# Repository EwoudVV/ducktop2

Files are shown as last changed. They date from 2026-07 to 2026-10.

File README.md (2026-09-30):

# Ducktop2




i'm building a 16-inch x86 laptop around the LattePanda Mu Ultra. i wanted the
exposed hardware and flexibility of a cyberdeck in something i could
actually carry around and use every day.

ducktop1 used a Pi 500+ and a portable monitor, with HDMI and USB-C cables
looping around the outside of the case. ducktop2 brings the display onto
direct eDP and puts power, ports, and laptop controls on custom boards.

## what's in it

- LattePanda Mu Ultra 226V initially, with the carrier designed to support a later 256V upgrade; 16 GB RAM and NVMe storage
- 16-inch AUO B160QAN03.K, targeting 2560x1600 at 120 Hz over direct eDP
- M.2 NVMe and a separate Wi-Fi/Bluetooth socket
- 65-key Cherry MX Ultra Low Profile keyboard and a 140 x 105 mm USB trackpad
- five USB-C ports, two USB-A ports, HDMI, and Gigabit Ethernet
- a 3S battery, USB-C PD charging from either side, and AUX/DC input
- STM32F407 for laptop control and a separate RP2350 with protected maker GPIO
- two status OLEDs, speakers, a headphone jack, and a microphone
- optional VHF/UHF radio, GNSS, and a separate radio audio path

## build status

updated 30 september 2026. the carrier interface is being switched to Mu
Ultra: 226V first, with a later 256V upgrade. the new pin map moves HDMI to
TCP2, reallocates USB and gives NVMe a real clock-request connection. the
100 W power circuit is saved, but placement, routing, cooling and hardware
qualification still need work. the
[module requirements](manufacturing/lattepanda_mu_bios_release.md) separate
that target from the current CAD and the remaining hardware checks.

the revised power circuits, separate power wiring and signal connectors are
saved on all three main boards. the new placement pass uses both sides:
local capacitors sit near their actual supply pins, USB protection follows
its connector, and the audio and maker circuits have been regrouped.
the connector positions, mounting points and board gaps are preserved.
the existing PCIe routing is intact. USB, HDMI and Ethernet route repairs
are in progress, and most main-board routing still remains.

the keyboard now has per-key RGB on four layers, with its schematic and
placement ready for routing. the previous tracks and pours are cleared. the key positions,
outline and cable connector are unchanged. [keyboard routing notes](keyboard/README.md)
cover the LEDs, current limit and switch keepouts. the old non-RGB order
files have been retired. the radio antenna connectors now match the board edge and their
mechanical drawing. the radio still needs routing.

the four-layer BMS is routed again with the new terminals, raw-pack connector
and fuse. the routing cleanup is finished, with zero unconnected items and
zero physical DRC errors. [layout checks](verification/bms-layout.md) cover
the current saved board. the PCBWay quote package has been regenerated and
checked against the saved board.
the three main-board sections are eight layers,
and most of their routing still remains. [power revision status](docs/hardware/power-revision.md)
records what is saved and what is still unfinished.

firmware corrections cover charger communication, startup, watchdog and fan
handling, USB power permissions, and host communication. assembled-hardware
tests are still pending. the replacement panel has run at 2560x1600 and
120 Hz on the Intehill controller; the final Mu-to-panel cable still needs
validation. the complete laptop is not ready for fabrication or powered
integration.

## boards

```mermaid
flowchart LR
    L[Left I/O] <-->|signal cable and power wiring| C[Center: Mu, EC, charger, gauge, maker MCU]
    C <-->|signal cable and power wiring| R[Right I/O]
    B[BMS: protection and balancing] <-->|power and isolated control wiring| C
    Cells[3S cells and cell taps] --- B
    C --- K[Keyboard]
    C --- Radio[Optional radio and GNSS]
    C -->|Mu onboard eDP| Panel[Internal display]
```

the center charges the whole pack. the BMS monitors the cell taps and
balances cells locally. the EC and maker controller have separate jobs,
and the rest of the laptop is intended to work with the radio board removed.

## open in KiCad

the current reference version is KiCad 10.0.4.

| Work | File |
| --- | --- |
| Center schematic | `ducktop2.kicad_pro` |
| Center layout | `ducktop2-center.kicad_pcb` |
| Left I/O | `left_io/left_io.kicad_pro` |
| Right I/O | `right_io/right_io.kicad_pro` |
| BMS | `bms/bms.kicad_pro` |
| Keyboard | `keyboard/12_keyboard_daughterboard.kicad_pro` |
| Radio | `radio_daughterboard/radio_daughterboard.kicad_pro` |

read [build and verification](docs/build-and-verify.md) before regenerating
or syncing a board. the center schematic and PCB have different basenames.
review an explicit current netlist before updating the PCB; rebuilding a
board can replace existing routing.

## files and documentation

| Location | Contents |
| --- | --- |
| Root KiCad files | Center project and active schematic hierarchy |
| `left_io/`, `right_io/`, `bms/`, `keyboard/`, `radio_daughterboard/` | Separate board projects |
| `gen/` | Schematic generators, validation code, and symbol definitions |
| `ducktop2.pretty/`, `Module_LattePanda.pretty/`, `ducktop2.3dshapes/` | Shared footprints and models |
| `docs/hardware/` | Circuit, cable, display, and mechanical documentation |
| `firmware/` | EC/maker code, tests, and firmware release records |
| `mechanical/` | Current floorplan and layout planner |
| `reference/` | Source/reference designs and retained generator inputs |
| `manufacturing/` | Board packages, quotes, and manufacturing requirements |
| `verification/` | Hardware validation record and ignored generated checks |
| `software/` | Fedora setup, recovery, and theme files |

- [hardware and behavior](docs/hardware/overview.md)
- [power and battery](docs/hardware/power-and-battery.md)
- [cables and connectors](docs/hardware/cables-and-connectors.md)
- [display harness](docs/hardware/display-direct-edp.md)
- [mechanical layout](docs/hardware/mechanical.md)
- [build and verify](docs/build-and-verify.md)
- [bring-up procedure](docs/BRINGUP_TEST_PLAN.md)
- [parts and cost](docs/bom-and-cost.md)
- [firmware](firmware/README.md)
- [manufacturing](manufacturing/README.md)
- [OS work](software/os-theme/README.md)
- [ducktop1](docs/ducktop1.md)
- [Forge project pitch](docs/forgery_pitch.md)
- [project journal](JOURNAL.md)

## sponsors

<a href="https://www.nextpcb.com/">
  NextPCB
</a>

thanks to NextPCB for supporting PCB manufacturing and assembly for ducktop2!

## license

the project files are under the [MIT license](LICENSE).

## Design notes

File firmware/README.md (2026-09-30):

# ducktop2 firmware

Version: `0.3.0-policy`

the EC and maker targets now build. they have not been programmed or tested
on assembled boards. the release record remains pending. the default EC
profile keeps unqualified pack use, charging and laptop boot disabled.

## current targets

| target | implementation |
| --- | --- |
| STM32F407 | pinned ST CMSIS and TinyUSB, correct vectors, bounded clock startup, watchdog before clock waits, SWD preserved |
| charger | ISL9241 low-byte-first registers, 200 mA startup, charge inhibit, voltage/current readback, continuous ADC and actual VSYS |
| power sources | TPS25751 framed reads, two coherent contract snapshots, live expander state checks, cold charger retry, ordinary removal/reselection |
| thermal | ADC conversion, 25 kHz PWM, tach freshness, spin-up grace and a latched stall response |
| laptop controls | keyboard/consumer HID, vendor status/control HID, lid debounce, battery validity, two OLED page writers, headphone mute/enable/readback |
| keyboard RGB | IS31FL3743A at 0x2f, 65-key colour map, staged startup, brightness control and RGB power cut on bus or load-switch faults; host command currently provides enable/disable |
| maker RP2350 | pinned Pico SDK target, USB HID GPIO/ADC control, user-rail gate, expiring authorization and a watchdog |

`ec_target/main.c` binds the target functions to the portable policy and
commit adapter. the software sends a desired Mu/display budget to a host
mailbox. that write acknowledges delivery only. `power_policy_confirmed`
requires a matching, fresh host reply after actual limit readback.

boot has a separate, bounded authorization because the OS cannot
apply a limit before its computer is powered. external and pack boot each require their own
qualified worst-case boot envelope in `ec_target/board_profile.h`. it never
sets `power_policy_confirmed`. without a host acknowledgement, it expires
and controlled loads turn off.

charging does not need the OS to stay running. a live host can pause it,
but the EC can charge on its own once the Mu rail is off. it waits for
the previous enable command and power-good signal to clear before counting
that load as zero. during an authorized boot it reserves the full boot
budget. while running, it uses the fresh host load reading. unknown loads,
temperature faults and the qualification switches still block charging.
charge-current commands include shunt and regulation error. a budget below
1850 mW becomes a zero command rather than an invalid small charge setting.

pack operation and charging require the exact pack, interconnect, thermal
protection and gauge profile to be qualified. the user reports a successful functional test of the three owned AKZYTUE
cells in series with two intermediate taps. that is useful functional
evidence; it does not establish current sharing, fault interruption or
temperature protection. the BMS has not been tested with these packs, so removing their protection
boards is not part of this checkpoint. the old 15 W low-pack value remains a portable-policy test case. it is not
a qualified operating point for the Mu Ultra, and the default target does
not enable it.

## source and fault behavior

PD1 and PD2 use 7-bit addresses `0x20` and `0x21`, through service-mux channels
2 and 3. active PDO is register `0x34`, active RDO `0x35`, and PD status `0x40`.
these are register offsets, not device addresses. status, PDO, RDO and PD
status have 5-, 6-, 16- and 4-byte payloads, each preceded by its byte count.
fixed 5, 9, 15 and 20 V contracts are accepted for the revised hardware.
the charger input command is capped at 4.4 A and uses 4 mA steps. the policy
reserves 6.5 W for the raw standby path, converted to current at a conservative
input voltage, plus a 250 mA PD allowance. shunt and charger error further reduce the
command, and available power uses the lower current bound. this can leave no usable charger
budget on a very small supply. AUX has its own allowance. a valid contract
does not enable an unqualified boot or charge profile. other PDO types and
voltages are rejected.

the revised standby feed comes from VSYS on battery, so its draw passes through
the ISL9241 battery shunt. the current reading is used directly. an 800 mA
standby allocation is still reserved when calculating power available to the
main loads; it is not added to the measured current. the normal Mu/display
budget ceiling is 60 W, with the actual allowance reduced to fit the source,
fan and other loads. this is not a battery-only power rating.
`DUCKTOP2_CHARGER_CURRENT_QUALIFIED` stays off until the declared current
transfer bounds have been checked on assembled hardware.

all PD paths start off. a valid input can power the charger while charging
and loads stay off. the EC retries its probe, obtains fresh VSYS/status,
then writes and reads back both input-limit registers. U44 output and configuration registers
are checked on every input sample. an expander reset or bus failure cannot
be hidden by its cached output latch. a failed safe commit resets the EC;
U44 /RESET follows the same NRST net.

normal source removal reselects a source. supported transfers retain the Mu
rail using the real NVDC pack path, with `DUCKTOP2_PACK_BRIDGE_QUALIFIED`
required. completed charger ADC pack/SYS samples must have started at most 250 ms
ago, measured pack current
must stay within its released limit, protection and Mu PG must be healthy,
and the pack must cover the unchanged host budget plus auxiliary demand and
the platform reserve. charging and optional loads are shed during transfer.

both PD paths must be observed off before the 20 ms break interval starts.
the next path also waits for a charger ADC sample started after that
all-off observation, then needs physical path-good and a verified input-current limit.
the Mu budget mailbox stays unchanged, so a stronger source does not invalidate
an already-applied host limit. candidate loss returns to the qualified pack;
failed candidates have a bounded retry delay. stale data, excess current,
failed commits, missing pack support or an insufficient envelope fail off.
there is no capacitor hold-up assumption in this policy.

battery-only startup has its own qualified envelope. bridge, pack, gauge,
charging, boot and load qualification remain disabled pending real evidence.
continuous transfers are host-tested command sequences, not measured board
transients. physical transfer qualification remains in HIL.

fan tach uses a 250 ms freshness window. when the Mu rail is on and the fan
command is at least 30%, there is a 2 s startup grace. no valid rotation for
1 s after that latches a fault, requests full fan and removes controlled
loads. a fault needs deliberate recovery; it is not cleared by one good edge.

## build and check

from the repository root:

```sh
sh firmware/tools/run_host_tests.sh
cmake -S firmware/ec_target -B .workbench/ec-build -DCMAKE_BUILD_TYPE=Release
cmake --build .workbench/ec-build
python3 firmware/tools/verify_target_build.py \
  --elf .workbench/ec-build/ducktop2_ec \
  --output .workbench/ec-build/verification.json
```

profile fields in `board_profile.h` can be supplied as integer CMake
`-DDUCKTOP2_...=` settings. incomplete boot envelopes and unsupported charger
steps fail the build. these checks do not replace the qualification evidence.

ARM GCC is required. the EC uses the compiler's `libgcc` and a small
freestanding C support layer. the initial stack is at `0x20020000`; the linker
reserves 8 KiB and rejects data/heap overlap. compiler stack-usage reports
are retained with target objects. stack high-water measurement is still a
hardware check.

host CMake builds run the same suites. the host tests include literal PD
wire frames, ISL byte order and current steps, charger power cycling, ADC freshness,
expander reset, descriptor rejection, host lease expiry and fan stall.

[USB power control and loom limits](ec_target/USB_POWER.md),
[maker build and protocol](maker_target/README.md),
[Linux battery/lid and power agent](../software/ec-host/README.md), and
[gauge fixture workflow](gauge/README.md) cover the other software paths.

## what still needs physical evidence

clock/watchdog timing, reliable I2C captures, both USB orientations and USB
enumeration, fan PWM and blocked-rotor response, exact OLED module identity,
headphone detection and mute behavior, pack calibration/protection, Mu/display
power limits, and BOOTSEL/SWD recovery remain untested. all existing HIL rows
remain `NOT_RUN`. no release approval or programming record was created.

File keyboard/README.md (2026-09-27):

# keyboard

the RGB map now follows the physical rows. the board is four layers and
0.8 mm thick, with the same 273.5 x 80 mm outline, 65 key positions, diodes
and J320 position. the existing switch, power and I2C routing is retained.
the local joins between each LED's three anodes are retained too. old links
between incompatible LED banks were cleared or trimmed for the new map.

switches, LEDs and the cable connector stay in their original locked positions.
this is still a routing revision, not an order release.

open `12_keyboard_daughterboard.kicad_pro` in this folder. the schematic,
PCB, rules and library tables beside it are the current files.

the layer plan is F.Cu for components and signals, In1.Cu for GND,
In2.Cu for extra signals and local power copper, and B.Cu for signals and
ground fill. a rule blocks non-ground tracks on In1.Cu while allowing
signal vias through it. the current ground zone and stitching are retained.
the dielectric build is provisional; confirm a 0.8 mm four-layer stackup
with the fabricator before ordering.

## LEDs and power

i picked Everlight `19-337/R6GHBHC-C02/2T` LEDs, LCSC `C409504`. each is
1.6 x 1.6 x 0.35 mm and has separate connections for all three colours.
the IS31FL3743A driver, U320, handles all 65 keys over I2C at address
`0x2f`. there is no daisy-chained data connection between the LEDs.

each LED sits 2.8 mm above its switch centre in the top view, inside
CHERRY's auxiliary component area. the maximum LED body height is
0.45 mm; allowing 0.05 mm of solder gives 0.50 mm against CHERRY's
0.8 mm limit. the copper pads fit the allowed area too, with a minimum
nominal edge margin of 0.075 mm. check the first assembled LED and switch
before fitting the rest. the LEDs have to go on before the switches.

R320 is 33.2k, 1%. using the driver's published maximum current at its
stated 3.6 V / 25 C test condition and the resistor's low tolerance gives
11.23 mA per active sink. only 18 sinks run at once, so the total is about
0.202 A before logic and pull-ups. the 5 V feed has a 0.25 A design budget,
below U310's roughly 0.4 A nominal limit and J320's 0.5 A contact rating.
this is a design calculation; measure current and driver temperature at
full white on the first assembled board. the scan duty also means the
average current per colour is about 1 mA at full brightness.

the keyboard gets switched 5 V on J320 pin 29. its 3.3 V buffer supply is
pin 2, through the now-populated R387 on the center board. **keep R386
unpopulated**, since it bypasses the current-limited switch. U321 is a
TCA9517A: its A side faces the 5 V driver and its B side faces the 3.3 V
EC bus. this arrangement uses TI's October 2025 datasheet and keeps the
unpowered driver isolated. do not swap its sides or put 5 V pull-ups on
the EC side.

## routing order

1. start with U320's exposed ground pad, supply pins and decoupling.
   keep C322/C323 close to VCC, C324/C325 close to PVCC, and C320 beside
   U321's 3.3 V pin. give the exposed pad a short, broad ground connection
   and a return to the In1.Cu ground plane. keep ordinary open vias out of
   the exposed paste area; agree any filled or capped thermal vias with
   the assembler. R320 should have a quiet return to U320's ground.
2. route the 5 V feed and ground returns with at least the selected
   0.5 mm width where space allows. use short neckdowns at fine-pitch pads.
   add the In1.Cu ground plane, ground fill on the outer layers and enough
   stitching to connect the surface pads. preserve the switch keepouts.
3. route the RGB scan banks mainly down the keyboard and the colour sinks
   along the key rows. each bank has one key from every physical row, with
   one extra key on ten banks. use the table below and the [key map](rgb-key-map.csv).
   RGB_SW feeds use 0.4 mm and sinks use 0.2 mm. local anode joins already
   belong to their new bank; do not join neighbouring LEDs just because
   they used to share a bank.
4. finish any remaining keyboard-matrix and I2C connections at 0.2 mm. there is no controlled
   impedance requirement here. keep I2C away from long parallel LED power
   runs, and keep the driver-side pull-ups local. do not add extra EC-side
   pull-ups. the matrix diode direction is already set in the schematic.
5. add ground stitching, refill, and run DRC with schematic parity.
   check the full native unconnected count: the CLI report stops at 499.
   the current saved routing count is recorded in the [checks](../verification/keyboard-rgb.md).

| physical row | red cathode | green cathode | blue cathode |
| --- | --- | --- | --- |
| number row | RGB_RED01 | RGB_CS02 | RGB_CS03 |
| Q row | RGB_RED04 | RGB_CS05 | RGB_CS06 |
| home row | RGB_RED07 | RGB_CS08 | RGB_CS09 |
| shift row | RGB_RED10 | RGB_CS11 | RGB_CS12 |
| bottom row | RGB_RED13 | RGB_CS14 | RGB_CS15 |
| ten extra keys | RGB_RED16 | RGB_CS17 | RGB_CS18 |

55 keys use their physical row's sink group. the ten extra keys use the
last group, so two keys never share the same bank and colour channel.
R330-R335 remain between the driver's red CS outputs and the RGB_RED nets.
the firmware table and CSV use the same assignments as the schematic.

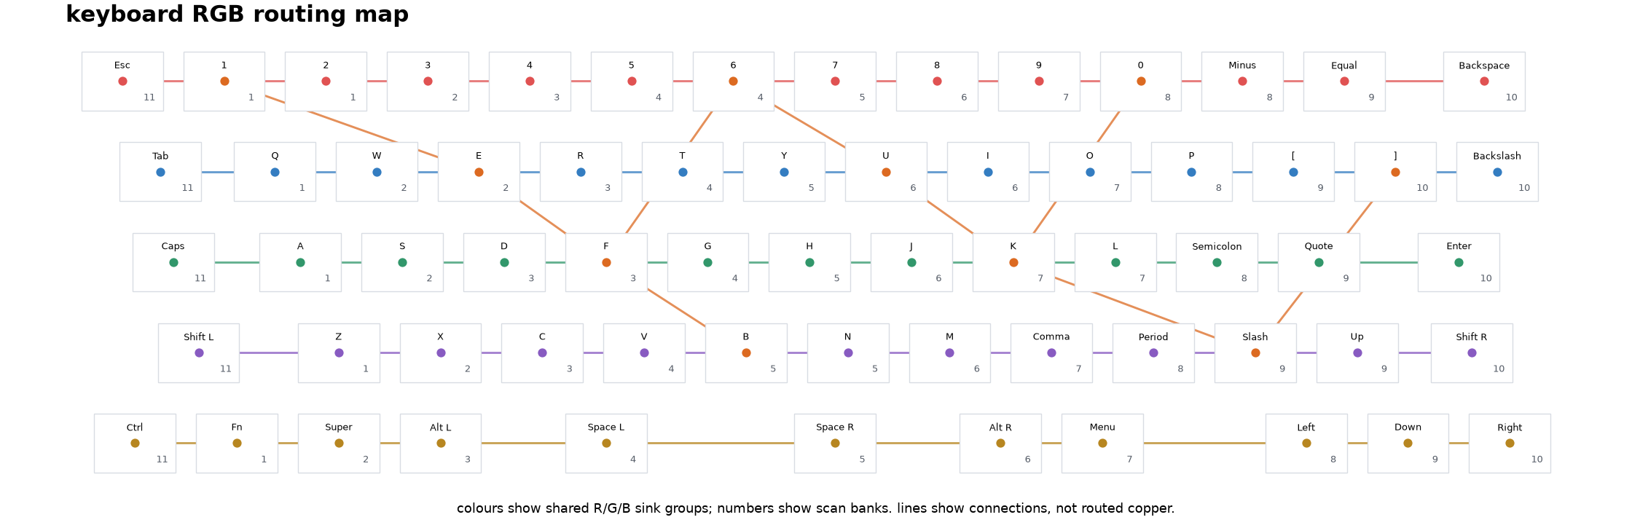
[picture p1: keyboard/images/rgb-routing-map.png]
RGB wiring groups


the minimum clearance and track width are 0.15 mm, with 0.5/0.2 mm vias.
these are routing settings, not a factory approval. confirm the final
0.8 mm stackup and manufacturing limits when ordering.

the 65 CHERRY copper-free rectangles are conservatively extended through
**all four layers**. do not put tracks, vias, pads or pours in them.
the custom courtyard rules allow
only each LED to sit under its matching switch. every other courtyard
check stays active. those exceptions depend on the checked LED offset
and body height, so leave the locked LED positions alone.

## firmware and checks

the EC now initialises the driver, loads all channels before enabling
light, and cuts RGB power on an I2C failure or the power-switch fault
signal. the existing host enable command turns on white at 64/255
brightness. per-key RGB and brightness functions are available in the
firmware; a desktop colour picker and animation controls are still to do.
updates happen one bank per main-loop call, so this is a static backlight
driver, not a high-frame-rate effects engine.

the [placement checks](../verification/keyboard-rgb.md) record the current
results. this revision has no fabrication package yet. after routing,
recheck the switch exclusions against the actual exported copper, then
prepare a new BOM, placement file and assembly sequence for the LEDs,
support parts and switches. the old passive-keyboard exporter refuses
this revision until its assembly contract is updated.

part drawings used here: [Everlight LED](https://www.endrich.com/Datenbl%C3%A4tter/Lichtl%C3%B6sungen/Everlight/RGB%20LED/19-337R6GHBHC-C022T.pdf),
[Lumissil driver](https://www.lumissil.com/assets/pdf/core/IS31FL3743A_DS.pdf),
[TI buffer](https://www.ti.com/lit/ds/symlink/tca9517a.pdf), and CHERRY's
VS-10107 revision 03 / PCB-MX-ULP sample drawings.

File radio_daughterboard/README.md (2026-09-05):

# radio daughterboard

the radio/GNSS/audio board is removable. i want the rest of the laptop to
work while it is absent or being revised, including normal system audio,
the microphone, charging, and boot.

it contains DRA818V and DRA818U radio modules, external filters and RF
switches, a MAX-M10S GNSS receiver, and a separate PCM2900C USB audio codec.
power, USB, UART/control, PTT, presence, and fault signals go through the
removable interface. the radio is intended to start off and stay separate
from core laptop power decisions.

## layout state

the 4 september board read found 126 footprints on a four-layer placement
board, with no tracks or vias. the nominal outline is about 120 x 70 mm.

the stored renders show a placement-stage design. they do not prove the
current chassis fit. the center-side FFC connector J2300 is now at (188,4),
rotation 0, so the installed cable route and board supports need a new check.
[mechanical plan](../docs/hardware/mechanical.md)

## source and checks

the schematic hierarchy and placement generator live in `gen/`:

- `generate_radio_daughterboard_project.py`
- `generate_radio_daughterboard_pcb.py`
- `verify_radio_daughterboard.py`

generation can replace source/placement files. use a copied candidate for
a deliberate change, following [the rebuild guidance](../docs/build-and-verify.md#deliberate-rebuilds).
direct ERC and DRC can inspect the existing files without regeneration.

## remaining work

finish placement/routing, test access, the cable installation, and mechanical
supports. then verify rails, default-off behavior, removal/fault handling,
GNSS, control and audio paths. RF filters, antennas, transmit behavior,
emissions, and coexistence need their own measured test setup.

the radio can be deferred during initial laptop bring-up. its removal must
not silently break a shared bus, reset, power, or audio dependency.

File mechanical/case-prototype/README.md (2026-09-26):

# case prototype

editable CadQuery geometry for the first case fit study. `assembly.json`
selects the 35 mm compact study. the final thickness is still undecided. the current power connectors and wires
still conflict with it and remain visible in the CAD. the 73 mm
`current-hardware` profile is a clearance reference, not the enclosure
target. PCB files are read, never saved by these scripts.

the exports use the earlier PCB snapshots. the new power connector revision
has not been regenerated in the case yet.

open `inspection.html` for the interactive CAD view and `packaging.md` for
the height stack, exact conflicts, assembly order and measurement list.
the case is not ready for manufacture.

start with `hinge-fit.md`, `hinge-datums.json` and the drawings. the first
small prints are under `exports/hinge-tests/`. the retained Framework models
and drawings include their source revision, hashes, copyright and license.

from the repo root:

```sh
/Applications/KiCad/KiCad.app/Contents/Frameworks/Python.framework/Versions/Current/bin/python3 mechanical/case-prototype/inventory_boards.py
.workbench/layout-env/bin/python mechanical/case-prototype/hinges.py
.workbench/layout-env/bin/python mechanical/case-prototype/check_hinges.py
.workbench/layout-env/bin/python mechanical/case-prototype/draw_hinges.py
.workbench/layout-env/bin/python mechanical/case-prototype/export_pcbs.py
.workbench/layout-env/bin/python mechanical/case-prototype/build.py --profile compact-study
.workbench/layout-env/bin/python mechanical/case-prototype/check_exports.py
.workbench/layout-env/bin/python mechanical/case-prototype/finalize_metadata.py
.workbench/layout-env/bin/python mechanical/case-prototype/sync_floorplan.py
```

use `--profile current-hardware` to inspect the taller saved-hardware
reference. both configurations rebuild the same stable output paths; there
is one source tree. `--no-render` skips PNGs but still exports CAD and runs
the geometry review. refreshing board data is a deliberate step: inspect
PCB drift and revised outlines/mounts before adopting new electronics.

## files

- `build.py`, `cad.py`, `hinges.py`, `cables.py`, `assembly.json`: editable
  parametric source and both case configurations.
- `exports/ducktop2-assembly.step`: named assembly in the documented XY/Z
  frame, shown open at 105 degrees. the source and viewer supply other poses.
- `exports/parts/`: separate manufactured STEP parts and print derivatives.
  large metal reinforcement parts also have split, fit-only STLs. those
  fragments do not replace the continuous metal load path.
- `exports/hinge-tests/`, `drawings/`: inexpensive hinge gauges and
  dimensioned mounting details. start here before printing the full base.
- `mounting-schedule.csv`, `parts.json`: reference/XYZ/thread/fastener/
  insulation/status schedule and part inventory.
- `assembly-checks.json`, `hinge-checks.json`, `cable-checks.json`,
  `component-coverage.json`: distinct geometry, motion and cable results.
- `views/`: actual-CAD open, closed, exploded, internal, hinge and section
  images. visible wire intrusions in the compact view are unresolved clashes.

the existing environment uses CadQuery 2.8.0 and VTK. keep `cad.py` and
`hinges.py` together. changing a parameter and rerunning rebuilds solids,
STEP, STL and the actual-CAD view. meshes are print derivatives, not the
editable source. all exported STEP coordinates are millimeters, installed
X/Y with front +Y and Z positive down from the base bottom. the renderer
uses the same geometry in a conventional Z-up view, related by a rotation.

the original 3.3 kg kit is selected. its drawing label matches, but the
owned hinges still need the coupon fit and marking check. the panel, cell
and trackpad measurements remain outstanding. the planned full enclosure
uses separate load paths for the lid, keyboard, trackpad and batteries.

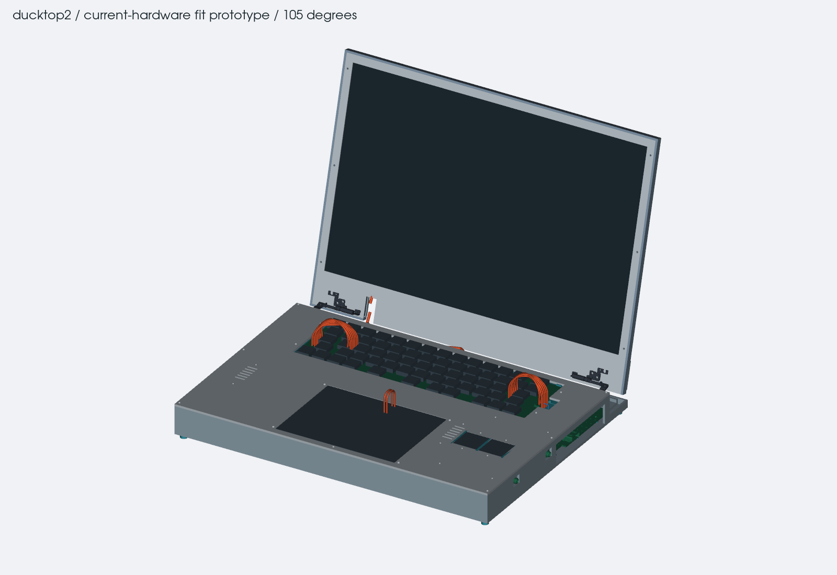
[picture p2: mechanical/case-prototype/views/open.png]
35 mm study with current harness conflicts


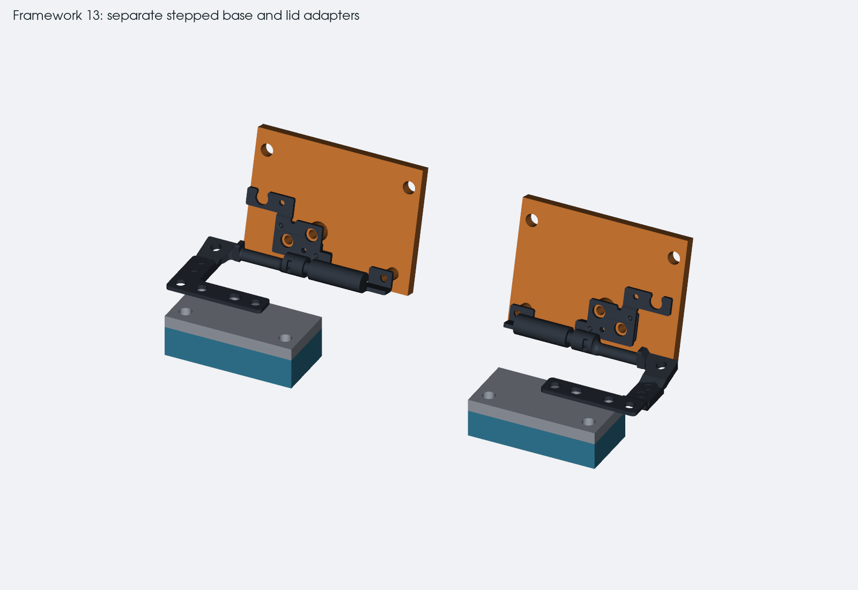
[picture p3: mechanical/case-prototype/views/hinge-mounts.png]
stepped hinge adapters


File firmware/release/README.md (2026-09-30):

# firmware release and hardware tests

Version: `0.3.0-policy`

this directory holds the target release record and
the HIL matrix. the current STM32 implementation is described in
[target status](../README.md#current-targets).

## before enabling a load

the startup sequence needs to establish passive hardware state, watchdog
and reset handling, bounded bus access, and valid source/rail observations.
release source-manager/service-mux resets in the reviewed order and confirm
that the paths remain off until they are qualified.

apply policy outputs through `ec_commit_apply()`. the target must confirm
that limits and enable states took effect. failed communication, stale data,
missing readback, or failed power-good must remain a failure.

for battery-absent PD startup, the path-only bootstrap powers the charger
with charging and loads off. wait for path-good and charger communication,
then program/read back IINDPM before allowing loads.

PD contract reads use live status, active PDO, and active RDO. PD1/PD2 use
7-bit addresses `0x20`/`0x21` on their separate mux channels. 5, 9, 15 and 20 V fixed contracts are supported. a low-power attachment
only qualifies a path if the complete standby and charger-current budget
leaves usable input. it does not authorize laptop boot by itself.

AUX starts with the conservative qualification defined by the policy. raising
its budget needs valid measured input and charger results. it has no negotiated
current contract to copy from a PD controller.

## telemetry and optional hardware

publish only data with valid, fresh measurements. BQ34Z100 charge current is
positive and discharge current negative. reject invalid time values such as
`0xffff` before converting bus minutes into seconds. OLED and OS reports
should show unavailable fields as unavailable.

an absent or failed radio board disables the radio path and should not block
the rest of the laptop. maker rails and I/O have their own authorization and
interlocks; the RP2350 target must preserve those defaults through reset and
programming modes.

## provisional power model

the target applies source-dependent charger commands with explicit shunt,
gain and offset bounds. its power budget uses the lower current bound,
not the programmed value. charge commands also include battery-shunt and
regulation error. [current allowances](../tps25751a/power-envelope.md)
records the values and their qualification requirements.

the Mu/display ceiling is 60 W, reduced to fit the actual source and other
loads. the old 15 W low-pack value is a portable test case, not a qualified
Mu Ultra operating point. a high-power unplug cannot be assumed to fit
the 3 A pack ceiling. pack transfer requires a fresh, already-applied load
limit that fits the released pack and auxiliary-load envelope.

host budget acknowledgement requires matching readback and a fresh lease.
startup uses a separate bounded authorization before an OS can respond.
these sequences pass software tests; physical current response, the declared
measurement bounds and actual module throttling remain untested.

## build, programming, and recovery evidence

retain a reproducible build with toolchain version, flags, map, and hashes.
the release needs EC `.elf`/`.bin` and maker `.elf`/`.uf2` artifacts, recorded
blank-board programming, supported readback verification, and tested
SWD/BOOTSEL recovery. local build files alone do not approve a firmware image.

`target_release.json` records the approved artifacts and their evidence.
it retains its original `PENDING_TARGET_PORTS` state until the final release
review. both targets now build, but qualified power profiles, programming,
readback and HIL evidence are still missing. the development builds under
`.workbench/audit-fixes-2026-09-07/firmware/` are not approved release images.

## HIL rows

`hil_matrix.csv` is the test list. a row becomes PASS only when its evidence
path and SHA-256 are recorded and the evidence file exists.
`tools/verify_release_contract.py` checks those rules, versions, constants,
and required vectors. it does not perform the physical tests itself.

use the revised [bring-up plan](../../docs/BRINGUP_TEST_PLAN.md) to prepare
the board fixtures and test order. retain failed measurements as well as
passing ones, with the hardware and firmware revision for each run.

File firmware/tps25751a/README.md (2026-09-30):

# TPS25751A port configuration

J21 uses `ducktop2_pd1_config.json`: host-only USB 3.2 Gen 2x1. J11 uses
`ducktop2_pd2_config.json`: host-only USB 2 through USB7206 downstream port 1.
the two EEPROM images are different. neither port provides a USB device,
USB4, DisplayPort alternate mode, or audio accessory data path.

both ports use dual-role power, fixed 5/9/15 V sink PDOs at 3 A and a
20 V / 5 A sink PDO. the source side stays at 5 V / 900 mA, with default
Rp and no BC1.2 advertisement. the EC controls the charger and separate
PP5V permissions. 5 A operation needs a suitable cable and a valid contract.
lower-power contracts stay connected so the EC can budget their actual power.

these 100 W profiles belong to the ISL9241 power revision. that circuit's
schematic and PCB integration is still pending. do not program these images
onto the old power design. all hardware qualification gates remain off.

these are exact raw JSON exports from 29 september 2026, using TI Application Customization Tool
2.0.0 with `FB09.17.02__RC5.bin`. `release_manifest.json` binds each source,
original export archive, binary, C array, original VIF and reviewed VIF.
local TI output is under ignored `generated/PD1/` and `generated/PD2/`.
the superseded combined image must not be used for either port.

```sh
python3 firmware/tps25751a/verify_config.py --require-generated
python3 firmware/tests/test_tps25751_config.py
```

the checker compares complete critical register-write records, the two
low-region copies in each full-flash image, GPIO roles, data rate, swaps,
VCONN/path settings and every active PDO. target admission also reads the
controller's profile and fails off if it belongs to the wrong physical port.

TI's original VIFs are retained unchanged. its left VIF reports host speed
as N/A, and its right VIF defaults to a port outside a hub. the public VIFs
are clearly marked project review drafts with each correction recorded in
the manifest. the left speed is Gen 2x1; the right is USB 2 on hub port 1.
TI documents that system fields need review after export in
[SLVAFZ1](https://www.ti.com/lit/an/slvafz1/slvafz1.pdf), sections 2.2 and 4.
the numeric Gen 2x1 value and hub-field mapping are also checked against the
[Chromium EC VIF implementation](https://chromium.googlesource.com/chromiumos/platform/ec/+/d1e7a27efbc80e282b3917d1bef7a9a944c00eeb/util/genvif.c).

these drafts are not certification submissions. product identification,
battery/status message support and the complete USB-IF review remain open.
programming and per-port readback remain `NOT_RUN`, each bound to its own
full-flash hash. no controller was programmed during export.

[power allowance](power-envelope.md) separates the input margin from
source tolerance, current regulation and always-on draw.
[physical testing](../release/README.md) still has to establish negotiation,
role changes, current limits, USB signaling and source-path sequencing.
all charging, boot and USB load qualification gates remain off.

the grounded unused GPIOs follow the TI pin guidance. the configuration checker
also verifies their initial levels, pull settings and event mappings, so a
future profile cannot quietly drive one of those pins high.

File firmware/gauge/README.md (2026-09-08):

# gauge setup and recovery

`profile.json` is unresolved. there is no released chemistry ID, calibrated
golden image or learning-cycle result for the owned cells. the normal EC
keeps gauge-derived power authorization invalid while this remains open.

use bqStudio and a pack substitute to configure the exact BQ34Z100-G1
installation. establish series count, divider scaling, design capacity,
current shunt gain and offset, charge/discharge polarity, temperature setup,
ChemID and learning-cycle results. compare the gauge to external instruments
before exporting a golden FlashStream image. keep the image hash and that
evidence together. do not substitute a nominal capacity from a shop listing.

`flashstream.py` implements TI's W/C/X format, converts its 8-bit wire address
to the 7-bit Linux address, bounds each operation and stops on the first
failed comparison. by default it parses and validates only. apply mode
requires a reviewed `QUALIFIED_IMAGE` profile with an exact image hash, a
Linux I2C fixture bus, a pack substitute and an output report. it does not
unseal, reset or learn the gauge implicitly; those actions must be in the
reviewed image. recovery from ROM mode needs the matching TI recovery image
and fixture procedure, rather than replaying arbitrary writes.

```sh
python3 firmware/gauge/test_flashstream.py
python3 firmware/gauge/flashstream.py exact-image.bqfs --profile reviewed-profile.json
```

a programming pass means all operations and compare steps completed. it does
not mean calibration or real-cell validation passed. the tool records that
distinction. the fixture must isolate pack negative correctly and must not
bypass either shunt or the protection path through its ground lead.

format reference: TI [SLUA801](https://www.ti.com/lit/an/slua801/slua801.pdf).

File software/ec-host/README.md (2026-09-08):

# ducktop2 Linux controls

this directory contains the Mu-side half of the EC interface. nothing here
has been installed or run against a real EC. the Python protocol and power
limit functions are tested with temporary files. the kernel module builds
and loads on Linux 6.12.108 in a disposable aarch64 QEMU guest. its synthetic
UHID test passes battery units/status, lid events, malformed-report rejection
and stale-data expiry. the intended Fedora kernel and physical Mu still
need their own installation and runtime tests.

`linux/ducktop2_ec.c` binds only to the EC vendor HID collection. keyboard
and consumer interfaces stay on the normal HID path. it exposes a battery
through the Linux power-supply class and an `SW_LID` input device. values
without validity flags return unavailable. after 2 s without reports the
battery data expires. the userspace agent can still use hidraw.

`host_agent.py` reads EC reports, applies both RAPL package constraints,
checks their readback, bounds display brightness, and uses `bl_power` for
lid blanking. it sends a matching budget-generation acknowledgement only
after those operations pass. the reported estimate is the entire admitted
ceiling. the profile must include measured non-package Mu demand and the
worst display demand; RAPL alone is not a Mu-plus-display limit.

`board-profile.example.json` deliberately has `qualified: false` and zero
budgets. fill it from measured, reviewed evidence. setting that flag alone
does not produce the evidence. the EC has its own compile-time qualification
switches, which the host cannot override.

on a disposable Fedora test system, build the module with `make -C linux`
after installing the matching kernel-devel package. installation into the
real Mu should follow the kernel-module and HIL review. copy the supplied
udev rule, systemd service and logind snippet into their normal locations,
and install the agent at `/usr/local/libexec/ducktop2-ec-host`. the service
expects `/etc/ducktop2/board-profile.json`. secure-boot module signing is a
target-specific installation step. do not enable the service with an
unqualified profile.

the logind snippet keeps lid closure from suspending the Mu. the agent blanks
the backlight; reopening restores it without a Mu power cycle. Fn brightness
and volume use the existing consumer HID reports. display controls and
headphone switching still need real-device validation.

## wire format

all reports are 64 bytes, have no HID report ID, and use little-endian fields.
interface 2 has a vendor usage page and EP3 IN. feature transfers use a
leading zero report-ID byte in the Linux ioctl buffer.

| input offset | value |
| --- | --- |
| 0 | `DT2` followed by version byte 1 |
| 4 | budget generation, u32 |
| 8 | telemetry validity mask, u16 |
| 10 | presence/lid/fan/headphone/external/boot/charge/host flags, u16 |
| 12, 13 | SOC and battery state, u8 each |
| 14, 16 | pack mV u16 and signed mA i32 |
| 20, 24 | remaining and full mAh, u32 each |
| 28, 32 | time-to-empty and time-to-full seconds, u32 each |
| 36, 40 | requested budget mW and acknowledged generation, u32 each |
| 44, 46, 48 | policy fault u16, fresh fan RPM u16, EC milliseconds u32 |
| 52, 53 | applied and denied USB port masks, u8 each |
| 54 | USB phase in low nibble and fault in high nibble |
| 55 | one nibble per PD controller: valid, connected, source, VCONN bits |
| 56, 58 | conservative USB current upper bound in mA and rail mV, u16 each |
| 60 | USB input-power reservation in mW, u32 |

feature replies carry the same magic and generation, then applied Mu/display
budget at 8, conservative Mu/display estimate at 12, auxiliary estimate at
16, request flags at 20 and lease milliseconds at 24. byte 28 is the USB
permission mask; bytes 29..63 must be zero. the EC accepts 250..5000 ms leases; the agent uses 1500 ms.

USB mask bits 0..6 select J21, J11, J22, J23, J12, J24 and J25. the
agent defaults to no USB permissions. `--usb-ports 0x7f` requests all seven;
the EC can deny ports to keep its qualified current and input-power budgets.
`--clear-usb-fault` sends one clear-request edge. the hardware latch stays off
until the current is quiet and fresh; repeatedly setting the flag does not
keep clearing the fault. request bit 7 carries this clear request.

request bits 0..6 are power off, charging, speaker/headphone audio,
microphone, radio, keyboard lighting and a deliberate BMS retry. use a
released load profile before enabling optional requests. BMS retry needs
an external source, loads and charging off, and a qualified pack. it produces
one bounded pulse per request edge. physical recovery remains untested.

```sh
python3 software/ec-host/test_host_agent.py
# inside the disposable Linux guest, with the module and uhid loaded:
python3 software/ec-host/test_linux_uhid.py
python3 software/os-theme/tests/test_resume_config.py
```

protocol references: Linux [hidraw](https://docs.kernel.org/hid/hidraw.html),
[powercap](https://docs.kernel.org/power/powercap/powercap.html), and
[power-supply class](https://docs.kernel.org/power/power_supply_class.html).

`aux_worst_case_mw` covers other auxiliary loads. the EC separately adds
its complete USB reservation before applying charger and Mu budgets. a still
valid lower host limit can survive an increase in the requested limit, but
its acknowledged generation remains the original one until a new reply is
received. the kernel battery/lid fields are unchanged.

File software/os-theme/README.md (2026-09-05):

# ducktop2 OS and theme

this is the Fedora KDE setup and theme work for ducktop2. i want a dark,
readable desktop with a bit of the cyberdeck feel, while normal applications
still work and look normal.

the files are an early implementation. final Mu boot, EC integration,
recovery, and display validation still need hardware testing.
[project status](../../README.md#build-status)

## what's here

- A visual spec, palette, and native 2560x1600 wallpaper source.
- KDE and Konsole color schemes, a terminal profile, and Starship settings.
- An optional Plasma panel layout.
- Staged SDDM and Plymouth themes.
- Package/setup scripts for a Fedora KDE install.
- An eMMC recovery/hibernation setup script that still needs target validation.

## start with the desktop

the working base is Fedora KDE Plasma Desktop. test ordinary desktop pieces
on an x86 install or VM before changing login and boot themes. the package
scripts and assumptions need checking against the Fedora/KDE version in use.

from this directory on the Fedora test system:

```sh
bash install/apply-theme.sh --install-packages
```

the script is intended to back up touched user configuration. inspect the
changes and confirm login/recovery before enabling the system themes.
`--panel` applies the optional panel layout.

## wallpaper and system themes

```sh
bash install/check-wallpaper-resolution.sh
```

the native wallpaper source targets 2560x1600. export it through
`install/export-native-wallpaper.sh` when changing the artwork.
static wallpaper should not contain fake battery, temperature, or system
readouts. live status belongs in real widgets fed by the EC/OS.

SDDM/Plymouth are separate steps in `install/system-theme.sh`. keep them
staged until the test system has a working recovery path and their behavior
has been checked. the desktop theme does not require them.

## recovery and hardware integration

the daily OS belongs on NVMe. the 64 GB eMMC is planned for recovery,
hibernation storage, and offline data. the setup script exists, but its disk,
boot, and resume behavior have not been released on hardware.
[eMMC plan](docs/emmc-recovery.md)

EC battery/telemetry transport, lid events, and hardware widgets remain
integration work. host-tested EC report code alone does not create an OS
battery device or a working widget.

- [visual direction](docs/design-spec.md)
- [firmware target status](../../firmware/README.md#stm32-target)

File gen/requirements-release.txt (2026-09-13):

# Geometry checks use ordinary Python; KiCad's pcbnew interpreter is separate.
# These are the versions used for the checked release geometry and tests.
numpy==2.4.6
shapely==2.1.2

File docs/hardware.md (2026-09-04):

# hardware

updated 4 september 2026. this describes the intended circuit in the current
split projects. [current status](design-status.md) lists where the board
files or testing still fall short of it.

## boards

| Board | Main contents | Connection to the rest of the laptop |
| --- | --- | --- |
| Center | Mu socket A1, STM32 EC, RP2350 maker MCU, charger U2, gauge U10, input selectors, converters, storage, system audio | FPC102, FPC103, FPC105, keyboard, radio, and module connectors |
| Left I/O | USB7206C hub, PD1 controller and protection, USB-C J21/J22/J23, USB-A J24/J25, AUX connector J190 | FPC101 to center FPC102 |
| Right I/O | PD2 controller and protection, USB-C J11/J12, HDMI, RTL8111H Ethernet | FPC104 to center FPC103 |
| BMS | J2 cell harness, F1, BQ77915, LTC4368, protection FETs, shunts, TPB1-16 | FPC106 to center FPC105 |
| Keyboard | 65 MX ULP switches and diodes, 5 x 14 matrix | 30-pin FFC to J310 |
| Radio | DRA818V, DRA818U, filters/switches, MAX-M10S GNSS, separate PCM2900C radio codec | Removable FFC interface |

the left, center, and right boards retain the original shared XY frame.
the BMS was reshaped and moved, so its file coordinates are no longer an
installed chassis position. the radio and keyboard also have their own frames.

## compute, display, and storage

the target is a LattePanda Mu N305 with 16 GB RAM and 64 GB eMMC. A1 is its
socket/interface, with separate mechanical retention. the module is powered
from regulated `MU_12V`, made by the TPS552892 converter.

the AUO B160QAN03.K internal display connects to the Mu's onboard eDP
connector. those eDP lanes do not run across the custom center PCB or an I/O
FFC. the final harness is still pending. [display details](display-direct-edp.md)

J10 is the M-key 2280 NVMe socket with PCIe x4. J40 is the E-key 2230
Wi-Fi/Bluetooth socket. the live schematic includes its PCIe TX/RX path to
Mu HSIO3, its reference clock/reset support, and USB.

## ports

| Reference | Board | Intended role |
| --- | --- | --- |
| J21 | Left | USB-C data and PD charging input |
| J22, J23 | Left | USB-C host/data ports with protected source VBUS |
| J11 | Right | USB-C data and PD charging input |
| J12 | Right | USB2 host/data port from hub DS4, with protected source VBUS |
| J24 | Left | USB3 Type-A on hub downstream port 5 |
| J25 | Left | USB2 Type-A on hub downstream port 6 |
| J190 | Left | AUX/DC input |

J12's `HUB_DS4_DP/DM` and `HUB_PRT_CTL4` cross both I/O cables. its U1760
power switch is hub-controlled. J12 is not a third laptop charging input.

external HDMI comes from the Mu TCP0 path. Gigabit Ethernet uses the RTL8111H
on the right board. review the complete routed channel, including cables,
coupling, clocks, protection, and connector transitions before release.

## controllers

the STM32F407 EC owns laptop functions: input qualification, power sequencing,
charging policy, keyboard scanning/HID, fan control, lid and buttons, status
OLEDs, and optional-device enables. its policy and target-code status are in
the [firmware docs](../firmware/README.md).

the RP2350 maker controller is independent and appears as a separate USB
device. exposed GPIO and user rails have their own authorization and
interlock policy. experiments on those pins should not control the EC.

## input and audio

the keyboard is a 273.5 x 80.0 mm, two-layer, 0.8 mm PCB. its matrix goes
straight to the EC over an FFC. the firmware scans columns and reads rows;
the Fn layer and report generation have host tests.

the JOMAA trackpad is a complete USB device. a USB-C plug stays at the
trackpad, and the cut Standard-A end of its USB2 cable goes to the four J58
solder lands: 1 GND, 2 D-, 3 D+, 4 VBUS. cable retention is still unfinished.

system audio uses its own USB codec, TPA2012D2 speaker amplifier, headphone
amplifier/jack, and microphone path. the radio codec is separate. headphone
insertion is intended to mute the speakers through EC control.

## power and radio

the battery, charger, protection, source priority, and ground references are
covered in [power and battery](power-and-battery.md).

the radio board is removable. its power, data, control, PTT, and status paths
default off or inactive. the rest of the laptop is intended to operate with
it absent. RF filters, antennas, and coexistence still need measurement.
[radio board](../radio_daughterboard/README.md)

## expected behavior

| When i do this | Intended behavior | What's still needed |
| --- | --- | --- |
| Press power | The EC qualifies the available source, applies limits, and starts the Mu in order. | Normal target requests, applied budgets, and startup HIL. |
| Plug a charger into J21 or J11 | The laptop negotiates PD and charges when the source and power budget allow it. | Target integration and measured charging/source-transfer tests. |
| Charge with the Mu off | The always-on EC and charger can manage charging while compute stays off. | Validate this on the finished hardware/firmware. |
| Plug power into J12/J22/J23 | Those ports remain source-only host/data ports; they do not charge the laptop. | Port-role and back-power tests. |
| Use AUX/DC | The source is qualified within the actual protection windows and available power. | Measured limits, charging behavior, and source transfer. |
| Close the lid | Turn the internal display off while the Mu keeps running. opening the lid should restore the display without a power cycle. | Target lid events, OS integration, and display testing. |
| Type or use Fn | The 65-key matrix produces normal keyboard and consumer reports. | Verify every physical switch and USB report on target. |
| Plug in headphones | Route audio to headphones and mute the speakers. | EC detect/amp integration and audio tests. |
| Read battery status | Show valid percentage, charge state, and useful remaining-time data. | Pack calibration and EC-to-OS telemetry transport. |
| Look at the OLEDs | Show real power/battery and thermal/system information; unavailable data stays unavailable. | SSD1306 target rendering, valid telemetry, and tests. |
| Run a heavy workload | The fan responds to measured temperatures and the system stays within a validated power/thermal envelope. | Characterize the actual cooler and integrate host limits. |
| Experiment with maker GPIO | The RP2350 handles the experiment independently of laptop control. | Complete target/interlock behavior and test it. |
| Remove the radio board | The laptop can still boot, charge, and use its normal input/audio/networking. | Optional-board isolation and fault tests. |
| Lose the main NVMe install | Boot a prepared recovery environment from eMMC or external recovery media. | Build and test the recovery path on the Mu. |

## keyboard Fn layer

the implemented keymap uses Fn+1..0 for F1..F10, Fn+Esc for grave/tilde,
Fn+Backspace for Delete, Fn+Up/Down for brightness, and Fn+Left/Right for
volume. the matrix scans columns and reads rows. software mapping tests
are separate from physical key and USB enumeration tests.

## OLED content

the planned left OLED shows source, battery percentage/state, voltage,
current, power, time remaining, capacity, cycles, and health. the right shows
fan, skin/Mu temperature, system/optional-device state, firmware version,
and faults. the content composer exists; all of that still needs reliable
target measurements and display transport.

## display and storage

the internal display target is 2560x1600 at 120 Hz over direct eDP. the
panel has achieved that mode on the Intehill controller; the final Mu harness
has not been validated. the main OS uses NVMe, with eMMC planned for recovery,
hibernation storage, and offline data. hibernation is a separate explicit
operation from the agreed lid-close behavior.

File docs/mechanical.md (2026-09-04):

# mechanical plan

the base and lid target is 358 x 248 mm. the final height, cooling stack,
board supports, and cable installation still need a measured assembly.
board coordinates below were checked on 4 september 2026.

## recorded parts

| Part | Recorded information | Still needed |
| --- | --- | --- |
| AUO B160QAN03.K panel | 352 x 227 mm | Thickness, protrusions, bezel offsets, mounting, connector datum |
| Three cells | 100 x 60 mm each | Exact identity, thickness, tabs, wiring, cutoff boards, clearance allowance |
| Keyboard rev A | 273.5 x 80.0 x 0.8 mm PCB | Switch/keycap/plate stack, fastening, stiffness |
| JOMAA trackpad | 140 x 105 mm | Height, travel, mounting, plug and bend clearance |
| Speakers | 38 x 18 mm each in plan view | Depth, fastening, acoustic volume and openings |

## packaging

the left, center, and right PCBs use the original shared XY frame. their
nominal widths are 70, 230, and 58 mm, with a depth of 185 mm. the seams
are at x=70 and x=300. each board needs its own structural support.

the BMS is about 62 x 30 mm, with its outline at roughly x=106.7-168.6,
y=62.552-92.9 in its current file. the radio outline is about 120 x 70 mm,
at x=20-140, y=20-90 in its file. those are separate layout frames, not
installed chassis positions. the keyboard also needs an assembly transform.

the working packaging plan puts the cells across the front band and the
trackpad above them on its own support plate. the keyboard overlaps part of
the compute/cooling area in XY. actual volumes, insulation, click travel,
cell clearance, and fasteners must stay separate. click loads go into the
trackpad supports, not the cells.

the cooler is a Mu cold plate, flat heatpipe, fins, and a blower. measure
the seated module, socket/support plane, TIM, cooler, and keyboard stack
before setting deck height. plan the inlet/exhaust and verify recirculation.
Framework 13 hinges are the working choice; use the actual brackets and
full sweep to place the display cable and case cutouts.

the floorplan JSON files are packaging sketches. reconcile their envelopes
and positions with the current boards when editing the mechanical model.
their names do not establish that the depicted fit has been validated.

## mounting and retention

the Mu uses TE `2309411-1` and separate Wurth `9774055243R` M2 supports,
5.5 mm high. socket clips are not the complete structural restraint.
check module contact, cooler loads, screw engagement, and board bow with
actual parts. Wurth specifies a 0.2 N*m maximum; assembly torque still
needs its own fit/process check.

| Ref | Board | Function | X (mm) | Y (mm) |
| --- | --- | --- | ---: | ---: |
| A1 | Center | Mu socket, rotation 90 | 181.3 | 45.0 |
| H1 | Center | Mu M2 support | 238.3 | 76.8 |
| H2 | Center | Mu M2 support | 238.3 | 13.2 |
| H3 | Center | NVMe retainer | 279.98 | 116.0 |
| H4 | Center | Wi-Fi retainer | 261.55 | 167.25 |

the M.2 sockets are MDT420M01001 and MDT420E01001. H3/H4 use the recorded
Mu reference-carrier 2.5 mm-high M2 nut/standoff geometry, with a 2.75 mm
drill and 5.0 mm solder land. MDT420STD001 has different thread/hole
geometry and is not interchangeable. retain exact sourcing and sample fit.

| Chassis hole | Board | X (mm) | Y (mm) |
| --- | --- | ---: | ---: |
| H10 | Left | 5.0 | 150.75 |
| H11 | Left | 5.0 | 180.75 |
| H12 | Left | 63.8 | 6.1 |
| H16 | Left | 5.0 | 12.85 |
| H14 | Center | 260.0 | 6.0 |
| H13 | Right | 353.0 | 58.75 |
| H15 | Right | 353.0 | 19.65 |
| H17 | Right | 353.0 | 112.05 |

these are file datums, not approval that the split boards have enough
supports. review flex, heavy components, connector loads, boss geometry,
fastening access, and electrical isolation in the chassis model.

the BMS mounting circles are Edge.Cuts geometry and need an installed
mounting drawing. radio H1-H4 are (24,24), (136,24), (24,86), and (136,86)
in the radio frame; they are different parts from center H1-H4.

## cables and access

the current FFC, keyboard, radio, and J58 datums are in
[cables and connectors](cables-and-connectors.md). include insertion depth,
actuator access, bends, strain relief, and removal paths in the model.

J58 is the trackpad's four solder lands: 1 GND, 2 D-, 3 D+, 4 VBUS. its
cable needs a defined part/gauge, clamp, service loop, bend route, and pull
test. the solder joints must not carry service loads. keep access to the
pack fuse, module screws, programming points, and replaceable cables.

## measurements

| Work | Evidence needed |
| --- | --- |
| Panel and hinges | Dimensioned parts, pivot/sweep, fasteners, connector and bezel geometry |
| Pack | Cell identity/ratings, thickness, tabs, wiring, cutoff assemblies and clearance |
| Mu and cooling | Complete seated height stack, contact/flatness, airflow and thermal measurements |
| Keyboard and trackpad | Actual deck height, mounting stiffness, click travel and clearance |
| Split-board support | Common assembly model with PCB revisions and installed transforms |
| Cables | Measured routing, insertion, bends, strain relief and hinge movement |
| Audio and RF | Speaker volume, mic opening/channel, antenna placement and measured validation |
| Assembly and service | Fastener access, fuse/programming access, replacement paths, weight balance and stiffness |

case cutouts follow the actual board outlines, connector bodies, and
installed transforms. compare the final model to the reviewed PCB revisions
before making the case. the [display harness](display-direct-edp.md) also
has unresolved electrical requirements.

references: [Wurth drawing](https://www.we-online.com/components/products/datasheet/9774055243R.pdf)
and [Mu reference hardware](https://github.com/LattePandaTeam/LattePanda-Mu).

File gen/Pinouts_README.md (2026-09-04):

# Pinouts

> upstream Mu pinout reference kept with the generators. check the linked
> upstream revision and the actual module before using it as a new hardware
> specification. the project-specific display work is in [direct eDP](../docs/display-direct-edp.md).

All pin definitions for LattePanda Mu(N100/N305 Processor)

This reference is based on the official
[LattePanda Mu pinout documentation](https://github.com/LattePandaTeam/LattePanda-Mu/tree/main/Electricals/Pinouts).

⚠️ Note:
Due to the large number of functionally multiplexing pins, you should check the [BIOS functionality documentation](https://github.com/LattePandaTeam/LattePanda-Mu/blob/main/Softwares/BIOS/README.md) before starting your design. Do not design directly from the pin definition documentation here.

[Official module pinout image](https://github.com/LattePandaTeam/LattePanda-Mu/blob/main/Electricals/Pinouts/pinout.jpg)

## eDP

I-PEX 20455-040E

| Number | Name | Type | Description | Note |
|---|---|:----:|---|---|
| 1 | NC | | | |
| 2 | GND | | | |
| 3 | DDIA_TX3- | O | Lane 3 (-) | |
| 4 | DDIA_TX3+ | O | Lane 3 (+) | |
| 5 | GND | | | |
| 6 | DDIA_TX2- | O | Lane 2 (-) | |
| 7 | DDIA_TX2+ | O | Lane 2 (+) | |
| 8 | GND | | | |
| 9 | DDIA_TX1- | O | Lane 1 (-) | |
| 10 | DDIA_TX1+ | O | Lane 1 (+) | |
| 11 | GND | | | |
| 12 | DDIA_TX0- | O | Lane 0 (-) | |
| 13 | DDIA_TX0+ | O | Lane 0 (+) | |
| 14 | GND | | | |
| 15 | DDIA_AUX+ | O | Auxiliary channel (+) | |
| 16 | DDIA_AUX- | O | Auxiliary channel (-) | |
| 17 | GND | | | |
| 18 | LCD_VCC | | LCD Power Supplies | |
| 19 | LCD_VCC | | LCD Power Supplies | |
| 20 | LCD_VCC | | LCD Power Supplies | |
| 21 | LCD_VCC | | LCD Power Supplies | |
| 22 | Selftest  | O | Default Grounding | |
| 23 | GND | | | |
| 24 | GND | | | |
| 25 | GND | | | |
| 26 | GND | | | |
| 27 | HPD | I | Plug Detection | SoC GPP_E14 |
| 28 | GND | | | |
| 29 | GND | | | |
| 30 | GND | | | |
| 31 | GND | | | |
| 32 | BL_EN | O | Backlight enable | SoC eDP_BKLTEN  |
| 33 | BL_PWM | O | Backlight PWM dimming | SoC eDP_BKLTCTL |
| 34 | NC | | | |
| 35 | NC | | | |
| 36 | BL_PWR | | Backlight Power Supplies | |
| 37 | BL_PWR | | Backlight Power Supplies | |
| 38 | BL_PWR | | Backlight Power Supplies | |
| 39 | BL_PWR | | Backlight Power Supplies | |
| 40 | NC | | | |

- **LCD_VCC**: +3.3V
- **BL_PWR**: Same as LattePanda Mu input voltage
- **Selftest**: Factory test pin, ground by default

## Touch

Clamshell 6P 0.5mm FFC/FPC Connector

| Number | Name | Type | Description | Note |
|---|---|:----:|---|---|
| 1 | I2C0_SCL | O | I2C Bus | SoC GPP_H5  |
| 2 | I2C0_SDA | I/O  | I2C Bus | SoC GPP_H4  |
| 3 | GND | | | |
| 4 | TOUCH_RST# | O | Touch panel reset | SoC GPP_E13 |
| 5 | TOUCH_INT  | I | Touch event interrupt | SoC GPP_E17 |
| 6 | +3.3V | | Touch panel power | |

## MIPI CSI-2

Clamshell 22P 0.5mm FFC/FPC Connector

| Number | Name | Type | Description | Note |
|---|---|:----:|---|---|
| 1 | GND | | | |
| 2 | CSI_B_D0- | I | MIPI Data Lane 0  | |
| 3 | CSI_B_D0+ | I | MIPI Data Lane 0  | |
| 4 | GND | | | |
| 5 | CSI_B_D1- | I | MIPI Data Lane 1  | |
| 6 | CSI_B_D1+ | I | MIPI Data Lane 1  | |
| 7 | GND | | | |
| 8 | CSI_B_CK- | I | MIPI Clock | |
| 9 | CSI_B_CK+ | I | MIPI Clock | |
| 10 | GND | | | |
| 11 | CSI_B_D2- | I | MIPI Data Lane 2  | |
| 12 | CSI_B_D2+ | I | MIPI Data Lane 2  | |
| 13 | GND | | | |
| 14 | CSI_B_D3- | I | MIPI Data Lane 3  | |
| 15 | CSI_B_D3+ | I | MIPI Data Lane 3  | |
| 16 | GND | | | |
| 17 | CAM_RST | O | Camera reset | SoC GPP_A21 |
| 18 | CAM_MCLK  | O | Camera main clock | SoC GPP_D4  |
| 19 | GND | | | |
| 20 | I2C1_SCL  | O | I2C bus | SoC GPP_H7  |
| 21 | I2C1_SDA  | I/O  | I2C bus | SoC GPP_H6  |
| 22 | +3.3V | | Camera power | |

## eSPI Contacts

2.54mm Pitch Contacts

| Name | PIN | PIN | Name |
|---|:---:|:---:|---|
| ESPI_IO0 | 9 | 10  | GND |
| ESPI_IO1 | 7 | 8 | NC |
| ESPI_IO2 | 5 | 6 | ESPI_RESET# |
| ESPI_IO3 | 3 | 4 | ESPI_CS0# |
| ESPI_CLK | 1 | 2 | +1.8V |

Contacts on eSPI bus for SoC to communicate with SuperIO, can be used to connect diagnostic card (untested).

## Edge Connector(DDR4 SODIMM)

The edge_connector of LattePanda Mu is designed for DDR4 260P SODIMM. But this pin table is too long, so I put it in a separate .xlsx file.

- [LattePanda Mu Edge Connector Pinout](https://github.com/LattePandaTeam/LattePanda-Mu/blob/main/Electricals/Pinouts/LattePanda_Mu_Edge_Connector_Pinout.xlsx)

⚠️ Note:
Due to the large number of functionally multiplexing pins, you should check the [BIOS functionality documentation](https://github.com/LattePandaTeam/LattePanda-Mu/blob/main/Softwares/BIOS/README.md) before starting your design. Do not design directly from the pin definition documentation here.

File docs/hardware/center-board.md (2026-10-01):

# center board

updated 1 october 2026. the center board is 227 x 185 mm with eight
layers, 868 footprints and 3,563 pads. the existing pcie, usb, hdmi and
ethernet routes have been repaired. there is still a lot of main routing
to do before this board can be ordered.

## routing so far

the nvme data pairs and reference clock are routed, along with the wi-fi
pcie data and clock connections. their tx capacitors sit on the back of
the board near the sockets. the repairs include pair spacing, length
matching, layer transitions, local ground returns and the nearby control
routes. the repaired signals use F.Cu, In2.Cu and B.Cu.

the board has 4,446 straight track sections, 51 arcs and 723 vias.
native connectivity counts 1,795 unconnected items. KiCad's DRC list can
stop at 499, so use the native count when checking routing progress.

the four hdmi pairs and the ethernet controller's pcie data and clock
connections now reach FPC103. the largest hdmi pair mismatch is 0.052 mm.
hdmi tx1 has five layer changes per leg to get past the existing m.2
connections. both legs follow the same layer sequence, with nearby ground
returns. this is a layout check, not a measured channel result.
two extra ground stitches at FPC103 bring the longest local connector
return down from 4.43 mm to 3.18 mm while keeping its shell copper keepout.

usb routes have been moved off In4.Cu and use the matching inner or outer
trace dimensions. the complete usb-c 1 receive pair is matched within
0.03 mm. the short ec switch and dfu connections are routed, but the long
A1-to-U60, MCU_USB-to-R200/R201 and R203/R204-to-J73/U63 connections are
still open. the separate connector contacts and esd pad branches are
checked explicitly, so a spare dangling trace cannot pass as a valid branch.

the refilled board has zero native DRC errors. unrouted connections and
their warnings remain. a fresh schematic export matches all 868 footprints
and 3,372 electrical pads. the 698 existing nvme, wi-fi and nearby control
routing objects were kept unchanged through these repairs.
a missing 1 mm piece of the nvme rx0 negative trace was also restored
from the earlier routing. the full receive path now connects again.

## shape and placement

in the pcb editor, the outline runs from x=102.05 to x=329.05 and from
y=36.55 to y=221.55. the installed layout uses the center translation
`[-30.550001, -36.55]` in
[`board-placement.json`](../../mechanical/board-placement.json). that puts
the center back at x=71.5 to x=298.5, with 1.5 mm gaps to both i/o boards
and a 358 mm board span before case walls.

the bms notch is 64.9 mm wide with 1.5 mm inside radii. its editor side
walls are x=183.10 and x=248.00, and its back is at y=185.25. in the
installed frame those become x=152.55 and x=217.45, with the back at
y=148.7. the notch opens through the front edge.

the positions below use pcb editor coordinates, in mm.

| part | position | rotation |
| --- | --- | --- |
| A1, mu socket | 211.850, 81.550 | 90° |
| J10, nvme socket | 220.100, 143.150 | 90° |
| H3, nvme retainer | 303.650, 133.900 | 0° |
| J40, wi-fi/bluetooth socket | 208.350, 124.600 | -90° |
| H4, wi-fi retainer | 174.800, 133.850 | 0° |
| FPC102, left signals | 109.350, 71.050 | -90° |
| FPC103, right signals | 321.750, 127.050 | 90° |
| J2071, bms power | 142.000, 210.398 | -90° |
| J2073, bms control | 207.050, 181.850 | 180° |
| RS1, gauge shunt | 196.500, 171.950 | 180° |
| J41, left oled | 231.600, 181.550 | 180° |
| J45, right oled | 241.125, 181.550 | 180° |
| J901, maker connector | 326.850, 42.550 | 180° |
| J2300, radio interface | 112.800, 154.300 | 0° |
| C66, usb-c 1 tx capacitor | 204.600, 50.800 | 180° |
| C67, usb-c 1 tx capacitor | 204.600, 52.050 | 180° |
| R2444, right signal shield return | 317.500, 116.600 | -90° |

the m.2 retainers line up with their sockets: the local offsets from pad 1
are 9.25 x 83.55 mm for nvme 2280 and 9.25 x 33.55 mm for wi-fi 2230.
both socket models now sit flat at their 4.2 mm height, with the contacts
and locating pegs aligned to the footprints. the microphone model also
matches its pads and acoustic port.

RS1 separates `FG_VSS` from system `GND`. its sense filters and gauge
inputs need short kelvin connections. return wiring must respect the
shunt and the separate bms control island.

## routing setup

In1.Cu, In3.Cu and In6.Cu are ground. In2.Cu has ground on both sides.
In4.Cu is for power distribution; In5.Cu faces split power islands and
is used for general routing. controlled-impedance signals use F.Cu,
In2.Cu or B.Cu.

| netclass | outer width / gap, mm | In2.Cu width / gap, mm |
| --- | --- | --- |
| DIFF_85 | 0.183 / 0.1524 | 0.114 / 0.1524 |
| DIFF_90 | 0.1796 / 0.2032 | 0.111 / 0.203 |
| DIFF_100 | 0.1521 / 0.254 | 0.091 / 0.254 |

these dimensions come from
[`mainboard_stackup_release.json`](../../manufacturing/mainboard_stackup_release.json).
the ethernet controller's pcie data and reference clock use `DIFF_85`;
its mdi pairs use `DIFF_100`. usb uses `DIFF_90` and hdmi uses `DIFF_100`.

the small gap areas around pads, vias and tuning are checked individually.
`gen/check_center_pcie_coupling.py` checks the local limits and the copper
outside them, plus the completed pcie, hdmi and usb paths. the local usb
branch checks also keep track of the deliberately unfinished connections. use
[build and verify](../build-and-verify.md) for the release checks.

## assembly work left

the center frame and m.2 offsets are checked. the assembly export now
includes the routed bms and both of its cable connections. the connector
maps and generated datums agree with the saved boards. connector housings,
cable bends, board supports and the final case height still need a measured fit.

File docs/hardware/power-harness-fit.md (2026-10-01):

# power harness fit

1 october 2026. the connector positions are saved on the boards. the
wire paths are a case-layout input, not a finished cable assembly or an
approved case thickness.

- [wire paths and connector coordinates](../../mechanical/power-harness.json)
- [top view](../../mechanical/power-harness.png)
- [pin maps and parts](cables-and-connectors.md)
- [electrical acceptance limits](io-power-qualification.md)
- [component positions and heights](../../mechanical/component-placement.csv)

run `python gen/generate_power_harness_geometry.py` after refreshing the
board datums. it checks the source-board hashes, bend radii, wire lengths
and separation between the modelled wires. a stale board export stops it.

## connector positions

these are installed top-view coordinates in mm, using the same origin as
the board layout. rotations follow KiCad. the full component export above
includes the revised placement on both sides of the main boards.

| board | part | x | y | rotation / side |
| --- | --- | ---: | ---: | --- |
| center | J2452, right auxiliary rails | 282.45 | 64.50 | 270, front |
| center | J2462, right return | 281.45 | 80.00 | 180, front |
| center | J54, skin/hinge temperature | 274.00 | 75.00 | 180, front |
| center | J2071, protected BMS power | 111.45 | 173.848 | 270, front |
| right | J2453, auxiliary rails | 320.55 | 64.50 | 90, front |
| right | J2463, return | 324.55 | 115.40 | 90, front |

the right auxiliary wires now run above the signal connectors in the top
view. the separate return goes around their front ends. J2463's plastic
body projects about 0.35 mm beyond the front PCB edge; its solder lands
remain on the board. allow for the housing and its tolerance in the case.
U1760 is underneath the right board at x332.8, y48.7. its maximum body
height is 1.45 mm; reserve 1.75 mm below the solder plane with the 0.3 mm
assembly allowance. check that against the case floor and supports.

the revised power circuit and component placement are saved. the main-board
routing and the complete cable assembly still need finishing.

## clearance above components

the component export includes manufacturer height limits for the audio
codec, speaker amplifier, crystals, fuse, ferrites and small capacitors
under the proposed wire paths. the latest height check covers 13 parts
at 15 crossings. all clear the wires with a separate 0.3 mm assembly
allowance; the smallest remaining gap in this group is 3.90 mm at Y900.

i still need exact dimension drawings for C430/C431, C434 and C917's
stored Murata part numbers. the wire paths allow a body height of 3.45 mm
at C917 and at least 9.75 mm at the other three parts after the assembly
allowance. keep those limits when choosing or checking the fitted parts.

## wire space

the model uses main-board top surfaces at z = 8 mm and a BMS top surface
at z = 12 mm, measured above the outside bottom of the case. these came
from the case study and can change. they are not a thickness requirement.

the short looms use Alpha 6715, 18 AWG, with 1.7526 mm maximum outside
diameter. the direct USB pair uses Alpha 6716, 16 AWG, at 2.1082 mm maximum.
the current manufacturer pages specify a 5D minimum bend radius. the model
checks the inside radius of each curve, plus a 1% numerical allowance.
the old 2010 6715 sheet said 10D; that separate sensitivity result remains
in the geometry file.

the WAGO links use 8 mm stripped ends within the allowed 7..9 mm range.
their calculated cut lengths fit the existing 20..100 mm electrical bounds.
the protected BMS pair fits its 90 mm budget. the direct USB wires fit the
400..420 mm bounds, including a provisional 2 mm hidden at each solder cup.
confirm that allowance on a soldered sample before making a cut template.

the long pair has gentle service loops and different heights at the
crossover. the blue BMS pair rises over the power FETs, with about 1.9 mm
side clearance from the fuse body. the fuse courtyard includes its much
wider solder lands, so a courtyard crossing alone is not a body collision.

the wire model allows 0.2 mm position error around each path. guides and
strain relief have to hold that shape; loose hand-dressed wires are not
proven to fit by this calculation. the highest wire reaches about 23.75 mm
above the case datum before adding a clamp. do not use that number to
declare the 35 mm case study valid.

keep both Alpha 1230 ground braids across each seam. their nominal section
is 4.7625 x 0.508 mm. reserve up to 1 mm above the PCB at their soldered
attachments and check the finished joints. the electrical requirement is
still at most 1 milliohm for each complete connection, including its joints.

## plugs, access and strain relief

the WAGO bodies are 4.5 mm high. their release buttons need access with the
keyboard or bridge removed. support the wires while releasing them; do
not pull against the soldered terminals. clamps must attach independently
to the case or a removable support, not to components or battery cells.

reserve 6 mm above the PCB for the complete XT30 connection and 14 mm of
axial withdrawal space. grip its housing when unplugging it. insulate the
solder cups separately and release the cable support before removal.

the raw-pack connector is Molex 43045-0400 with a 43025-0400 housing and
43030-0038 tin contacts. the detailed plug drawing gives 10.81 mm mated
height and 11 mm for latch movement. the case reservation is 11.35 mm
above the BMS to include drawing tolerance. this is larger than the
catalogue's 10.29 mm summary, which is not the clearance envelope used here.

Molex's board-edge dimension starts at the front pin row. the saved board
has 9.80 mm against a 10.16 mm maximum. limit the combined header and board
edge positioning error to 0.25 mm toward that limit. reserve 14 mm axial
withdrawal and room above the latch with the trackpad bridge removed.

leave at least 12.7 mm of relaxed wire behind that four-contact housing
before any bend, twist or clamp. the cells' lead exit positions and usable
lead lengths are still missing, so the raw-pack cable has no finished route.
the isolated BMS control and temperature cables also need to be included
in the complete assembly clearance check.

## still needed from the complete assembly

the old planner records three user-measured 100 x 60 mm cells. it explicitly
leaves thickness and tabs unmeasured. the case's 10 mm thickness is an
assumption. keep the protection boards, wiring and insulation in the final
pack measurements.

the case work still needs the actual clamps, fasteners, insertion/removal
paths, signal cables, measured packs, cooling and keyboard/trackpad supports
checked together. repeat the component-height check if parts or wire paths
move. resistance, temperature and fault tests remain
separate requirements; the hardware qualification flags are still off.

## drawings used

- [Alpha 6715](https://www.alphawire.com/en/products/wire/ecogen/ecowire/6715) and [6716](https://www.alphawire.com/en/products/wire/ecogen/ecowire/6716)
- [Alpha 1230 braid](https://www.alphawire.com/products/accessories/fit-wire-management/braid/1230)
- [Molex header drawing](https://www.molex.com/content/dam/molex/molex-dot-com/products/automated/en-us/salesdrawingpdf/430/43045/430450400_sd.pdf)
- [Molex plug drawing](https://www.molex.com/content/dam/molex/molex-dot-com/products/automated/en-us/salesdrawingpdf/430/43025/430250400_sd.pdf)
- [Molex mating and wire-dressing instructions](https://www.molex.com/content/dam/molex/molex-dot-com/products/automated/en-us/applicationspecificationspdf/430/43045/430450001-AS-000.pdf)
- [AMASS XT30PW-F30 drawing](https://www.china-amass.net/uploads/31.XT30PW-F30-SPEC-2025V0.pdf)

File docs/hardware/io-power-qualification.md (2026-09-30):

# i/o power looms and ground bounds

30 september 2026. these are the loom and return-current limits for the
100 W power revision. the calculation passes with the conditions below;
the assembled harnesses and operating profiles have not been qualified.
[power revision status](power-revision.md) records the board checkpoint.

power uses two short WAGO looms and one direct left-to-right XT30 loom.
positive supply rails stay off the 41/51-contact signal cables.
[usb_power_contract.py](../../gen/usb_power_contract.py) defines the pin maps,
parts and assembly limits. [calculate_io_power.py](../../gen/calculate_io_power.py)
reproduces the current and voltage screen.

| loom | board terminals | construction |
| --- | --- | --- |
| center to left | J2430/J2431 and J2450/J2451: WAGO 2060-453/998-404; J2460/J2461 return: 2060-451/998-404 | six positive rail wires and one return, Alpha 6715 18 AWG, 20..100 mm |
| center to right | J2432/J2433 and J2452/J2453: WAGO 2060-453/998-404; J2462/J2463 return: 2060-451/998-404 | six positive rail wires and one return, Alpha 6715 18 AWG, 20..100 mm |
| left to right USB5 | J2434/J2435: AMASS XT30PW-F30.G.Y, with two XT30U-M.G.Y plugs | one positive wire and one return, Alpha 6716 16 AWG, 400..420 mm |

each three-pole WAGO group reverses its numbered positions at the center
board. join matching rail names using the full
[pin table](cables-and-connectors.md#power-between-the-main-boards), then
check continuity, polarity and isolation before power. USB5 uses pad 1 for
GND and pad 2 for USB_PORT_5V at both ends. fit both Alpha 1230 ground
braids across each seam; they are part of the electrical design.

the WAGO terminals accept bare stranded wire. strip 7..9 mm, hold the
release button for insertion or removal, and do not solder-tin the ends.
use Alpha 6715 RD005/BK005 for the short looms. the wire is 18 AWG,
16/30 tinned copper with mPPE insulation, rated −40..105 °C. its maximum
outside diameter is 1.7526 mm and its 5D minimum bend radius is 8.763 mm.
[Alpha 6715 specification](https://www.alphawire.com/en/products/wire/ecogen/ecowire/6715).

the WAGO current screen is 9 A per terminal. the model retains a 45 mΩ
maximum for each complete hot/aged wire termination and 30 mΩ/m for wire.
these are assembly acceptance limits, not claimed catalogue contact
resistances. a 100 mm positive conductor is therefore at most 93 mΩ.
the separate return wire must measure at least 0.12 mΩ at its cold corner.
that lower bound and the remaining braid's upper bound establish the
terminal-current limit below; equal current sharing is not assumed.

the direct loom uses Alpha 6716 RD005/BK005: 16 AWG, 26/30 tinned copper
with mPPE insulation. its maximum diameter is 2.1082 mm and minimum bend
radius is 10.541 mm. keep each mated and soldered termination at or below
5 mΩ after assembly, temperature and life tests, and wire at or below
30 mΩ/m. the published wire DCR is nominal and does not establish that
hot bound. [Alpha 6716 specification](https://www.alphawire.com/en/products/wire/ecogen/ecowire/6716).

[AMASS 2025V0](https://www.china-amass.net/uploads/31.XT30PW-F30-SPEC-2025V0.pdf)
specifies 20 A at up to 85 K rise, 1.2 mΩ contact resistance, 100 mating
cycles and −20..120 °C. the project's direct-return design bound is 10 A.
qualify the complete loom at or below 80 °C, including solder joints and
connector bodies. the catalogue contact value does not prove the assembled
hot/aged resistance or temperature.

the WAGO bodies are 4.5 mm high. reserve release-tool access and wire
bends separately. the XT30 mated envelope is at most 23.10 × 13.60 mm,
with a conservative 5.75 mm above-board height; the case reserves 6 mm.
insulate the solder cups, keep retention lands isolated, strain-relieve
the wires independently, and mate only while unpowered.

use the reviewed [harness paths](power-harness-fit.md) for wire exits,
cut-length allowances, clamps and service access. 20..100 mm and
400..420 mm are electrical bounds, not finished cut lists. 420 mm remains
the nominal direct-loom cut target. the complete installed route still
needs a fit check after power placement; a flat plan view does not prove
case clearance. protected BMS power uses its separate WAGO 2060-452 link,
and the raw pack uses the four-contact Molex 43045-0400 map in the
[cable document](cables-and-connectors.md#bms-wiring).

## voltage and input power

USB5 is 5.160784 V nominal. the frozen initial, temperature, endurance and soldering DC screen is 5.102994..5.218866 V;
the ±20 mV ripple allocation leaves the upper corner below the fixed 5 V
PD limit of 5.25 V. the lower corner after negative ripple is 5.082994 V. the final feedback parts and their stress allowances are bound
in the electrical calculation record.
with a 22.6 mΩ direct positive loom, 20 mΩ total board-copper allowance,
2.015 A right-side reservation and 20 mV total ground difference:

- right PP5V after its TPS22992S gate is at least 4.960131 V;
- J12 VBUS is at least 4.784530 V, including its switch chain and a separate
  40 mV hot TPD1S514 loss allowance.

the hot TPD1S514 bound and all cable/board losses require physical checks.
raising the rail further would consume the fixed-PDO upper-voltage margin.
USB 2, Type-C and PD limits must all hold at their specified measurement
points. the reviewed primary sources are USB PD R3.2 V1.2, section 7.1,
and USB Type-C R2.5, chapter 4; the official downloads and agreement record
are retained privately with the project.

at the largest permitted startup load, solve the converter's constant-power
input including the positive loom and board resistance:

```
I × (8.7 V − 0.010 V − 0.108 Ω × I) = 5.238866 V × 5.6 A / 0.85
I = 4.189980 A
U1703 VIN = 8.237482 V
```

the 85% converter efficiency is a qualification floor over the complete
accepted operating range. it is not read from a typical efficiency graph.
this corner gives 80.481% efficiency from center VSYS to USB5, including
the loom. the EC's whole-path input reservation must use at least 80%
qualified efficiency, with the actual validated minimum used if lower
than a proposed profile. a profile below the 80% design floor is rejected.

true center VSYS must remain at least 8.7 V during this high-power USB5
state. the ISL9241 VSYS ADC has a 96 mV step; that resolution does not
establish absolute accuracy. the driver decodes this register in 96 mV
steps. there is no independent STM32 VSYS channel: PA6 senses AUX input,
PA7 skin temperature, and PB0 Mu temperature. AUX voltage is upstream of
the charger and cannot establish this floor.
[ISL9241 datasheet, ADC table](https://www.renesas.com/en/document/dst/isl9241-datasheet).

`DUCKTOP2_VSYS_SENSE_QUALIFIED`, `DUCKTOP2_VSYS_MAX_OVERESTIMATE_MV` and
`DUCKTOP2_VSYS_MAX_FALL_MV` remain zero. qualify the maximum positive
measurement error, including quantization, gain, offset, temperature and aging.
the fall allowance must cover the ADC conversion/poll cycle, the full
reported observation age and the time to remove the load. a register read
alone does not prove that a new conversion has finished. USB admission
requires measured VSYS minus both qualified margins to remain at least
8.7 V; reported samples older than 250 ms fail off.

this 8.7 V limit belongs to the USB5 path. it does not replace the Mu
converter's 10 V minimum for its full 5.5 A operating screen. all rail
reservations must also fit the whole-system source budget. the USB profile
allows at most 5.5 A steady admission and 5.6 A during qualified startup,
with one branch enabled per new measured conversion. source changes,
transfer, stale measurements or loss of the host lease remove admission.

## system 5 V startup and brownout

U6 starts from MU_HOST_ACTIVE. its 880 µF / 1.9 ms startup screen is a
rail-rise transient, so high USB5 admission requires actual SYS5 power-good.
U2412 combines U6 PG and U771's downstream VBUS supervisor onto the existing
INTERNAL_USB_VBUS_VALID boundary. left U2413 combines that signal with raw
INA overcurrent status and drives both the USB fault-latch preset and the
direct converter-enable veto. unused expander P1.6 observes the same signal.

cold start leaves a latched USB inhibit. a brief SYS5 brownout also latches
USB off even with a retained host lease. recovery requires an explicit
fault-clear request after PG, actual VBUS and a fresh quiet-current sample
are valid. no timer stands in for rail readiness. loss during clear remains
blocked by the direct hardware veto and failed readback requests EC reset.
other SYS5 branch startup stays inside the converter's separate complete
bank/inrush envelope and auxiliary source reservation.

## actual load inventory and qualification ceilings

| branch | connected load basis | required upper bound |
| --- | --- | ---: |
| left SYS_3V3 | USB7206C, TPS62823 hub core supply, Y1700 ASDMB, two HD3SS6126 switches, TUSB1142, TPS25810 auxiliary supplies and local logic | 2.000 A |
| right SYS_3V3 | TPS22975, PCA9306, SN74LVC1G17, Type-C auxiliary supply and control logic | 0.025 A |
| MCU_3V3 per I/O board | one TPS25751 plus local control/monitor logic | 0.100 A each |
| right SYS_5V | TPS22948-limited HDMI 5 V and its quiescent current | 0.351 A |
| right PCIE_3V3 | RTL8111H GbE endpoint and its regulators | 0.400 A |
| endpoint startup allowance | conservatively assign the entire shared startup allowance to the right cut | 0.400 A |
| right USB_PORT_5V | J11 and J12 VBUS, VCONN, bleeds and full common allowance | 2.015 A |
| signed DC signals per seam | USB2, HCSL reference clock, DDC/HPD and control/pull currents | 0.100 A each |
| selected main input | one selected PD/AUX input path | 5.000 A aggregate |
| raw AON inputs | all simultaneously active raw-port AON feeds | 2.000 A aggregate |

these are conservative loom bounds, not permission to draw 7 A from a
5 A USB source. the target reserves 6.5 W for raw standby before allocating
charger current. its ISL9241 command and available-power calculations also
include shunt, gain and offset envelopes. the charger-current, USB power,
VSYS measurement, harness, inrush and complete auxiliary-load qualification
conditions must all hold before a live profile is released. their hardware
qualification flags remain off.

the hub's current table gives typical 25 °C values, not guaranteed maxima.
its actual enabled inventory is three SuperSpeedPlus and three USB2
port paths, including the upstream link. that table gives about 950 mA
at VCORE and 96.5 mA at VDD33. at 80% core conversion and 3.0 V input,
this is about 552 mA from SYS_3V3. TUSB1142 lists 275 mW typical active
Gen 2 power, about 92 mA at 3.0 V. both HD3SS6126 devices add 6 mA maximum;
Y1700's 3.3 V current table specifies up to 15 mA at 25 °C with no output
load. these facts support the chosen 2 A test ceiling, but they do not turn
it into an all-temperature manufacturer guarantee. startup and actual
maximum traffic must be measured against the ceiling.

right HDMI has passive TMDS coupling/termination, no active TMDS redriver.
its external 5 V is independently limited by TPS22948. DDC/HPD pull currents
and local logic are included in the 25 mA SYS3 allowance. AC-coupled TMDS,
USB SuperSpeed and PCIe data pairs add no steady DC supply current through
the signal conductors. USB2, HCSL and control paths remain in the signed
signal allowance. validate that allowance using active traffic and static
states, including back-powered peripherals.

the corrected U7 divider gives a 3.259000 V DC floor. at 2 A, 93 mΩ loom,
10 mΩ board copper, 10 mV ground difference and 20 mV ripple, the left
SYS3 floor is 3.023000 V. verify it at the actual device pins. endpoint
limits remain 5 A total, 5.4 A startup, with 3.5 A NVMe, 1.0 A Wi-Fi and
0.4 A GbE branches. use the current WAGO rail map and installed wire paths.

## signed return proof

let positive `gL` and `gR` mean current injected into the left and right
local grounds. sum the positive incoming rail currents, subtract outgoing
positive rail currents, and retain signed DC signal current:

```
gL = I_VSYS + I_SYS3L + I_MCU3L − I_USB5LR
     − I_PD1_SELECTED − I_AUX_RAW − I_PD1_RAW_AON + dL
gR = I_USB5LR + I_SYS5R + I_SYS3R + I_PCIE3R + I_MCU3R
     − I_PD2_SELECTED − I_PD2_RAW_AON + dR
```

only one main source is selected; raw AON feeds may coexist. their combined
limits are used once in the combined cut. `I_USB5LR` cancels in `gL+gR`.
for the passive three-node return network, every edge is bounded by
`max(|gL|, |gR|, |gL+gR|)`. the complete worst-case intervals are:

| cut | most positive | largest negative magnitude |
| --- | ---: | ---: |
| left | 6.389980 A | 9.115 A |
| right | 3.391 A | 7.100 A |
| left plus right | 7.765980 A | 7.200 A |

the largest edge is 9.115 A, below the 10 A continuous design bound.
this includes the entire endpoint startup allowance. resistance ratios
can move the load between return paths, so no equal split is assumed.
install two independent Alpha 1230 braids per seam, each complete bond
at most 1 mΩ including joints and board connections. the model covers
one open braid; it does not cover losing both.

with one braid remaining and at least 0.12 mΩ in the return wire, the
WAGO terminal-current bound is:

```
I_terminal <= I_cut / (1 + R_wire_min / R_braid_max)
           <= 9.115 A / (1 + 0.12 mΩ / 1 mΩ)
           <= 8.138393 A
```

at the full 10 A design bound this becomes 8.928571 A, still below 9 A.
no credit is taken for the signal cable or equal sharing. measure the
cold minimum return-wire resistance and the hot/aged maximum resistance
of each complete braid separately before using this result.

a remaining 1 mΩ braid uses at most 9.115 mV at the calculated worst
cut, leaving only 0.885 mV for additional plane gradients within the
10 mV seam allowance. at 10 A there is no unused voltage allowance.
check the difference between the actual ground lands under load; do not
substitute a cable-only resistance measurement. the FFC guard and shell
constraints remain separate in
[signal_interconnect_contract.py](../../gen/signal_interconnect_contract.py).

externally imposed ground-loop current, ESD and electrical faults are
outside this normal-load sum. the current pack fuse is the 5 A Schurter
HCF, not an instantaneous 5 A clamp. use the actual source fault current,
fuse clearing-time and total-energy bounds, capacitor discharge, background
load and temperature when checking braid and small-conductor pulses.
that fault-energy and ESD qualification remains open.

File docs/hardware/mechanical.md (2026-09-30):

# mechanical layout

the original base and lid target was 358 x 248 mm. the saved main boards
already span 358 mm before case walls. the first editable
[case study](../../mechanical/case-prototype/README.md) uses a 370 x 282 mm
base envelope and a 35 mm deck-height target. the current vertical power
plugs and wire loops do not fit that compact target. the 73 mm profile is
retained as a clearance reference. measured parts, cooling, cable dressing
and the pending power layout still control the final size.
main-board coordinates below were checked on 10 september 2026.

## recorded parts

| Part | Recorded information | Still needed |
| --- | --- | --- |
| Mu Ultra 226V / 256V | Shared 69.6 x 60 mm module format and Ultra cooler family | Measured cooler contact, clearances and thermal validation covering both variants |
| AUO B160QAN03.K panel | 352 x 227 mm | Thickness, protrusions, bezel offsets, mounting, connector datum |
| Three cells | 100 x 60 mm each | Exact identity, thickness, tabs, wiring, cutoff boards, clearance allowance |
| RGB keyboard | Four-layer 273.5 x 80.0 x 0.8 mm PCB, original key positions retained | First-article LED/switch fit, keycaps/plate, fastening, stiffness |
| JOMAA trackpad | 140 x 105 mm | Height, travel, mounting, plug and bend clearance |
| Speakers | 38 x 18 mm each in plan view | Depth, fastening, acoustic volume and openings |

the cell footprints come from the recorded measurements in the
[old battery-band layout](../../reference/floorplans/floorplan_revC_battery_band.json).
the archived measurement notes at commit `8bd7a2d` explicitly confirm
100 x 60 mm per cell, while leaving thickness and tabs unmeasured. the
10 mm thickness in the case study is still an assumption.

## packaging

the left, center, and right PCBs use the original shared XY frame. their
widths are 70, 227, and 58 mm. the left and center are 185 mm deep; the
right board ends at y=117. the center runs from x=71.5 to x=298.5, leaving
1.5 mm gaps to both I/O boards. the board span stays at 358 mm before case
walls. each board needs its own structural support.

the two OLED modules mount separately in the case and connect to J41/J45
with wires. their module bodies are not part of the center-board footprint.
the floorplan positions remain a packaging sketch until the case mounts
and cable routes are set.

the BMS is 61.9 x 36.148 mm at its widest bounds. its
installed outline spans x=154.05 to x=215.95 and y=150.2 to y=186.348,
centered at x=185. the small rear extension is tapered. the center board's
notch is already set for it, with its back at y=148.7, 1.5 mm inside radii,
and 1.5 mm board clearance. the battery row stays at y=188. this outline is
in the saved, routed BMS board. the two middle holes were removed for routing;
the four perimeter supports remain.

the BMS keeps its own mounting points and needs chassis support. the center
board's H24 moved to (149,148), outside the notch. H22 is now (105,70).
the BMS file uses its original coordinates; the installed translation is
(+47.35,+91.448), with no rotation. the main component side faces up;
the isolated-control and raw-probe connectors face down. include their
housings and wire bends below the board. all four BMS supports and fasteners
must be insulating so they cannot bridge its separate ground domains.

the radio outline is about 120 x 70 mm in its own layout frame. its installed
position and the keyboard's assembly transform still need the case model.
the corrected SMA axes are at x=43 and x=108, pointing through the rear
edge at y=20. their centerlines sit 0.38 mm above the PCB top. the connector
bodies extend 9.52 mm beyond that edge and 3.58 mm below the PCB top.
[`radio-datums.json`](../../mechanical/radio-datums.json) records the complete
nominal body envelopes and mounting holes from the saved board. regenerate
it with `gen/export_radio_mechanical.py` using KiCad's Python. add connector
tolerances, the selected antenna plugs and room to tighten them in the case.

the working packaging plan puts the cells across the front band and the
trackpad above them on its own support plate. the keyboard overlaps part of
the compute/cooling area in XY. actual volumes, insulation, click travel,
cell clearance, and fasteners must stay separate. click loads go into the
trackpad supports, not the cells.

the intended laptop cooler is a Mu Ultra cold plate, flat heatpipe, fins,
and a blower, sized and checked for the 256V even if the first module is
the 226V. the older N305 cooler geometry is not interchangeable. use the
Ultra mounting and processor-height drawings, then measure the seated
module, socket/support plane, TIM, cooler and keyboard stack before setting
deck height. the later module upgrade must fit the same cooling assembly.
plan the inlet/exhaust and verify recirculation.
Framework 13 hinges are the working choice; use the actual brackets and
full sweep to place the display cable and case cutouts.

regenerate `mechanical/board-layout.svg` with `gen/export_board_assembly.py`
using KiCad's Python after a board changes. the exporter checks
both BMS connector maps and the M.2 socket-to-retainer offsets, and includes
front- and back-side connector courtyards.
`mechanical/board-placement.json` stores the installed board transforms;
`mechanical/board-datums.json` is the generated mounting and connector data.

`gen/export_power_placement.py --all-components` exports every footprint on
the three main boards to `mechanical/component-placement.csv` and `.json`.
it records native and installed XY, rotation, side, board thickness and
the solder-plane Z. reviewed manufacturer heights are included; missing
heights stay blank or null. a courtyard is an assembly-spacing outline,
not a measured component body. use the source hashes to check that the
case model is using the current boards. omit `--all-components` for the
separate power-part export. `--check` checks either export without writing.

`--study-top-z 8` adds the current study datum to those local coordinates.
it does not approve that mounting height or the old 35 mm enclosure. add
solder, assembly tolerances, supports and service space before freezing
the case. backside parts extend below the board's back solder plane.

the 30 september placement has 250 fitted parts on the back of the center
board, 103 on the left and 39 on the right. all 392 have checked maximum
package heights of 1.8 mm or less. the export includes a separate 0.3 mm
underside assembly allowance. this still needs checking against the actual
floor, supports, screws and cable clamps. some front-side package heights
remain unverified in the export.

the same export refreshes board outlines and parts linked to a PCB in
`mechanical/floorplan.json`. the layout planner is
`mechanical/layout-planner.html`. free case parts, cells and cooling parts
remain a packaging sketch. their volumes and assembly fit still need checking.

## mounting and retention

the Mu uses TE `2309411-1` and separate Wurth `9774055243R` M2 supports,
5.5 mm high. socket clips are not the complete structural restraint.
check module contact, cooler loads, screw engagement, and board bow with
actual parts. Wurth specifies a 0.2 N*m maximum; assembly torque still
needs its own fit/process check.

| Ref | Board | Function | X (mm) | Y (mm) |
| --- | --- | --- | ---: | ---: |
| A1 | Center | Mu socket, rotation 90 | 181.3 | 45.0 |
| H1 | Center | Mu M2 support | 238.3 | 76.8 |
| H2 | Center | Mu M2 support | 238.3 | 13.2 |
| H3 | Center | NVMe retainer | 273.10 | 97.35 |
| H4 | Center | Wi-Fi retainer | 144.25 | 97.30 |

the M.2 sockets are MDT420M01001 and MDT420E01001. J10 is at
(189.55,106.60), rotation 90; J40 is at (177.80,88.05), rotation -90. their
courtyards include the complete 2280 and 2230 card areas. the power parts,
boot button, and programming connector have been moved out of those areas.

the retainer offsets from pad 1, in the socket's local axes, are
(9.25,83.55) for 2280 and (9.25,33.55) for 2230. these match the Mu reference
carrier geometry. the exporter checks the offsets using the actual pad rows,
so changing a socket's rotation cannot silently leave its mounting nut behind.
H3/H4 use the recorded Mu reference-carrier 2.5 mm-high M2 nut/standoff geometry, with a 2.75 mm
drill and 5.0 mm solder land. MDT420STD001 has different thread/hole
geometry and is not interchangeable. retain exact sourcing and sample fit.

the chassis mounts are H10/H11/H12/H16 on the left, H21 through H26 on the
center, and H13/H15/H17 on the right. H14 and H27 are gone. use the generated
datum file for positions. review flex, heavy components, connector loads,
boss geometry, fastening access and electrical isolation in the chassis model.

the BMS mounting circles are Edge.Cuts geometry. their installed centers are
in `mechanical/board-datums.json`. radio H1-H4 are (24,24), (136,24), (24,86), and (136,86)
in the radio frame; they are different parts from center H1-H4.

## cables and access

the current FFC, keyboard, radio, and J58 datums are in
[cables and connectors](cables-and-connectors.md). include insertion depth,
actuator access, bends, strain relief, and removal paths in the model.

J58 is the trackpad's four solder lands: 1 GND, 2 D-, 3 D+, 4 VBUS. its
cable needs a defined part/gauge, clamp, service loop, bend route, and pull
test. the solder joints must not carry service loads. keep access to the
pack fuse, module screws, programming points, and replaceable cables.

## measurements

| Work | Evidence needed |
| --- | --- |
| Panel and hinges | Dimensioned parts, pivot/sweep, fasteners, connector and bezel geometry |
| Pack | Cell identity/ratings, thickness, tabs, wiring, cutoff assemblies and clearance |
| Mu and cooling | Complete seated height stack, contact/flatness, airflow and thermal measurements |
| Keyboard and trackpad | Actual deck height, mounting stiffness, click travel and clearance |
| Split-board support | Common assembly model with PCB revisions and installed transforms |
| Cables | Measured routing, insertion, bends, strain relief and hinge movement |
| Audio and RF | Speaker volume, mic opening/channel, antenna placement and measured validation |
| Assembly and service | Fastener access, fuse/programming access, replacement paths, weight balance and stiffness |

case cutouts follow the actual board outlines, connector bodies, and
installed transforms. compare the final model to the reviewed PCB revisions
before making the case. the [display harness](display-direct-edp.md) also
has unresolved electrical requirements.

references: [Wurth drawing](https://www.we-online.com/components/products/datasheet/9774055243R.pdf)
and [Mu reference hardware](https://github.com/LattePandaTeam/LattePanda-Mu).

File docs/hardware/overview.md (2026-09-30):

# hardware

updated 23 september 2026. this describes the intended circuit in the current
split projects. [current status](../../README.md#build-status) lists where the board
files or testing still fall short of it.

## boards

| Board | Main contents | Connection to the rest of the laptop |
| --- | --- | --- |
| Center | Mu socket A1, STM32 EC, RP2350 maker MCU, charger U2, gauge U10, input selectors, converters, storage, system audio | FPC102/FPC103, separate power/control wiring, keyboard, radio, and module connectors |
| Left I/O | USB7206C hub, PD1 controller and protection, USB-C J21/J22/J23, USB-A J24/J25, AUX connector J190 | FPC101 to center FPC102, separate power loom, and ground braids |
| Right I/O | PD2 controller and protection, USB-C J11/J12, HDMI, RTL8111H Ethernet | FPC104 to center FPC103, separate power loom, ground braids, and direct USB5 wiring |
| BMS | J2 cell harness, F1, BQ77915, LTC4368, protection FETs, shunts, and three thermal probes | J2071/J2072 power and J2073/J2074 isolated control |
| Keyboard | 65 MX ULP switches and diodes, 5 x 14 matrix | 30-pin FFC to J310 |
| Radio | DRA818V, DRA818U, filters/switches, MAX-M10S GNSS, separate PCM2900C radio codec | Removable FFC interface |

the left, center, and right boards retain the original shared XY frame.
the BMS was reshaped and moved, so its file coordinates are no longer an
installed chassis position. the radio and keyboard also have their own frames.

## compute, display, and storage

the initial module is a LattePanda Mu Ultra 226V, DFR1294. the carrier,
power path and cooling must also support the Ultra 256V, DFR1295, so that
upgrading later does not require another PCB or a different cooling assembly.
both current modules have 16 GB RAM and no onboard eMMC. NVMe is required
for the installed OS; recovery uses prepared external media.

the carrier now uses an Ultra-specific A1 symbol and pin map. USB2 P2 feeds
the left USB hub, P6 serves Bluetooth, and the trackpad shares the internal
three-port hub with audio. HDMI uses TCP2 and NVMe CLKREQ reaches pin 108.
pin 136 is left open. the existing socket and compatible routing stay in place.

100 W USB-C input is the new target. the saved charger and `MU_12V` supply
still need their power redesign, and both module variants need hardware
validation. this is still an unfinished carrier.
the [module requirements](../../manufacturing/lattepanda_mu_bios_release.md)
record the selected parts and upgrade checks.

the AUO B160QAN03.K internal display connects to the Mu's onboard eDP
connector. those eDP lanes do not run across the custom center PCB or an I/O
FFC. the final harness is still pending. [display details](display-direct-edp.md)

J10 is the M-key 2280 NVMe socket with PCIe x4. J40 is the E-key 2230
Wi-Fi/Bluetooth socket. the live schematic includes its PCIe TX/RX path to
Mu HSIO3, its reference clock/reset support, and USB.

## ports

| Reference | Board | Intended role |
| --- | --- | --- |
| J21 | Left | USB-C data and PD charging input |
| J22, J23 | Left | USB-C host/data ports with protected source VBUS |
| J11 | Right | USB-C data and PD charging input |
| J12 | Right | USB2 host/data port from hub DS4, with protected source VBUS |
| J24 | Left | USB3 Type-A on hub downstream port 5 |
| J25 | Left | USB2 Type-A on hub downstream port 6 |
| J190 | Left | AUX/DC input |

J12's `HUB_DS4_DP/DN` and `HUB_PRT_CTL4` cross both I/O cables. its U1760
power switch requires both hub control and EC permission. J12 is a host
port; charging inputs are J21, J11, and AUX.

external HDMI comes from the Mu Ultra TCP2 path. Gigabit Ethernet uses the RTL8111H
on the right board. review the complete routed channel, including cables,
coupling, clocks, protection, and connector transitions before release.
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

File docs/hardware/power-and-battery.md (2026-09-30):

# power and battery

updated 30 september 2026. the four-layer BMS is routed, including the
thermal circuit and separate cable connections. the saved board has zero
unconnected items, zero physical DRC errors and no schematic mismatch.
[layout checks](../../verification/bms-layout.md) records the copper and
return-path checks. the cell and assembled-hardware tests below still apply.
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

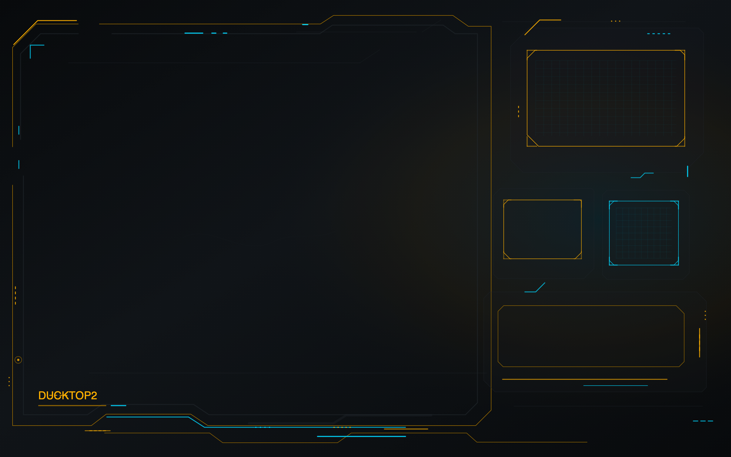
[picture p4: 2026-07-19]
software/os-theme/plymouth/ducktop-hud/assets/wallpaper.png

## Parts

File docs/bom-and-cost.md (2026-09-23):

# parts and cost

updated 23 september 2026. the split design needs a new per-board quote.
there is no reconciled current total yet.

## what the next estimate needs to cover

| Item | Basis for the next quote |
| --- | --- |
| Center, left, and right PCBs | Three separate eight-layer boards, current outlines, approved stackup/impedance requirements |
| BMS PCB | Four layers, 35 um copper, 1.6 mm board; confirm 20 um hole plating in the quote |
| PCBA and component sourcing | Separate BOM/CPL for each board, DNPs, hand assembly, fixtures, setup charges, and spares |
| Radio board | Separate four-layer board and its assembly/components |
| Keyboard | New four-layer, 0.8 mm RGB revision; 65 LEDs, driver and support parts. Original boards have diodes fitted and no switches fitted |
| Mu | DFR1294 Ultra 226V initially, or DFR1294-1 development kit; carrier and cooling must also support DFR1295 Ultra 256V |
| NVMe and Wi-Fi/Bluetooth | Final module identities and capacities |
| Display | Current AUO panel, final compatible eDP harness, mounting and hinge hardware |
| Pack | Exact cells and owned stock, harness, connectors, cutoff assemblies, fuse and mounting |
| Interconnect | Four Molex 503908 signal connectors and their 41/51-contact cables, separate Micro-Fit/XT30 power looms, ground braids, BMS control/probe cables, and keyboard/radio/trackpad cables |
| Case and cooler | Measured design, material/process, fasteners, cold plate, heatpipe, fins, blower |
| Other costs | Shipping, tax, assembly tooling, test fixtures, and replacement parts |

## where part identity lives

schematic fields and generation-time assignments hold manufacturer, MPN,
footprint, DNP, and controlled assembly information. `gen/bom_catalog.py`
supplies many of the passive identities. component inventory tools turn a
schematic export into a sourcing report.

the corrected center and I/O source packets have manufacturer and part-number
fields for their populated board components. run the complete six-board
inventory again after the BMS integration. include off-board items such as
probes, fuse/holder assemblies, crimp contacts, housings, braids and wire.
DNPs and owned assemblies need their intended classification.

one physical footprint is not necessarily one purchased component or one
assembler placement. test points, holes, modules, compound fuse/holder
assemblies, DNPs, and hand-soldered parts affect those counts.

DFR1294-1 includes the 226V compute module, Mini Carrier Board and Ultra
active cooler. do not also count a separate DFR1294 module or FIT1049 cooler
when quoting that kit. NVMe storage and a suitable power supply are separate.
the Mini Carrier is for development; the finished laptop uses its custom boards.

## ownership and sponsorship

check receipts and actual on-hand stock before subtracting owned parts from
the budget. confirm supplier credits, covered costs, and timing from the
correspondence before using them in the total.

## quote record

for each quote, retain supplier/date, exact board revision, layer/finish/copper
options, assembly side and quantities, BOM/CPL versions, substitutions,
shipping/tax, and expiry. keep component cost separate from bare-board fab
and assembly labor so it is not counted twice.

the [build and verification guide](build-and-verify.md) describes the files
needed for an order. the [Forge pitch](forgery_pitch.md) should
use this page's reviewed budget once that quote work is complete.

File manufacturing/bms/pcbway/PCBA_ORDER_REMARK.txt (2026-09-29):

please quote 5 bare pcbs with 1 assembled, and the same build with 2 assembled. both-side smt plus top-side J2 through-hole assembly. exact BOM, no unapproved substitutions. F1 is the soldered SCHURTER 3-101-056 5 A fuse; no loose fuse insert. J2 is Molex 43045-0400; keep the front pin row within 10.16 mm of the routed edge. the design is 9.80 mm, allowing at most 0.25 mm combined header/edge positioning error. 1.6 mm FR-4, ENIG, green mask, white printing, 1 oz copper on all four layers. confirm finished copper and minimum barrel plating against the 35 um / 20 um design basis. use the supplied paste files and electrical test netlist. all vias tented; no filled vias requested. review bottom-side placement orientation, power-fet paste windows and all polarity marks. send any panel/rail/fiducial proposal for review. return unused bare pcbs.

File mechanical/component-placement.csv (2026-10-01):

board | group | reference | value | mpn | footprint | dnp | side | layer | native_x_mm | native_y_mm | native_rotation_deg | installed_x_mm | installed_y_mm | installed_rotation_deg | board_thickness_mm | local_solder_plane_z_mm | height_status | height_kind | height_mm | height_source_url | local_body_max_outer_z_mm | local_body_nominal_outer_z_mm | planning_allowance_mm | local_planning_outer_z_mm | study_solder_plane_z_mm | study_body_max_outer_z_mm | study_body_nominal_outer_z_mm | study_planning_outer_z_mm | source_board_sha256
center | other | A1 | TE 2309411-1 Mu Ultra host socket/interface | 2309411-1 | Module_LattePanda:LattePanda_Module_H8.0mm_Horizontal | False | front | F.Cu | 211.850001 | 81.55 | 90.0 | 181.3 | 45.0 | 90.0 | 1.6 | 0.0 | unverified |  |  |  |  |  |  |  | 8.0 |  |  |  | d4f10273215db5e6d2a23fbbb6d47d9f501da9e0ff759512a6f8be15966a65b5
center | charger | C7 | 470n 25V X7R bootstrap | C1608X7R1E474K080AE | Capacitor_SMD:C_0603_1608Metric | False | back | B.Cu | 209.728157 | 159.755169 | 135.0 | 179.178156 | 123.205169 | 135.0 | 1.6 | -1.6 | verified_maximum | maximum | 0.95 | https://product.tdk.com/system/files/dam/doc/product/capacitor/ceramic/mlcc/charasheet/c1608x7r1e474k080ae_200111.pdf | -2.55 |  | 0.3 | -2.85 | 6.4 | 5.45 |  | 5.15 | d4f10273215db5e6d2a23fbbb6d47d9f501da9e0ff759512a6f8be15966a65b5
center | charger | C8 | 470n 25V X7R bootstrap | C1608X7R1E474K080AE | Capacitor_SMD:C_0603_1608Metric | False | back | B.Cu | 205.255169 | 160.271843 | 45.0 | 174.705168 | 123.721843 | 45.0 | 1.6 | -1.6 | verified_maximum | maximum | 0.95 | https://product.tdk.com/system/files/dam/doc/product/capacitor/ceramic/mlcc/charasheet/c1608x7r1e474k080ae_200111.pdf | -2.55 |  | 0.3 | -2.85 | 6.4 | 5.45 |  | 5.15 | d4f10273215db5e6d2a23fbbb6d47d9f501da9e0ff759512a6f8be15966a65b5
center | charger | C9 | 4.7u 10V X7R VDD | GRM21BR71A475KA73L | Capacitor_SMD:C_0805_2012Metric | False | back | B.Cu | 211.725206 | 163.507117 | 45.0 | 181.175205 | 126.957117 | 45.0 | 1.6 | -1.6 | verified_maximum | maximum | 1.4 | https://search.murata.co.jp/Ceramy/image/img/A01X/G101/ENG/GRM21BR71A475KA73-01.pdf | -3.0 |  | 0.3 | -3.3 | 6.4 | 5.0 |  | 4.7 | d4f10273215db5e6d2a23fbbb6d47d9f501da9e0ff759512a6f8be15966a65b5
center | charger | C10 | 1u 50V input local | GRT188R61H105ME13D | Capacitor_SMD:C_0603_1608Metric | False | front | F.Cu | 219.0 | 161.75 | 270.0 | 188.449999 | 125.2 | 270.0 | 1.6 | 0.0 | verified_maximum | maximum | 0.9 | https://www.mouser.com/datasheet/2/281/product-837155.pdf | 0.9 |  |  |  | 8.0 | 8.9 |  |  | d4f10273215db5e6d2a23fbbb6d47d9f501da9e0ff759512a6f8be15966a65b5
center | charger | C11 | 1u 50V system local | GRT188R61H105ME13D | Capacitor_SMD:C_0603_1608Metric | False | front | F.Cu | 196.95 | 157.5 | 270.0 | 166.399999 | 120.95 | 270.0 | 1.6 | 0.0 | verified_maximum | maximum | 0.9 | https://www.mouser.com/datasheet/2/281/product-837155.pdf | 0.9 |  |  |  | 8.0 | 8.9 |  |  | d4f10273215db5e6d2a23fbbb6d47d9f501da9e0ff759512a6f8be15966a65b5
center | other | C12 | 100n 50V X7R VBUS local | GRM188R71H104KA93D | Capacitor_SMD:C_0603_1608Metric | False | front | F.Cu | 203.525001 | 158.5625 | 270.0 | 172.975 | 122.0125 | 270.0 | 1.6 | 0.0 | verified_maximum | maximum | 0.9 | https://www.murata.com/-/media/webrenewal/tool/library/common-pdf/dynamic-model/component-list-d-mlcc-2506.ashx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 | 0.9 |  |  |  | 8.0 | 8.9 |  |  | d4f10273215db5e6d2a23fbbb6d47d9f501da9e0ff759512a6f8be15966a65b5
center | other | C20 | 100n | GRM188R71H104KA93D | Capacitor_SMD:C_0603_1608Metric | False | back | B.Cu | 143.45 | 63.5 | 180.0 | 112.899999 | 26.95 | 180.0 | 1.6 | -1.6 | verified_maximum | maximum | 0.9 | https://www.murata.com/-/media/webrenewal/tool/library/common-pdf/dynamic-model/component-list-d-mlcc-2506.ashx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 | -2.5 |  | 0.3 | -2.8 | 6.4 | 5.5 |  | 5.2 | d4f10273215db5e6d2a23fbbb6d47d9f501da9e0ff759512a6f8be15966a65b5
center | other | C21 | 100n | GRM188R71H104KA93D | Capacitor_SMD:C_0603_1608Metric | False | back | B.Cu | 143.45 | 67.6 | 180.0 | 112.899999 | 31.05 | 180.0 | 1.6 | -1.6 | verified_maximum | maximum | 0.9 | https://www.murata.com/-/media/webrenewal/tool/library/common-pdf/dynamic-model/component-list-d-mlcc-2506.ashx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 | -2.5 |  | 0.3 | -2.8 | 6.4 | 5.5 |  | 5.2 | d4f10273215db5e6d2a23fbbb6d47d9f501da9e0ff759512a6f8be15966a65b5
center | other | C22 | 100n | GRM188R71H104KA93D | Capacitor_SMD:C_0603_1608Metric | False | back | B.Cu | 146.45 | 72.65 | 270.0 | 115.899999 | 36.1 | 270.0 | 1.6 | -1.6 | verified_maximum | maximum | 0.9 | https://www.murata.com/-/media/webrenewal/tool/library/common-pdf/dynamic-model/component-list-d-mlcc-2506.ashx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 | -2.5 |  | 0.3 | -2.8 | 6.4 | 5.5 |  | 5.2 | d4f10273215db5e6d2a23fbbb6d47d9f501da9e0ff759512a6f8be15966a65b5
center | other | C23 | 100n | GRM188R71H104KA93D | Capacitor_SMD:C_0603_1608Metric | False | back | B.Cu | 157.9 | 72.4 | 0.0 | 127.349999 | 35.85 | 0.0 | 1.6 | -1.6 | verified_maximum | maximum | 0.9 | https://www.murata.com/-/media/webrenewal/tool/library/common-pdf/dynamic-model/component-list-d-mlcc-2506.ashx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 | -2.5 |  | 0.3 | -2.8 | 6.4 | 5.5 |  | 5.2 | d4f10273215db5e6d2a23fbbb6d47d9f501da9e0ff759512a6f8be15966a65b5
center | other | C24 | 100n | GRM188R71H104KA93D | Capacitor_SMD:C_0603_1608Metric | False | back | B.Cu | 159.4 | 58.2 | 90.0 | 128.849999 | 21.65 | 90.0 | 1.6 | -1.6 | verified_maximum | maximum | 0.9 | https://www.murata.com/-/media/webrenewal/tool/library/common-pdf/dynamic-model/component-list-d-mlcc-2506.ashx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 | -2.5 |  | 0.3 | -2.8 | 6.4 | 5.5 |  | 5.2 | d4f10273215db5e6d2a23fbbb6d47d9f501da9e0ff759512a6f8be15966a65b5
center | other | C25 | 100n | GRM188R71H104KA93D | Capacitor_SMD:C_0603_1608Metric | False | back | B.Cu | 145.2 | 56.45 | 180.0 | 114.649999 | 19.9 | 180.0 | 1.6 | -1.6 | verified_maximum | maximum | 0.9 | https://www.murata.com/-/media/webrenewal/tool/library/common-pdf/dynamic-model/component-list-d-mlcc-2506.ashx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 | -2.5 |  | 0.3 | -2.8 | 6.4 | 5.5 |  | 5.2 | d4f10273215db5e6d2a23fbbb6d47d9f501da9e0ff759512a6f8be15966a65b5
center | other | C26 | 4.7u (bulk) | GRM21BR71A475KA73L | Capacitor_SMD:C_0805_2012Metric | False | front | F.Cu | 140.9 | 70.3 | 180.0 | 110.349999 | 33.75 | 180.0 | 1.6 | 0.0 | verified_maximum | maximum | 1.4 | https://search.murata.co.jp/Ceramy/image/img/A01X/G101/ENG/GRM21BR71A475KA73-01.pdf | 1.4 |  |  |  | 8.0 | 9.4 |  |  | d4f10273215db5e6d2a23fbbb6d47d9f501da9e0ff759512a6f8be15966a65b5
center | other | C27 | 100n (VBAT) | GRM188R71H104KA93D | Capacitor_SMD:C_0603_1608Metric | False | back | B.Cu | 143.7 | 60.7 | 90.0 | 113.149999 | 24.15 | 90.0 | 1.6 | -1.6 | verified_maximum | maximum | 0.9 | https://www.murata.com/-/media/webrenewal/tool/library/common-pdf/dynamic-model/component-list-d-mlcc-2506.ashx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 | -2.5 |  | 0.3 | -2.8 | 6.4 | 5.5 |  | 5.2 | d4f10273215db5e6d2a23fbbb6d47d9f501da9e0ff759512a6f8be15966a65b5
center | other | C28 | 1u (VDDA) | GRM21BR71A105KA01L | Capacitor_SMD:C_0805_2012Metric | False | back | B.Cu | 143.45 | 69.4 | 180.0 | 112.899999 | 32.85 | 180.0 | 1.6 | -1.6 | verified_maximum | maximum | 1.35 | https://www.mouser.com/catalog/specsheets/grm21br71a105ka01.pdf | -2.95 |  | 0.3 | -3.25 | 6.4 | 5.05 |  | 4.75 | d4f10273215db5e6d2a23fbbb6d47d9f501da9e0ff759512a6f8be15966a65b5
center | other | C29 | 2.2u (VCAP_1, mandatory) | GRM21BR71C225KA12L | Capacitor_SMD:C_0805_2012Metric | False | back | B.Cu | 156.9 | 69.9 | 90.0 | 126.349999 | 33.35 | 90.0 | 1.6 | -1.6 | verified_maximum | maximum | 1.35 | https://www.farnell.com/datasheets/4088041.pdf | -2.95 |  | 0.3 | -3.25 | 6.4 | 5.05 |  | 4.75 | d4f10273215db5e6d2a23fbbb6d47d9f501da9e0ff759512a6f8be15966a65b5
center | other | C30 | 2.2u (VCAP_2, mandatory) | GRM21BR71C225KA12L | Capacitor_SMD:C_0805_2012Metric | False | back | B.Cu | 160.15 | 60.7 | 0.0 | 129.599999 | 24.15 | 0.0 | 1.6 | -1.6 | verified_maximum | maximum | 1.35 | https://www.farnell.com/datasheets/4088041.pdf | -2.95 |  | 0.3 | -3.25 | 6.4 | 5.05 |  | 4.75 | d4f10273215db5e6d2a23fbbb6d47d9f501da9e0ff759512a6f8be15966a65b5
center | other | C31 | 100n | GRM188R71H104KA93D | Capacitor_SMD:C_0603_1608Metric | False | back | B.Cu | 143.2 | 65.1 | 180.0 | 112.649999 | 28.55 | 180.0 | 1.6 | -1.6 | verified_maximum | maximum | 0.9 | https://www.murata.com/-/media/webrenewal/tool/library/common-pdf/dynamic-model/component-list-d-mlcc-2506.ashx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 | -2.5 |  | 0.3 | -2.8 | 6.4 | 5.5 |  | 5.2 | d4f10273215db5e6d2a23fbbb6d47d9f501da9e0ff759512a6f8be15966a65b5
center | other | C32 | 10p C0G 0.25pF HSE load | C0603C100C5GACTU | Capacitor_SMD:C_0603_1608Metric | False | front | F.Cu | 136.95 | 62.8 | 180.0 | 106.399999 | 26.25 | 180.0 | 1.6 | 0.0 | unverified |  |  |  |  |  |  |  | 8.0 |  |  |  | d4f10273215db5e6d2a23fbbb6d47d9f501da9e0ff759512a6f8be15966a65b5
center | other | C33 | 10p C0G 0.25pF HSE load | C0603C100C5GACTU | Capacitor_SMD:C_0603_1608Metric | False | front | F.Cu | 139.1 | 68.55 | 180.0 | 108.549999 | 32.0 | 180.0 | 1.6 | 0.0 | unverified |  |  |  |  |  |  |  | 8.0 |  |  |  | d4f10273215db5e6d2a23fbbb6d47d9f501da9e0ff759512a6f8be15966a65b5
center | other | C34 | 6.8p C0G 0.25pF LSE load | C0603C689C5GACTU | Capacitor_SMD:C_0603_1608Metric | False | front | F.Cu | 140.3 | 56.95 | 0.0 | 109.749999 | 20.4 | 0.0 | 1.6 | 0.0 | unverified |  |  |  |  |  |  |  | 8.0 |  |  |  | d4f10273215db5e6d2a23fbbb6d47d9f501da9e0ff759512a6f8be15966a65b5
center | other | C35 | 6.8p C0G 0.25pF LSE load | C0603C689C5GACTU | Capacitor_SMD:C_0603_1608Metric | False | front | F.Cu | 137.3 | 61.2 | 180.0 | 106.749999 | 24.65 | 180.0 | 1.6 | 0.0 | unverified |  |  |  |  |  |  |  | 8.0 |  |  |  | d4f10273215db5e6d2a23fbbb6d47d9f501da9e0ff759512a6f8be15966a65b5
center | other | C36 | 10u 50V X7R VIN | CGA5L1X7R1H106K160AC | Capacitor_SMD:C_1206_3216Metric | False | front | F.Cu | 171.3 | 72.05 | 0.0 | 140.749999 | 35.5 | 0.0 | 1.6 | 0.0 | verified_maximum | maximum | 1.9 | https://product.tdk.com/en/search/capacitor/ceramic/mlcc/info?part_no=CGA5L1X7R1H106K160AC | 1.9 |  |  |  | 8.0 | 9.9 |  |  | d4f10273215db5e6d2a23fbbb6d47d9f501da9e0ff759512a6f8be15966a65b5
center | other | C37 | 100n 50V X7R VIN HF | GRM188R71H104KA93D | Capacitor_SMD:C_0603_1608Metric | False | front | F.Cu | 167.4 | 71.4 | 0.0 | 136.849999 | 34.85 | 0.0 | 1.6 | 0.0 | verified_maximum | maximum | 0.9 | https://www.murata.com/-/media/webrenewal/tool/library/common-pdf/dynamic-model/component-list-d-mlcc-2506.ashx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 | 0.9 |  |  |  | 8.0 | 8.9 |  |  | d4f10273215db5e6d2a23fbbb6d47d9f501da9e0ff759512a6f8be15966a65b5
center | other | C38 | 100n (BOOT cap) | GRM188R71H104KA93D | Capacitor_SMD:C_0603_1608Metric | False | front | F.Cu | 168.65 | 69.05 | 270.0 | 138.099999 | 32.5 | 270.0 | 1.6 | 0.0 | verified_maximum | maximum | 0.9 | https://www.murata.com/-/media/webrenewal/tool/library/common-pdf/dynamic-model/component-list-d-mlcc-2506.ashx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 | 0.9 |  |  |  | 8.0 | 8.9 |  |  | d4f10273215db5e6d2a23fbbb6d47d9f501da9e0ff759512a6f8be15966a65b5
center | other | C39 | 22u 25V X7R MCU_3V3 output; TI characterized part | GRM32ER71E226KE15L | Capacitor_SMD:C_1210_3225Metric | False | front | F.Cu | 167.5 | 57.7 | 90.0 | 136.949999 | 21.15 | 90.0 | 1.6 | 0.0 | verified_maximum | maximum | 2.7 | https://www.murata.com/en-global/api/pdfdownloadapi?cate=luCeramicCapacitorsSMD&partno=GRM32ER71E226KE15%23 | 2.7 |  |  |  | 8.0 | 10.7 |  |  | d4f10273215db5e6d2a23fbbb6d47d9f501da9e0ff759512a6f8be15966a65b5
center | other | C40 | 10u 50V SYS5 input | CGA5L1X7R1H106K160AC | Capacitor_SMD:C_1206_3216Metric | False | front | F.Cu | 135.250001 | 145.45 | 0.0 | 104.7 | 108.9 | 0.0 | 1.6 | 0.0 | verified_maximum | maximum | 1.9 | https://product.tdk.com/en/search/capacitor/ceramic/mlcc/info?part_no=CGA5L1X7R1H106K160AC | 1.9 |  |  |  | 8.0 | 9.9 |  |  | d4f10273215db5e6d2a23fbbb6d47d9f501da9e0ff759512a6f8be15966a65b5
center | other | C41 | 10u 50V SYS5 input | CGA5L1X7R1H106K160AC | Capacitor_SMD:C_1206_3216Metric | False | front | F.Cu | 127.550001 | 151.05 | 270.0 | 97.0 | 114.5 | 270.0 | 1.6 | 0.0 | verified_maximum | maximum | 1.9 | https://product.tdk.com/en/search/capacitor/ceramic/mlcc/info?part_no=CGA5L1X7R1H106K160AC | 1.9 |  |  |  | 8.0 | 9.9 |  |  | d4f10273215db5e6d2a23fbbb6d47d9f501da9e0ff759512a6f8be15966a65b5
center | other | C42 | 100n 50V SYS5 input HF | GRM188R71H104KA93D | Capacitor_SMD:C_0603_1608Metric | False | front | F.Cu | 135.250001 | 147.95 | 0.0 | 104.7 | 111.4 | 0.0 | 1.6 | 0.0 | verified_maximum | maximum | 0.9 | https://www.murata.com/-/media/webrenewal/tool/library/common-pdf/dynamic-model/component-list-d-mlcc-2506.ashx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 | 0.9 |  |  |  | 8.0 | 8.9 |  |  | d4f10273215db5e6d2a23fbbb6d47d9f501da9e0ff759512a6f8be15966a65b5
center | other | C43 | 47n 25V SYS5 bootstrap | GRM155R71E473KA88D | Capacitor_SMD:C_0402_1005Metric | False | front | F.Cu | 130.350001 | 153.7 | 180.0 | 99.8 | 117.15 | 180.0 | 1.6 | 0.0 | unverified |  |  |  |  |  |  |  | 8.0 |  |  |  | d4f10273215db5e6d2a23fbbb6d47d9f501da9e0ff759512a6f8be15966a65b5
center | other | C44 | 22u 25V SYS5 output; TI characterized part | GRM32ER71E226KE15L | Capacitor_SMD:C_1210_3225Metric | False | front | F.Cu | 158.550001 | 154.05 | 0.0 | 128.0 | 117.5 | 0.0 | 1.6 | 0.0 | verified_maximum | maximum | 2.7 | https://www.murata.com/en-global/api/pdfdownloadapi?cate=luCeramicCapacitorsSMD&partno=GRM32ER71E226KE15%23 | 2.7 |  |  |  | 8.0 | 10.7 |  |  | d4f10273215db5e6d2a23fbbb6d47d9f501da9e0ff759512a6f8be15966a65b5
center | other | C45 | 22u 25V SYS5 output; TI characterized part | GRM32ER71E226KE15L | Capacitor_SMD:C_1210_3225Metric | False | front | F.Cu | 163.550001 | 154.05 | 0.0 | 133.0 | 117.5 | 0.0 | 1.6 | 0.0 | verified_maximum | maximum | 2.7 | https://www.murata.com/en-global/api/pdfdownloadapi?cate=luCeramicCapacitorsSMD&partno=GRM32ER71E226KE15%23 | 2.7 |  |  |  | 8.0 | 10.7 |  |  | d4f10273215db5e6d2a23fbbb6d47d9f501da9e0ff759512a6f8be15966a65b5
center | other | C46 | 10u 50V X7R TPS56637 VIN | CGA5L1X7R1H106K160AC | Capacitor_SMD:C_1206_3216Metric | False | front | F.Cu | 132.875001 | 63.35 | 90.0 | 102.325 | 26.8 | 90.0 | 1.6 | 0.0 | verified_maximum | maximum | 1.9 | https://product.tdk.com/en/search/capacitor/ceramic/mlcc/info?part_no=CGA5L1X7R1H106K160AC | 1.9 |  |  |  | 8.0 | 9.9 |  |  | d4f10273215db5e6d2a23fbbb6d47d9f501da9e0ff759512a6f8be15966a65b5
center | other | C47 | 100n 16V X7R TPS56637 BOOT | C1608X7R1C104K080AA | Capacitor_SMD:C_0603_1608Metric | False | front | F.Cu | 132.495001 | 67.325 | 90.0 | 101.945 | 30.775 | 90.0 | 1.6 | 0.0 | unverified |  |  |  |  |  |  |  | 8.0 |  |  |  | d4f10273215db5e6d2a23fbbb6d47d9f501da9e0ff759512a6f8be15966a65b5
center | other | C48 | 22u 25V X7R TPS56637 OUT; TI example part | GRM32ER71E226KE15L | Capacitor_SMD:C_1210_3225Metric | False | front | F.Cu | 126.495001 | 79.71 | 270.0 | 95.945 | 43.16 | 270.0 | 1.6 | 0.0 | verified_maximum | maximum | 2.7 | https://www.murata.com/en-global/api/pdfdownloadapi?cate=luCeramicCapacitorsSMD&partno=GRM32ER71E226KE15%23 | 2.7 |  |  |  | 8.0 | 10.7 |  |  | d4f10273215db5e6d2a23fbbb6d47d9f501da9e0ff759512a6f8be15966a65b5
center | other | C66 | 100n 10V X7R Mu USB3 TX AC | GRM155R71A104KA01D | Capacitor_SMD:C_0402_1005Metric | False | front | F.Cu | 204.6 | 50.8 | 180.0 | 174.049999 | 14.25 | 180.0 | 1.6 | 0.0 | verified_maximum | maximum | 0.55 | https://www.farnell.com/datasheets/4087771.pdf | 0.55 |  |  |  | 8.0 | 8.55 |  |  | d4f10273215db5e6d2a23fbbb6d47d9f501da9e0ff759512a6f8be15966a65b5
center | other | C67 | 100n 10V X7R Mu USB3 TX AC | GRM155R71A104KA01D | Capacitor_SMD:C_0402_1005Metric | False | front | F.Cu | 204.6 | 52.05 | 180.0 | 174.049999 | 15.5 | 180.0 | 1.6 | 0.0 | verified_maximum | maximum | 0.55 | https://www.farnell.com/datasheets/4087771.pdf | 0.55 |  |  |  | 8.0 | 8.55 |  |  | d4f10273215db5e6d2a23fbbb6d47d9f501da9e0ff759512a6f8be15966a65b5
center | other | C68 | 220n 10V X7R NVMe TX AC | GRM155R71A224KE01D | Capacitor_SMD:C_0402_1005Metric | False | back | B.Cu | 220.25 | 130.875 | 0.0 | 189.699999 | 94.325 | 0.0 | 1.6 | -1.6 | verified_maximum | maximum | 0.55 | https://search.murata.co.jp/Ceramy/image/img/A01X/G101/ENG/GRM155R71A224KE01-01.pdf | -2.15 |  | 0.3 | -2.45 | 6.4 | 5.85 |  | 5.55 | d4f10273215db5e6d2a23fbbb6d47d9f501da9e0ff759512a6f8be15966a65b5
center | other | C69 | 220n 10V X7R NVMe TX AC | GRM155R71A224KE01D | Capacitor_SMD:C_0402_1005Metric | False | back | B.Cu | 220.25 | 131.925 | 0.0 | 189.699999 | 95.375 | 0.0 | 1.6 | -1.6 | verified_maximum | maximum | 0.55 | https://search.murata.co.jp/Ceramy/image/img/A01X/G101/ENG/GRM155R71A224KE01-01.pdf | -2.15 |  | 0.3 | -2.45 | 6.4 | 5.85 |  | 5.55 | d4f10273215db5e6d2a23fbbb6d47d9f501da9e0ff759512a6f8be15966a65b5
center | other | C170 | 22u 25V X7R E-key bulk; TI characterized part | GRM32ER71E226KE15L | Capacitor_SMD:C_1210_3225Metric | False | front | F.Cu | 189.300001 | 148.05 | 180.0 | 158.75 | 111.5 | 180.0 | 1.6 | 0.0 | verified_maximum | maximum | 2.7 | https://www.murata.com/en-global/api/pdfdownloadapi?cate=luCeramicCapacitorsSMD&partno=GRM32ER71E226KE15%23 | 2.7 |  |  |  | 8.0 | 10.7 |  |  | d4f10273215db5e6d2a23fbbb6d47d9f501da9e0ff759512a6f8be15966a65b5
center | other | C171 | 100n radio bypass | GRM188R71H104KA93D | Capacitor_SMD:C_0603_1608Metric | False | back | B.Cu | 219.3 | 150.6 | 0.0 | 188.749999 | 114.05 | 0.0 | 1.6 | -1.6 | verified_maximum | maximum | 0.9 | https://www.murata.com/-/media/webrenewal/tool/library/common-pdf/dynamic-model/component-list-d-mlcc-2506.ashx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 | -2.5 |  | 0.3 | -2.8 | 6.4 | 5.5 |  | 5.2 | d4f10273215db5e6d2a23fbbb6d47d9f501da9e0ff759512a6f8be15966a65b5
center | other | C174 | 1u OLED A local | GRM21BR71A105KA01L | Capacitor_SMD:C_0805_2012Metric | False | front | F.Cu | 304.700001 | 60.925001 | 90.0 | 274.15 | 24.375001 | 90.0 | 1.6 | 0.0 | verified_maximum | maximum | 1.35 | https://www.mouser.com/catalog/specsheets/grm21br71a105ka01.pdf | 1.35 |  |  |  | 8.0 | 9.35 |  |  | d4f10273215db5e6d2a23fbbb6d47d9f501da9e0ff759512a6f8be15966a65b5
center | other | C175 | 100n OLED A local | GRM188R71H104KA93D | Capacitor_SMD:C_0603_1608Metric | False | front | F.Cu | 305.200001 | 63.425001 | 0.0 | 274.65 | 26.875001 | 0.0 | 1.6 | 0.0 | verified_maximum | maximum | 0.9 | https://www.murata.com/-/media/webrenewal/tool/library/common-pdf/dynamic-model/component-list-d-mlcc-2506.ashx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 | 0.9 |  |  |  | 8.0 | 8.9 |  |  | d4f10273215db5e6d2a23fbbb6d47d9f501da9e0ff759512a6f8be15966a65b5
center | other | C178 | 1u OLED B local | GRM21BR71A105KA01L | Capacitor_SMD:C_0805_2012Metric | False | front | F.Cu | 305.450001 | 190.425 | 0.0 | 274.9 | 153.875 | 0.0 | 1.6 | 0.0 | verified_maximum | maximum | 1.35 | https://www.mouser.com/catalog/specsheets/grm21br71a105ka01.pdf | 1.35 |  |  |  | 8.0 | 9.35 |  |  | d4f10273215db5e6d2a23fbbb6d47d9f501da9e0ff759512a6f8be15966a65b5
center | other | C179 | 100n OLED B local | GRM188R71H104KA93D | Capacitor_SMD:C_0603_1608Metric | False | front | F.Cu | 305.700001 | 192.175 | 180.0 | 275.15 | 155.625 | 180.0 | 1.6 | 0.0 | verified_maximum | maximum | 0.9 | https://www.murata.com/-/media/webrenewal/tool/library/common-pdf/dynamic-model/component-list-d-mlcc-2506.ashx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 | 0.9 |  |  |  | 8.0 | 8.9 |  |  | d4f10273215db5e6d2a23fbbb6d47d9f501da9e0ff759512a6f8be15966a65b5
center | other | C180 | 100n BAT filter | GRM188R71H104KA93D | Capacitor_SMD:C_0603_1608Metric | False | front | F.Cu | 193.548751 | 181.275 | 0.0 | 162.99875 | 144.725 | 0.0 | 1.6 | 0.0 | verified_maximum | maximum | 0.9 | https://www.murata.com/-/media/webrenewal/tool/library/common-pdf/dynamic-model/component-list-d-mlcc-2506.ashx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 | 0.9 |  |  |  | 8.0 | 8.9 |  |  | d4f10273215db5e6d2a23fbbb6d47d9f501da9e0ff759512a6f8be15966a65b5
center | other | C181 | 100n sense filter | GRM188R71H104KA93D | Capacitor_SMD:C_0603_1608Metric | False | front | F.Cu | 201.160001 | 177.025 | 90.0 | 170.61 | 140.475 | 90.0 | 1.6 | 0.0 | verified_maximum | maximum | 0.9 | https://www.murata.com/-/media/webrenewal/tool/library/common-pdf/dynamic-model/component-list-d-mlcc-2506.ashx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 | 0.9 |  |  |  | 8.0 | 8.9 |  |  | d4f10273215db5e6d2a23fbbb6d47d9f501da9e0ff759512a6f8be15966a65b5
center | other | C182 | 100n REGIN/VCC | GRM188R71H104KA93D | Capacitor_SMD:C_0603_1608Metric | False | front | F.Cu | 196.548751 | 181.175 | 0.0 | 165.99875 | 144.625 | 0.0 | 1.6 | 0.0 | verified_maximum | maximum | 0.9 | https://www.murata.com/-/media/webrenewal/tool/library/common-pdf/dynamic-model/component-list-d-mlcc-2506.ashx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 | 0.9 |  |  |  | 8.0 | 8.9 |  |  | d4f10273215db5e6d2a23fbbb6d47d9f501da9e0ff759512a6f8be15966a65b5
center | other | C183 | 1u REG25 | GRM21BR71A105KA01L | Capacitor_SMD:C_0805_2012Metric | False | front | F.Cu | 196.798751 | 183.0 | 0.0 | 166.24875 | 146.45 | 0.0 | 1.6 | 0.0 | verified_maximum | maximum | 1.35 | https://www.mouser.com/catalog/specsheets/grm21br71a105ka01.pdf | 1.35 |  |  |  | 8.0 | 9.35 |  |  | d4f10273215db5e6d2a23fbbb6d47d9f501da9e0ff759512a6f8be15966a65b5
center | other | C185 | 100n OLED mux local | GRM188R71H104KA93D | Capacitor_SMD:C_0603_1608Metric | False | front | F.Cu | 130.187501 | 53.125 | 270.0 | 99.6375 | 16.575 | 270.0 | 1.6 | 0.0 | verified_maximum | maximum | 0.9 | https://www.murata.com/-/media/webrenewal/tool/library/common-pdf/dynamic-model/component-list-d-mlcc-2506.ashx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 | 0.9 |  |  |  | 8.0 | 8.9 |  |  | d4f10273215db5e6d2a23fbbb6d47d9f501da9e0ff759512a6f8be15966a65b5
center | other | C187 | 100n E-key control-isolator local | GRM188R71H104KA93D | Capacitor_SMD:C_0603_1608Metric | False | front | F.Cu | 197.050001 | 147.3 | 180.0 | 166.5 | 110.75 | 180.0 | 1.6 | 0.0 | verified_maximum | maximum | 0.9 | https://www.murata.com/-/media/webrenewal/tool/library/common-pdf/dynamic-model/component-list-d-mlcc-2506.ashx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 | 0.9 |  |  |  | 8.0 | 8.9 |  |  | d4f10273215db5e6d2a23fbbb6d47d9f501da9e0ff759512a6f8be15966a65b5
center | other | C192 | 100n AUX ADC filter | GRM188R71H104KA93D | Capacitor_SMD:C_0603_1608Metric | False | front | F.Cu | 209.010001 | 148.01 | 0.0 | 178.46 | 111.46 | 0.0 | 1.6 | 0.0 | verified_maximum | maximum | 0.9 | https://www.murata.com/-/media/webrenewal/tool/library/common-pdf/dynamic-model/component-list-d-mlcc-2506.ashx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 | 0.9 |  |  |  | 8.0 | 8.9 |  |  | d4f10273215db5e6d2a23fbbb6d47d9f501da9e0ff759512a6f8be15966a65b5
center | other | C202 | 100n thermal ADC filter | GRM188R71H104KA93D | Capacitor_SMD:C_0603_1608Metric | False | back | B.Cu | 148.3 | 73.3 | 270.0 | 117.749999 | 36.75 | 270.0 | 1.6 | -1.6 | verified_maximum | maximum | 0.9 | https://www.murata.com/-/media/webrenewal/tool/library/common-pdf/dynamic-model/component-list-d-mlcc-2506.ashx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 | -2.5 |  | 0.3 | -2.8 | 6.4 | 5.5 |  | 5.2 | d4f10273215db5e6d2a23fbbb6d47d9f501da9e0ff759512a6f8be15966a65b5
center | other | C205 | 10u 25V X7R fan local bulk | GRM31CR71E106KA12L | Capacitor_SMD:C_1206_3216Metric | False | back | B.Cu | 195.0 | 116.8 | 180.0 | 164.449999 | 80.25 | 180.0 | 1.6 | -1.6 | verified_maximum | maximum | 1.8 | https://docs.rs-online.com/aab4/0900766b813d2ca8.pdf | -3.4 |  | 0.3 | -3.7 | 6.4 | 4.6 |  | 4.3 | d4f10273215db5e6d2a23fbbb6d47d9f501da9e0ff759512a6f8be15966a65b5
center | other | C206 | 100n 25V X7R fan local | GRM188R71E104KA01D | Capacitor_SMD:C_0603_1608Metric | False | front | F.Cu | 198.75 | 119.65 | 180.0 | 168.199999 | 83.1 | 180.0 | 1.6 | 0.0 | unverified |  |  |  |  |  |  |  | 8.0 |  |  |  | d4f10273215db5e6d2a23fbbb6d47d9f501da9e0ff759512a6f8be15966a65b5
center | other | C207 | 100n Mu thermal ADC filter | GRM188R71H104KA93D | Capacitor_SMD:C_0603_1608Metric | False | back | B.Cu | 150.05 | 73.35 | 270.0 | 119.499999 | 36.8 | 270.0 | 1.6 | -1.6 | verified_maximum | maximum | 0.9 | https://www.murata.com/-/media/webrenewal/tool/library/common-pdf/dynamic-model/component-list-d-mlcc-2506.ashx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 | -2.5 |  | 0.3 | -2.8 | 6.4 | 5.5 |  | 5.2 | d4f10273215db5e6d2a23fbbb6d47d9f501da9e0ff759512a6f8be15966a65b5
center | other | C208 | 100n EC USB switch local | GRM188R71H104KA93D | Capacitor_SMD:C_0603_1608Metric | False | back | B.Cu | 170.1 | 56.35 | 90.0 | 139.549999 | 19.8 | 90.0 | 1.6 | -1.6 | verified_maximum | maximum | 0.9 | https://www.murata.com/-/media/webrenewal/tool/library/common-pdf/dynamic-model/component-list-d-mlcc-2506.ashx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 | -2.5 |  | 0.3 | -2.8 | 6.4 | 5.5 |  | 5.2 | d4f10273215db5e6d2a23fbbb6d47d9f501da9e0ff759512a6f8be15966a65b5
center | other | C209 | 3.9n fan FG filter | GRM1555C1H392JA01D | Capacitor_SMD:C_0402_1005Metric | False | front | F.Cu | 149.2 | 73.85 | 180.0 | 118.649999 | 37.3 | 180.0 | 1.6 | 0.0 | unverified |  |  |  |  |  |  |  | 8.0 |  |  |  | d4f10273215db5e6d2a23fbbb6d47d9f501da9e0ff759512a6f8be15966a65b5
center | other | C280 | 100n TPS2553 input bypass | GRM188R71E104KA01D | Capacitor_SMD:C_0603_1608Metric | False | front | F.Cu | 165.912501 | 187.35 | 90.0 | 135.3625 | 150.8 | 90.0 | 1.6 | 0.0 | unverified |  |  |  |  |  |  |  | 8.0 |  |  |  | d4f10273215db5e6d2a23fbbb6d47d9f501da9e0ff759512a6f8be15966a65b5
center | other | C283 | 10u trackpad cable VBUS | GRM31CR71E106KA12L | Capacitor_SMD:C_1206_3216Metric | False | front | F.Cu | 171.437501 | 187.6 | 0.0 | 140.8875 | 151.05 | 0.0 | 1.6 | 0.0 | verified_maximum | maximum | 1.8 | https://docs.rs-online.com/aab4/0900766b813d2ca8.pdf | 1.8 |  |  |  | 8.0 | 9.8 |  |  | d4f10273215db5e6d2a23fbbb6d47d9f501da9e0ff759512a6f8be15966a65b5
center | other | C290 | 10n (VDDA high-frequency) | GRM188R71H103KA01 | Capacitor_SMD:C_0603_1608Metric | False | back | B.Cu | 143.45 | 71.15 | 180.0 | 112.899999 | 34.6 | 180.0 | 1.6 | -1.6 | verified_maximum | maximum | 0.9 | https://www.farnell.com/datasheets/1747461.pdf | -2.5 |  | 0.3 | -2.8 | 6.4 | 5.5 |  | 5.2 | d4f10273215db5e6d2a23fbbb6d47d9f501da9e0ff759512a6f8be15966a65b5
center | other | C291 | 22u 25V X7R MCU_3V3 output; TI characterized part | GRM32ER71E226KE15L | Capacitor_SMD:C_1210_3225Metric | False | front | F.Cu | 163.3 | 57.9 | 180.0 | 132.749999 | 21.35 | 180.0 | 1.6 | 0.0 | verified_maximum | maximum | 2.7 | https://www.murata.com/en-global/api/pdfdownloadapi?cate=luCeramicCapacitorsSMD&partno=GRM32ER71E226KE15%23 | 2.7 |  |  |  | 8.0 | 10.7 |  |  | d4f10273215db5e6d2a23fbbb6d47d9f501da9e0ff759512a6f8be15966a65b5
center | other | C318 | 100n DNP keyboard 3V3 reserve |  | Capacitor_SMD:C_0603_1608Metric | True | front | F.Cu | 177.400001 | 97.8 | 270.0 | 146.85 | 61.25 | 270.0 | 1.6 | 0.0 | unverified |  |  |  |  |  |  |  | 8.0 |  |  |  | d4f10273215db5e6d2a23fbbb6d47d9f501da9e0ff759512a6f8be15966a65b5
center | other | C319 | 10u keyboard RGB switched-output bulk | GRM31CR71E106KA12L | Capacitor_SMD:C_1206_3216Metric | False | front | F.Cu | 189.0 | 86.3 | 270.0 | 158.449999 | 49.75 | 270.0 | 1.6 | 0.0 | verified_maximum | maximum | 1.8 | https://docs.rs-online.com/aab4/0900766b813d2ca8.pdf | 1.8 |  |  |  | 8.0 | 9.8 |  |  | d4f10273215db5e6d2a23fbbb6d47d9f501da9e0ff759512a6f8be15966a65b5
center | other | C322 | 100n keyboard RGB switch input | GRM188R71H104KA93D | Capacitor_SMD:C_0603_1608Metric | False | back | B.Cu | 184.65 | 82.95 | 180.0 | 154.099999 | 46.4 | 180.0 | 1.6 | -1.6 | verified_maximum | maximum | 0.9 | https://www.murata.com/-/media/webrenewal/tool/library/common-pdf/dynamic-model/component-list-d-mlcc-2506.ashx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 | -2.5 |  | 0.3 | -2.8 | 6.4 | 5.5 |  | 5.2 | d4f10273215db5e6d2a23fbbb6d47d9f501da9e0ff759512a6f8be15966a65b5
center | other | C323 | 100n keyboard RGB switch output | GRM188R71H104KA93D | Capacitor_SMD:C_0603_1608Metric | False | back | B.Cu | 184.9 | 79.55 | 90.0 | 154.349999 | 43.0 | 90.0 | 1.6 | -1.6 | verified_maximum | maximum | 0.9 | https://www.murata.com/-/media/webrenewal/tool/library/common-pdf/dynamic-model/component-list-d-mlcc-2506.ashx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 | -2.5 |  | 0.3 | -2.8 | 6.4 | 5.5 |  | 5.2 | d4f10273215db5e6d2a23fbbb6d47d9f501da9e0ff759512a6f8be15966a65b5
center | other | C324 | 100n keyboard RGB buffer local | GRM188R71H104KA93D | Capacitor_SMD:C_0603_1608Metric | False | back | B.Cu | 185.3 | 77.1 | 180.0 | 154.749999 | 40.55 | 180.0 | 1.6 | -1.6 | verified_maximum | maximum | 0.9 | https://www.murata.com/-/media/webrenewal/tool/library/common-pdf/dynamic-model/component-list-d-mlcc-2506.ashx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 | -2.5 |  | 0.3 | -2.8 | 6.4 | 5.5 |  | 5.2 | d4f10273215db5e6d2a23fbbb6d47d9f501da9e0ff759512a6f8be15966a65b5
center | other | C400 | 100n AUDIO_5V high-frequency bypass | GRM188R71H104KA93D | Capacitor_SMD:C_0603_1608Metric | False | front | F.Cu | 181.45 | 175.5 | 90.0 | 150.899999 | 138.95 | 90.0 | 1.6 | 0.0 | verified_maximum | maximum | 0.9 | https://www.murata.com/-/media/webrenewal/tool/library/common-pdf/dynamic-model/component-list-d-mlcc-2506.ashx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 | 0.9 |  |  |  | 8.0 | 8.9 |  |  | d4f10273215db5e6d2a23fbbb6d47d9f501da9e0ff759512a6f8be15966a65b5
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

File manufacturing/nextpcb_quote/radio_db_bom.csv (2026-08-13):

Designator | Value | Footprint | Qty | Manufacturer | MPN | DNP | Sheet
C1 | 10u 10V RADIO_DB_5V local bulk | Capacitor_SMD:C_1206_3216Metric | 1 | Murata | GRM31CR71E106KA12L
C2 | 1u AP2112 input local | Capacitor_SMD:C_0805_2012Metric | 1 | Murata | GRM21BR71A105KA01L
C3 | 1u AP2112 output local | Capacitor_SMD:C_0805_2012Metric | 1 | Murata | GRM21BR71A105KA01L
C4 | 10u RADIO_DB_3V3 local bulk | Capacitor_SMD:C_1206_3216Metric | 1 | Murata | GRM31CR71E106KA12L
C5 | 100n RADIO_DB_3V3 high-frequency | Capacitor_SMD:C_0603_1608Metric | 1 | Murata | GRM188R71H104KA93D
C40 | 100n GNSS input-buffer local | Capacitor_SMD:C_0603_1608Metric | 1 | Murata | GRM188R71H104KA93D
C41 | 10u GNSS local | Capacitor_SMD:C_1206_3216Metric | 1 | Murata | GRM31CR71E106KA12L
C42 | 100n GNSS local | Capacitor_SMD:C_0603_1608Metric | 1 | Murata | GRM188R71H104KA93D
C220 | 10u 25V X7R radio VIN | Capacitor_SMD:C_1206_3216Metric | 1 | Murata | GRM31CR71E106KA12L
C221 | 100n BOOT | Capacitor_SMD:C_0603_1608Metric | 1 | Murata | GRM188R71H104KA93D
C222,C225 | 22u 16V X7R radio output | Capacitor_SMD:C_1206_3216Metric | 2 | Murata | GRM31CZ71C226ME15L
C223 | 100n 50V X7R radio HF | Capacitor_SMD:C_0603_1608Metric | 1 | Murata | GRM188R71H104KA93D
C224 | 56p C0G TPS54302 feed-forward | Capacitor_SMD:C_0402_1005Metric | 1 | Murata | GRM1885C1H560JA01D
C226 | 10n VHF audio RF shunt | Capacitor_SMD:C_0603_1608Metric | 1 | Murata | GRM188R71H103KA01D
C227 | 10n UHF audio RF shunt | Capacitor_SMD:C_0603_1608Metric | 1 | Murata | GRM188R71H103KA01D
C240 | 100n VHF RF-select latch local | Capacitor_SMD:C_0603_1608Metric | 1 | Murata | GRM188R71H104KA93D
C243,C253 | 10n PE42820 VDD bypass per eval board | Capacitor_SMD:C_0603_1608Metric | 2 | Murata | GRM188R71H103KA01D
C244,C254 | 100p PE42820 V1 RF bypass per eval board | Capacitor_SMD:C_0603_1608Metric | 2 | Murata | GRM1885C1H101JA01D
C246 | 100n VHF fail-safe buffer local | Capacitor_SMD:C_0603_1608Metric | 1 | Murata | GRM188R71H104KA93D
C247 | 100n VHF UART translator RADIO_4V0 | Capacitor_SMD:C_0603_1608Metric | 1 | Murata | GRM188R71H104KA93D
C248 | 100n VHF UART translator 3V3 | Capacitor_SMD:C_0603_1608Metric | 1 | Murata | GRM188R71H104KA93D
C250 | 100n UHF RF-select latch local | Capacitor_SMD:C_0603_1608Metric | 1 | Murata | GRM188R71H104KA93D
C256 | 100n UHF fail-safe buffer local | Capacitor_SMD:C_0603_1608Metric | 1 | Murata | GRM188R71H104KA93D
C257 | 100n UHF UART translator RADIO_4V0 | Capacitor_SMD:C_0603_1608Metric | 1 | Murata | GRM188R71H104KA93D
C258 | 100n UHF UART translator 3V3 | Capacitor_SMD:C_0603_1608Metric | 1 | Murata | GRM188R71H104KA93D
C260,C261 | 100n PTT interlock local | Capacitor_SMD:C_0603_1608Metric | 2 | Murata | GRM188R71H104KA93D
C270 | 100p C0G 250V VHF PE42820 RFC DC block | Capacitor_SMD:C_0603_1608Metric | 1 | KYOCERA AVX | 600S101JT250XTV
C271 | 100p C0G 250V VHF PE42820 RF1_EXTERNAL DC block | Capacitor_SMD:C_0603_1608Metric | 1 | KYOCERA AVX | 600S101JT250XTV
C272 | 100p C0G 250V VHF PE42820 RF2_INTERNAL DC block | Capacitor_SMD:C_0603_1608Metric | 1 | KYOCERA AVX | 600S101JT250XTV
C273 | 100p C0G 250V UHF PE42820 RFC DC block | Capacitor_SMD:C_0603_1608Metric | 1 | KYOCERA AVX | 600S101JT250XTV
C274 | 100p C0G 250V UHF PE42820 RF1_EXTERNAL DC block | Capacitor_SMD:C_0603_1608Metric | 1 | KYOCERA AVX | 600S101JT250XTV
C275 | 100p C0G 250V UHF PE42820 RF2_INTERNAL DC block | Capacitor_SMD:C_0603_1608Metric | 1 | KYOCERA AVX | 600S101JT250XTV
C330 | 1u PCM2902C VBUS | Capacitor_SMD:C_0805_2012Metric | 1 | Murata | GRM21BR71A105KA01L
C331 | 10u VCCCI | Capacitor_SMD:C_1206_3216Metric | 1 | Murata | GRM31CR71E106KA12L
C332 | 1u VCCP1I (<2u) | Capacitor_SMD:C_0805_2012Metric | 1 | Murata | GRM21BR71A105KA01L
C333 | 1u VCCP2I (<2u) | Capacitor_SMD:C_0805_2012Metric | 1 | Murata | GRM21BR71A105KA01L
C334 | 1u VCCXI (<2u) | Capacitor_SMD:C_0805_2012Metric | 1 | Murata | GRM21BR71A105KA01L
C335 | 1u VDDI (<2u) | Capacitor_SMD:C_0805_2012Metric | 1 | Murata | GRM21BR71A105KA01L
C337 | 10u VCOM | Capacitor_SMD:C_1206_3216Metric | 1 | Murata | GRM31CR71E106KA12L
C338,C339 | 18p C0G 5% PCM2902 crystal load | Capacitor_SMD:C_0603_1608Metric | 2 | Murata | GRM1885C1H180JA01D
C340 | 1u VHF RX AC couple | Capacitor_SMD:C_0805_2012Metric | 1 | Murata | GRM21BR71A105KA01L
C341 | 1u UHF RX AC couple | Capacitor_SMD:C_0805_2012Metric | 1 | Murata | GRM21BR71A105KA01L
C342 | 1u VHF TX audio AC couple | Capacitor_SMD:C_0805_2012Metric | 1 | Murata | GRM21BR71A105KA01L
C343 | 1u UHF TX audio AC couple | Capacitor_SMD:C_0805_2012Metric | 1 | Murata | GRM21BR71A105KA01L
D390-D393 | BAT54WS PTT/suspend mute OR | Diode_SMD:D_SOD-323 | 4 | Diodes Incorporated | BAT54WS-7-F
FL240 | Mini-Circuits LFCN-160+ 2m/VHF LPF | Filter:Filter_Mini-Circuits_FV1206 | 1 | Mini-Circuits | LFCN-160+
FL250 | Mini-Circuits ULP-470+ 70cm/UHF LPF | ducktop2:MiniCircuits_QA2224_PL484 | 1 | Mini-Circuits | ULP-470+
J1 | DF40C 60-pin radio daughterboard receptacle | Connector_Hirose_DF40:Hirose_DF40C(2.0)-60DS-0.4V_2x30_P0.4mm | 1 | Hirose Electric | DF40C(2.0)-60DS-0.4V(51)
J42 | GNSS passive antenna U.FL | Connector_Coaxial:U.FL_Hirose_U.FL-R-SMT-1_Vertical | 1 | Hirose | U.FL-R-SMT-1(01)
J70 | DRA818V 2m FM module | ducktop2:DRA818_Castellated | 1 | Dorji Applied Technologies | DRA818V
J71 | DRA818U 70cm FM module | ducktop2:DRA818_Castellated | 1 | Dorji Applied Technologies | DRA818U
J240 | 2m/VHF internal/PCB antenna feed U.FL | Connector_Coaxial:U.FL_Hirose_U.FL-R-SMT-1_Vertical | 1 | Hirose | U.FL-R-SMT-1(01)
J241 | 2m/VHF rear external SMA/u.FL path | Connector_Coaxial:SMA_Molex_73251-1153_EdgeMount_Horizontal | 1 | Molex | 73251-1153
J250 | 70cm/UHF internal/PCB antenna feed U.FL | Connector_Coaxial:U.FL_Hirose_U.FL-R-SMT-1_Vertical | 1 | Hirose | U.FL-R-SMT-1(01)
J251 | 70cm/UHF rear external SMA/u.FL path | Connector_Coaxial:SMA_Molex_73251-1153_EdgeMount_Horizontal | 1 | Molex | 73251-1153
L70 | 3.3uH 20% 6.0A Isat20 | ducktop2:Coilcraft_XGL5030 | 1 | Coilcraft | XGL5030-332MEC
Q330 | 2N7002KT1G VHF PTT/suspend fail-mute shunt | Package_TO_SOT_SMD:SOT-23 | 1 | onsemi | 2N7002KT1G
Q331 | 2N7002KT1G UHF PTT/suspend fail-mute shunt | Package_TO_SOT_SMD:SOT-23 | 1 | onsemi | 2N7002KT1G
Q332 | BSS84LT1G codec-loss force-mute | Package_TO_SOT_SMD:SOT-23 | 1 | onsemi | BSS84LT1G
R40 | 100k GNSS local reset pull-up | Resistor_SMD:R_0603_1608Metric | 1 | Yageo | RC0603FR-07100KL
R41,R42 | 100R GNSS output series | Resistor_SMD:R_0603_1608Metric | 2 | Yageo | RC0603FR-07100RL
R220 | 100k radio rail enable | Resistor_SMD:R_0603_1608Metric | 1 | Yageo | RC0603FR-07100KL
R221 | 100k 1% 4.0V FB hi | Resistor_SMD:R_0603_1608Metric | 1 | Yageo | RC0603FR-07100KL
R222 | 17.4k 1% 4.0V FB lo | Resistor_SMD:R_0603_1608Metric | 1 | Yageo | RC0603FR-0717K4L
R225 | 100k VHF default sleep | Resistor_SMD:R_0603_1608Metric | 1 | Yageo | RC0603FR-07100KL
R226 | 100k UHF default sleep | Resistor_SMD:R_0603_1608Metric | 1 | Yageo | RC0603FR-07100KL
R227 | 47k 1% VHF antenna select default internal; PE42820 control divider low | Resistor_SMD:R_0603_1608Metric | 1 | Yageo | RC0603FR-0747KL
R228 | 47k 1% UHF antenna select default internal; PE42820 control divider low | Resistor_SMD:R_0603_1608Metric | 1 | Yageo | RC0603FR-0747KL
R229 | 0R VHF H/L LOW POWER - FIT | Resistor_SMD:R_0603_1608Metric | 1 | Yageo | RC0603FR-070RL
R230 | 100k VHF RF-select EC reset default internal | Resistor_SMD:R_0603_1608Metric | 1 | Yageo | RC0603FR-07100KL
R231 | 0R UHF H/L LOW POWER - FIT | Resistor_SMD:R_0603_1608Metric | 1 | Yageo | RC0603FR-070RL
R232 | 100k UHF RF-select EC reset default internal | Resistor_SMD:R_0603_1608Metric | 1 | Yageo | RC0603FR-07100KL
R233 | 1k VHF AF out | Resistor_SMD:R_0603_1608Metric | 1 | Yageo | RC0603FR-071KL
R234 | 1k UHF AF out | Resistor_SMD:R_0603_1608Metric | 1 | Yageo | RC0603FR-071KL
R235 | 10k VHF local PTT inactive | Resistor_SMD:R_0603_1608Metric | 1 | Yageo | RC0603FR-0710KL
R236 | 10k UHF local PTT inactive | Resistor_SMD:R_0603_1608Metric | 1 | Yageo | RC0603FR-0710KL
R237 | 10k VHF local sleep | Resistor_SMD:R_0603_1608Metric | 1 | Yageo | RC0603FR-0710KL
R238 | 10k UHF local sleep | Resistor_SMD:R_0603_1608Metric | 1 | Yageo | RC0603FR-0710KL
R242 | 10k 1% VHF PE42820 control divider top | Resistor_SMD:R_0603_1608Metric | 1 | Yageo | RC0603FR-0710KL
R243 | 100R VHF translated TXD series | Resistor_SMD:R_0603_1608Metric | 1 | Yageo | RC0603FR-07100RL
R260 | 10k 1% UHF PE42820 control divider top | Resistor_SMD:R_0603_1608Metric | 1 | Yageo | RC0603FR-0710KL
R261 | 100R UHF translated TXD series | Resistor_SMD:R_0603_1608Metric | 1 | Yageo | RC0603FR-07100RL
R330 | 22R USB DP series | Resistor_SMD:R_0603_1608Metric | 1 | Yageo | RC0603FR-0722RL
R331 | 22R USB DM series | Resistor_SMD:R_0603_1608Metric | 1 | Yageo | RC0603FR-0722RL
R334 | 82k 1% VHF mic attenuator series | Resistor_SMD:R_0603_1608Metric | 1 | Yageo | RC0603FR-0782KL
R335 | 82k 1% UHF mic attenuator series | Resistor_SMD:R_0603_1608Metric | 1 | Yageo | RC0603FR-0782KL
R336 | 1k 1% VHF mic attenuator shunt | Resistor_SMD:R_0603_1608Metric | 1 | Yageo | RC0603FR-071KL
R337 | 2.2R PCM2902C VBUS filter | Resistor_SMD:R_0603_1608Metric | 1 | Yageo | RC0603FR-072R2L
R338 | 1.5k USB D+ pull-up per TI Figure 39 | Resistor_SMD:R_0603_1608Metric | 1 | Yageo | RC0603FR-071K5L
R340 | 1M crystal feedback | Resistor_SMD:R_0603_1608Metric | 1 | Yageo | RC0603FR-071ML
R341 | 1k 1% UHF mic attenuator shunt | Resistor_SMD:R_0603_1608Metric | 1 | Yageo | RC0603FR-071KL
R342 | 100k SSPND fail-low pull-down | Resistor_SMD:R_0603_1608Metric | 1 | Yageo | RC0603FR-07100KL
R343 | 100k force-mute pull-down | Resistor_SMD:R_0603_1608Metric | 1 | Yageo | RC0603FR-07100KL
R344 | 100k VHF mute-gate pull-down | Resistor_SMD:R_0603_1608Metric | 1 | Yageo | RC0603FR-07100KL
R345 | 100k UHF mute-gate pull-down | Resistor_SMD:R_0603_1608Metric | 1 | Yageo | RC0603FR-07100KL
U1 | AP2112K-3.3 600mA daughterboard logic LDO | Package_TO_SOT_SMD:SOT-23-5 | 1 | Diodes Incorporated | AP2112K-3.3TRG1
U40 | MAX-M10S GNSS | RF_GPS:ublox_MAX | 1 | u-blox | MAX-M10S-00B
U41 | SN74LVC3G34 GNSS input isolation | Package_SO:VSSOP-8_2.3x2mm_P0.5mm | 1 | Texas Instruments | SN74LVC3G34DCUR
U70 | TPS54302 RADIO_DB_5V -> RADIO_4V0 | Package_TO_SOT_SMD:SOT-23-6 | 1 | Texas Instruments | TPS54302DDCR
U240 | PE42820B-X 2m/VHF 43dBm-CW RF switch | ducktop2:PE42820_QFN-32-1EP_5x5mm_P0.5mm | 1 | pSemi (Murata) | PE42820B-X
U241 | SN74LVC1G373DCKR VHF transmit-safe RF-select latch | Package_TO_SOT_SMD:SOT-363_SC-70-6 | 1 | Texas Instruments | SN74LVC1G373DCKR
U242 | SN74LVC3G34DCUR VHF fail-safe control buffer | Package_SO:VSSOP-8_2.3x2mm_P0.5mm | 1 | Texas Instruments | SN74LVC3G34DCUR
U243 | SN74LVC1T45 VHF TXD 4V-to-3V3 translator | Package_TO_SOT_SMD:SOT-23-6 | 1 | Texas Instruments | SN74LVC1T45DBVR
U250 | PE42820B-X 70cm/UHF 43dBm-CW RF switch | ducktop2:PE42820_QFN-32-1EP_5x5mm_P0.5mm | 1 | pSemi (Murata) | PE42820B-X
U251 | SN74LVC1G373DCKR UHF transmit-safe RF-select latch | Package_TO_SOT_SMD:SOT-363_SC-70-6 | 1 | Texas Instruments | SN74LVC1G373DCKR
U252 | SN74LVC3G34DCUR UHF fail-safe control buffer | Package_SO:VSSOP-8_2.3x2mm_P0.5mm | 1 | Texas Instruments | SN74LVC3G34DCUR
U253 | SN74LVC1T45 UHF TXD 4V-to-3V3 translator | Package_TO_SOT_SMD:SOT-23-6 | 1 | Texas Instruments | SN74LVC1T45DBVR
U260 | SN74LVC2G04DCKR PTT request inverter | Package_TO_SOT_SMD:SOT-363_SC-70-6 | 1 | Texas Instruments | SN74LVC2G04DCKR
U261 | SN74LVC2G32DCUR dual-radio PTT interlock | Package_SO:VSSOP-8_2.3x2mm_P0.5mm | 1 | Texas Instruments | SN74LVC2G32DCUR
U330 | PCM2902CDBR USB audio codec | Package_SO:SSOP-28_5.3x10.2mm_P0.65mm | 1 | Texas Instruments | PCM2902CDBR
Y330 | ABM8G-106-12.000MHZ-T 12MHz 10pF CL | Crystal:Crystal_SMD_3225-4Pin_3.2x2.5mm | 1 | Abracon | ABM8G-106-12.000MHZ-T

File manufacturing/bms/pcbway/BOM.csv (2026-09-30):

Designator | Quantity | Manufacturer | MPN | Description | Footprint | Mount | Notes
U11 | 1 | Analog Devices | LTC4368IMS-1#PBF | LTC4368IMS-1 bidirectional pack protector | Package_SO:MSOP-10_3x3mm_P0.5mm | SMT | exact part; no unapproved substitutions
D2201,D2202 | 2 | Diodes Incorporated | BAT54S-7-F | BAT54S control-island pin clamps | Package_TO_SOT_SMD:SOT-23 | SMT | exact part; no unapproved substitutions
D2200 | 1 | Diodes Incorporated | BAT54WS-7-F | BAT54WS protected control reverse-input block | Diode_SMD:D_SOD-323 | SMT | exact part; no unapproved substitutions
J2074 | 1 | JST | SM05B-SRSS-TB(LF)(SN) | isolated bms control | Connector_JST:JST_SH_SM05B-SRSS-TB_1x05-1MP_P1.00mm_Horizontal | SMT | exact part; no unapproved substitutions
J2200 | 1 | JST | SM06B-SRSS-TB(LF)(SN) | three cell probes: paired 1/2, 3/4, 5/6 | Connector_JST:JST_SH_SM06B-SRSS-TB_1x06-1MP_P1.00mm_Horizontal | SMT | exact part; no unapproved substitutions
J2 | 1 | Molex | 43045-0400 | 3S pack power + cell-tap harness | Connector_Molex:Molex_Micro-Fit_3.0_43045-0400_2x02_P3.00mm_Horizontal | THT | exact part; no unapproved substitutions
C700 | 1 | Murata | GRM155R71H332KA01 | 3.3nF >=50V LTC4368 CGATE | Capacitor_SMD:C_0402_1005Metric | SMT | exact part; no unapproved substitutions
C724 | 1 | Murata | GRM155R71H472KA01 | 4.7nF >=50V pack hot-swap slew | Capacitor_SMD:C_0402_1005Metric | SMT | exact part; no unapproved substitutions
C2211,C2212,C2213,C2240,C2241,C2242 | 6 | Murata | GRM188R71H103KA01D | 10n 50V NTC sense filter | Capacitor_SMD:C_0603_1608Metric | SMT | exact part; no unapproved substitutions
C845,C846,C847,C2200,C2221,C2222,C2223,C2230,C2231,C2250,C2251,C2252,C2253,C2255,C2256 | 15 | Murata | GRM188R71H104KA93D | 100n BQ77915 SRP-VSS filter | Capacitor_SMD:C_0603_1608Metric | SMT | exact part; no unapproved substitutions
C841,C842,C843,C844,C848 | 5 | Murata | GRM21BR71A105KA01L | 1u 10V X7R BQ77915 AVDD | Capacitor_SMD:C_0805_2012Metric | SMT | exact part; no unapproved substitutions
C840 | 1 | Murata | GRM21BR71H105KA12L | 1u 25V X7R BQ77915 VDD | Capacitor_SMD:C_0805_2012Metric | SMT | exact part; no unapproved substitutions
C725 | 1 | Murata | GRM21BZ71E106KE15L | 10u 25V X7R LTC4368 VOUT | Capacitor_SMD:C_0805_2012Metric | SMT | exact part; no unapproved substitutions
R2254 | 1 | Panasonic | ERJ2RKF1001X | 1k local retry gate series | Resistor_SMD:R_0402_1005Metric | SMT | exact part; no unapproved substitutions
F1 | 1 | SCHURTER | 3-101-056 | 5A fast pack fuse: Schurter HCF, 1kA at 125VDC | ducktop2:Schurter_HCF_8.05x5mm | SMT | exact part; no unapproved substitutions
C2243 | 1 | TDK | C1005X7R1H103K050BB | 10n 50V thermal reference filter | Capacitor_SMD:C_0402_1005Metric | SMT | exact part; no unapproved substitutions
C2201,C2254 | 2 | TDK | CGA5L1X7R1H106K160AC | 10u 50V thermal bias; require Ceff >=2u | Capacitor_SMD:C_1206_3216Metric | SMT | exact part; no unapproved substitutions
U719 | 1 | Texas Instruments | BQ7791500PWR | BQ7791500PWR autonomous 3S primary protector | Package_SO:TSSOP-24_4.4x7.8mm_P0.65mm | SMT | exact part; no unapproved substitutions
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

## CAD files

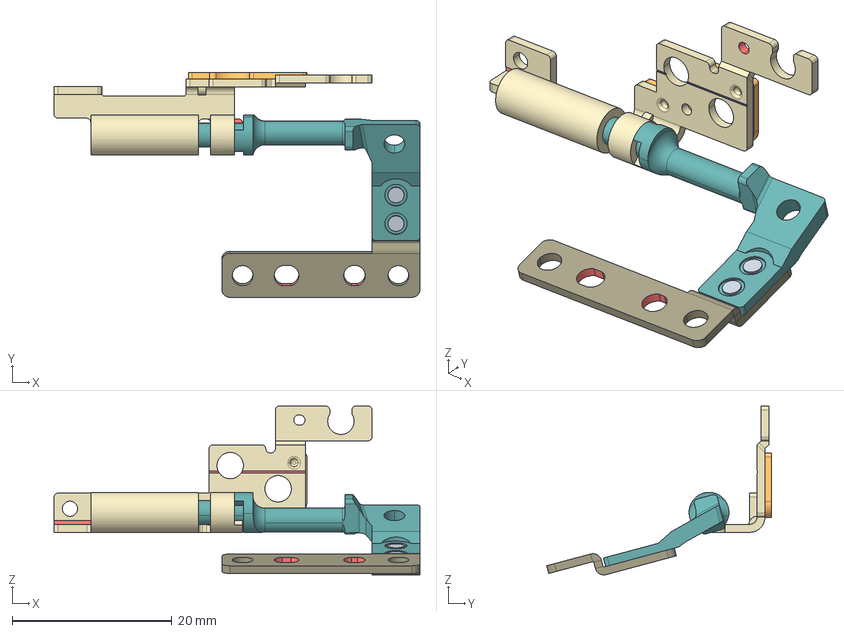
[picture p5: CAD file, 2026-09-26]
mechanical/case-prototype/reference/framework13/13_5_hinge_R_assy.stp
45.8 x 28.1 x 21.1 mm
GFW30_HINGE_R_LCD_BRK_R
GFW30_LCD_HINGE_SUP_BRK_R2
GFW30_HINGE_R_AXIS_0703
GFW30_HINGE_R_BASE_BRK
GFW30_BASE_HINGE_RIVET_R x 2

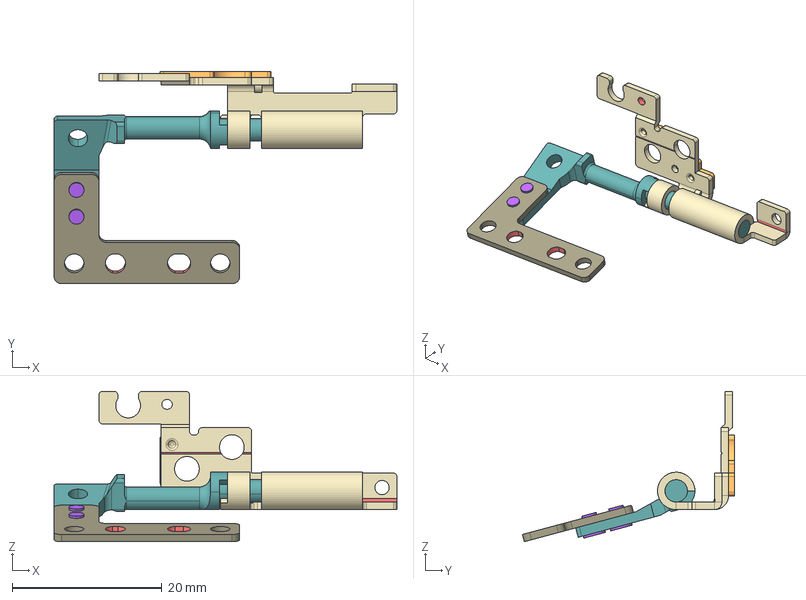
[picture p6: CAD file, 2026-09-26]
mechanical/case-prototype/reference/framework13/13_5_hinge_l_assy.stp
45.8 x 28.3 x 20.1 mm
GFW30_HINGE_L_LCD_BRK
GFW30_LCD_HINGE_SUP_BRK_L2
GFW30_HINGE_L_AXIS
GFW30_HINGE_L_BASE_BRK
GFW30_BASE_HINGE_RIVET_L x 2

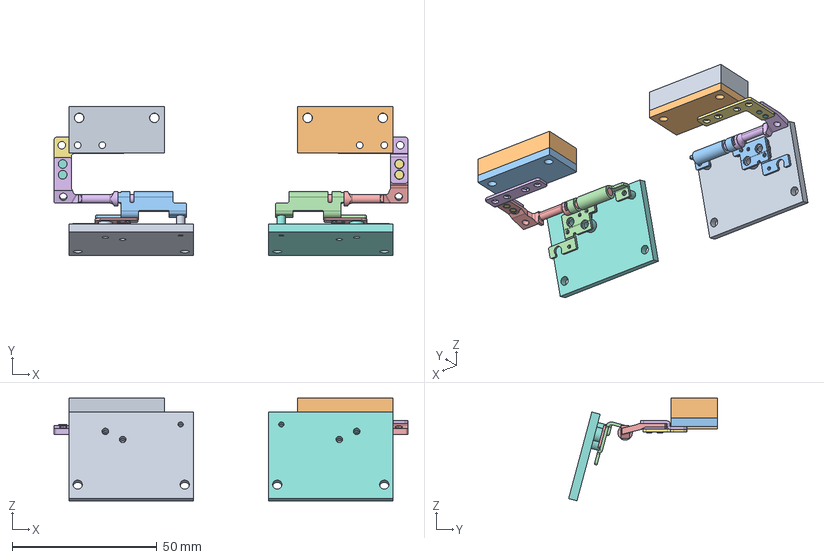
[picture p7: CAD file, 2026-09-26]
mechanical/case-prototype/exports/hinge-tests/hinge-coupon-assembly.step
122.4 x 51.4 x 35.5 mm

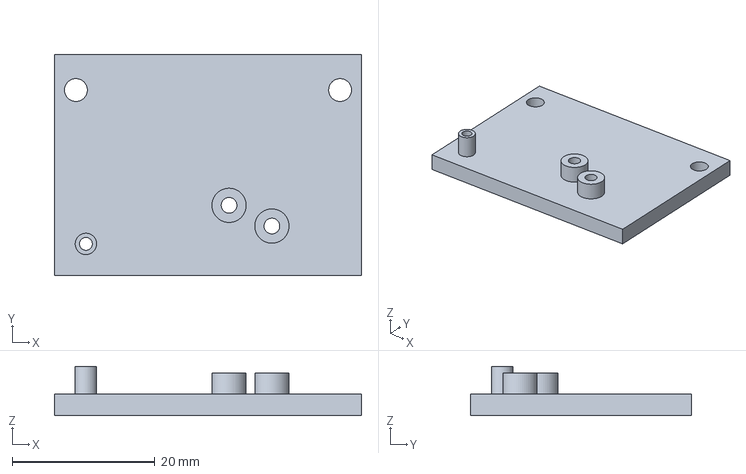
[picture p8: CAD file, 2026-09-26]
mechanical/case-prototype/exports/hinge-tests/right-lid-seat-gauge.step
43.0 x 31.0 x 6.90 mm

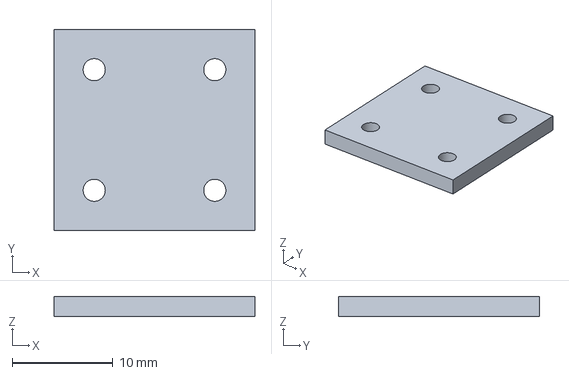
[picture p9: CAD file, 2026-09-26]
mechanical/case-prototype/exports/parts/lid-print-splice-2.step
20.0 x 20.0 x 2.00 mm

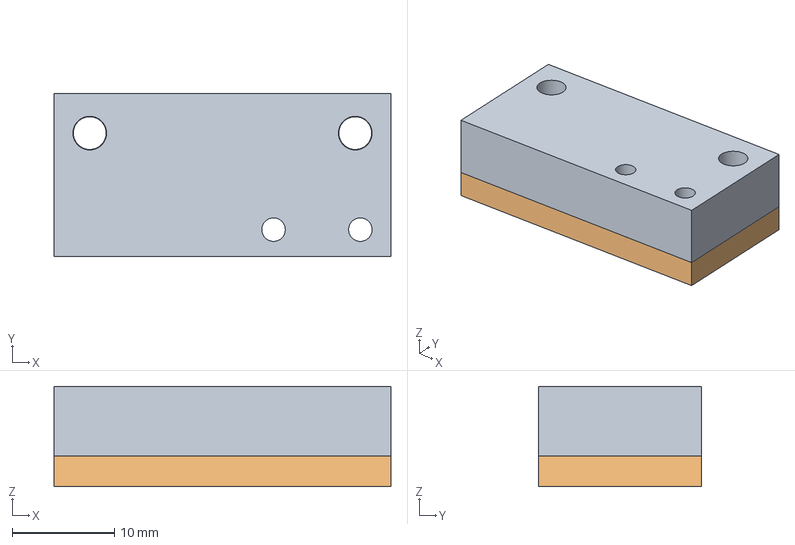
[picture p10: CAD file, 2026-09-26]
mechanical/case-prototype/exports/hinge-tests/right-base-coupon.step
33.0 x 16.0 x 9.80 mm

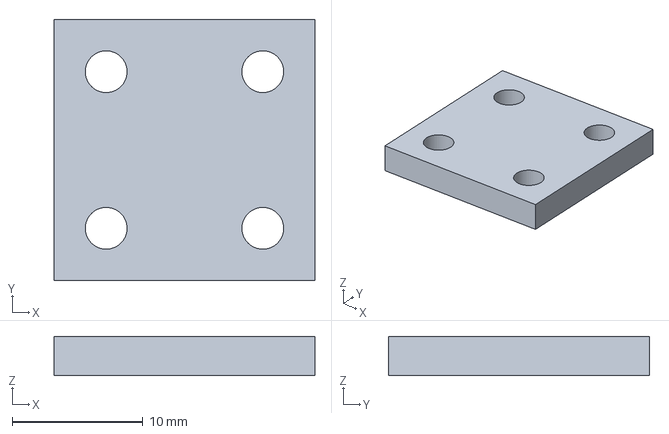
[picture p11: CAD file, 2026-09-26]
mechanical/case-prototype/exports/parts/base-splice-2.step
20.0 x 20.0 x 3.00 mm

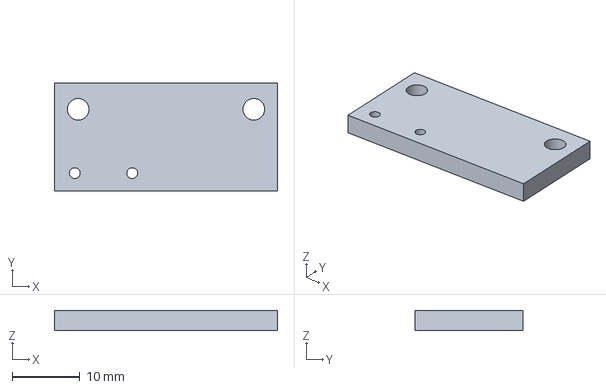
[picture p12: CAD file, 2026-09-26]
mechanical/case-prototype/exports/hinge-tests/left-base-steel-adapter.step
33.0 x 16.0 x 3.00 mm

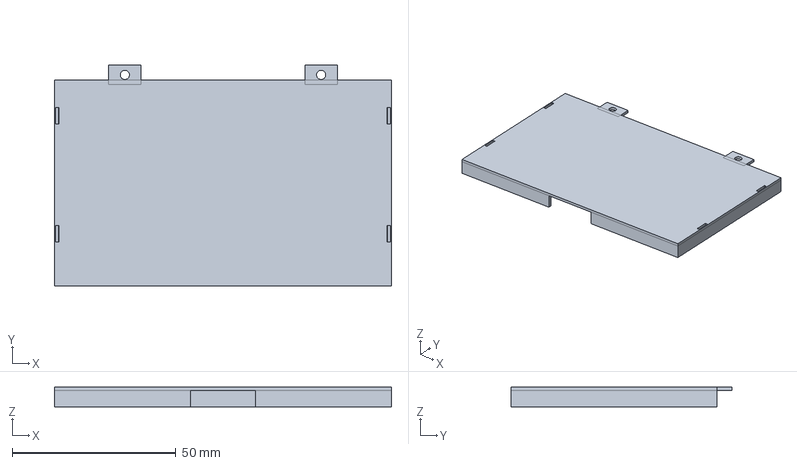
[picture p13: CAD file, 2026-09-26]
mechanical/case-prototype/exports/parts/cell-2-tray.step
103.0 x 67.5 x 6.00 mm

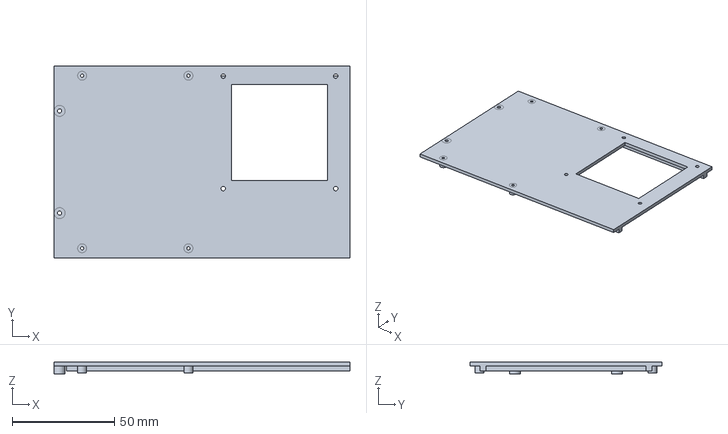
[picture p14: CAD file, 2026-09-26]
mechanical/case-prototype/exports/parts/keyboard-carrier-11.step
144.8 x 94.0 x 6.10 mm

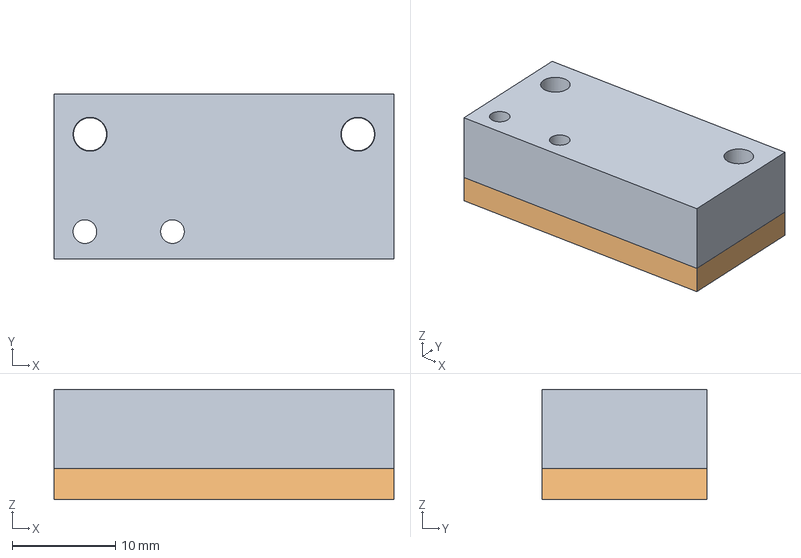
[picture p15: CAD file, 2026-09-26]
mechanical/case-prototype/exports/hinge-tests/left-base-coupon.step
33.0 x 16.0 x 10.7 mm

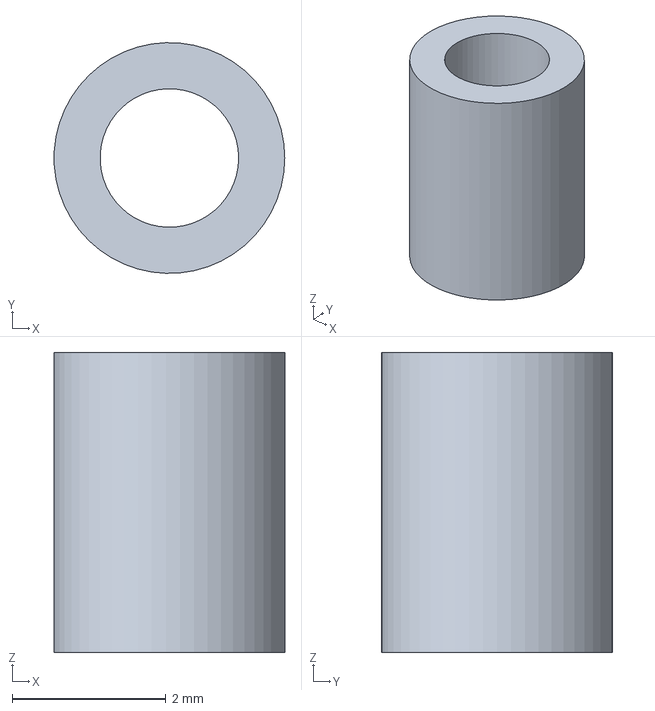
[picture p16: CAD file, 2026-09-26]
mechanical/case-prototype/exports/parts/right-lid-seat-3.step
3.00 x 3.00 x 3.90 mm

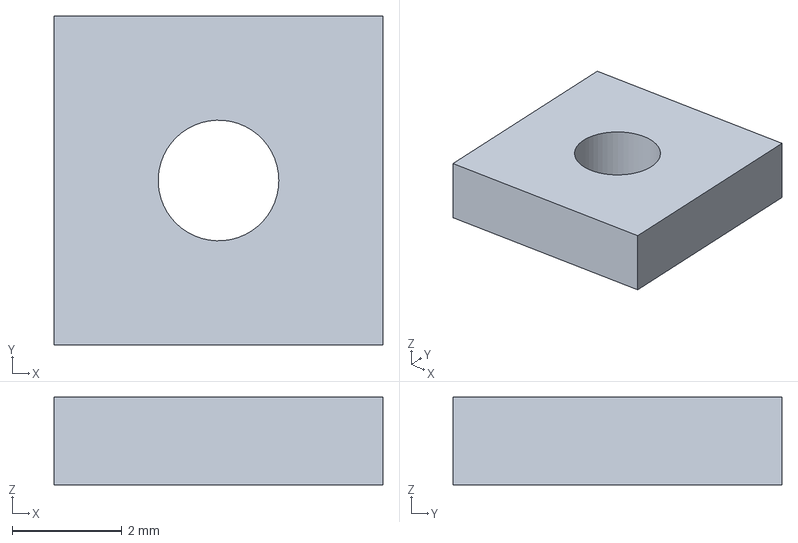
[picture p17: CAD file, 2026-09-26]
mechanical/case-prototype/exports/parts/keyboard-clip-8.step
6.00 x 6.00 x 1.60 mm

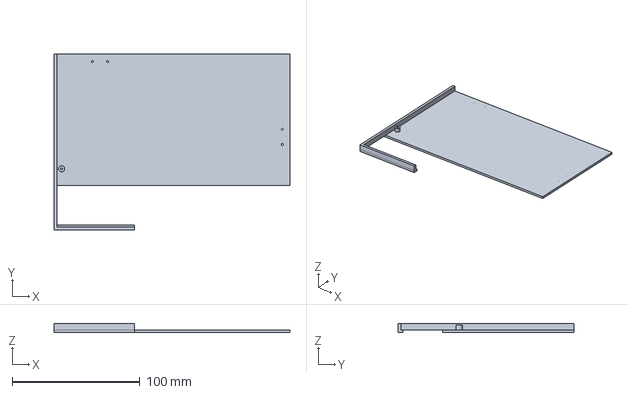
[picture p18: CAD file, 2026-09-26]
mechanical/case-prototype/exports/parts/lid-shell-11.step
185.0 x 138.0 x 7.00 mm

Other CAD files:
mechanical/case-prototype/exports/hinge-tests/right-base-steel-adapter.step
mechanical/case-prototype/exports/parts/lid-print-splice-4.step
mechanical/case-prototype/exports/hinge-tests/left-lid-seat-gauge.step
mechanical/case-prototype/exports/hinge-tests/left-base-seat-gauge.stl
mechanical/case-prototype/exports/hinge-tests/left-base-block.stl
mechanical/case-prototype/exports/hinge-tests/left-lid-seat-gauge.stl
mechanical/case-prototype/exports/hinge-tests/right-base-block.stl
mechanical/case-prototype/exports/hinge-tests/right-base-seat-gauge.stl
mechanical/case-prototype/exports/hinge-tests/right-lid-seat-gauge.stl
mechanical/case-prototype/exports/parts/base-11.step
mechanical/case-prototype/exports/parts/base-11.stl
mechanical/case-prototype/exports/parts/base-12.step
mechanical/case-prototype/exports/parts/base-12.stl
mechanical/case-prototype/exports/parts/base-21.step
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

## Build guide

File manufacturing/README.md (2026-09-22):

# manufacturing

the current boards are still in layout and review. [project status](../README.md#build-status)
lists the issues that remain before an order package can be prepared.

## separate board packages

| Board | Source PCB | Current stackup basis |
| --- | --- | --- |
| Center | `ducktop2-center.kicad_pcb` | Eight-layer NextPCB record |
| Left I/O | `left_io/left_io.kicad_pcb` | Eight-layer layout; confirm the actual order against the approved stackup |
| Right I/O | `right_io/right_io.kicad_pcb` | Eight-layer layout; confirm the actual order against the approved stackup |
| BMS | `bms/bms.kicad_pcb` | Four layers; [checked PCBWay package](bms/pcbway/README.md). Quote and factory review pending. |
| Radio | `radio_daughterboard/radio_daughterboard.kicad_pcb` | Four-layer placement board; fabrication details still to finalize |
| Keyboard | `keyboard/12_keyboard_daughterboard.kicad_pcb` | Existing separate two-layer rev A package |

the old monolith and the older quote package are reference material. do not
use them as a substitute for packages from the current split-board files.

## first-article package

for each board, retain:

1. The reviewed schematic, PCB, project rules, libraries, and source revision,
   including any working-tree changes used to generate the package.
2. Fresh schematic-to-board comparison, DRC with reviewed exceptions, and
   a check of refilled zones and final output geometry.
3. Confirmed layer count, stackup, copper weights, finish, thickness,
   impedance requirements, drills, and outline tolerances.
4. Gerbers, drills, IPC-D-356 netlist, BOM, CPL, assembly drawings, and DNP/
   hand-assembly notes that all come from that same revision.
5. Connector/cable compatibility, component sourcing/substitutions, mechanical
   support, test access, and programming/recovery provisions.
6. Fabricator/assembler DFM feedback and the current quote/order selections.
7. A reviewed first-power plan with the fixtures needed to test the prototype.

inspect the generated layers and drill files. check pad orientation and
placement rotations against the assembler's interpretation. regenerate the
IPC-D-356 file after routing/placement changes; the earlier exports are not
the final bare-board test set.

hardware validation follows on the first articles. a later production release
needs the recorded HIL, thermal, interface, display, and other system tests.
those results cannot be claimed from schematic checks or required as already
measured before the first prototype exists.

## stackup and rule records

[`mainboard_stackup_release.json`](mainboard_stackup_release.json) holds
the approved eight-layer geometry, including the 24/25 August NextPCB
field-solver results. use `approved_trace_geometries`, not the older
candidate values. confirm the stackup applies to the exact board and order.

the release checker still has board-selection/path defects recorded in the
project status. fix those before relying on its fabrication stage to cover
every board. an explicit one-board check does not cover the whole laptop.

## keyboard package

[`keyboard/README.md`](keyboard/README.md) describes the current keyboard
package. it replaces the old rev A files and printed-stencil assumptions.
the saved board has zero DRC violations, zero airwires and zero schematic
parity issues. its Gerbers, drills, paste and placement exports were checked
against that same saved board. physical switch assembly still needs the
process checks listed with the package.

## cost and retained evidence

quotes and sourcing assumptions belong in [parts and cost](../docs/bom-and-cost.md).
store final packages and their manifests in this project, with board-specific
names. keep a separate record for each first article and its test results.

## rule exceptions

| Area | What to check |
| --- | --- |
| Fine-pitch package pads | The exact footprint and manufacturer drawing; keep the exception local to the intended part/pad pair. |
| Mu standoffs | Locating hole, solder land, mask opening, module support, and actual assembly clearance. |
| Microphone | Acoustic opening, ground ring, copper/hole spacing, and the finished acoustic channel. |
| Connector/chassis edges | Intended exposed geometry versus an accidental copper-edge violation. |
| Track, PTH, NPTH, and via spacing | Active constraints for the actual item pair and the chosen fabrication process. |
| Courtyards | Physical part bodies, component height, assembly/rework access, and the correct board. |
| Shunts and power parts | Actual pads/current paths and sensing layout, not an old explanatory label. |

an exception in the rule file explains why a finding may be suppressed. it
does not prove a vendor approved it or that the physical assembly fits.
retain the drawing, measured geometry, and fabricator/assembler disposition
for each exception used in the final package.

## layout review

use `mainboard_stackup_release.json` for the approved outer/inner geometry.
PCIe data targets 85 ohm differential, USB3 90 ohm, and HDMI/Ethernet MDI
100 ohm. reference-clock and USB2 geometry must match their endpoint and
layer requirements. netclass names alone do not establish the completed
channel's impedance, return continuity, skew, or loss.

review the complete power paths, shunts, vias, connector contacts, local
converter loops, effective capacitance, and thermal copper. check the routed
channel across both boards and the cable where an interface crosses an FFC.

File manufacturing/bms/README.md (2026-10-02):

# bms

2 october: i'm revising the battery path for stronger unplugged performance.
the schematic generator now includes the proposed 8 A circuit, but the saved
BMS schematic, PCB and files below still belong to the previous 3 A design.
i haven't finished the new startup and fault-recovery circuit or its routing.
don't build or order the new revision from these files.

29 september: RS10 now uses the verified WSL2512R0110FEA18 ordering code,
11 milliohms, 1%, 2 W. the assembly BOM and package have been rebuilt and
checked. the resistor value, pads and all routing are unchanged.

the files below now match the saved BMS, including the new connectors,
5 A Schurter fuse and two vias moved clear of the WAGO solder openings.
the copper, holes, mask, paste, netlist, BOM and placements have been checked.
the current results are in the [layout checks](../../verification/bms-layout.md).
see [power revision status](../../docs/hardware/power-revision.md) for the
remaining system and harness work.

- [checked pcbway package](bms_PCBWAY.zip)
- [gerbers and drills](pcbway/bms_GERBERS.zip)
- [assembly BOM](pcbway/BOM.csv) and [SMT placements](pcbway/CPL.csv)
- [order settings and assembly notes](pcbway/README.md)

- [front assembly view](front-assembly.svg)
- [back assembly view](back-assembly.svg), viewed from underneath
- [test-point map](test-points.csv), using the pcb file's coordinates in mm
- [front artwork](front.png) and [back artwork](back.png)

the small numbers beside the test pads match TPB1, TPB2 and so on. point 14
is stacked. use the assembly views for the component references that do not
fit clearly on the silkscreen.

the previews show the exported board artwork without component bodies.
the back is viewed from underneath. use the assembly drawings for placement
and the [harness notes](../../docs/hardware/power-harness-fit.md) for plug
dimensions and access.

the package includes the four copper layers, masks, printing, outline,
separate drill files, electrical test netlist, both paste layers, BOM and
placement files. there are 125 fitted parts: 124 SMT and one through-hole
connector. F1 is a soldered 5 A fuse; the old loose 10 A insert is gone.
the mask check includes a 0.05 mm registration allowance around SMT openings.

compare one and two assembled boards from the same bare-board batch.
pcbway still needs to confirm the sourced parts, finished copper, hole
plating and any assembly-panel details in its quote. no order has been placed.

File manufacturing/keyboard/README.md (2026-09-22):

# keyboard order files

the current keyboard is the RGB revision and still needs routing.
the previous passive-keyboard fabrication and assembly files are retired;
they are available in git history.

use the current [keyboard project](../../keyboard/README.md) for the
schematic, placement and routing notes. a new order package needs the
finished routing, native DRC, copper-exclusion checks and an assembly
review covering the LEDs and switches.

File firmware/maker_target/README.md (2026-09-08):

# maker target

the RP2350 target builds with Pico SDK 2.2.0 and the exact TinyUSB submodule
in `dependencies.json`. the custom board header uses the 12 MHz crystal and
4 MiB flash in the schematic. no Pico board LED or VSYS pin defaults are
borrowed onto the maker fault and user-power pins.

exposed signals map to GPIO0..22 and GPIO26..28. GPIO29 enables the user
rails, GPIO24 senses the host USB gate and GPIO25 reads the user-power fault.
all user signals start as inputs without pulls. GPIO and ADC input modes are supported. bounded UART, SPI and I2C
transactions borrow their fixed pins only while those pins are passive.
transaction details and the host tool are in [software/maker](../../software/maker/README.md).

HID feature packets are 64 bytes: `MK2` plus version byte 1, increasing u32
sequence at offset 4, rail request at 8, authorization at 9, then 26 mode
bytes. remaining bytes must be zero. modes are 0 high impedance, 1 input,
2 ADC input, 3 low output and 4 high output. ADC mode is accepted only on
the three ADC pins. requests expire after 1 s unless a new sequence arrives.
USB loss, host-gate loss, watchdog or a power fault removes user rails and
makes the user signals passive. normal application watchdog period is 500 ms.

input reports carry the last sequence, fault at 8, rail readback at 9,
authorization state at 10, digital levels at 11..36, and three u16 ADC samples
at 40..45. byte 47 reports the startup guard and physical fault input, and
bytes 48..51 carry the last bus sequence. output modes only change when requested, avoiding repeated output
direction transitions in the steady-state loop.

U922 controls the header bus switches autonomously. there is no MCU-readable
OE feedback. a 250 ms startup guard does not prove the switch state. safe
firmware makes its pins passive; it cannot open that hardware switch on a
runtime command. external signals can still reach passive MCU pads once the
supervisor enables the switch. use the header's electrical limits.

## reproducible build

clone the SDK and checkout the commits in `dependencies.json`, then initialize
its `lib/tinyusb` submodule. use the complete Arm GNU 13.3.Rel1 toolchain,
which includes newlib. Homebrew's compiler-only package is not sufficient
for the Pico SDK target.

```sh
python3 firmware/tools/build_maker.py \
  --sdk /absolute/path/to/pico-sdk \
  --toolchain /absolute/path/to/arm-gnu-toolchain \
  --output .workbench/maker-build
```

the wrapper rejects different or modified SDK commits, builds ELF/BIN files,
creates a UF2 with the official RP2350 ARM secure family ID and compares its
payload with the binary. `build-manifest.json` records the artifact hashes.
no board is programmed by this command.

BOOTSEL plus RUN provides the ROM recovery path; SWD can program and read
back the ELF. the SDK clock bootstrap precedes `main`, so physical BOOTSEL/
SWD recovery must also be tested when startup does not reach the application
watchdog. GPIO modes, ADC readings, overcurrent behavior, watchdog timing,
USB loss and the actual flash boot all remain HIL tests.

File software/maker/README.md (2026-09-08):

# maker bus commands

`maker_tool.py` performs one bounded transaction and then returns the user
rails and GPIO to their passive state. it requires `--authorize`, waits for
the startup guard, and never retries a timed-out transaction. `--rails`
explicitly enables the user power rails while the transaction runs. this
software has not been run against a physical maker controller.

```sh
python3 software/maker/maker_tool.py --hidraw /dev/hidrawN --authorize uart --tx 4142 --read 2 --rate 115200
python3 software/maker/maker_tool.py --hidraw /dev/hidrawN --authorize --rails i2c --address 0x55 --tx 10 --read 2
python3 software/maker/maker_tool.py --hidraw /dev/hidrawN --authorize spi --tx 9f000000 --read 4 --mode 0
```

select the maker HID device, product 0x2329 under VID 0x1209. the EC uses a
different product ID. each transaction permits up to 32 transmit and 32
receive bytes, with a 1..100 ms timeout. it requires a current authorization
lease with enough time left to finish. unrelated GPIO settings are retained
by the protocol; this one-shot tool deliberately starts and ends all-off.

| bus | fixed MCU pins | supported settings |
| --- | --- | --- |
| UART0 | GP0 TX, GP1 RX | 8N1, 300..115200 baud, optional write then exact-length read |
| I2C1 | GP2 SDA, GP3 SCL | 7-bit addresses 0x08..0x77, 10..100 kHz, combined write/read with repeated START |
| SPI0 | GP16 MISO, GP17 CS, GP18 SCK, GP19 MOSI | 8-bit MSB-first, modes 0..3, 10 kHz..1 MHz, active-low CS |

SPI full-duplex lengths must match. a read-only SPI transfer clocks 0xff bytes;
a write-only transfer drains and discards received data. I2C needs external
pull-ups and SPI CS needs an external inactive-state pull-up. the target
removes its pin drive after each transaction. bus rates are software bounds,
not evidence of cable signal integrity or external-device compatibility.

pins must be in `MAKER_IO_HIGH_IMPEDANCE` before a transaction can borrow them.
GPIO input/output/ADC assignments on any required bus pin cause a conflict.
requests are rechecked after pending GPIO configuration has been applied.

## packets

all packets are 64-byte unnumbered HID feature/input reports, with
little-endian integers. Linux feature ioctls prepend a zero report-ID byte.
normal GPIO authorization uses the existing `MK2` version 1 packet.

bus requests start with `MB2` and version byte 1. sequence u32 is at 4, bus
kind at 8 (UART 1, I2C 2, SPI 3), flags at 9 (SPI mode; otherwise zero),
TX/RX lengths at 10/11, baud or clock u32 at 12, timeout u16 at 16 and I2C
address at 18. bytes 19..31 are zero; TX bytes start at 32, with zero padding.
sequences advance independently of GPIO-control sequences. accepted or
rejected requests with a fresh sequence consume it; they cannot be replayed
after a fault-clear.

responses start with `MR2` and version 1. they echo the sequence at 4 and bus
kind at 9. status is at 8, received length at 10, actual configured rate u32
at 12, elapsed milliseconds u16 at 16, and returned data at 32. status values
0..7 mean success, invalid request, lease unavailable, pin conflict, timeout,
I/O error, replay and busy. partial UART bytes may be returned with an error;
that does not mean the requested transaction completed.

UART/SPI polling loops check an absolute deadline and live authorization.
I2C write and read share one absolute deadline. the power-fault interrupt
immediately makes the user pins and rails passive; cleanup resets the bus
peripherals. failures clear authorization and latch a transaction fault.
a fresh all-off control request can clear a removed fault, followed by a
new authorization. a transaction is never silently retried.

host tests exercise the parser and actual target driver loops with simulated
peripherals. physical bus timing, overcurrent interruption, USB behavior and
external-device transactions remain HIL tests.

```sh
python3 -B software/maker/test_maker_tool.py
sh firmware/tools/run_host_tests.sh
```

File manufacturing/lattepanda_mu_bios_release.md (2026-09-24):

# compute module and BIOS

updated 24 september 2026. **interface migration in progress; power and hardware qualification pending.**

i'm starting with a Mu Ultra 226V. the carrier, power path and cooling
must also support the 256V from the start, so a later upgrade only needs
the module swap and any documented BIOS or software setup.

## selected parts

| item | target |
| --- | --- |
| initial module | DFRobot DFR1294, Mu Ultra Core Ultra 5 226V, 16 GB RAM |
| upgrade module | DFRobot DFR1295, Mu Ultra Core Ultra 7 256V, 16 GB RAM |
| initial development kit | DFR1294-1, includes the 226V module, Mini Carrier and active cooler |
| reference cooler | FIT1049, the Mu Ultra cooler family |
| carrier socket | TE Connectivity 2309411-1, with separate mechanical retention |
| boot storage | NVMe on the custom carrier; neither module has onboard eMMC |
| recovery | prepared external USB media |
| BIOS | official DFLT `SBCLNLCXR120-A.bin`, build 2026-04-30; downloaded binary hash and hardware qualification still pending |

the two Ultra models share the documented module interface and mechanical
format. the old N305 carrier needs the interface and power changes below.
the N305-specific BIOS identity previously recorded here is obsolete for
this target. do not flash an N305 image onto either Ultra model.

## what the common carrier has to support

- one assembled PCB and one cooling assembly for both variants. no solder
  rework, connector change or cooler replacement when upgrading to 256V.
- the 256V's sustained and transient load, including conversion losses,
  display, NVMe, wireless and permitted USB loads. check the 226V too rather
  than assuming one processor's test results qualify the other.
- the official 50 W or greater Ultra supply recommendation as an input to
  the system budget, not a promise that a 50 W adapter powers the complete
  laptop and charges its battery simultaneously. the selected target is
  20 V / 5 A USB-C input. the current charger and roughly 40 W Mu/display
  rail still need circuit changes before that can be enabled.
- a checked common USB, PCIe, HDMI and eDP allocation. move the existing
  USB2 connections off pins 67/69/70/72, check pin 136's reserved state,
  and review every used pin against the Ultra comparison table.
- real NVMe CLKREQ wiring and correct peripheral power behaviour for
  Modern Standby. the old fixed-low clock request and S3 assumptions need
  changing. qualify firmware limits and sleep behaviour for both SKUs.
- a documented PCIe link-speed policy. existing Gen3 routing is not a
  Gen4 qualification; validate the complete routed channels and cables.

## before calling the upgrade supported

1. finish the Ultra schematic and PCB migration, then rerun ERC, DRC,
   schematic parity and the power-path checks on the final files.
2. record the module model, BIOS image/hash, BIOS settings, power limits,
   cooler and source used for each tested configuration.
3. verify cold boot, NVMe, wireless, Ethernet, all USB ports, HDMI and the
   exact internal panel mode with both the 226V and 256V.
4. measure startup, sustained load and short peaks, then verify charging,
   source changes, battery operation and faults within the approved budget.
5. measure temperatures and repeat sleep/wake tests. check the mechanical
   fit after a powered-off module replacement.

## interface changes

the saved interface uses the full [Ultra pin table](../reference/lattepanda/mu-ultra-pinout.json).
the six native USB2 ports are allocated as follows:

| port | A1 contacts | connection |
| --- | --- | --- |
| P1 | 109 D-, 111 D+ | U400 USB2513BT-I/M2 internal hub |
| P2 | 112 D+, 114 D- | left USB7206C upstream |
| P3 | 73 D-, 75 D+ | existing USBC1 path |
| P4 | 79 D-, 81 D+ | EC host USB |
| P5 | 76 D+, 78 D- | maker MCU |
| P6 | 82 D+, 84 D- | Bluetooth |

U400 port 1 is the system codec, port 2 is the trackpad and port 3 is the
optional radio. the first two ports are strapped as non-removable. the
trackpad keeps its protected VBUS switch, with hub permission and isolated
fault feedback. the hub's reset supervisor stays in place.

HDMI now leaves TCP2. NVMe uses REFCLK2 and CLKREQ2 at pin 108; R50's
permanent pull-down is removed. pins 67/69/70/72 and reserved pin 136 are
open. the external coupling capacitors on the used PCIe lanes remain.

the physical USB companion-port mapping still needs a kit test with USB2
and USB3 devices. the default BIOS groups Ethernet's lane 1 with unused
lane 2, so x1 link training also needs checking. pin 7 is SLP_S4 despite
the legacy `SLS_S3` net name. both status outputs can stay high in Modern
Standby; the current host watchdog must be adapted before enabling suspend.

the existing power circuits are still present. the 100 W charger, source
transitions and full module load are not qualified by these interface changes.
existing firmware qualification gates stay disabled until their evidence
is recorded. 226V tests alone do not establish a tested 256V upgrade.

## sources

- [Ultra specifications](https://docs.lattepanda.com/content/mu_ultra_edition/specification/)
- [Mu to Ultra migration guide](https://docs.lattepanda.com/content/mu_ultra_edition/migration_guide_mu_to_mu_ultra/)
- [226V development kit and shipping list](https://www.dfrobot.com/product-3149.html)
- [256V module](https://www.dfrobot.com/product-3148.html)
- [Ultra cooler](https://www.dfrobot.com/product-3156.html)
- [official Ultra BIOS files](https://github.com/LattePandaTeam/LattePanda-Mu-Ultra/tree/main/Softwares/BIOS)
- [internal hub datasheet](https://ww1.microchip.com/downloads/aemDocuments/documents/UNG/ProductDocuments/DataSheets/USB251xB-xBi-Data-Sheet-DS00001692.pdf)
- [internal hub errata](https://ww1.microchip.com/downloads/en/DeviceDoc/USB251xB-xBi-Errata-DS80000627D.pdf)

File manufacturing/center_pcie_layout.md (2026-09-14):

# center PCIe layout

keep the data and clock pairs together. the center board uses the widths and
gaps from [the stackup](mainboard_stackup_release.json): 0.183 / 0.1524 mm on
F.Cu and B.Cu, and 0.114 / 0.1524 mm on In2.Cu. In1.Cu, In3.Cu and In6.Cu are
ground references. signal tracks stay off those ground layers.

TX capacitors sit near the M.2 sockets. the complete path check follows both
sides of each capacitor, and both sides of the clock resistors. data P/N
mismatch must stay below 0.127 mm; clock mismatch must stay below 0.381 mm.
each capacitor-to-socket path also stays below 8 mm, including a conservative
full-board thickness for its through via. these limits follow the
[Mu PCIe guide](https://docs.lattepanda.com/content/mu_edition/design_guide_pcie/).

## local gaps

pads, vias and length tuning briefly spread the pairs apart. their named
windows and limits are in [center_pcie_layout_limits.json](center_pcie_layout_limits.json).
each window has a fixed layer, exact pair name, maximum gap, total copper
length and uncoupled length for P and N. moving the route outside a window
makes the nominal gap apply again.

the two NVMe clock tuning windows contain about 2.77 mm of uncoupled copper
on the longer leg. the other NVMe via and socket windows are about 2.18 mm or
less per leg. the checker records every window separately so those lengths
stay visible when the layout changes. ordinary paired corners are checked
against their actual bend angle and two matching offset legs.

the Wi-Fi receive and source-clock turns use concentric arcs. its capacitor
outputs join a coupled section before the final via fanout. the complete
capacitor-to-socket paths, including nominal via depth, are 6.27 mm and
7.84 mm. the NVMe paths are 4.13 to 4.71 mm. all 12 data and clock signals
pass their complete P/N path limits.

the same check covers the existing GbE and TCP0 escapes at A1 and FPC103.
the fixed limits contain 57 NVMe windows, 30 Wi-Fi windows, 9 GbE windows
and 12 TCP0 windows. the FPC103 pads and vias account for much of each
short escape; the exposed uncoupled copper is at most 1.362 mm on GbE
and 0.895 mm on TCP0. the full copper length stays checked too.

the usb check covers eight DP/DN pairs, including ten FPC pair escapes.
their 42 gap reports are fixed, with 28 small windows around the pads and
vias. copper outside those windows must keep the normal USB gap. these are
local escapes; the full USB trunks and their final length matching are still
unfinished. include the existing fragment lengths when finishing each pair.

KiCad applies an area condition to a whole track object. a long track can
cross a small tuning window, so the native local rules also need the geometry
check. it clips each track or arc to the actual window and checks all the
remaining copper. a 2 mm local window cannot permit an 8 mm gap error further
along the same track. the regression tests include that exact case.

arcs use KiCad's native center, radius and sweep. clipping and uncoupled
lengths are calculated from line and circle intersections. the maximum-gap
samples are at most 0.005 mm apart, giving a conservative 0.0025 mm error
bound. KiCad can round arc centers to 100 nm; each arc's measured center
rounding is recorded and limited to 0.15 micrometre of gap uncertainty.
straight-to-straight checks keep their 2 nm coordinate tolerance.

these local rules keep the normal minimum gap, width, clearance, drill and
layer checks. the full release gate still requires native DRC, correct pad
endpoints, complete signal paths, matching P/N lengths and no duplicate
copper or free branch stubs. geometry gives a repeatable layout check;
signal quality still needs to be checked on the assembled board.

## running the check

install `gen/requirements-release.txt` into the Python environment used for
release checks. KiCad's Python is found separately, or can be selected with
`KICAD_PYTHON`.

```sh
python gen/check_center_pcie_coupling.py \
  --pcb ducktop2-center.kicad_pcb \
  --limits manufacturing/center_pcie_layout_limits.json \
  --output /tmp/center-pcie-layout-check.json
```

the routing and fabrication release commands run this check automatically.
it reads the PCB passed on the command line and leaves that file untouched.
a missing dependency, failed export or failed geometry check blocks the gate.

KiCad's [custom-rule documentation](https://docs.kicad.org/10.0/en/pcbnew/pcbnew.html#custom-design-rules)
explains area matching and differential-pair gap checks. its
[arc-center implementation](https://gitlab.com/kicad/code/kicad/-/raw/10.0/libs/kimath/src/trigo.cpp)
documents the coordinate rounding used here. the short fanout approach also
follows [TI's high-speed layout guidance](https://www.ti.com/lit/an/spraar7j/spraar7j.pdf).

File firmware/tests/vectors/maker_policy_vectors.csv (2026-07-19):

id | stimulus | interlock_ready | power_authorized | io_authorized | power_fault_n | watchdog_healthy | expected_rails | expected_io_default | expected_fault
MK-BOOT-001 | cold_boot | false | false | false | true | true | off | high_z | NONE
MK-PWR-001 | request_without_authorization | true | false | false | true | true | off | high_z | USER_POWER
MK-PWR-002 | request_with_authorization | true | true | false | true | true | on | high_z | NONE
MK-IO-001 | request_io_without_authorization | true | false | false | true | true | off | high_z | IO_AUTHORIZATION
MK-IO-002 | request_io_with_authorization | true | false | true | true | true | off | requested | NONE
MK-INT-001 | interlock_lost_while_active | false | true | true | true | true | off | high_z | INTERLOCK
MK-AUTH-001 | io_authorization_lost_while_active | true | true | false | true | true | off | high_z | IO_AUTHORIZATION
MK-FAULT-001 | power_fault | true | true | true | false | true | off | high_z | USER_POWER
MK-WDG-001 | watchdog_trip | true | true | true | true | false | off | high_z | WATCHDOG
MK-RST-001 | reset_after_outputs_active | true | true | true | true | true | off | high_z | NONE

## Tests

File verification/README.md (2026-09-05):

# verification

`generated/` contains regeneratable netlists, DRC/ERC output, pin reviews,
inventories, and working IPC-D-356 exports. it is ignored by git.
generators and checkers create the directory when needed.

`hardware_validation_release.json` remains tracked. firmware release/HIL
records are under `firmware/release/`, and manufacturing packages retain
their own released test files and manifests.

use fresh schematic exports for comparisons. retain source revision,
command, tool version, and date with evidence. ordinary DRC, expanded
track checks, parity, and schematic contracts cover different things.

[build and verification](../docs/build-and-verify.md)

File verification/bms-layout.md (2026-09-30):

# bms layout checks

29 september 2026. the new connector and fuse revision is routed and saved in
[`bms/bms.kicad_pcb`](../bms/bms.kicad_pcb). it is still four layers and
1.6 mm thick, with 149 footprints and the four perimeter mounting holes.

| check | result |
| --- | --- |
| native connectivity | 0 unconnected items |
| physical DRC | 0 errors |
| schematic-to-board comparison | 0 mismatches |
| schematic ERC | 0 errors, 92 existing warnings |
| dangling tracks and vias | 0 warnings |
| silkscreen and copper slivers | 0 warnings |
| routing | 2,187 track segments, 398 vias |
| library pad and drill comparison | 0 differences |
| quiet return | 48 analogue pads, one join to the six bulk-return pads |
| positive shunt pickup | meets the load path at the shunt pad |
| main current paths | all nine checked through the filled copper and plated connections |
| solder-mask openings | no exposed via holes, including the 0.05 mm registration screen |

the cleanup merged straight fragments, removed unused tails and vias, and
shortened unnecessary bends. there are 625 fewer track segments than the
completed routing checkpoint before cleanup. the old connector-shaped
battery-positive pour was removed and its test point now connects directly
to the new connector. nine clipped labels were moved. component positions,
component pads and holes, 3D models, board outline and mounting holes were preserved.
the clearances and rule severities were not relaxed.

the assembly check found two via holes inside the new WAGO solder openings.
both vias now sit outside those openings. three short connections preserve
their layer joins. the via diameters and drill sizes are unchanged, and the
exported masks also pass with a 0.05 mm outward registration allowance.
all nine copper-path estimates were repeated; the largest resistance change
was 0.057 milliohms. the quiet return still passes the same separation check.

C2230 and the reset supervisor now return through the bulk branch. the
analogue return still uses the original single join. removing that join
in the geometry check separates exactly the intended two groups. the
positive current-sense lead has local pour clearances so load current does
not enter it before the shunt. the modelled pickup offset fell from about
5.09 mV to zero at the 5.6 A screening point.

the power check uses a 0.1 mm sheet mesh, nominal 35 um copper and assumed
20 um hole plating. it estimates copper resistance at 20 C and 80 C.
it excludes connector and component resistance and does not predict
temperature rise. 5.6 A is a fault-corner check, not a continuous rating.
the firmware's qualified pack-current ceiling remains 3 A and the hardware
qualification flags remain off.

## remaining warnings

the normal board check retains 73 differences from library graphics and
text. pad and drill geometry matches the libraries. the fabrication pass
also restores 19 off-centre track/via warnings and two generic-symbol
footprint-name filter warnings. the off-centre endpoints are within their
via lands, and the exact footprint and netlist checks pass. all of these
warnings remain in the package reports. ERC
retains 89 cached-symbol differences and three ground-name warnings for
the separate return domains.

source hashes, counts, preservation checks and copper estimates are in
[`bms-layout.json`](bms-layout.json). these replace the old revision's
layout results; the earlier 8 A screen is not evidence for this revision.

## before ordering

the [PCBWay files](../manufacturing/bms/README.md), assembly views and
test-point map now match this saved board, including the new WAGO output,
right-angle raw-pack connector and 5 A Schurter fuse. the package has its
own source hashes and file checksums. any later source edit needs a fresh
export and verification.

the actual cells, harnesses, protection trips, temperature response and
powered operation still need the [bring-up checks](../docs/BRINGUP_TEST_PLAN.md).
finished copper, hole plating and assembly details also need the fabricator's
confirmation. this layout check is not an order release.

RS10 now specifies WSL2512R0110FEA18, the 11 milliohm, 1%, 2 W part.
the old WSLP ordering code was outside that series' published range. only
the MPN field changed in the schematic and board. all pads, tracks, vias
and outlines are byte-for-byte unchanged. the existing lands retain at
least 0.508 x 2.926 mm of terminal overlap in the package-tolerance screen,
including a 0.125 mm assembly-position allowance. the factory still needs
to review the assembled joints and part sourcing.

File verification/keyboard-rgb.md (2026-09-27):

# keyboard RGB checks

checked 27 september 2026 with KiCad 10.0.4. the LED connections now follow
the physical rows. this is a routing checkpoint, not an order release.

| check | result |
| --- | --- |
| schematic ERC | 0 errors, 0 warnings |
| schematic / PCB parity | 0 differences; 1,096 physical pads checked |
| PCB physical DRC | 4 existing starved-thermal errors; no new errors |
| remaining ground errors | C320 pad 2, C321 pad 2, J320 pads 1 and 30 |
| routing | 1,208 tracks and arcs, 264 vias, 1 ground zone |
| unconnected count after refill | 298, confirmed by native connectivity and DRC |
| board | 4 copper layers, 0.8 mm, original 273.5 x 80 mm outline |
| placement | all 221 footprint positions and pad geometries preserved |
| local LED anode joins | all 65 preserved |
| other routing | switch-matrix, power and I2C copper unchanged |
| switch copper exclusions | all 65 preserved on all four layers |
| driver mapping | 195 unique colour channels; registers 196..198 remain off |
| firmware checks | RGB startup, mapping, updates, fault latch and timer wrap pass |
| row-map checks | four checks pass for row grouping, bank capacity, channel uniqueness and local anodes |

the starting point was the live editor, including unsaved routing. the map
change was applied as one undoable KiCad edit, then refilled and saved.
50 old bank-link segments were removed and 101 were trimmed to retain local
LED and driver wiring. one retained section needed a separate track item.
no vias were removed, moved or added. no new routing was added beyond those
retained portions of the existing tracks.

the old banks linked six neighbouring keys along the rows. the new banks
follow nearby columns, so those old links could join different new nets.
the anode joins at each LED stay connected; the feeds between banks need
routing again. 55 keys use five row-aligned RGB sink groups. the ten extra
keys use the sixth group. the [wiring map](../keyboard/images/rgb-routing-map.png)
and [CSV](../keyboard/rgb-key-map.csv) show the assignments.

all LED positions, switch offsets, pad sizes, 3D models and ground-zone
settings were retained. the filled ground copper was recalculated. the
four ground thermal errors were present before this change and still need
repair. remaining track-end warnings include the retained LED stubs.

the placement checker still verifies the CHERRY component area and copper
exclusions. nominal pad margin is 0.075 mm. the maximum LED body height plus
solder allowance is 0.50 mm against the 0.8 mm drawing limit. the selected
LED, driver, current resistor and power circuit are unchanged.

`gen/check_keyboard_rgb.py` compares the saved board with a fresh XML netlist
and the firmware table. `gen/test_keyboard_rgb_mapping.py` checks the row and
bank structure. `gen/draw_keyboard_rgb_map.py` redraws the wiring reference
from the saved PCB and requires its LED nets to match the source map.
the [machine-readable record](keyboard-rgb.json) contains source hashes and
the current preservation and DRC results.

after routing, rerun DRC and schematic parity, check the exported copper
against the CHERRY exclusions, and prepare the assembly package. physical
LED/switch fit, colour order, full-white current, temperature and I2C checks
still need an assembled board.

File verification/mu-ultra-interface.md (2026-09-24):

# Mu Ultra interface changes

checked 24 september 2026. this covers the interface migration. the
100 W power path, firmware, cooling and completed routing still need work.

## what changed

- A1 now uses the official 260-contact Ultra pin table. the TE socket and
  its position stay the same. pin 136 is separate from ground and left open.
- Bluetooth moves to USB2 P6, and the left hub moves to P2. the internal
  hub becomes USB2513BT-I/M2, with codec, trackpad and optional radio ports.
- U400 has the Microchip M2 land pattern: 0.28 x 0.90 mm signal lands,
  0.5 mm pitch and a 3.7 mm exposed ground pad with nine ground vias.
- the trackpad keeps U64's protected supply. U450 combines hub permission
  with host-active status; U451 isolates fault feedback from the always-on
  EC pull-up. both have powered-off input/output protection.
- HDMI uses TCP2. the cable contacts and right-board routes are unchanged.
- NVMe CLKREQ reaches A1 pin 108. the old R50 pull-down is removed.

## checks

| check | result |
| --- | --- |
| official A1 contact names | all 260 match |
| center schematic contracts | pass |
| right-board schematic contracts | pass |
| center and right PCB pad nets | match their fresh schematic netlists |
| net-class and connector tests | 13 pass |
| electrical ERC errors | 0; 375 library-copy warnings remain |
| retained component positions and IDs | unchanged |
| retained track/via geometry | unchanged |
| new routing | none |
| removed copper | 51 items at the changed A1 contacts and R50 |
| new shorts, clearance or courtyard violations | none compared with the checked baseline |

the center has 786 footprints and 5,193 tracks/vias after this pass. its
actual unrouted count is 1,571, up from 1,538 as the changed contacts and
new logic need connecting. the CLI report stops listing at 499; that is
not the full count.

the complete center DRC has 828 reported violations, compared with 822 in
the baseline. the added reports are seven dangling tracks and two dangling
vias after removing old connections; three previous reports disappear.
existing routing errors, including shorts and restricted-layer use, remain.
these results do not clear the board for fabrication.

the BMS, keyboard, firmware and software files are unchanged. the present
PD and charger limits stay in place until the 100 W circuit is designed
and qualified. [module requirements](../manufacturing/lattepanda_mu_bios_release.md)

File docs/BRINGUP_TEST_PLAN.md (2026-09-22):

# bring-up plan

updated 22 september 2026. this is the preparation and test order. the exact
power fixtures, limits, connections, and acceptance values still need a
review against the corrected boards before this becomes a bench procedure.

the BMS routing and fabrication-file checks are finished. its
[prototype package](../manufacturing/bms/pcbway/README.md) still needs the
factory quote and review. the center and I/O boards need their remaining routing. see the
[build status](../README.md#build-status).

## fixture requirements

- The BMS fixture must provide defined simulated voltages at all three cell
  inputs and taps. provide a separate MCU_3V3/control interface where needed.
- Keep raw pack negative, BMS protected return, and system ground distinct.
  measurement equipment must not bridge the protector or gauge shunt.
- Match input fixtures to the actual qualification windows and source paths.
  use the current electrical-calculation record and PD configurations for
  the exact test voltages. AUX enters at left J190.
- Define fault injection using controlled sources and loads. specify levels,
  timing, recovery, and probe references before applying power.

## records for every stage

record board revision and serial, assembly population, firmware version,
fixture diagram, instruments, source/load limits, probe references, expected
values, measurements, and a pass/fail result. retain evidence in the project.
do not advance through a failed or unexplained result.

## stage 0: bare boards and cables

inspect outlines, drills, mask, pad registration, and connector footprints.
obtain the fabricator's electrical test result against the released netlist.
regenerate IPC-D-356 from the final board files; the existing pre-routing
exports are historical and can have obsolete pad positions.

use unpowered continuity/isolation checks to investigate suspect nets and
interfaces. a few DMM spot checks are not equivalent to a full flying-probe
test. verify both the cable's conductor map and the expected board nets
with it seated in the intended orientation.

## stage 1: assembled, unpowered

inspect IC orientation, FET footprints/pin assignments, fuse clips, shunts,
connector seating, solder joints, and DNP population. measure resistance and
diode behavior in both polarities between the specified rails/references.
record the readings and investigate unexplained low resistance.

use the final BMS assembly drawing to locate the test points. the thermal
circuit adds TPB20 through TPB27; their identities must match the released
board and schematic before connecting the fixture.

the original BMS test-point identities are:

| Point | Net | Point | Net |
| --- | --- | --- | --- |
| TPB1 | PACK_POS_RAW | TPB9 | MCU_3V3 |
| TPB2 | BAT_PROT_VIN | TPB10 | BMS_AVDD |
| TPB3 | PACK_POS_FUSED | TPB11 | BMS_VDD |
| TPB4 | BAT_PROT_FET_COMMON | TPB12 | BMS_SRP |
| TPB5 | BAT_PROT_GATE | TPB13 | BMS_SRN |
| TPB6 | BAT_PROT_CGATE | TPB14 | BMS_PRES |
| TPB7 | PACK_FAULT_N | TPB15 | BMS_LD |
| TPB8 | PACK_RETRY_PULSE | TPB16 | FG_VSS |

the thermal points are TPB20 THERM_3V3, TPB21 THERM_READY, TPB22..24
THERM_SENSE_1..3, TPB25 BMS_CTRC, TPB26 BMS_CTRD, and TPB27
PACK_CHG_TEMP_OK. check these against the final export. the thermal side
is raw-pack referenced; the control interface uses CTRL_GND.

choose the correct reference for each measurement. TPB16 is the protected
return. define the required differential gate/shunt measurements and equivalent test
maps for the center and I/O boards before assembling them.

## stage 2: isolated low-energy power tests

prepare board-specific supply fixtures and reviewed current limits before
powering anything. keep the Mu, real cells, and optional loads disconnected
until the relevant tests permit them.

| Board | What the fixture must provide | What to establish |
| --- | --- | --- |
| BMS | Simulated series cells and taps; a separately defined MCU_3V3/control interface if needed | Internal supplies, primary/secondary FET behavior, fault/retry, balancing, thresholds, and recovery |
| Center | A defined qualified input or fixture injection point, with the missing sideboard paths accounted for | AON/reset behavior, converters, charger communication, sequencing, and default-off loads |
| Left | Its required supply rails and control inputs | Hub rails/reset, input protection, port switches, PD1, AUX, and interface behavior |
| Right | Its required rails and control inputs | PD2, port switches, Ethernet/HDMI support rails, and interfaces |
| Keyboard | EC or a dedicated matrix fixture | Every switch/diode, scan direction, debounce, and key mapping |
| Radio | Controlled power and interface fixture | Presence/fault behavior, local rails, GNSS/control/audio; RF tests are a separate setup |

write separate fault-injection tests for cell OV/UV, current faults, open
tap, invalid source, reset, and failed/stale telemetry. use the IC datasheets
and firmware HIL rows to set levels and timing. do not improvise a short
across a real pack to test a protector.

## stage 3: firmware and gradual integration

establish programming, readback, recovery, reset defaults, and watchdog
behavior. confirm actual applied limits before enabling charging or Mu power.
host test success does not prove those target transactions.

connect boards only with power removed. add one reviewed interface at a
time, checking rails, current, faults, and communication. follow the actual
power dependencies; do not power both ends independently unless the test
fixture specifically accounts for it.

use a controlled pack substitute during early integration. the real cells
come after protection, charging, balancing, and reference-ground behavior
have passed the relevant tests.

## stage 4: complete laptop tests

- All charging inputs and source transfers, at startup and under load.
- Battery current, gauge calibration, balancing, trip/recovery, and energy use.
- Mu boot, NVMe, Wi-Fi/Bluetooth, USB, HDMI, and Ethernet.
- Internal display on the final harness, brightness, lid behavior, and hinge cycling.
- Keyboard, trackpad, OLEDs, speakers/headphones, microphone, and maker GPIO.
- Cooling, component/skin/cell temperatures, and sustained load.
- Optional radio behavior, RF filters/antennas, emissions, and coexistence.
- Power-off leakage, reset/recovery, cable strain relief, and service access.

set ripple, overshoot, thermal, signal, and timing limits from the relevant
component and system requirements. a generic percentage or visible USB
activity on a scope does not validate every rail or a high-speed channel.

the result records feed [firmware HIL](../firmware/release/README.md) and
`verification/hardware_validation_release.json`. both stay incomplete until
the measurements exist.

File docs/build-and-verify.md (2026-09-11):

# build and verify

updated 8 september 2026. these are the entry points for checking the working
files. the latest results and known checker failures are in [current status](../README.md#build-status).

## before running anything

work from the project root and check `git status --short`. i keep manual
routing in the working tree, so do not reset, stash, regenerate, or sync a
board as part of an ordinary review.

KiCad 10.0.4 was used for the latest checks. on this Mac:

```sh
DUCKTOP_KCLI=/Applications/KiCad/KiCad.app/Contents/MacOS/kicad-cli
DUCKTOP_KPY=/Applications/KiCad/KiCad.app/Contents/Frameworks/Python.framework/Versions/3.9/bin/python3
mkdir -p verification/generated/local
```

use the KiCad Python for pcbnew work. regular `python3` is used by the
schematic generators and most text/netlist checks. some generator files use
newer Python syntax, so the bundled KiCad Python is not interchangeable with
system Python for every script.

## routing setup

`python3 gen/setup_net_classes.py --project all` checks the center and I/O
netclasses. use `--apply` to update the saved project files, then reload the
boards in KiCad. this does not add or reshape copper.

`gen/export_board_assembly.py`, run with KiCad's Python, exports the board
outlines and mounting datums. it checks the BMS cable map, M.2 retainer
alignment, and named chassis-hole keepout positions. the installed transforms
live in `mechanical/board-placement.json`.

## direct ERC, netlist, and DRC checks

the center schematic is `ducktop2.kicad_sch`. its routed-board filename is
`ducktop2-center.kicad_pcb`. the daughterboards each have a matching project
name in their own directory.

from the root, export the center schematic and check it:

```sh
"$DUCKTOP_KCLI" sch erc --format json \
  --output verification/generated/local/center-erc.json ducktop2.kicad_sch
"$DUCKTOP_KCLI" sch export netlist --format kicadxml \
  --output verification/generated/local/center-netlist.xml ducktop2.kicad_sch
"$DUCKTOP_KCLI" pcb drc --format json \
  --output verification/generated/local/center-drc.json ducktop2-center.kicad_pcb
```

run the daughterboard checks from their own directories so KiCad finds the
matching project settings and rule files:

```sh
for board in left_io right_io bms; do
  (
    cd "$board" || exit
    "$DUCKTOP_KCLI" sch erc --format json \
      --output "../verification/generated/local/$board-erc.json" "$board.kicad_sch"
    "$DUCKTOP_KCLI" sch export netlist --format kicadxml \
      --output "../verification/generated/local/$board-netlist.xml" "$board.kicad_sch"
    "$DUCKTOP_KCLI" pcb drc --format json \
      --output "../verification/generated/local/$board-drc.json" "$board.kicad_pcb"
  )
done
```

these commands write reports without saving a board. ordinary DRC uses the
stored zone fill. refill and compare zones in a copied candidate before a
release review. do not add `--save-board` to a read-only check.

`--all-track-errors` expands the DRC report. `--schematic-parity` adds
KiCad's schematic comparison, but on the center the schematic and PCB have
different basenames. use an isolated project with the correct association
or compare against an explicit fresh XML export. the ordinary report,
expanded report, and parity report are different checks; label their counts.

inspect the report's errors, warnings, unconnected items, and parity findings.
the CLI can exit successfully while reporting violations unless
`--exit-code-violations` is requested. zero unconnected items proves only
connectivity under the board's current pad-net assignments.

## schematic-to-board comparison

compare physical reference, pad number, and assigned net against the fresh
schematic export. include pads that share a number. classify DNP and no-connect
cases explicitly, and handle XML entity escaping in center sheet names.

the FPC contract comparison is a separate check. it verifies the cable
boundary, not every component on a board. the F1 mismatch found on 4 september
is why both checks are needed. also check that every schematic component has
the intended footprint, value, and procurement fields on the correct board.

## copied-project release checker

```sh
python3 gen/check_release_candidate.py --stage schematic
```

the checker runs generators and report writers in a temporary project copy
and checks that the working design/library files stay unchanged. its default
routing, fabrication, and production stages cover all six boards, including
the keyboard and radio. each board is checked with its own project settings
and rules. the routing stage allows unfinished routing only on boards whose
contract permits it; the keyboard and BMS still require complete routing.

the center is staged under the schematic basename so KiCad's native parity
check finds the right schematic. the checker also requires the comparison's
completion message: KiCad can return an empty parity list after failing to
load the schematic. copied-board refills do not modify the
working board. findings introduced by refill are compared by full signature,
including new findings in a category that already existed.

```sh
python3 gen/check_release_candidate.py --stage fabrication \
  --output-dir verification/generated/release-review
```

`--pcb` scopes the PCB checks to one board; the static schematic and firmware
checks still cover the project. use `--schematic` with an explicit PCB when
its schematic has a different name. `--output-dir` retains the per-board
DRC and parity reports. the old monolith's DRC waivers are no longer applied
to the current boards. production also requires the target firmware, display,
HIL, and hardware release records.

[layout review records](../verification/layout-reviews.json) cover specific
library, mounting-type and symbol-filter advisories. each record includes
the reason, exact placed object, and library hash. a changed pad, marking,
placement or library needs another review. no clearance, short, courtyard
or silkscreen collision can be accepted through these records.

retained unfinished main-board vias and track ends are listed separately in
the same file. they are allowed only at the routing-preparation stage, where
the main boards still have open nets. they continue to block fabrication.

for a fresh physical-pad comparison of the center:

```sh
python3 gen/report_schematic_pcb_eco.py --project center \
  --output-dir verification/generated/center-parity
python3 -m unittest discover -s gen -p 'test_*.py' -v
```

the comparison supports `center`, `left_io`, `right_io`, and `bms`. it checks
repeated physical pads, component values, footprint IDs, attributes, missing
parts, and split/merged net names. `--netlist` selects an explicit existing
XML file; otherwise it exports a fresh one. it exits with a failure status
when differences remain.

KiCad 10 caps clearance and unconnected-item reports at 499 entries; most
other categories are capped at 199. the checker flags lists reaching these
limits. a 499-item DRC list can hide thousands of native airwires. use native
connectivity for routing progress, and retain the DRC
list as diagnostic examples. `--all-track-errors` does not remove this cap.

current remaining findings are in the [center review](hardware/center-board.md).

`gen/export_board_assembly.py` refreshes the mechanical drawing, connector
datums and PCB-linked planner parts from the saved boards. it checks both
BMS harness maps and M.2 retainer offsets before writing those files. the
old floorplan-to-monolith importer was removed because its mappings no
longer describe these boards. the planner does not move PCB footprints.

the center sync was tested using an explicit KiCad S-expression netlist and
matching by reference. correct stale footprint library IDs before importing;
the trial otherwise added duplicate footprints. compare every retained pad
and placement afterward. KiCad's `{slash}` encoding within a sheet name is
different from the old literal XML `&amp;` corruption; the comparison handles
the former while continuing to reject the latter and split net groups.

## firmware checks

```sh
sh firmware/tools/run_host_tests.sh
```

the runner compiles host tests into its temporary directory, then checks the
release contract. it does not flash hardware. see [target status](../firmware/README.md#stm32-target)
for what the tests cover and what is still missing on the STM32/RP2350.

## report storage

keep retained project evidence in `verification/generated/`, with the source revision
or working-tree hashes, command, date, and result. `verification/generated/local/` is a
working-report directory inside the ignored generated-output folder.
keep generated reports there; release manifests and finished manufacturing
packages have their own tracked locations.

do not use an old XML file as evidence that the current schematic is correct.
it may have survived a stash, checkout, or generator change.

## deliberate rebuilds

for a schematic change, edit its generator. for an FPC signal change, edit
`gen/fpc_contract.py` and account for both ends of the cable. placement,
footprint, net-assignment, and track changes are separate operations.

make a candidate copy that includes the current uncommitted work, libraries,
and project settings. keep the canonical working tree intact while checking
the candidate. a checkout of HEAD alone would omit uncommitted changes.

## dependency order in the candidate

| Step | Script or action | What it can change |
| --- | --- | --- |
| 1 | The library generator for the changed component or connector | Shared symbol and footprint definitions; review every board using them |
| 2 | `gen/generate_signal_interconnect.py` | Current 41/51-contact signal connector definitions |
| 3 | `gen/generate_mu_carrier_sheet.py` | Root/center schematic and generated sheets |
| 4 | `gen/generate_left_io_project.py` | Left schematic project |
| 5 | `gen/generate_right_io_project.py` | Right schematic project |
| 6 | `gen/generate_bms_project.py` | BMS schematic project |
| 7 | `gen/verify_design_contracts.py --project NAME --schematic-only` for `ducktop2`, `left_io`, `right_io`, `bms` | Checks and refreshes the corresponding verification netlist |
| 8 | Compare the fresh netlist to the saved PCB, then apply the reviewed component changes | Part identities, source links and pad nets; preserve compatible placement and copper |
| 9 | Per-project ERC, pad-net comparison, native DRC, uncapped connectivity and release checks | Evidence for the candidate |

use system Python for the schematic generators. native PCB checks and edits
use the pcbnew-capable KiCad Python described above. the 30-contact keyboard
and radio definitions still use their existing generators; the current I/O
interfaces use `generate_signal_interconnect.py`.

`generate_split_boards.py` builds from the historical monolith. it is outside
the normal update path for these corrected boards. existing routed boards
must be updated incrementally against their current files.

the earlier workflow used `create_board_from_schematic` for step 8. that was
a board-creation operation, not a safe incremental update of a routed board.
the radio and keyboard also have their own generators and are not recreated
by the four-board split.

## before bringing a candidate back

compare the candidate to the starting working tree by object and purpose:

- generated schematic changes match the requested circuit change;
- all required footprint references exist once, on the intended board;
- pads agree with fresh netlists, including all repeated pad numbers;
- FPC maps, installed orientations, and ground/shield pads agree;
- net names and classes match the actual circuit nets;
- board layer tables and stackups agree;
- board outlines and placement stay within the intended mechanical model;
- unrelated routing is preserved;
- fills and DRC are checked using the actual project rules.

if a hygiene pass is supposed to converge, run it a second time in the
candidate and confirm zero additional moves. do not run a placement fixer on
the live routed BMS just to clear a historical courtyard count.

## the center board's special case

the root schematic is `ducktop2.kicad_sch`, but the center board is
`ducktop2-center.kicad_pcb`. the split pipeline resolves FPC names and
normalizes legacy sheet prefixes. a normal F8 update skips that process.

`resync_pad_nets`, `resolve_net_names`, and `normalize_board_nets` are the
relevant parts of the splitter. check their output, including XML-escaped
sheet names, instead of assuming a successful script exit proves parity.

`gen/recover_center.py` cuts another center board from the old monolith.
that is recovery of a starting point, not restoration of current manual work.

## known tool problems

pcbnew operations that remove and re-add parts have previously failed through
SWIG object corruption. use fresh subprocesses where the scripts require it.
initialize wx for headless reads when needed, and reject a `None` result
from `LoadBoard`.

read files before opening them for writing. never combine a truncating open
with a nested read of the same path. after any branch/stash operation,
regenerate the candidate netlists before building from them.

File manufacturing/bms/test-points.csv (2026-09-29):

reference | net | pcb_x_mm | pcb_y_mm | side | board_mark
TPB1 | /PACK_POS_RAW | 152.2 | 75.55 | top | 1
TPB2 | /BAT_PROT_VIN | 129.5 | 72.55 | top | 2
TPB3 | /PACK_POS_FUSED | 149.25 | 73.95 | top | 3
TPB4 | /BAT_PROT_FET_COMMON | 115.3 | 72.65 | top | 4
TPB5 | /BAT_PROT_GATE | 152.55 | 62.0 | bottom | 5
TPB6 | /BAT_PROT_CGATE | 130.55 | 77.8 | top | 6
TPB7 | /PACK_FAULT_N | 145.0 | 68.5 | bottom | 7
TPB8 | /PACK_RETRY_PULSE | 129.9 | 91.55 | top | 8
TPB9 | /MCU_3V3 | 148.0 | 93.4 | top | 9
TPB10 | /BMS_AVDD | 131.0 | 75.3 | top | 10
TPB11 | /BMS_VDD | 108.5 | 92.0 | top | 11
TPB12 | /BMS_SRP | 148.8 | 89.0 | top | 12
TPB13 | /BMS_SRN | 123.4 | 73.9 | top | 13
TPB14 | /BMS_PRES | 148.8 | 85.5 | top | 14 (stacked)
TPB15 | /BMS_LD | 133.05 | 77.8 | top | 15
TPB16 | FG_VSS | 152.0 | 62.0 | top | 16
TPB20 | /THERM_3V3 | 115.5 | 73.0 | bottom | 20
TPB21 | /THERM_READY | 116.5 | 92.5 | bottom | 21
TPB22 | /THERM_SENSE_1 | 162.0 | 61.5 | bottom | 22
TPB23 | /THERM_SENSE_2 | 110.55 | 61.35 | top | 23
TPB24 | /THERM_SENSE_3 | 127.2 | 62.0 | top | 24
TPB25 | /BMS_CTRC | 127.25 | 80.75 | bottom | 25
TPB26 | /BMS_CTRD | 117.75 | 92.75 | top | 26
TPB27 | /PACK_CHG_TEMP_OK | 148.75 | 89.75 | bottom | 27

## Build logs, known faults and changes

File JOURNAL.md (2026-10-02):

---
title: "Ducktop2"
author: "duck"
description: "An open-source 16-inch laptop designed from scratch."
created_at: "2026-08-26"
---

# 2026-10-2: start reworking the bms for more battery power

**Total time spent: 4 hours**

started redesigning the bms around an 8a battery path because the previous 3a limit would restrict the mu ultra too much when unplugged. added lower-resistance current shunts, drew their footprints, and added separate charge and discharge overcurrent detection to the schematic source. also separated the main battery wires from the cell taps and checked the connector ratings and wire clearances.
found a missing bias resistor in the battery protection circuit that could cause it to shut down after startup, and corrected that in the schematic source. the startup checks also uncovered problems with recovering after a low battery shutdown, so i've been comparing ways to handle that without accidentally bypassing the protection.
rearranged the draft board to give the power paths more space, moved smaller parts underneath, and removed obsolete routing from the working copy. updated the firmware to distinguish the old and new hardware and reject invalid current readings. the targeted tests and both firmware builds passed. there's still work left on startup, fault recovery and routing before this version can be ordered.

# 2026-10-1: fix the center routing and ground returns

**Total time spent: 3 hours**

fixed the existing usb, hdmi and ethernet routing on the center board after the placement changes. moved the usb traces off the power layer, corrected their widths, and rebuilt the crowded connector fanouts so the pairs stay together. also lined up the two usb transmit capacitors and moved the right connector’s shield resistor to give the traces more room.
finished the four hdmi pairs and the ethernet controller’s data and clock connections to the right-side connector. matched their lengths and added ground vias around the layer changes, including two extra stitches near the connector. the largest hdmi mismatch is now 0.052 mm, and the complete usb-c 1 receive pair is within 0.03 mm.
also found a missing 1 mm piece in one of the nvme receive traces. recovered the original segment from an older revision and restored the connection without changing the surrounding routing. cleaned up a small usb shortcut and improved the checks for disconnected paths, unwanted branches and pair spacing.
the saved board now has zero drc errors, and its connections match the schematic. refreshed the component positions, height information and cable exports for the case. the three moved parts clear the modelled wires, and all 18 wire paths still meet their bend and length limits. there are 1,795 connections left to route on the main board.

images: https://cdn.hackclub.com/01a0f9df-cb7d-7e5f-bbd6-6ba9e2ddb4f2/Screenshot%202026-10-01%20at%2019.49.30.png https://cdn.hackclub.com/01a0f9df-cd88-7933-95b0-f3e3a2529a1a/Screenshot%202026-10-01%20at%2019.49.37.png

# 2026-10-1: rebuild the journal and add the missing pictures

**Total time spent: 2 hours**

put the journal back together after the forge database incident. restored the missing entries, expanded the old short lists into proper devlogs, and added pictures from the saved boards, schematics and firmware. all 91 entries now have images. i kept the dates and recorded hours, removed the extra process commentary, and saved both keyboard timelapse links in their matching entries.

image: hc cdn

# 2026-09-30: rework the board placement and fix more power stuff

**Total time spent: 5 hours**

i stopped trying to keep everything on top and did a much bigger placement pass across all three main boards. i moved 230 existing parts on the center board and reorganized the USB, audio, MCU and power sections. small support parts now use the underside where it makes sense, with capacitors much closer to the pins they actually support. the connectors, mounting holes and existing PCIe routing stayed in place.
i also integrated the revised 100 W power circuit, corrected the charger current limits and standby-current handling, added missing bypass capacitors, and made a proper footprint for the power MOSFETs. i checked the maximum heights of all 392 underside parts and exported their positions for the case design. the BMS manufacturing package was regenerated and checked too.
the schematics and board connections match, both I/O boards have zero physical DRC errors, and the firmware passes all 34 host tests and its ARM build. the center board still has routing errors to fix.

images: 

# 2026-09-29: work on standby power and update the pd configs

**Total time spent: 3 hours**

worked on the 100 W power redesign, mainly the standby supply and Mu regulator. added controlled startup and current limiting to the standby circuit, and changed its battery feed so that current goes through the charger’s measurement shunt. checked component tolerances and corrected several resistor ordering codes. the Mu supply now has two current-sense resistors in parallel, and i adjusted its power budget to leave enough room for the fan.
also exported fresh 20 V / 5 A configurations for both USB-C controllers and checked the generated files. corrected the BMS shunt part number and rebuilt its assembly package without changing the routing. the firmware tests and ARM build pass. main-board placement is still unfinished, especially around the charger’s gate-drive and bootstrap parts, so those changes haven’t been applied to the saved main boards yet. no new routing was added.
image: 

# 2026-09-29: more keyboard routing

**Total time spent: 22 minutes**

did some keyboard routing! rerouted the updated led signals and power stuff.
this was done yesterday, just forgot to devlog
image: 

[lapse](https://lapse.hackclub.com/timelapse/cNIGQ1WzACUJ)

# 2026-09-28: finish the bms routing and clean up the tracks

**Total time spent: 2 hours**

finished the bms routing after the connector and fuse changes, then cleaned up the weird bends and dangling tracks across the board. merged the tiny straight segments, removed unused vias, and replaced the old battery connector tail with a shorter connection. there are now 628 fewer track segments, without moving any components or mounting holes.
fixed the supervisor ground return and current-sense pickup, checked all nine power paths, moved nine clipped labels and removed the last copper sliver. the saved board now has zero unconnected items, physical drc errors, dangling-copper warnings or silkscreen warnings. the pad and drill checks pass too. updated the layout report and readme, and pushed everything. the pcbway files still need regenerating for this revision before ordering.



# 2026-09-27: sort out the keyboard leds and fix more bms routing

**Total time spent: 4 hours**

the keyboard led wiring was crossing everywhere, so i changed the assignments to follow the actual rows and nearby columns. updated the schematic, pcb, firmware mapping and wiring reference together. kept all 65 local led joins, all 264 vias and the existing switch, power and i2c routing. only removed or trimmed old led links that conflicted with the new assignments. the mapping tests pass, and the keyboard still has four existing ground thermal errors to fix while routing.
also continued repairing the bms around the connector changes. brought it from 85 unconnected items down to 5, restored more control and power connections, and extended the pours into the unused space near the edges. moved and shrank the current-sense test point and removed several vias that were cutting through the main power copper. compared the power paths against the previous board and checked each saved revision. the latest bms has zero physical drc errors, but still needs the last connections and final checks on the sensing and return paths before it is ready to order.



# 2026-09-26: work on the power redesign and case

**Total time spent: 6 hours**

worked on the 100w power redesign for the mu ultra. added the ISL9241 charger driver, input switching and interlocks, and more current-limit and power-budget handling. the firmware tests cover weaker chargers, switching inputs, resets, failed communication and charging independently of the os. also worked on the new Mu supply and always-on power circuits. the complete 100w circuit still needs to be integrated into the boards.
changed the tall power connectors to low-profile WAGO terminals and updated the wire specifications and shared return-current calculations. the BMS now has a right-angle raw-pack connector and a smaller 5a fuse. fitting everything meant moving some nearby parts and test points, then removing conflicting copper. the board outlines, mounting holes and existing main-board high-speed routing were preserved. the BMS currently has 85 connections left to repair, so it isn't ready to order again yet.
expanded the case study into a full assembly with base and lid pieces, revised Framework hinge supports, keyboard and trackpad supports, battery trays, speaker and OLED mounts, and cooling reservations. added STEP/STL exports, mounting and fastener schedules, an interactive viewer, and open, closed, exploded and section views. the study exposed how much space the old plugs and wire bends needed. the final thickness is still undecided, and the case exports need updating for the revised connectors.
the firmware host tests and all 19 power tests pass. all four updated schematics have zero ERC errors and match their PCB pin assignments. saved everything as a checkpoint and marked the previous BMS manufacturing files as outdated. routing, harness clearance and physical testing still need finishing.



# 2026-09-26: start the case with the actual hinge mounts

**Total time spent: 1 hour**

imported the original Framework 13 hinge models and revision-00 drawings. the left and right mounts are different: their base seating faces are 1.3 and 2.2 mm below the shared axis. the lid has stepped faces too. made separate backing plates, spacers and small printed fit gauges for both sides. the editable source, STEP files, STLs and dimensioned mount drawings are together in mechanical/case-prototype.
the replacement photos were useful here. the three lid screws are two M2 screws and one smaller M1.6 screw. the extra large hole is part of the Framework display mounting arrangement. the two base screws use the middle round and slotted holes, not the outer locating holes. the new plates have their own chassis bolts, clear of the hinge screw heads.



# 2026-09-25: fix charging without the os and sort out the mu model

**Total time spent: 2 hours**

fixed the mu ultra model so it sits correctly in the socket, without changing the actual board placement or routing. also fixed the charging logic so it doesn't depend on the OS being running. added checks for charging during startup, shutdown, missing load readings and temperature faults.
expanded the power calculator to account for converter limits and battery assistance. all software tests and the firmware build passed. the bigger 100w power redesign is drafted and saved, but still needs integration and board changes before it's ready.



# 2026-09-24: start switching the carrier to mu ultra

**Total time spent: 1 hour**

started converting the carrier to the mu ultra, with the 226v first and room to upgrade to the 256v later. checked all 260 module contacts, moved the usb connections that changed, and moved hdmi to TCP2. pin 136 used to be ground but is now reserved, so that connection is gone. also replaced the nvme clock-request pull-down with the proper connection to the module.
changed the internal usb hub from two ports to three so the trackpad can share it with the audio codec and optional radio. made the hub footprint match the manufacturer’s drawing and placed the trackpad power-control parts. removed 51 obsolete trace/via items around the changed connections, while keeping the rest of the routing and existing component positions.
the schematic checks and 13 interface tests passed, and both boards’ pad connections match their schematics. there’s still routing and existing DRC issues to finish. decided on 100w usb-c input, but the charger, 12v supply and safe transition to battery power still need redesigning. the bms and keyboard are unchanged.
image: 

# 2026-09-23: keyboard routing

**Total time spent: 1 hour**

did some routing on the keyboard. did the switches, mcu, and led power, but not yet led signal.


[lapse](https://lapse.hackclub.com/timelapse/IrWANT44CM27)

# 2026-09-22: add rgb to the keyboard and get it ready to route

**Total time spent: 3 hours**

added per-key rgb to the keyboard! picked tiny everlight LEDs that fit underneath the cherry ultra low profile switches, then checked their height, pads and position against the switch drawings. added a matrix driver, current-setting resistor, power filtering and an I2C buffer so turning the lighting off won't interfere with the rest of the bus.

finished the schematic and component placement while keeping the original key positions, board outline and cable connector. cleared the previous routing so i can route it again myself. also cleaned up the schematic labels, added a connection map and routing notes, and removed the old non-rgb order files.

the firmware now handles startup, individual colours, brightness and fault shutdown. all 30 firmware tests and the target build passed. the schematic and placement checks are clean, with 960 connections left to route. next up is routing it.

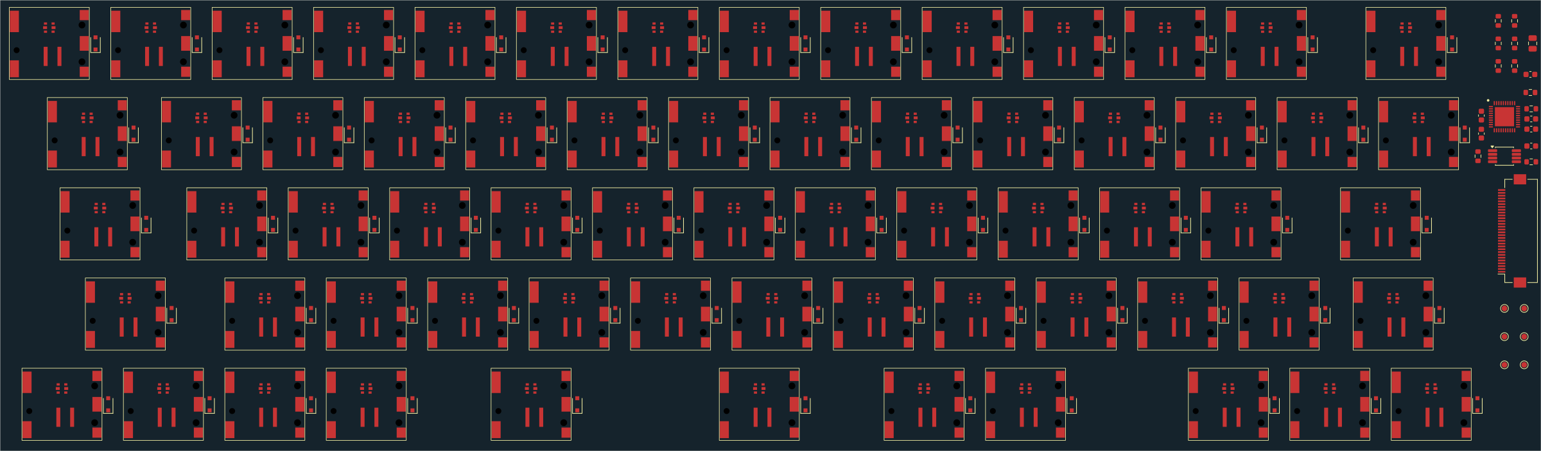
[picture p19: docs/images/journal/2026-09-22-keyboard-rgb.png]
RGB keyboard placement on 22 september 2026


# 2026-09-22: get the bms files ready for pcbway

**Total time spent: 2 hours**

got the bms files ready for a pcbway quote. there were still a few manufacturing details to fix after finishing the routing. widened three short traces from 0.09 to 0.10 mm, thickened the silkscreen to 0.15 mm, and cleaned up the overlap that caused.

also moved six vias away from nearby solder-mask openings. one low-current return via now has a smaller hole while keeping the same copper land. checked the smt openings with an extra 0.05 mm mask margin, then reran the power-path checks to make sure these changes hadn’t broken anything.

exported and checked all four copper layers, drills, stencil files, the electrical test netlist, bom and placement files. the assembly list has 123 smt parts and two through-hole parts, with the removable fuse listed separately. the test pads aren’t counted as components.

the saved board still has zero physical drc errors, zero unconnected items and no schematic mismatches. all 28 power-path cases passed. bundled everything with assembly drawings, order settings and file checksums. the notes ask for prices for one and two assembled boards. i still need to get the parts and manufacturing details confirmed with pcbway before paying.

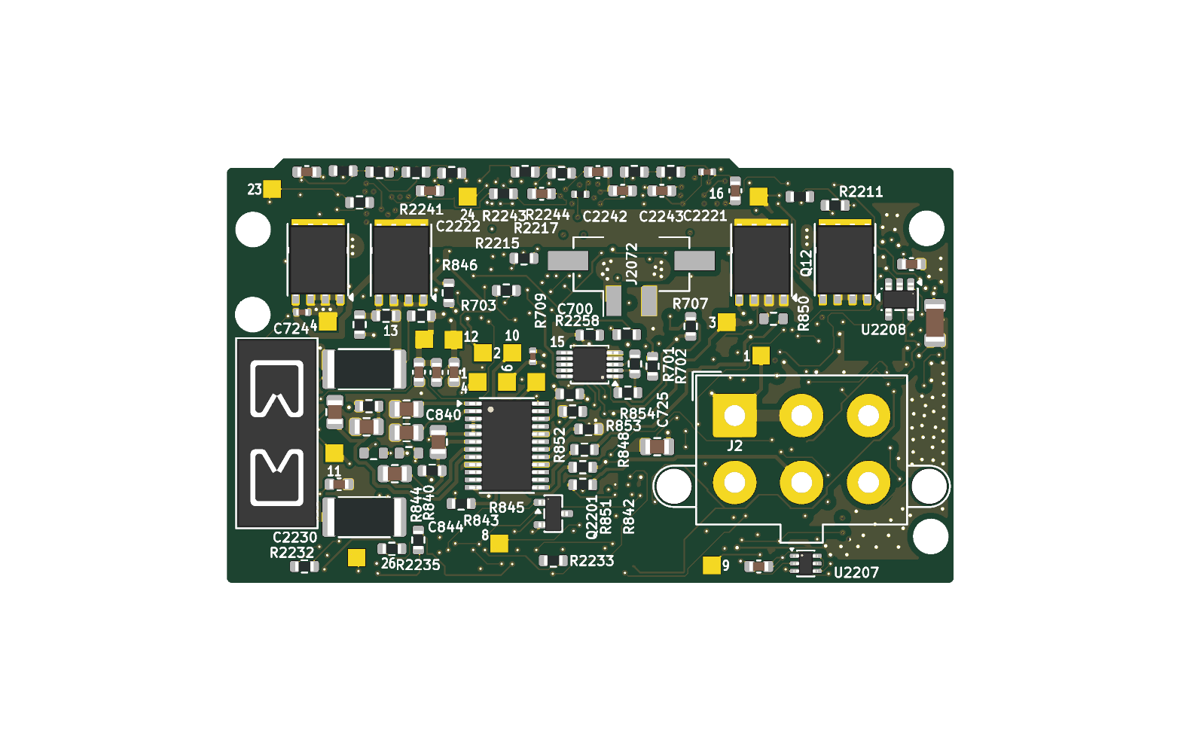
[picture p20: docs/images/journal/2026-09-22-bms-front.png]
BMS front prepared for PCBWay on 22 september 2026

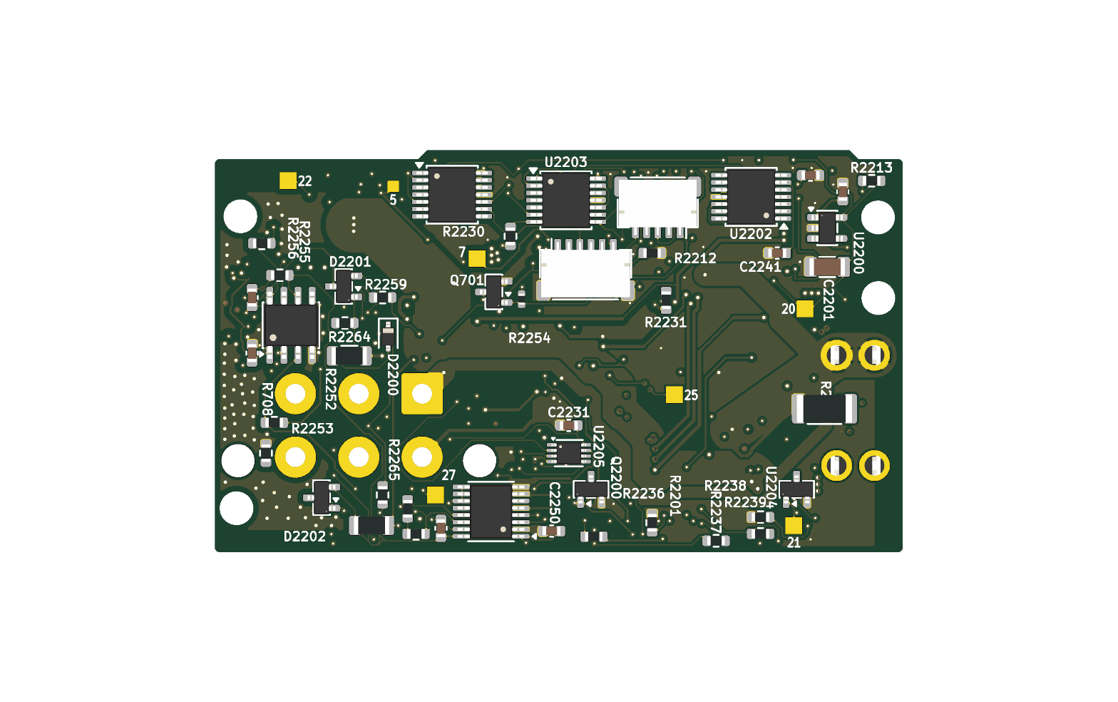
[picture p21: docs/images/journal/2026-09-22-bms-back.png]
BMS back prepared for PCBWay on 22 september 2026


# 2026-09-21: finished bms routing!!

**Total time spent: 4 hours**

finally finished routing the bms! the temperature probes, isolated control signals, reference circuits and remaining supply connections are all connected now. it still fits on four layers. i removed the two middle mounting holes to make room, kept the four outer supports, and moved a few small parts around to get through the cramped areas.

i also reworked some power copper so the signal vias have enough clearance, then checked that the battery and return paths were still connected properly. the quiet sensing return stays separate from the load current. the saved board has zero unconnected items, zero physical drc errors and no schematic mismatches. all 13 thermal tests and 31 electrical calculation checks passed too.

cleaned up the silkscreen and test-point numbers, added front and back assembly drawings, exported previews, and updated the mechanical files and docs. i also wrote down the remaining warnings so i can refer back to them when i get the board made.

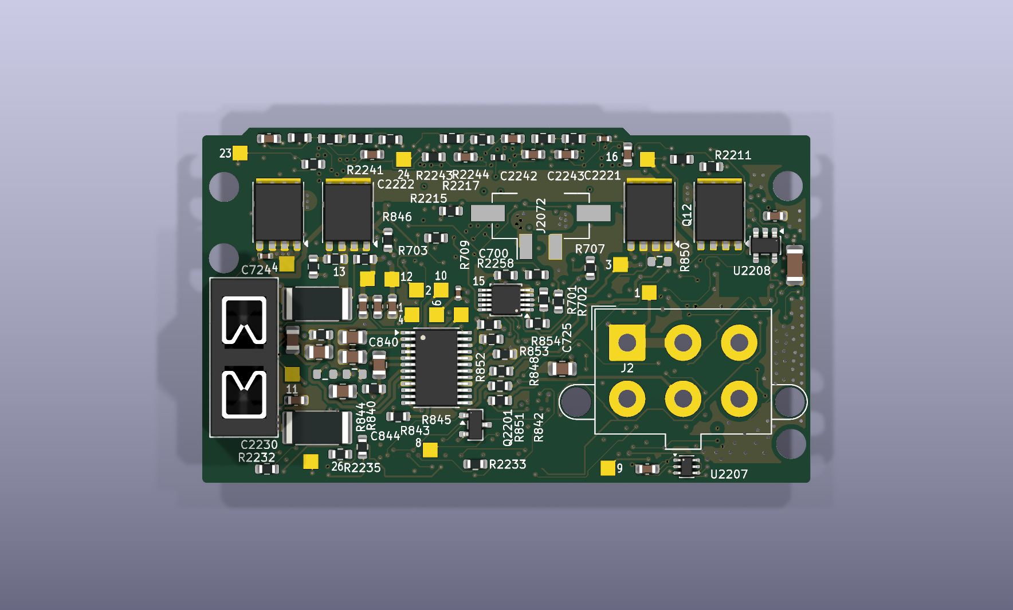
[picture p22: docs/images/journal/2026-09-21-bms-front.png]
BMS front after routing on 21 september 2026

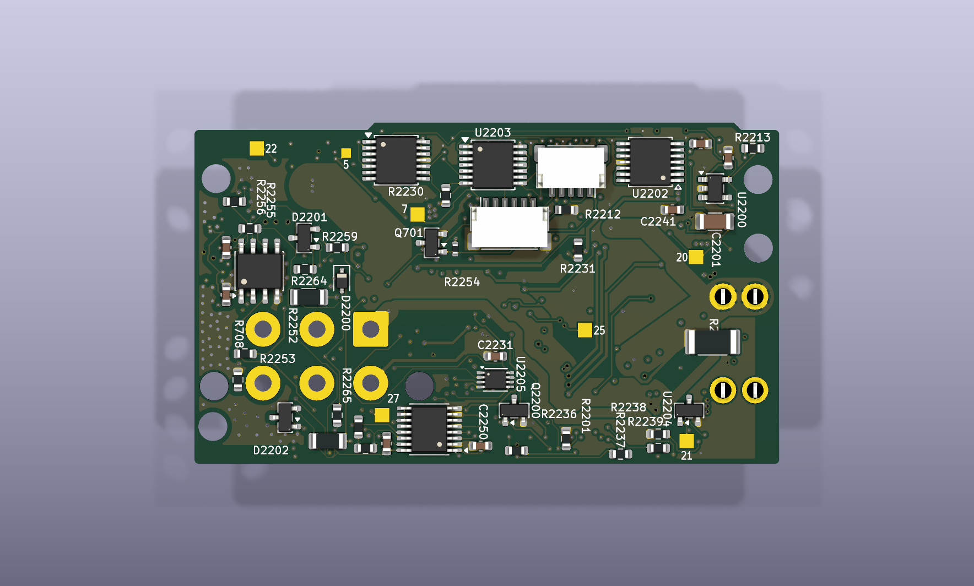
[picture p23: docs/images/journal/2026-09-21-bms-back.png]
BMS back after routing on 21 september 2026


# 2026-09-20: more bms routing

**Total time spent: 5 hours**

spent a lot of time on the bms routing. routed the charge and discharge health signals, hot temperature references, and more of the isolated controls and supplies. also moved a few control and reference components to make room, and restored the complete schematic so it matches the revised 149-part board. it still fits on four layers.

a big part of this was checking what the new traces did to the battery current paths. some routes passed normal drc but narrowed important copper enough to fail the resistance margin checks, so i discarded those versions. the saved board has zero physical drc errors and no schematic-to-pcb mismatches.

i have 46 connections left, mostly the temperature-sense and cold-reference circuits, supply rails, quiet returns and retry signals. i also need to clean up the silkscreen and the leftover track ends as i finish those connections.

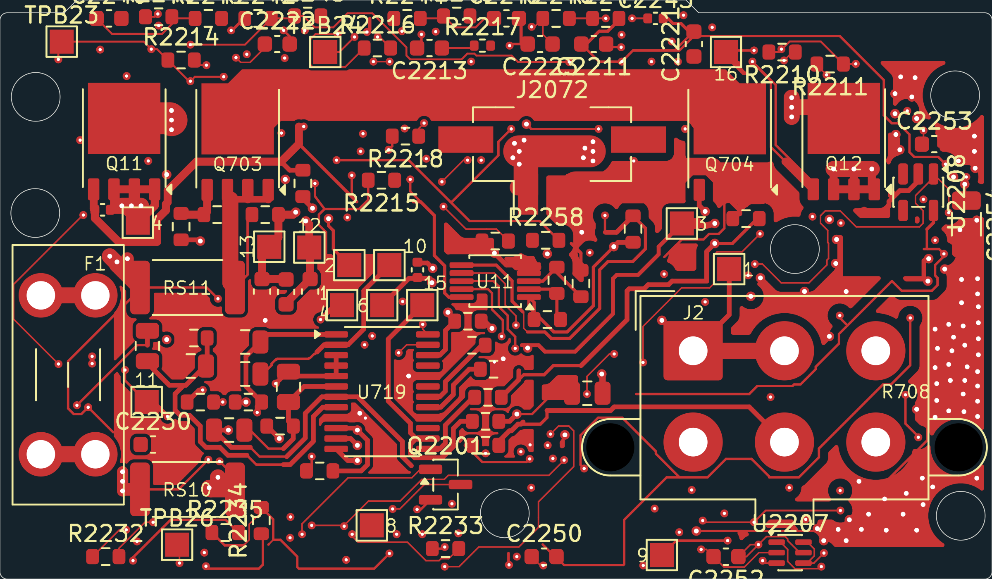
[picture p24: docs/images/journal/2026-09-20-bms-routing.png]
BMS routing checkpoint on 20 september 2026


# 2026-09-19: cleaned up schematics

**Total time spent: 4 hours**

cleaned up the schematics across the main board, both i/o boards, bms, keyboard and radio board. a lot of the labels and values were sitting inside large symbols or on top of each other. moved the reference and value text outside the bigger chips, turned net labels outward, and removed duplicate labels sitting on the same pin.

also spread out the crowded charger, efuse, wifi and oled sections, including the small parts that were overlapping the larger symbols. updated the generators so the next regeneration keeps these readability changes, then saved the updated sheets.

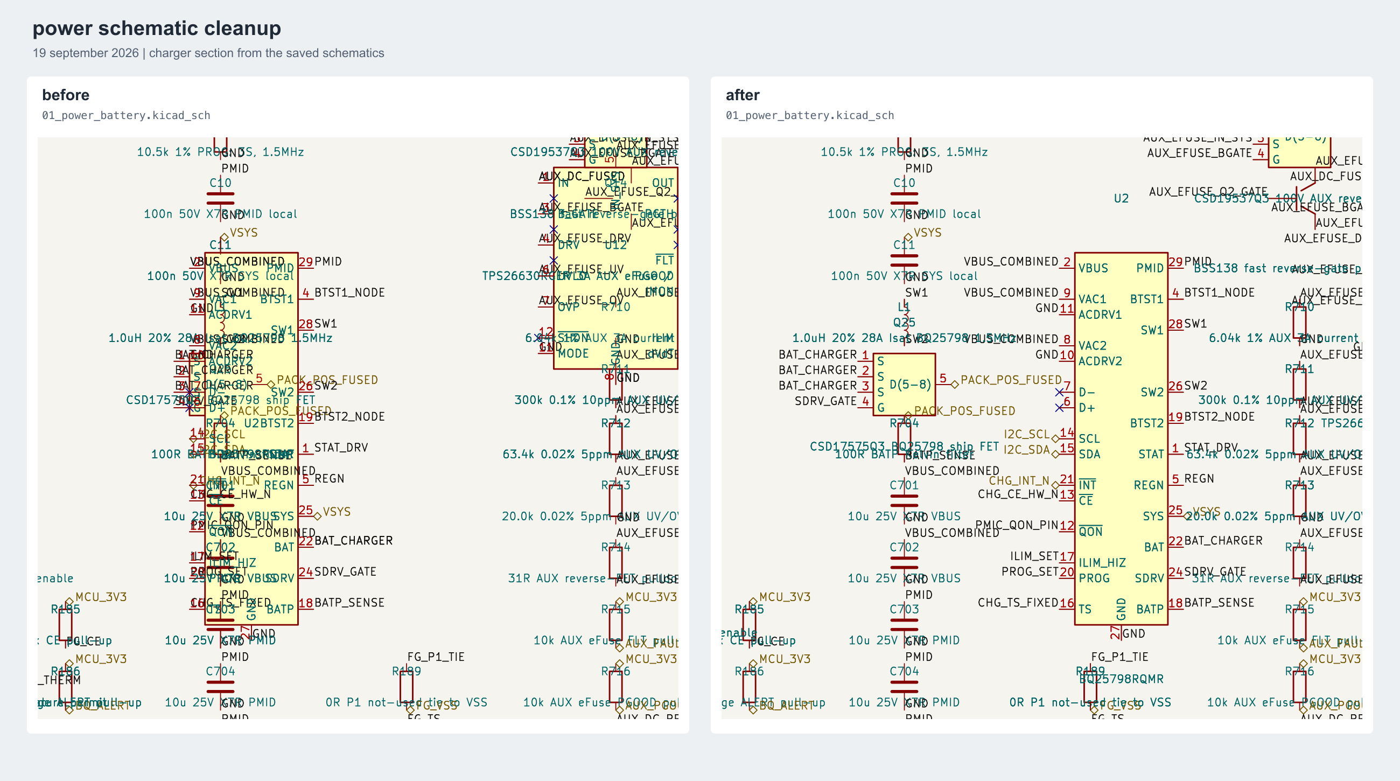
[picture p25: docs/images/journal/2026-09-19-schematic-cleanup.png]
Power schematic before and after the september 19 cleanup


# 2026-09-19: Split up my first 142 hour journal

**Total time spent: 1 hour**

split my first big journal into 40 shorter entries. it covered work from july 2 through august 27, before i knew about forge, and the single long entry was getting hard to read.

i grouped the work into smaller sessions and kept the original dates and individual times. the earlier design, firmware and placement work now has its own entries, instead of everything being buried in one huge list. i also kept the screenshots with the older work.

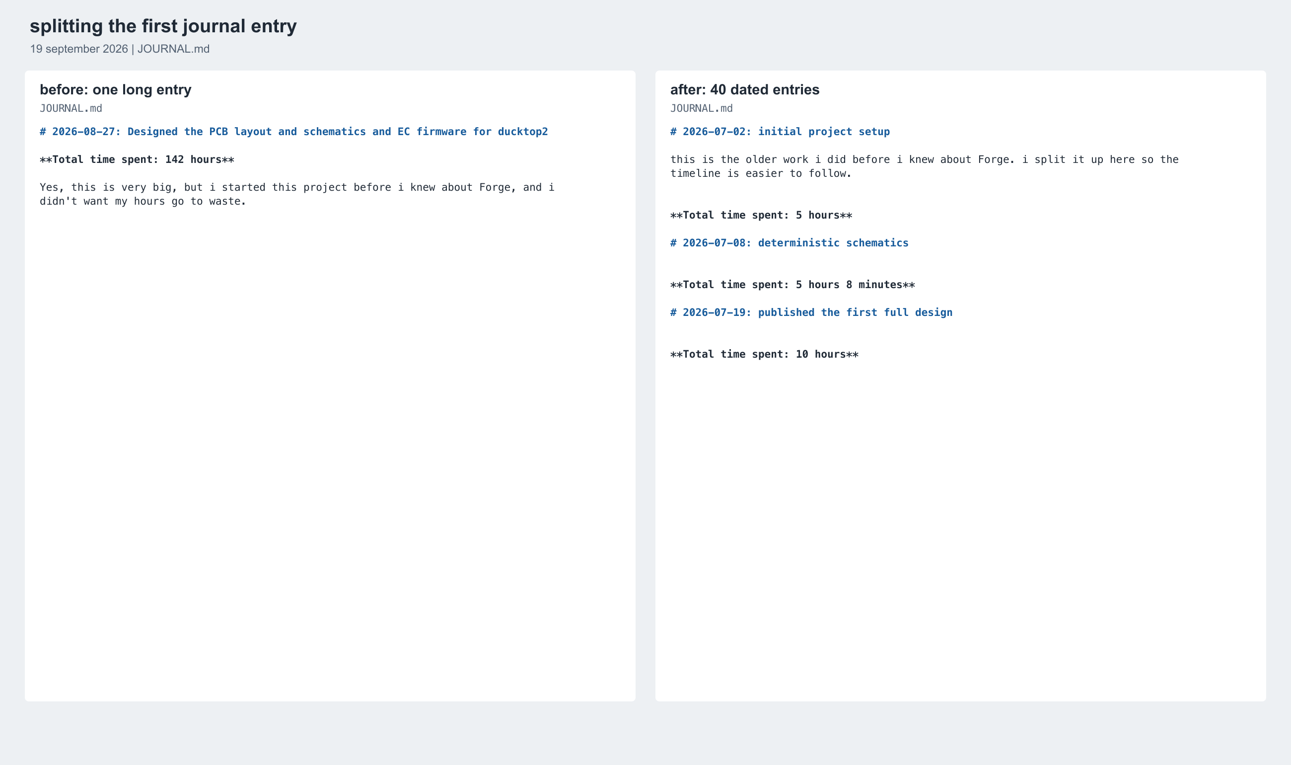
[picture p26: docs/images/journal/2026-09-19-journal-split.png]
Journal excerpts before and after splitting the first entry


# 2026-09-18: more bms routing

**Total time spent: 1 hour**

worked on the bms thermal and control wiring and added nine connections. it still has 44 unconnected items, with no physical drc errors. also fixed the c2243 and r2254 datasheet links so they survive schematic generation. all 13 thermal tests passed. the generator fixes are committed, and the unfinished routing is saved locally.


# 2026-09-16: more routing: diff pairs + stm32

**Total time spent: 1 hour**

I realized that i did not need to have a whole bunch of grounded stitching vias in between the differential pairs, and i could have just run a ground trace between them, so that's what i did. also did some routing for the stm32, mostly the keyboard nets.
screenshots: 

# 2026-09-16: nextpcb sponsor!

**Total time spent: 10 minutes**

added nextpcb to the repo's sponsors section with their official logo and a link to their site. they're supporting pcb manufacturing and assembly for ducktop2.


# 2026-09-15: more routing

**Total time spent: 1 hour**

routed a lot of differential pairs, including gigabit ethernet and usb3 port, to the lattepanda mu. also did some miscellaneous routing.
i forgot to start my lapse after like 15 minutes, so lapse only shows 50 minutes :(


# 2026-09-14: put a lot of work into the bms and fixed the usb stuff

**Total time spent: 8 hours**

fixed the 42 usb spacing issues on the center board, corrected the m.2 socket and microphone models, and cleaned up stale footprint warnings. i also investigated the missing ground segment. it was an overlapping stub, so removing it hadn't broken the return path.
most of this session went into the bms: temperature interlocks, isolated controls, the reset circuit and ground returns. some routes passed the normal checks but interrupted important copper paths, so i reworked those and compared the current paths before and after. i also checked smaller resistor and capacitor packages and updated their source definitions. the bms routing is still unfinished, so it isn't ready to order yet.

screenshots: 

# 2026-09-13: fix the pcie routing and ground layers

**Total time spent: 4 hours**

reworked the nvme and wifi pcie routing. the fast signals now use F.Cu, In2.Cu and B.Cu, leaving the ground layers clear of signal tracks. when i originally routed this, i put some pcie diff pairs through dedicated ground layers which was bad. moved the tx coupling caps to the back of the board near the m.2 sockets, tightened the pair spacing, rounded sharp bends and matched the complete paths through the capacitors. also finished the reset, wake and clock-request connections and connected the remaining socket grounds.
fixed placement collisions and the maker supply trace that crossed its switching keepout. corrected the ethernet controller's pcie link to the 85 ohm netclass, while keeping its mdi pairs at 100 ohms. added checks for complete pair lengths, local fanouts and spacing further along each trace. all 12 pcie paths pass the layout checks, and all 49 tests passed.
updated the board documentation and assembly coordinates, keeping the 358 mm span and both 1.5 mm board gaps. saved and reopened the board to verify the changes survived correctly. there are still 1,725 unconnected items and 42 usb spacing findings to work through. the full assembly export also needs the existing bms connector mismatch resolved.

screenshots: 

# 2026-09-13: length matched pcie diff pairs

**Total time spent: 30 minutes**

I forgot to do length matching on the pcie differential pairs last time, so i did it now. luckily it wasnt too much work, because kicad has a very helpful tool for this.
screenshot: 

# 2026-09-12: finish wifi routing and do fpc routing

**Total time spent: 1 hour**

i finished the wifi routing, with the leftover stuff that wasnt part of the diff pairs, and the main thing i did now was both io fpc connectors. i routed a fanout of vias, and then i had to put ground lines through them as well, which was hard and annoying. i couldnt put the ground vias on the other side because the spec sheet of the connector says there needs to be a keepout there.
screenshots:


# 2026-09-12: Routed the diff pairs for the nvme

**Total time spent: 1.5 hours**

i routed the differential pairs, 4 total because 4 lanes, of the pcie3 nvme ssd. i had to use some vias for shifting layers, but i did my best to keep everything in their pairs. i also did the gnd stitching of the lattepanda, and added the coupling capacitors for the pcie lanes.
images: 

# 2026-09-11: more routing, more checking

**Total time spent: 1 hour**

did more maker mcu routing, continued the bms thermal and control routing, including a smaller test point to make room for the comparator signals. the first temperature channel repair has passed its local checks, and the cell-monitor connections are being rebuilt around it. the cable now is a compact soldered one for the board seams and bms.

images: 

# 2026-09-11: did some center board routing

**Total time spent: 30 minutes**

I did some routing for the keybaord FFC connector (the 1k resistors), and also some routing for the maker mcu gpio pins.

screenshots: 

# 2026-09-10: did a lot of work, on the center and right board

**Total time spent: 8 hours**

narrowed the center board by 1.5 mm on each side, giving the boards clearance while keeping the overall span at 358 mm. also fixed the placement around the power converters, checked that both M.2 sockets line up with their retainers, and adjusted the front cutout for the revised bms.
corrected hdmi pairs and usb routing on the right board. the radio’s component information now matches the schematics too. another check caught a missing keepout around the microphone opening and 343 duplicated object ids across three boards. fixed those and updated the footprint importer to prevent the same copying issue.
cleaned up more outdated documentation and tightened the board checks. reviewed footprint differences are now tied to the actual saved components, so later changes need another review. all 159 design tests pass, and the left, center, right and radio boards pass their board-level preparation checks.
the mechanical exporter now follows the actual pcb outlines and includes connectors on the underside. this also caught a proposed cable connector sitting beyond the shortened right board, so that placement was rejected. bms routing and the final power-cable fit are still unfinished, and those trials are kept separate from the saved boards.

images:  

# 2026-09-09: left board changes!

**Total time spent: 10 hours**

got the left board’s power changes into the actual kicad project. it now has 325 parts, up from 273, including the revised USB supply, current monitor, fault latch, and permission circuitry. i made room for separate power wiring and the new signal connector while keeping the existing USB routing intact.
also cleaned up the footprint copies and crowded reference labels. the checks compare the actual pads, nets, solder mask, and paste openings, and preserve the deliberate silkscreen edits. the left board has no physical clearance or courtyard errors in the checked version, although there are still a few documented library and package-filter warnings.
spent more time checking the power limits and firmware behavior. the two usbc power controllers now have separate configurations for their actual ports. USB startup allowance is now 5.6 A, with 5.5 A steady, and losing the system supply leaves the USB power fault latched until it can be cleared safely. the design/import tests and firmware host tests pass; hardware testing still needs to happen.
fixed an import bug too: chips drawn across multiple schematic units could end up with broken component links on the PCB. those links now survive a normal save. my newer HDMI and USB routing on the right board is saved as well. the remaining center, right, and BMS revisions still need integration and checking, so there’s more to do before routing readiness or ordering boards.

image: 

# 2026-09-09: started on the hdmi routing

**Total time spent: 30 minutes**

i did some hdmi routing. only the front layer to start. mostly all resistors/capacitors/diodes done, and ground planes.

images: 

# 2026-09-08: fixed a whole bunch of stuff from an audit

**Total time spent: 15 hours**

spent this stretch working through a project audit. there were a lot of problems across the power circuits, component choices, firmware, and board layout, so this turned into a pretty extensive fix. fixed incorrect resistor part numbers, capacitor packages, the rtc diode orientation, and usb protection connections. also corrected the rp2350 regulator placement and its copper keepouts using the reference design.
the keyboard repairs are finished and its manufacturing files have been rebuilt. checked the switch copper exclusions, mounting pads, paste openings, drill files, and component positions. the checked keyboard has zero drc errors and zero unconnected items. the radio board’s antenna connectors also now line up with the actual mounting geometry.
on the firmware side, fixed the charger’s byte order and worked through the startup, register, watchdog, and fan handling problems. added checks around those paths and continued the usb power controls so port permissions account for available power, startup current, and vconn. physical testing is still ahead.
spent quite a bit of time on the connections between boards too. the revised design separates power wiring from the signal cables. found lower-profile shielded cable connectors, built their footprints from the manufacturer drawings, and remapped the signals with ground guards around the high-speed pairs. cable bends, ground straps, and the complete channel still need checking before those changes are applied.
the bms is still being reworked. a power-path check caught new signal routing breaking up the main battery return plane in the test layout. that version has not been applied. the return path needs to stay wide and continuous while the temperature sensing and isolated controls are added.
also moved several connectors and both m.2 sockets to positions that make more sense for the laptop. those positions are saved now, but the card supports, cable access, and nearby components still need another fit check. the remaining main-board routing hasn’t started.

images: 





# 2026-09-07: fixed a whole bunch of stuff to prepare for center board routing

**Total time spent: 7 hours**

i finished a big preparation pass on the main boards for before routing. i added a rounded cutout at the front center of the main pcb for the bms, with 1.5 mm clearance around it. this keeps the bms out of the middle battery cell’s space. i moved the battery connector to face it and checked that all 30 cable contacts line up with the correct reversed pin mapping.
the placement review uncovered several problems that would have been bad to find later. both m.2 sockets faced away from their mounting nuts, and some power components, the boot button, and the programming connector occupied the card areas. i fixed the socket positions using the reference carrier’s mounting dimensions and added the full card outlines to their courtyards so future placement checks catch overlaps.
i also regrouped the regulator capacitors, feedback networks, inductors, crystals, and battery-gauge parts. several were much too far from their circuits. two usb coupling capacitors had 100pF part numbers despite being labelled 100nF, and another capacitor had a mismatched capacitance and part number. fixed that.
the remaining work included cleaning up reference labels, restoring 18 connector mounting-pad grounds, fixing usb net names so kicad recognizes the differential pairs, and replacing obsolete routing keepouts. i also fixed an editing-tool bug that removed component models during rotation.
all 5,197 checked pads match their schematics, all 27 regression tests pass, and all 67 (shush) electrical calculations pass. the center board is clean apart from its 2,038 airwires. i preserved the existing left-board and bms copper. routing is next, including correcting the left board’s existing usb widths and spacing.

layout diagram: 

# 2026-09-06: changed oled connections, doing more stuff to make the routing ready

**Total time spent: 1 hour**

switched both oleds to wired connectors and moved the maker header beside the mu. fixed the copper-edge errors, cleaned up 37 placements, and tested the layer rules. center board drc is down from 158 to 61 errors; routing still needs doing.



# 2026-09-06: did more stuff to prepare for center board routing

**Total time spent: 1.5 hours**

fixed the center board checks and documented what still needs work. corrected the board selection, net-name parsing, selector pin review, and test-point generation. added 20 regression tests.

diagram showing clearance violations: 

# 2026-09-05: finish bms routing

**Total time spent: 5 hours**

finished the 4-layer bms routing. fixed the shunt sense paths and battery references, widened the power routes, and improved fpc current sharing. cleaned up the silkscreen, updated the docs, and regenerated the board exports. drc and erc both have zero errors and warnings.

this took a lot of time because i already made the board as compact as i could, so i had to squeeze the new stuff in.

screenshots of each layer:




render:



# 2026-09-05: clean up file structure and update documentation

**Total time spent: 1 hour**

i noticed the documentation was getting really outdated, as far as one month, and because i have made so much progress since then, it looks confusing. so, i updated all the documentation, and also cleaned up the file structure because it was messy.
structure image: 

# 2026-09-04: 1/4 PCBs routed: BMS board routed!

**Total time spent: 5 hours**

I routed the BMS board. I kept in mind the trace thicknesses, because a lot of power will go through this. I had 2 uninterrupted ground zones in the inner 2 layers, and another two on the top and bottom. I also added stiching vias. Also there are mounting holes.
Images:   

# 2026-09-03: Finished and prepared the BMS pcb daughterboard for routing, and some other stuff

**Total time spent: 3 hours**

 - i found more than 35 differential pairs with no impedance class across the three i/o boards, the left's hub/usb3 port pairs and the right's hdmi/gbe pairs would have routed at 0.2mm default width. 72 netclass patterns added. same thing on the bms power rails, only the fused positive and pack negative were power_hi: the raw input, post-fuse vin, both fet commons, and the fg_vss return were all default. everything high-current is now power_hi.

 - changed to 4 layer board, with the 2 inner ones being solid fg_vss

 - i wanted to verify individually that the board work before i would plug anything in and fry something, so i added 16 test points

starting routing now

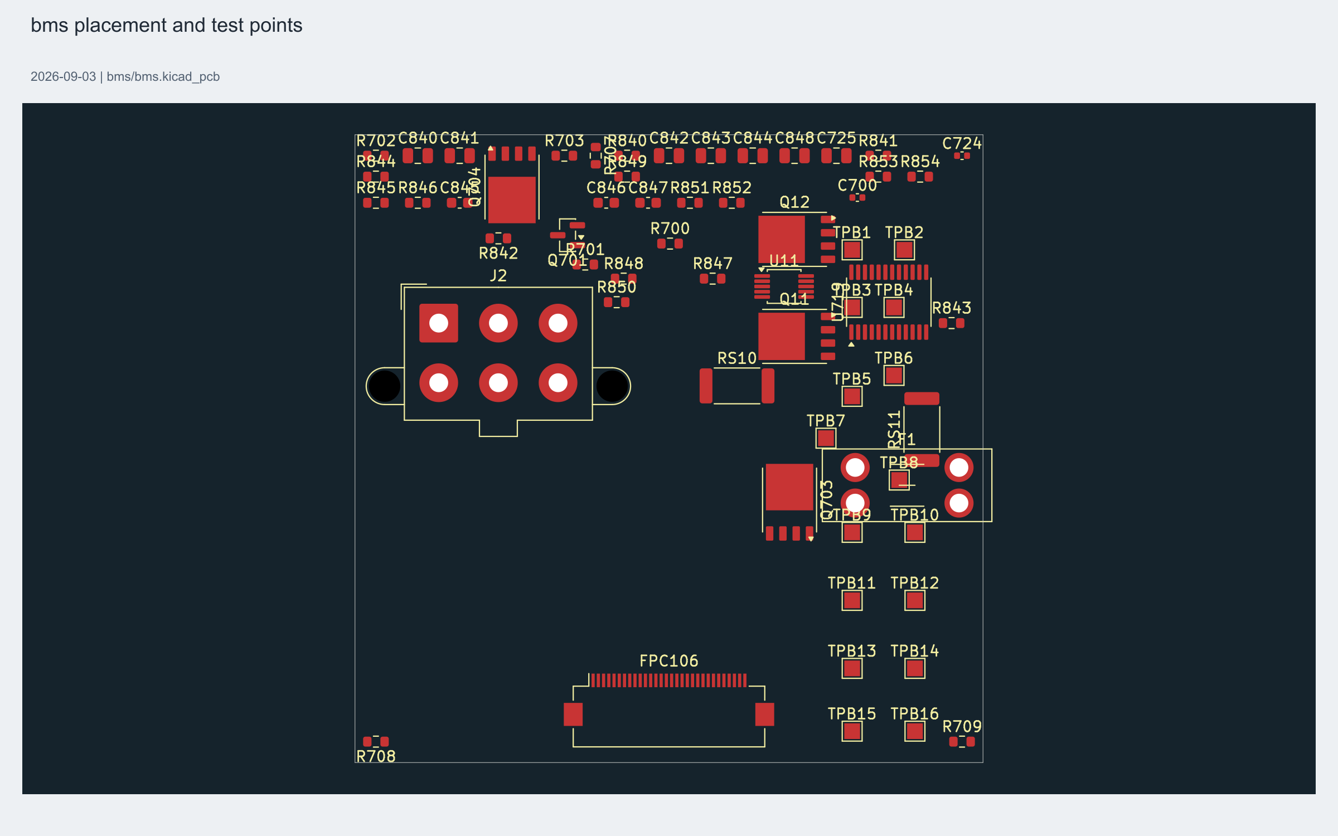
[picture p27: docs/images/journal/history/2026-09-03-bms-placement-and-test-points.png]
image: 

# 2026-09-02: I had someone audit the whole project (big thanks to them, they found a lot of stuff!) and fixed them

**Total time spent: 15 hours**

what the audit found:
- shadow nets: the fpc connector pads carried bare net names (VSYS) while the circuits used prefixed ones (/VSYS). same word, different nets. the battery never reached the charger.
- mirrored cables: a straight ffc between two connectors mounted 180deg apart mirrors the pin order (n <-> 69−n). my boards had straight through maps. fpc3's fused pack positive would have went on gnd. battery had a direct short through the cable.
- both power selectors were dead: the ltc4418 symbol had pins 6 to 10 transcribed from the wrong datasheet column. gnd wired to the intvcc bypass node.
- fh41 shield row 1.25mm off the datasheet, fpc power rails on single pins

right now:
- 4 boards: 0 shorts, 0 clearance, 0 drill/hole · 0 boundary crossings
- 6/6 connectors good
- 0 shadow nets anywhere, ERC 0 x4

images:    

# 2026-08-31: fixed an fpc connector issue

**Total time spent: 5 hours**

i found a problem. the fpc-1 and fpc-2 connectors are a part that doesn't exist. the hirose fh12 series stops at 60 pins, there are no fh12-100s.
i replaced replaced both with the fh41-68s-0.5sh(05). 68 pins, and its a shielded ffc connector so the usb3/hdmi/gbe pairs get a shielded cable, which was the intent anyway. both pin maps are good (fpc-1 uses 1-53, fpc-2 uses 1-61). new footprint derived from kicad's fh41-30s, new 68-pin symbol, solder-hold pads tied to gnd as the shield return, cable spec updated. updated the nets as well.
i also fixed some smaller stuff, like the placement of some components, clearing the shorts and other drc violations.
screenshots:
left io new fpc: 
right io new fpc: 
also updated on the main board: 

# 2026-08-30: wired up fpc connectors

**Total time spent: 5 hours**

every new daughterboards schematic has its hirose connector on it: fpc-1 and fpc-2 are 100-pin, fpc-3 is 30-pin, and all the boundary nets run through them. about to start routing!
image: 

# 2026-08-30: made all .pcb files

**Total time spent: 6 hours**

the main board is now four real .kicad_pcb files: left_io (266 parts), right_io (163), bms (46), ducktop2-center (710). built each from its own schematic so the nets are right, then transplanted the old placement by reference so all the placement keeps.
pcbnew's python wrapper corrupts its own type table after a few hundred by-value returns, so all geometry gets parsed from the board text files instead.
drc: zero shorts on all three daughterboards, zero clearances on bms, all the remaining violations are pre existing footprint level stuff that's also on the original board. center board went from 51 shorts to 17 and none of those involve re placed parts. also generated the FH12-100S footprint (derived from the 50-pin, 100 pads, MP tabs) since kiCad doesn't ship one, and sorted out that kicad-cli resolves project rules from the cwd, which took way too long to figure out.

pcb screenshots:
main board:
left io board: 
right io board: 
bms board: 

# 2026-08-29: center board got cut down

**Total time spent: 1 hour**

the big trim is done. the center board went from 14 sheets to 9: the usb-c i/o sheet, power inputs, hdmi, and ethernet are all gone from it, plus the whole pack-protection section of the power sheet. the center now keeps only whats central: the charger, fuel gauge, and ship fet; the ec and mu; radio; internal services; keyboard; maker; audio. 717 components, down from 1100.
the hard part was the boundary. every net that crosses an fpc now has to exist on the center root as a declared boundary label: 30 to the left board, 35 to the right, plus the pack nets to the bms. and two of them (hub ds1 dp/dm) are pass throughs: they come in on fpc-1 from the left hub and go right back out on fpc-2 to the right board's usb-c port, with nothing on center touching them. the center is just a wire for those.
the verification system had to be rebuilt for four boards. the contract checker now takes a --project flag and runs the right checks against the right netlist, pd1 contracts on the left board, pd2/hdmi/gbe on the right, pack protection on the bms, everything else on center. same for the closure audit and the electrical calculations.
the trim exposed 2 bugs. the daughterboard roots were placing their fpc boundary labels at arbitrary coordinates instead of on the sheet-pin endpoints, so the left and right boards internal wiring never actually connected to their own roots, the netlists showed the pd1 vbus rail as an orphan. and there was a duplicate ground pwrflag sitting on the same spot in the power sheet from my earlier edit, which the erc caught.

image: 

# 2026-08-29: bms board!!

**Total time spent: 1 hour**

the bms board has schematics now. 45 components. the protector filter networks. the bq77915 needs a divider and caps per cell tap, and the ltc4368 needs its uv/ov divider, gate slew network, and the whole fault/retry path.
the board has the fuse, pack connector, both protectors (bq77915 primary + ltc4368 redundant), all four fets, both shunts, and the charge/discharge gate network.the fuel gauge is still on the center board, its i2c and alert lines go to the ec and the source manager, so it's electrically center bound even though it's battery stuff. the charger and ship fet stay center too. what crosses to center is just the pack terminals, fault lines, and 3v3: six nets on fpc-3.
schematic image:

# 2026-08-28: right I/O board!!

**Total time spent: 1 hour**

the right board (right_io/) has pd2 (u42), j11/j12 (already usb2), the hdmi chain, and gigabit ethernet. added to its own schematics and subproject.

schematic screenshots: 

# 2026-08-28: left I/O board!!

**Total time spent: 1 hour**

the left board project exists now. it's a standalone kicad project in left_io/ with its own root schematic and two sheets, holding the hub, the pd1 chain, all five left ports, the usb-a cluster, the ss muxes, and the aux screw terminal — 261 components total.
the aux screw terminal (j190) lives on the left board but its protection chain, fuse, tvs, reverse fet, the whole efuse, stays on center next to the vsys or-ing where it belongs. only the raw AUX_DC_RAW crosses the fpc. second, the left sheets are big because they reuse the main board's full layouts, that's fine for now, a compaction pass can come later.

schematic screenshots: 

# 2026-08-28: starting schematic edits

**Total time spent: 45 minutes**

first schematic edit for the split. the right-side usb-c ports (j11 and j12) are losing their super-speed lanes, because after the split there's no usb3 host port left on that side of the board, the mu has only one usb3 host, and it's feeding the left hub. so j11/j12 keep pd charging (15v sink, 5v/0.9a source) and usb2 data, but their ss pins are now no-connect.
the work was mostly in the generators. j11's port lost its tusb1142 redriver and the whole ss coupling/esd chain. j12 lost its hd3ss6126 orientation mux. the hub's ds1 and ds4 ports became usb2-only, their ss pins (7/8/10/11 and 36/37/39/40) are retired to nc, keeping only the d+/d- pairs that feed the ports' usb2.
net result: 16 ss nets deleted, and the schematic gate is back to pass — closure 1574/0, contracts ok, erc 0, and the pin review table at 2602/2602 all pass.
image: 

# 2026-08-28: connectors picked, cuts validated, boards scaffolded

**Total time spent: 30 minutes**

first, the fpc connectors. the obvious move was to stay in the hirose fh12 family, i already have that for the radio and keyboard (j2300, j310), so one family, one footprint style, one supplier. fpc-1 and fpc-2 get 100-pin versions, fpc-3 gets the same 30-pin part already in the BOM. the important thing i realized is that the impedance for the high-speed pairs is a cable spec, not a connector spec, the fh12 is just a 0.5mm interface, and the 90/100-ohm sections come from ordering impedance-controlled shielded ffc. so the connector decision is boring, which is exactly what you want.
then i validated the cut lines against the actual mechanicals. left cut at x=70 clears the left mounting holes and the hinge notch with 22mm of connector space. right cut at x=300 keeps the right holes and hinge notch with 54mm of space. no hole straddles a cut, which would have been a nightmare for the chassis.
next up is the actual schematic surgery: j11/j12 go usb2-only, the hub and pd1 chain move to the left board, pd2+hdmi+gbe move right, and the bms sheet gets built. that's the real work.
image: 

# 2026-08-28: worked out the specs of the split. 4 boards, 3 fpc connectors.

**Total time spent: 2 hours**

so i spent the last session doing the math on the board split. i built a script that assigns every one of the 1225 footprints to its board — left i/o, center mainboard, right i/o, or the battery bms, and then counted every single net that has to cross a board boundary.
the results surprised me a little:
- fpc-1 (center <->left): 75 signals. usb3 upstream pair to the hub, all the hub control (spi, reset, config), the pd1 i2c and irq lines, plus power.
- fpc-2 (center <-> right): 83 signals. hdmi, gigabit ethernet, the whole pd2 chain, usb2 for j11/j12, ec debug.
- fpc-3 (center <-> bms): 16 signals. just the pack terminals, cell taps, gauge i2c, and the charge/discharge gate lines. this one is beautifully small — it's basically the macbook battery board interface.
- the keyboard ffc stays as it is. the keyboard pcb is already manufactured.
the pd controllers had to be split by function, not by side. pd1 chain goes left with the left ports, pd2 chain goes right with j11/j12. and i confirmed that j11/j12 going usb2-only kills 16 super-speed nets that would have been a nightmare to route across two fpc boundaries.
one thing i didnt do for good reason: no vsys, no vbus_raw, no pphv over any fpc. only sys3v3 and usb_port5v cross, and those are the low-current class. running 8.6a of vsys through an ffc would need like 18 pins and would drop voltage anyway.
the spec is committed and frozen. next is picking the actual ffc connectors, validating the cut lines against the mounting holes, and then the schematic work.
image: 

# 2026-08-28: Big change: splitting the PCB into multiple daughterboards.

**Total time spent: 4 hours**

Big change: splitting the PCB into multiple daughterboards
so this day started with someone from hack club messaging me about my decoupling caps. honestly they were right, i measured pin-to-cap distances in the actual pcb files and it was bad. one of the pd controllers had its 68µf pphv bulk cap sitting ~260mm from the chip, basically the other side of the board. the ldo caps were 30-268mm out. the mu's 12v bulk was ~100mm from the module pins. that's a lot of loop inductance for a 30w part, this would have been a pain to debug on a one-shot board.
but the deeper issue was the layout itself. the usb hub sits at x261 and the ports it feeds are at x4.5 and x353, so every super-speed lane runs 200-300mm across the board just to reach a connector. i looked at splitting into two hubs but the mu only has ONE usb3 host port, so there's no way to feed a second usb3 hub without daisy-chaining (latency) or downgrading.
so i settled on a proper 4-board architecture:
 - left i/o board: 3 usb-c (usb3) + 2 usb-a (usb3) + aux input + the hub + the whole pd controller chain. hub finally sits next to the ports it feeds, and all the decoupling caps become naturally local — the cap fix and the layout fix solve each other.
 - right i/o board: hdmi + gigabit ethernet + 2 usb-c (downgraded to usb2 — the mu has no spare usb3 host port, so they'd have to be usb2 anyway). hdmi and gbe were already on that edge so nothing long crosses.
 - battery bms board: like a macbook — a small board at the pack with the connector, protection fets, current shunts, fuel gauge. only pack terminals + i2c cross to the mainboard. the charger stays on the mainboard because it's the hinge of the whole power tree.
 - center mainboard: mu, m.2, ec, all the converters, battery charger, vsys.
the rule that kept me honest: nothing high-current crosses an fpc. no vsys, no vbus_raw, no pphv. i checked the current math — a full power split would need ~110 ffc pins of power and gnd return at 8.6a, which is just asking for voltage droop and heat. the only things crossing are the hub's one usb3 upstream pair, some i2c and irqs, hdmi/gbe pairs, and pack terminals.
the connectors stay exactly where they are today, the only electrical change is the two right-side usb-c ports become usb2. i'd rather have 5 usb3 ports that are actually good than 7 ports where half are running super-speed lanes across 300mm of fpc.
this is a big layout job — moving the hub and pd chain to the left board, redoing zones for 4 boards, three fpc connectors — but it fixes the actual problems (decoupling, hub fanout, respin cost) instead of papering over them.

mock up of the splits: 

# 2026-08-27: LattePanda MU power and ground routing

**Total time spent: 15 minutes**

wired all the gnd stitching vias to the lattepanda mu, and also the 12 volt net. also routed miscellaneous nets.


# 2026-07-02: initial project setup

**Total time spent: 5 hours**

started putting the ducktop2 design into a proper kicad project. this was the first saved version of the power and battery circuit and the embedded controller, including the generator code i had already been working on before setting up the repo.

the battery circuit at this point used a BQ76920 for the three-cell pack and a BQ25798 charger. i worked through the cell connections, current sensing, charge and discharge controls, and the smaller resistors and capacitors around them. a lot of the setup was getting the symbols, footprints and net labels into a form that could be reused across the project.

on the controller side, i added the STM32F407 and started assigning the keyboard and power-control connections. the power and controller sheets needed to agree on their shared signals, so i kept those connections named consistently and worked through the schematic errors. this gave me a starting project with the two main sheets and their supporting libraries together.

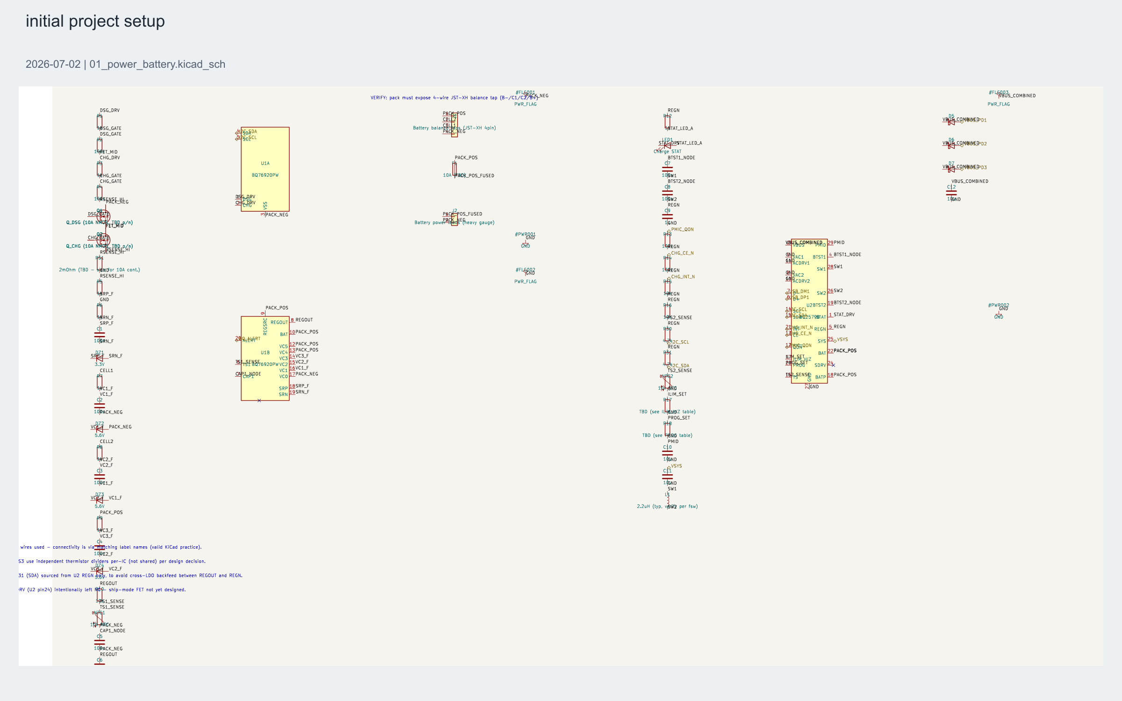
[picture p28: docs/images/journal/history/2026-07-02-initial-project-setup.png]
initial project setup


# 2026-07-08: deterministic schematics

**Total time spent: 5 hours 8 minutes**

saved a much more complete set of schematics. the project now included the carrier connections, usb-c, power inputs, hdmi, internal services, display interfaces, keyboard, radio and maker controller. i also brought in the custom symbols and footprints those sections needed, so the sheets could be regenerated together.

one annoying problem was that regenerating the same circuit kept changing the identifiers inside the kicad files. that made the differences huge even when very little had actually changed. i changed the generator to create repeatable identifiers from the sheet context and the order of its objects, instead of making new random ones each time.

that work didn't add another laptop feature, but it made the whole project easier to work on. i could save a schematic change and see the actual difference instead of sorting through hundreds of unrelated identifier changes. the saved set includes the generated sheets, the keyboard board and the library files together.

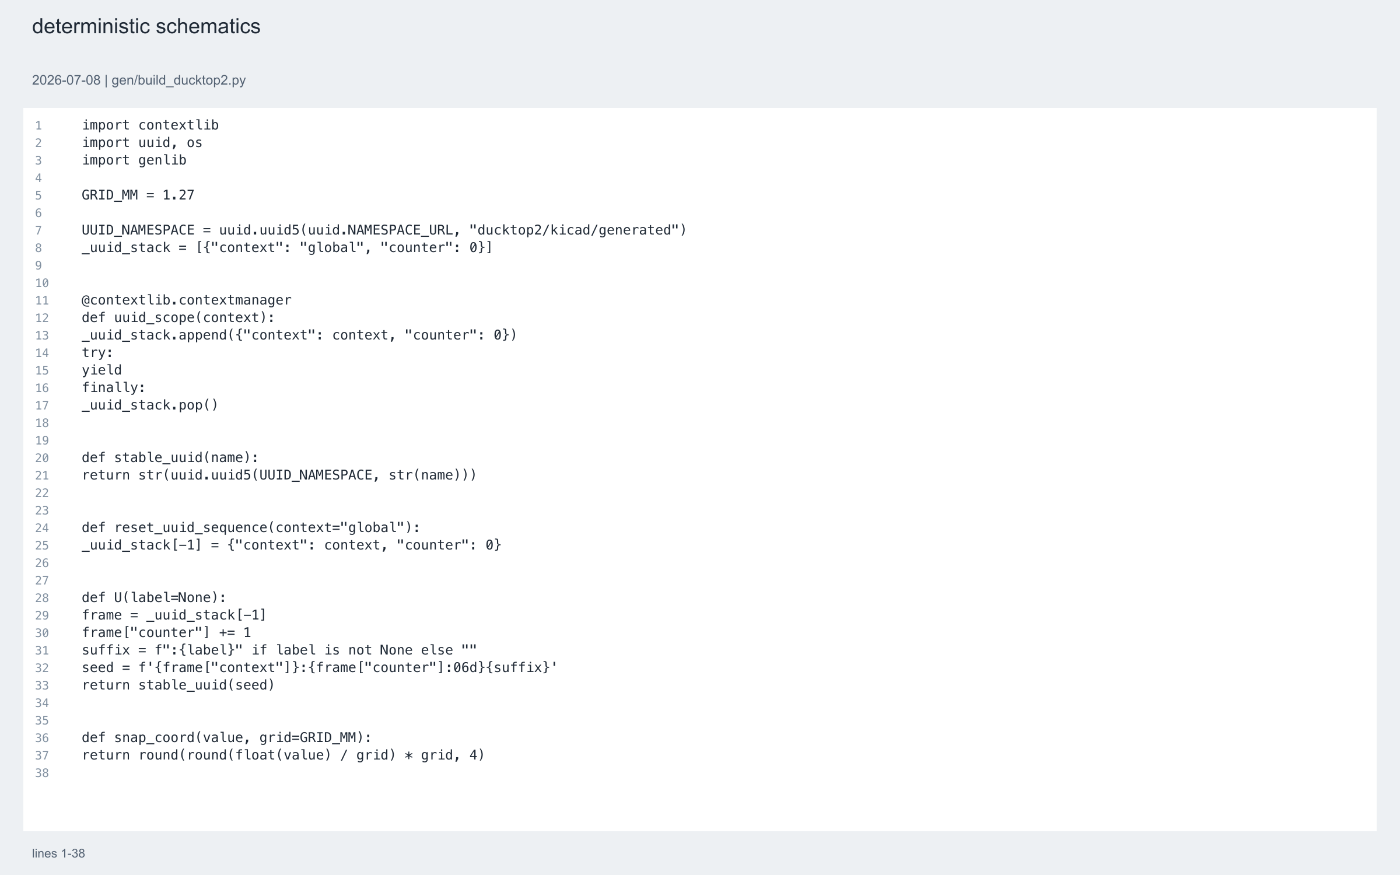
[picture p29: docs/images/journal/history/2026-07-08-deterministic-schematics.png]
deterministic schematics


# 2026-07-19: published the first full design

**Total time spent: 10 hours**

put the first full version of ducktop2 together in the public repo. until now, a lot of the work was spread across schematics, generators, board files and separate notes. i brought those into one project with the current hardware design, firmware, drawings and documentation.

the main board was six layers at this point, with its outline and 997 footprints matched to the schematic. it covered the LattePanda Mu, nvme and wifi sockets, usb-c, hdmi, ethernet, power conversion and the embedded controllers. the internal screen uses the Mu's eDP connector, so i documented that connection separately from the external hdmi port. the low-profile keyboard also had its own board and manufacturing files.

i added board renders and an architecture image so the project was understandable without opening every kicad sheet. i also wrote up how the hardware fits together, how to rebuild the schematics, and what the firmware is responsible for. that included the differences from ducktop1, where the separate computer and monitor left cables looping around the outside.

this was mostly about getting all the existing design work into a usable project, with the supporting files alongside it. the board renders show the placement i was working with then, before the later board split.

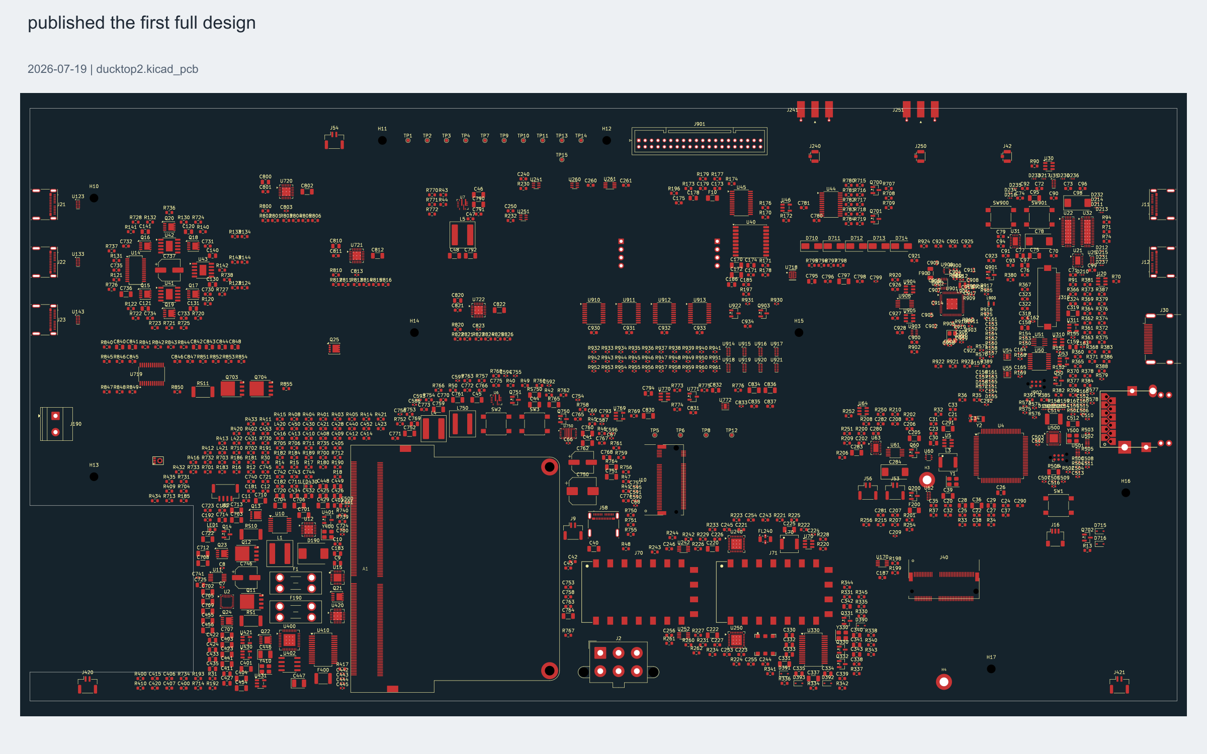
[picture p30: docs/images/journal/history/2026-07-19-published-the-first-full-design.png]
published the first full design


# 2026-07-19: updated the docs and readme

**Total time spent: 22 minutes**

cleaned up the readme and expanded the project documentation after publishing the design. i made the main page explain what ducktop2 is, how it differs from the first version, and where to find the hardware and build information.

i also added the MIT license and removed old pin-review details that no longer belonged in the main readme. the more detailed information stays in the relevant documents, so the front page is easier to read.

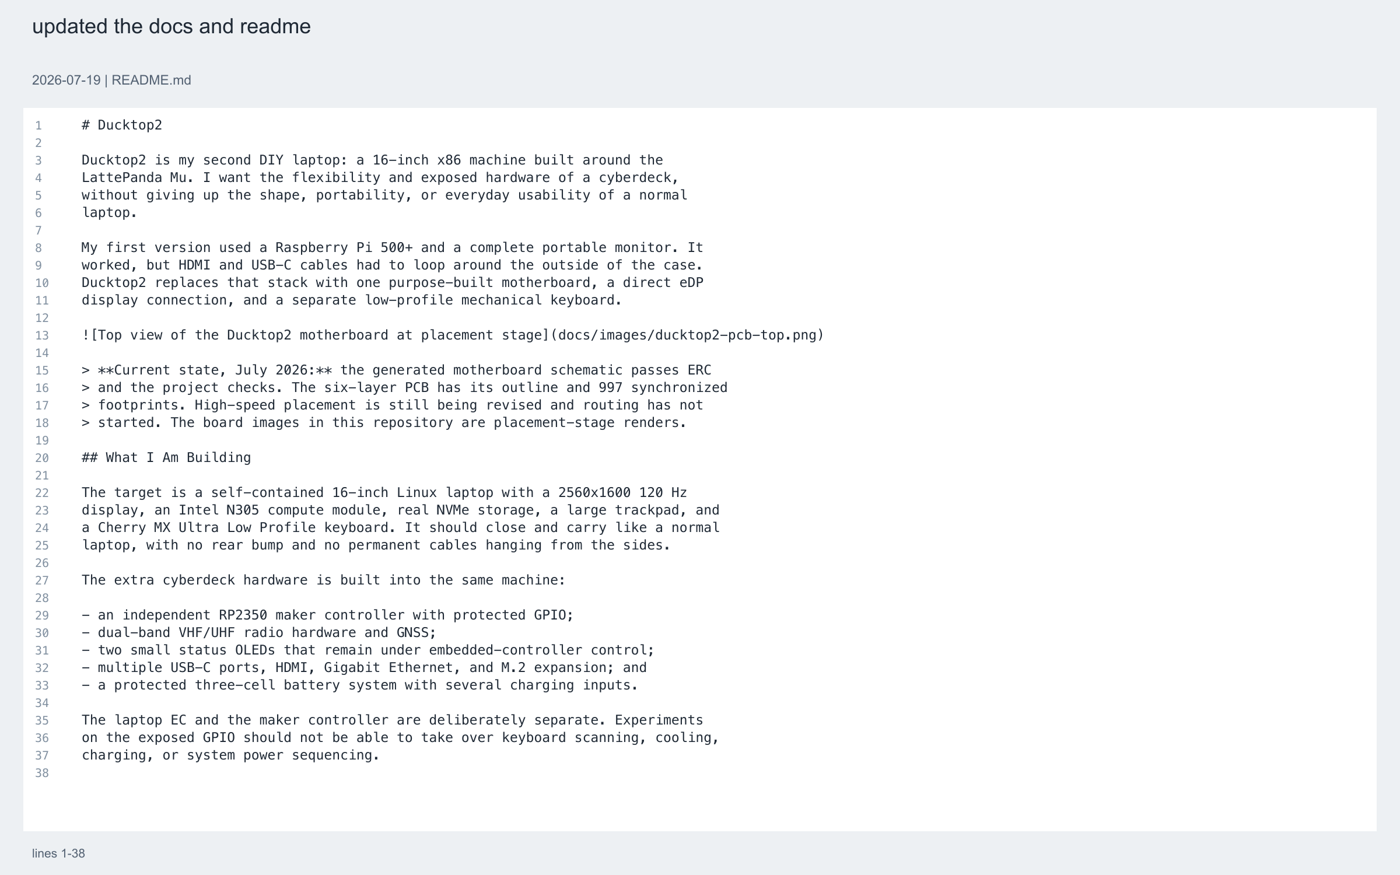
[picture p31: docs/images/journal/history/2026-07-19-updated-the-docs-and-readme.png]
updated the docs and readme


# 2026-07-20: split out the radio hardware and finished the usb-c policy

**Total time spent: 8 hours**

split the radio hardware onto its own removable daughterboard. i wanted the laptop to work normally even if the radio board was missing or needed changing, so the radio could no longer share essential parts of the main system audio path.

the daughterboard now holds the VHF and UHF modules, their filtering and antenna connections, the GNSS receiver and a separate USB audio codec. i kept the normal laptop audio and microphone on the main board. the connections between the boards needed their own power switching and signal controls, including USB, UART, I2C, push-to-talk and status lines. i made those interfaces start with the radio disabled, so an absent board would not affect startup.

i also finished the USB-C port policy. the ports accept 5 V, 9 V or 15 V power at up to 3 A, and can supply 5 V at 900 mA. the laptop uses them as USB host ports. i tied the data-path enable to the controller's role and attachment signals, so the USB connections don't turn on just because a charger is plugged in.

this touched the schematics, the new radio board, firmware and the port configuration files. i updated the documentation alongside those changes so the main-board and daughterboard interfaces stayed understandable.

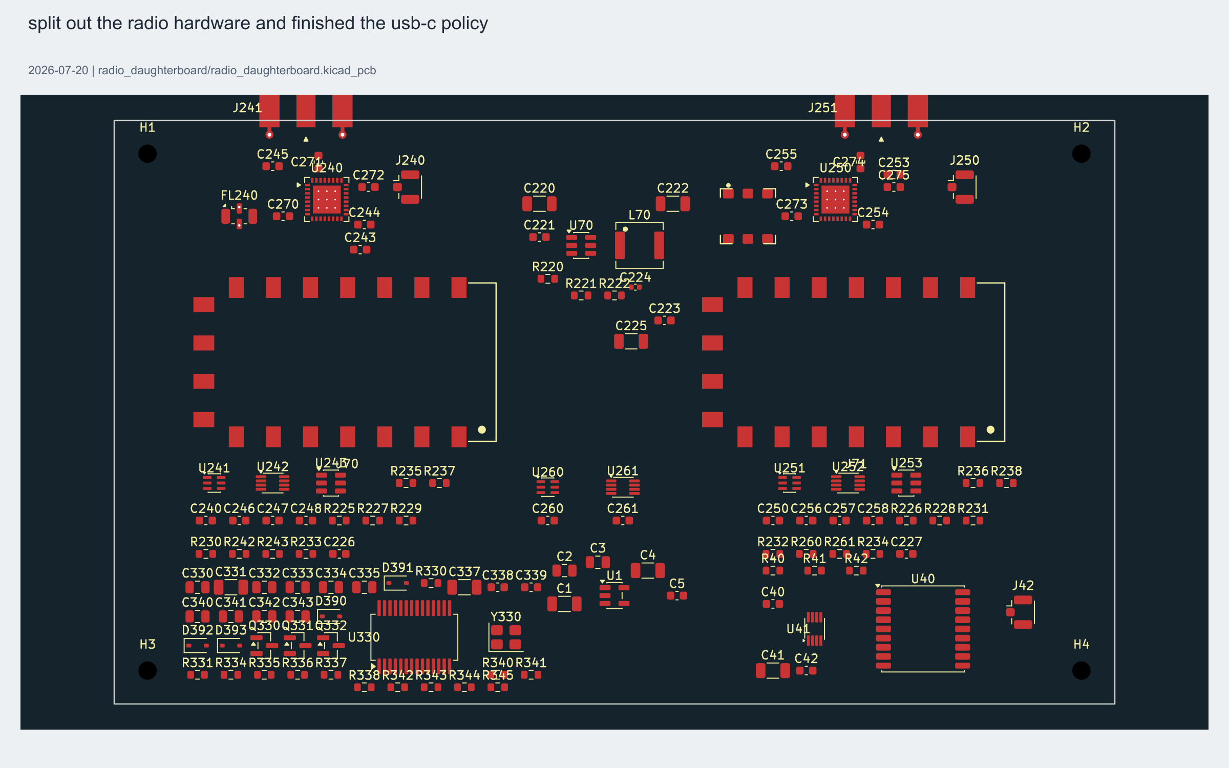
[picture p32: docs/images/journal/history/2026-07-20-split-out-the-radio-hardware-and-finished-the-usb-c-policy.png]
split out the radio hardware and finished the usb-c policy


# 2026-07-21: closed the pin reviews and moved the ac coupling caps

**Total time spent: 3 hours 25 minutes**

went through the pin connections again and finished the outstanding pin-by-pin review. i checked how the schematic signals lined up with the actual component pins and the board, rather than relying only on matching part names.

i also moved 23 high-speed coupling capacitors. their positions affect how the pairs can leave the source and reach their connectors, so i worked through the capacitor locations before carrying on with routing. i recorded the placement changes and the reasons for them, then updated the board and the review notes together. this was a cleanup of the existing interface circuits and their layout, with the capacitor positions being the main visible change.

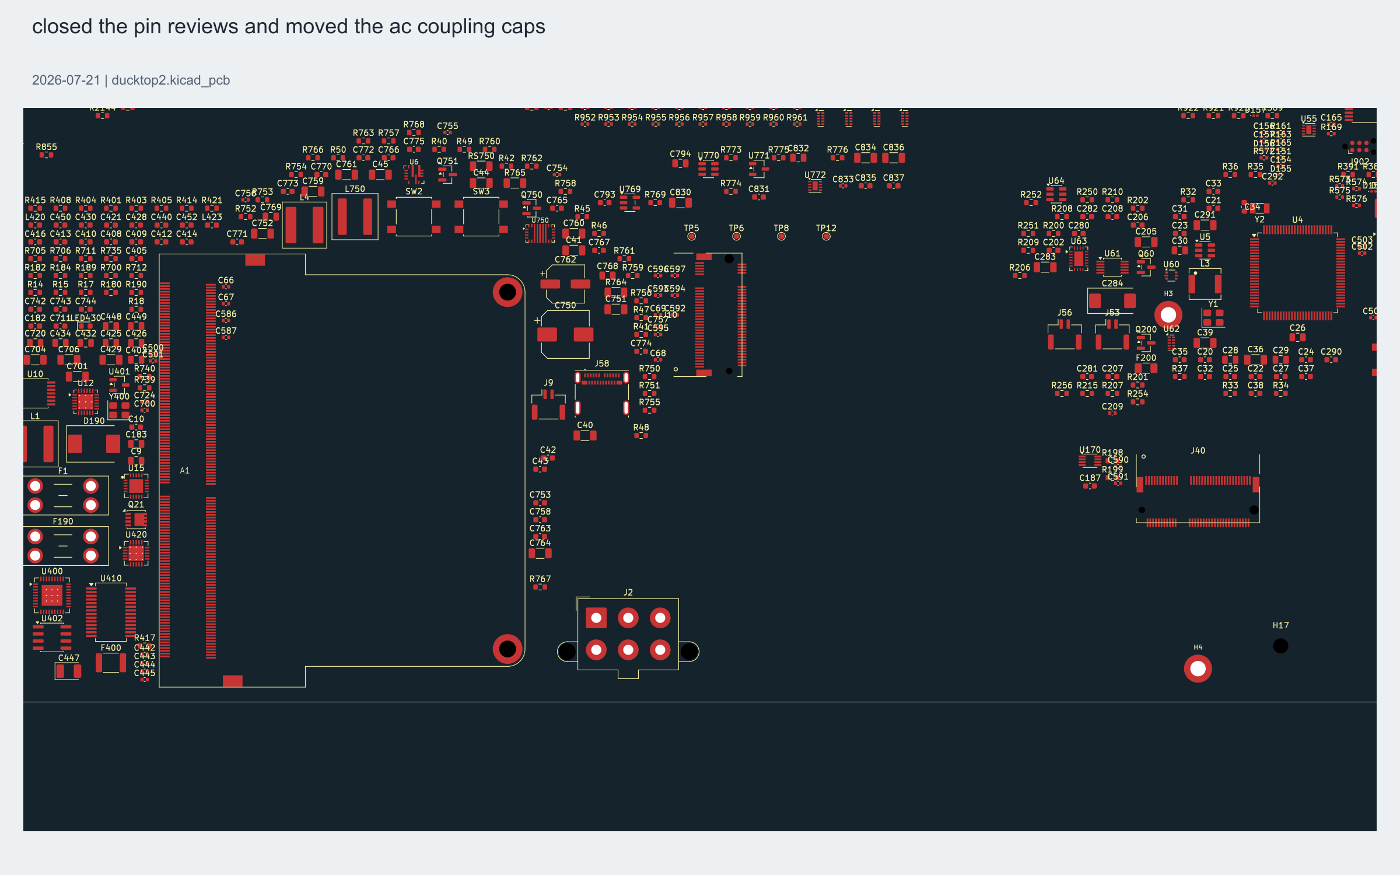
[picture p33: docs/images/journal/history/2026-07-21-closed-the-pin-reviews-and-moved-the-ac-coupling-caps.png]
closed the pin reviews and moved the ac coupling caps


# 2026-07-23: refreshed the published design

**Total time spent: 2 hours**

refreshed the published project with the board changes and new renders. the pictures in the readme needed to match the design i was actually working on, including the main board and the separate daughterboard work.

i also updated the keyboard stencil files and the printing setup for the full-board stencil. that meant keeping the model, process settings and description together instead of leaving the old stencil instructions beside newer files. the repo now showed the current design and the supporting manufacturing work in one place.

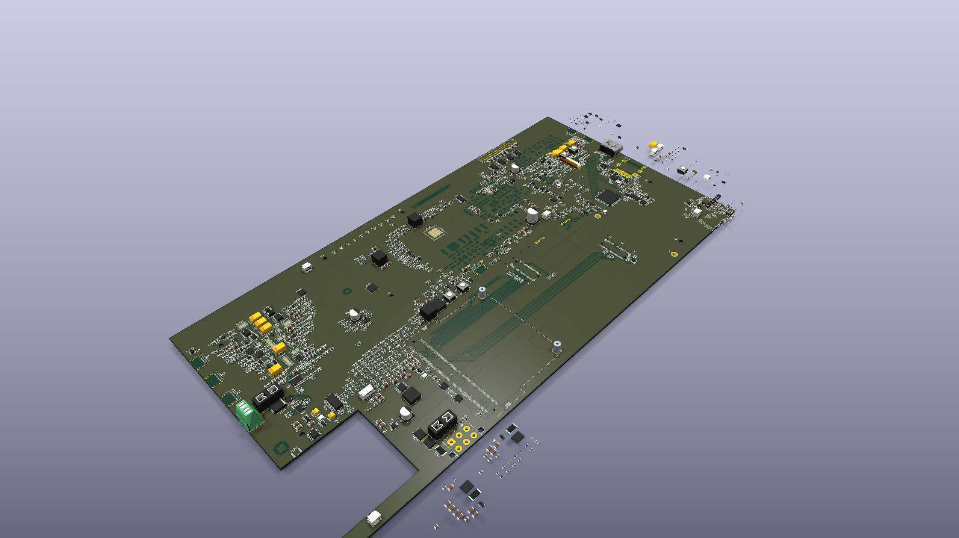
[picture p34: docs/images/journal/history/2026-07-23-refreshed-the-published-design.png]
refreshed the published design


# 2026-07-27: rewired the trackpad over usb2

**Total time spent: 8 hours**

rewired the trackpad to use a direct USB2 connection to the Mu. i worked through the whole connection, including the data pair, series resistors, ESD protection, switched power and the connector pin order. the schematic now describes a four-wire connection with ground, D-, D+ and power.

changing that circuit also meant checking the board that was already there. i found duplicate physical footprints and removed those, then fixed the copper conflict at J58 and the short around the two trackpad series resistors. i had to keep the schematic and PCB in agreement while doing that, because simply changing the labels would have left the old copper attached to the wrong things.

i also checked the surrounding USB and power connections and wrote down the issues i still had to work through. the trackpad's power control needs to agree with the laptop's sleep and shutdown behavior, and the connector must match the actual cable. those details were part of the interface work, not just the two USB signal wires.

the result was a corrected trackpad circuit and a cleanup of the footprint and copper problems exposed by the change. i kept the rest of the board's existing routing and outline while fixing this section.

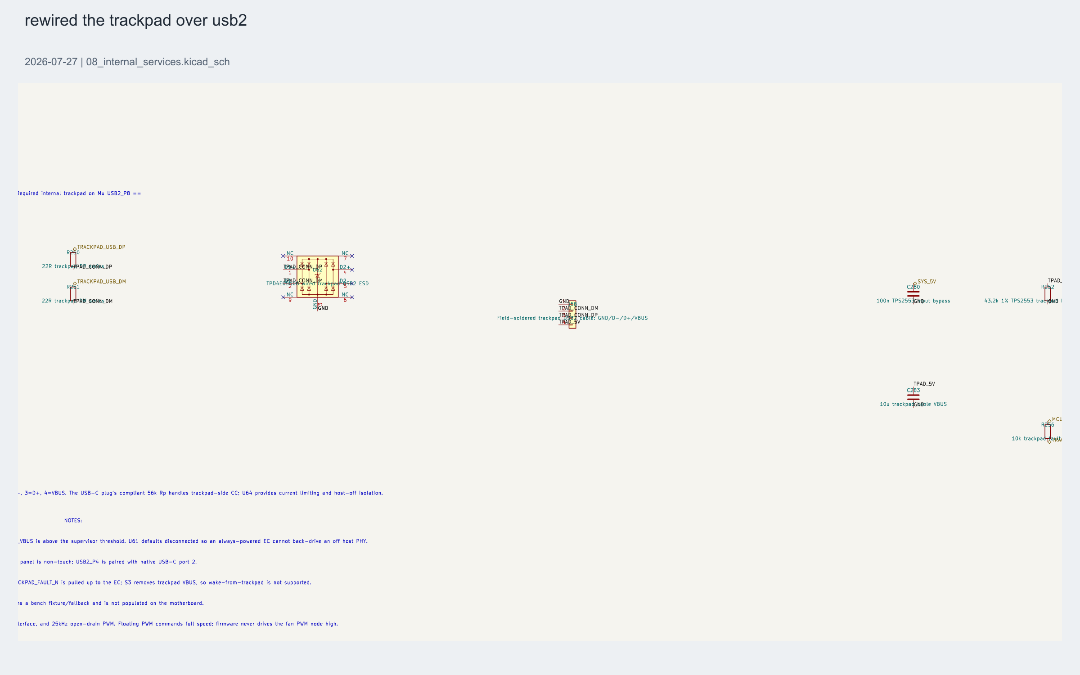
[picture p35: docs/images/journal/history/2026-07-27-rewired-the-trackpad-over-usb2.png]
rewired the trackpad over usb2


# 2026-07-28: filled in the bom and part numbers

**Total time spent: 2 hours 48 minutes**

worked through the bill of materials and filled in the actual ordering codes. a generic capacitor value or connector name isn't enough when it comes time to buy parts, so i went through the packages and manufacturer part numbers across the sheets.

i assigned 327 missing part numbers on the main design, bringing the list of procurement gaps down from 370 to 43. i also applied the part information to the radio and keyboard boards. while working on the keyboard, i added the Cherry MX ULP switch models so their bodies could be seen in the 3D view. the remaining gaps were kept in a separate list instead of disappearing into the larger BOM.

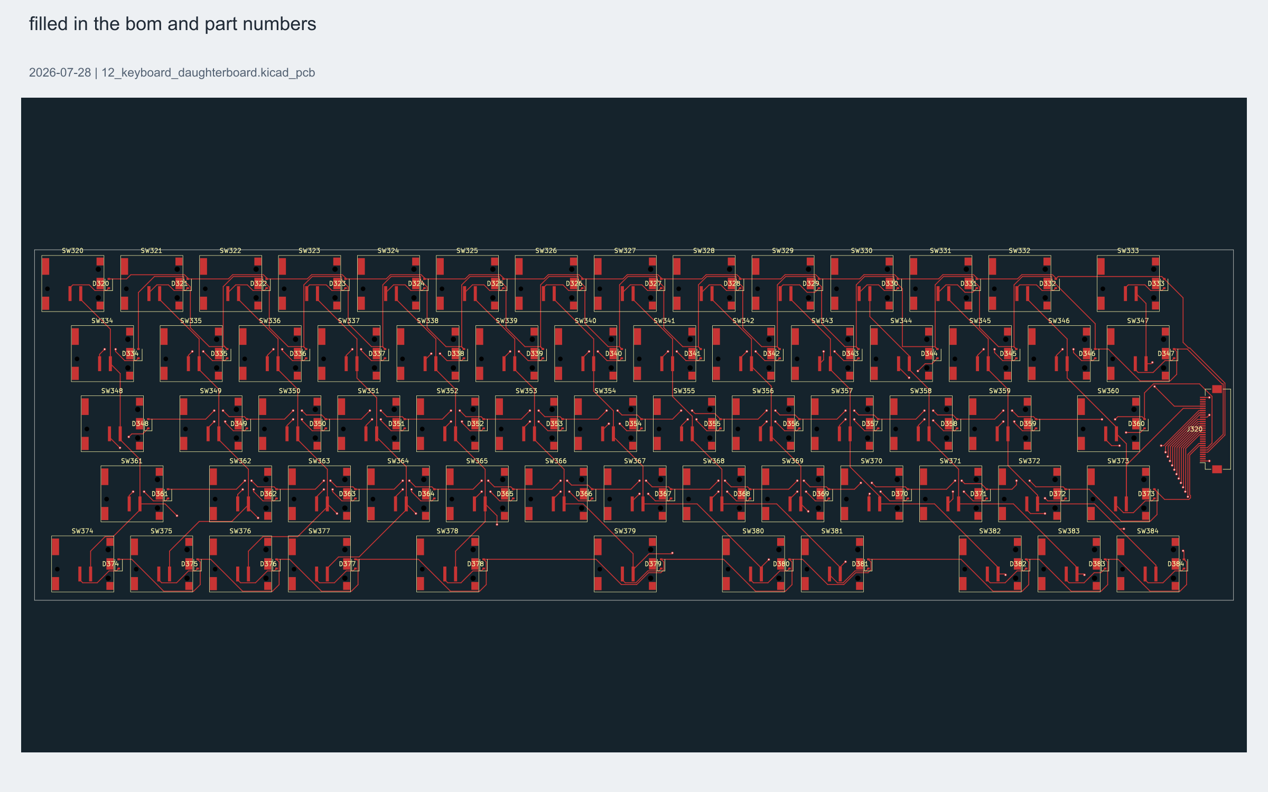
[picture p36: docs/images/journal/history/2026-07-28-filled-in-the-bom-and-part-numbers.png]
filled in the bom and part numbers


# 2026-07-28: added the remaining 3d models and cleaned up the radio board

**Total time spent: 1 hour 4 minutes**

added more of the missing 3D models, including the M.2 socket and parts on the main and radio boards. i fixed the model paths to use the project directory, so the views could work when the repo was moved to another computer.

i also corrected the side of the radio board's J1 connector. moving that mezzanine connector to the back meant moving its associated fanout and ground stitching too. i relocated the 77 fanout tracks and 42 stitching vias with it, then added the radio-board outline to the main board's drawing layer to show how they fit together.

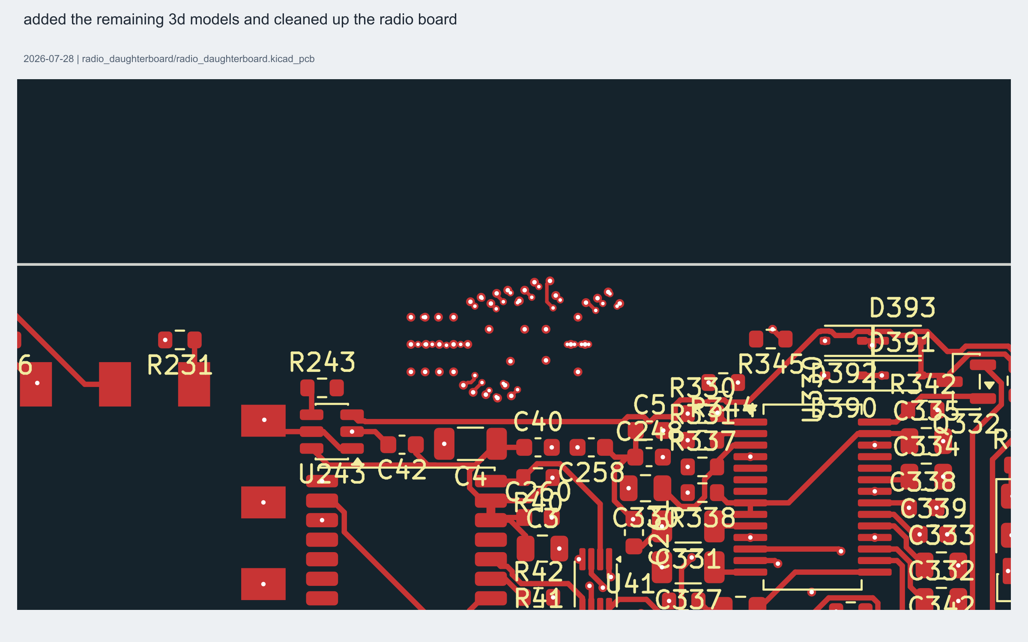
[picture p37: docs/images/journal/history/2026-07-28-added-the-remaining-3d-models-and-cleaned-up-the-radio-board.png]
added the remaining 3d models and cleaned up the radio board


# 2026-07-30: set up the fabrication stackup and ec tooling

**Total time spent: 10 hours**

worked on both the manufacturing setup and the first STM32 target build. i defined the six-layer stackup for NextPCB, then updated the board format and repaired the paths to its 3D models. i also worked on the power-loop placement scripts and the part-number assignments around those circuits.

on the firmware side, i set up the ARM toolchain and brought the embedded-controller code onto the STM32F407 target. that included the startup code, clock setup, millisecond tick, GPIO initialization and I2C driver. the controller needs its pins to start in sensible states before it begins switching power or talking to the other devices, so startup was a substantial part of this work.

the target build produced a firmware binary with the controller loop running at 50 Hz and I2C configured for the service devices. i wrote down the bus addresses and mux channels for the displays, USB-C controllers and other devices so the code and schematic used the same connections.

this session covered a lot of supporting work around the board: its manufacturing definition, model paths, power placement tools and the firmware foundation needed to bring it up later.

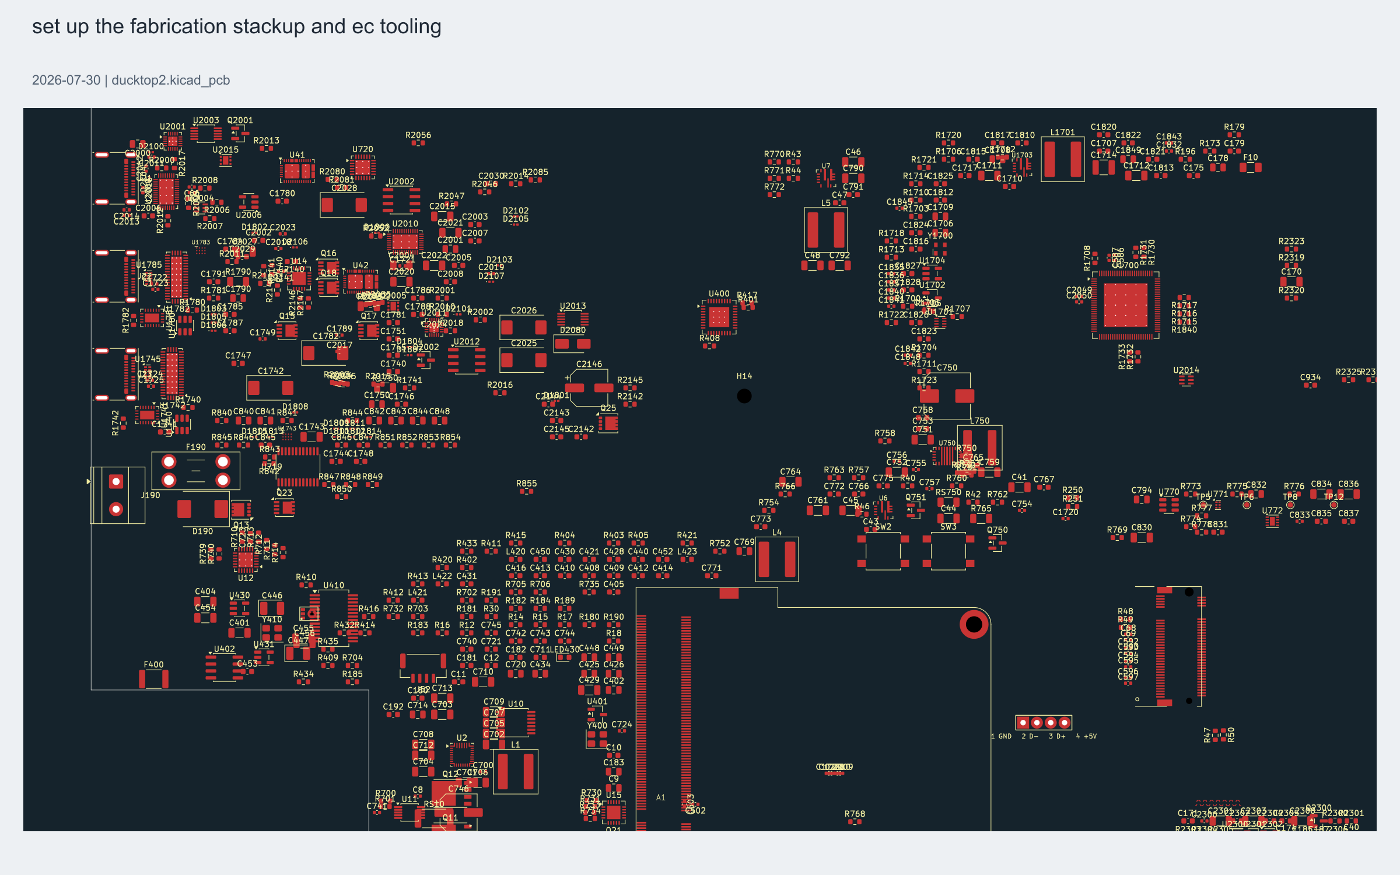
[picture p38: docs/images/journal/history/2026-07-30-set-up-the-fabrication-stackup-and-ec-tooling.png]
set up the fabrication stackup and ec tooling


# 2026-07-31: added and fixed the ec dfu path

**Total time spent: 5 hours 30 minutes**

added a way to program the embedded controller over USB. the circuit includes a BOOT0 button and a rear USB-C programming connection, with the USB protection and supporting parts on the internal-services sheet.

i then worked through the schematic errors caused by that addition. some of the references and annotations needed fixing so the programming section could live alongside the existing service circuits without collisions. i kept the programming connection separate from the normal host USB connections and updated the notes to explain how to enter the STM32 bootloader.

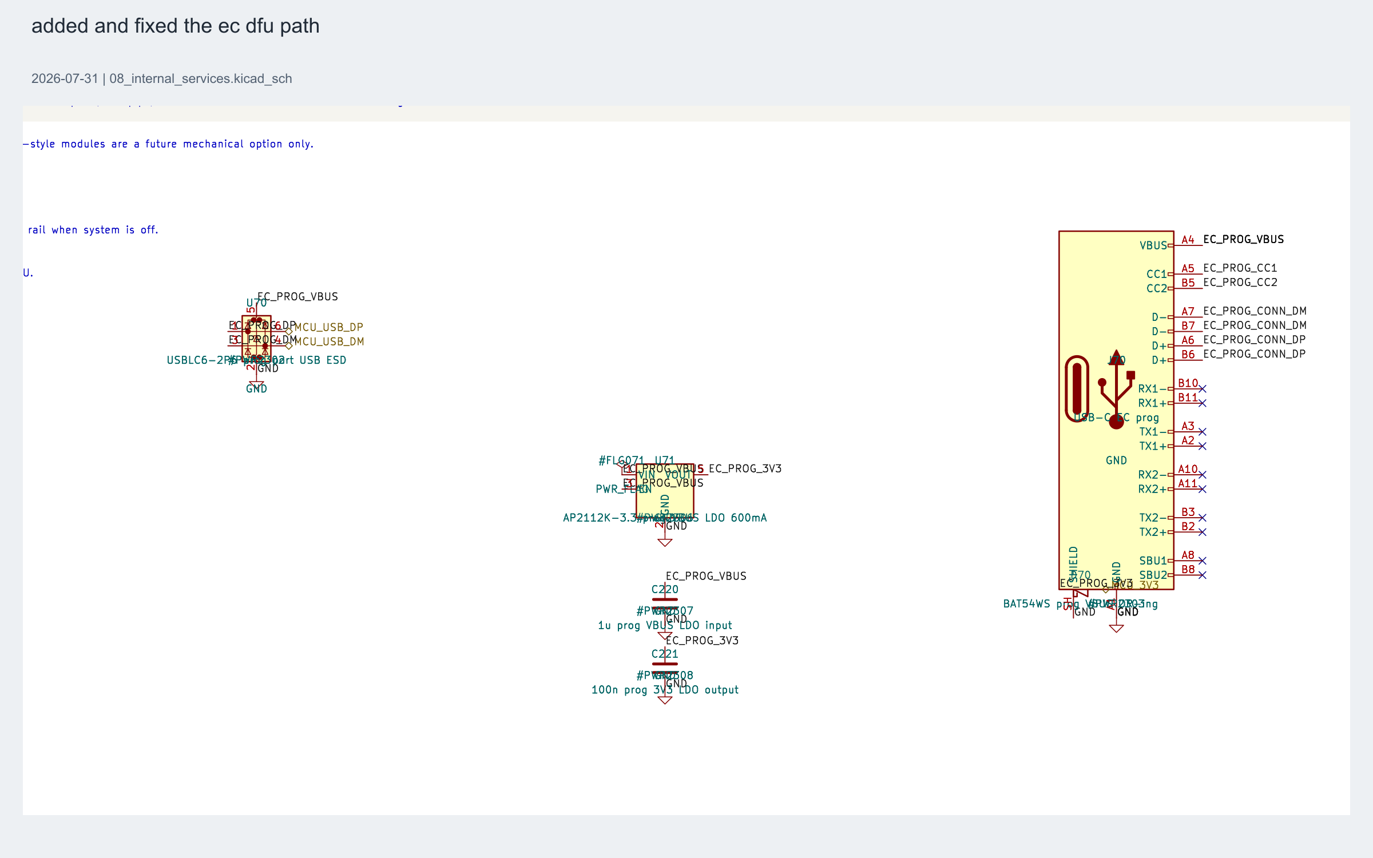
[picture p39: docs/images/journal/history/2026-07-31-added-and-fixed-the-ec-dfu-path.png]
added and fixed the ec dfu path


# 2026-07-31: wrote the behavior docs and headphone jack work

**Total time spent: 3 hours 48 minutes**

worked out how the laptop should behave in normal use, including the lid switch, charging inputs, keyboard, displays, cooling and audio. i wrote those decisions down so the firmware and hardware could follow the same behavior. the keyboard layout was already fixed because that board had been fabricated.

the main circuit change was adding the rear 3.5 mm headphone jack. i gave it plug detection so inserting headphones can mute the speakers, and added the headphone section to the system-audio sheet. that involved the jack connections and the control signals, not just putting another connector on the board.

i regenerated the affected schematic sheets and updated the audio and behavior documentation. i also added the keyboard image to the project so the chosen layout was visible alongside the rest of the design.

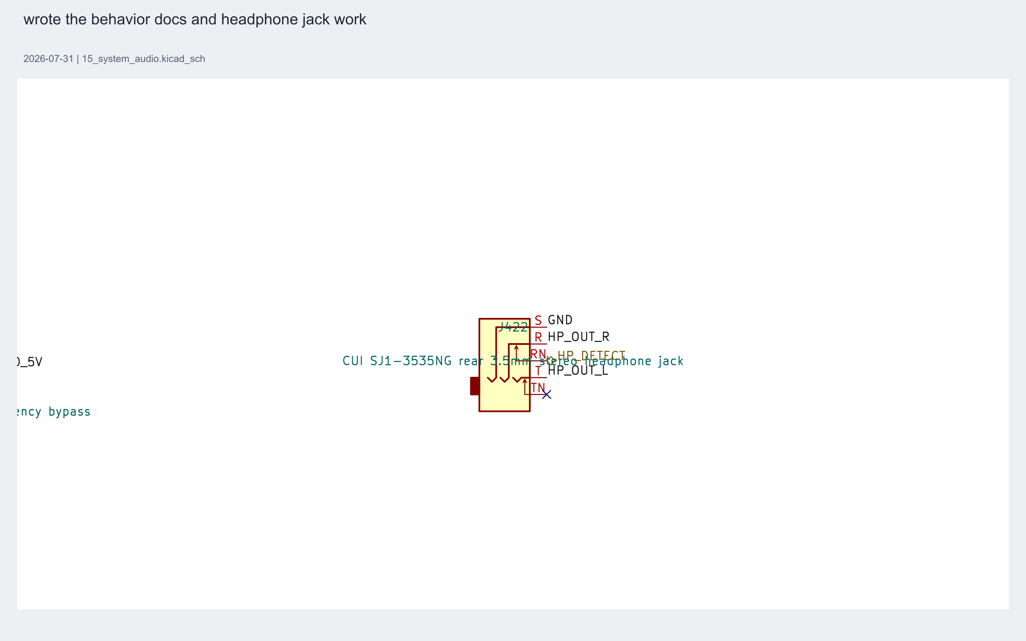
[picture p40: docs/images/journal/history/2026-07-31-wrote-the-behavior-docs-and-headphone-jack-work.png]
wrote the behavior docs and headphone jack work


# 2026-08-01: host-tested the ec behavior

**Total time spent: 2 hours 45 minutes**

worked on the controller behavior and tested it on the computer before connecting it to hardware. i added the keyboard Fn-layer mapping, fan policy, OLED status content, lid-switch debounce and battery state handling.

the battery code needed to distinguish between a missing pack, an unknown reading, charging, discharging and a full battery. i added tests around those states so a missing or invalid measurement would not be treated as a valid battery reading. the lid and keyboard work also needed debounce handling, while the OLED code needed a consistent way to turn the controller state into text for the displays.

i also wrote up the eMMC recovery and hibernation setup. this session was mainly firmware and behavior work: making the individual pieces testable and deciding what the laptop should do when its inputs change.

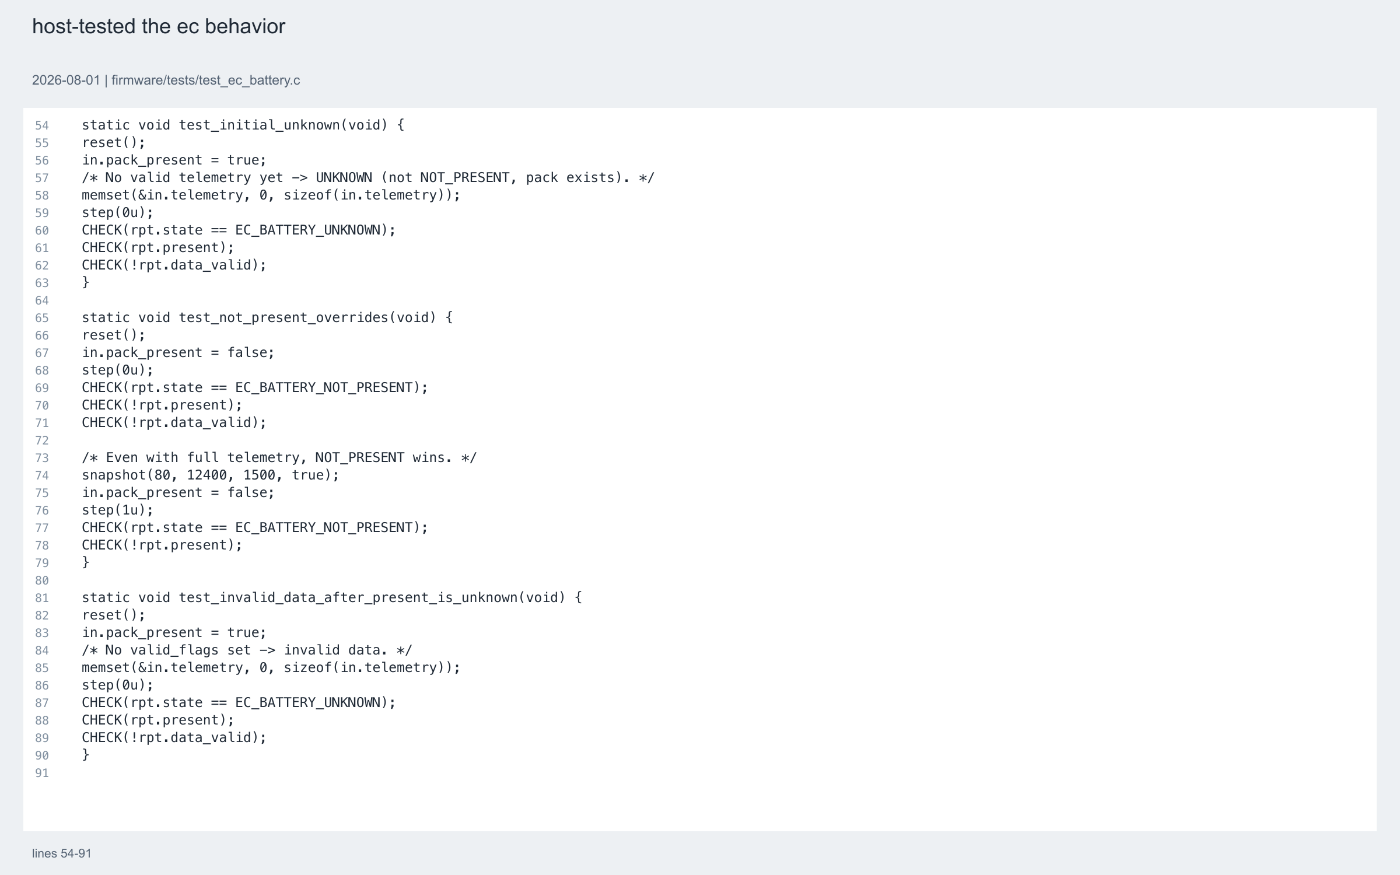
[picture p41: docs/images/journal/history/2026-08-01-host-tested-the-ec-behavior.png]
host-tested the ec behavior


# 2026-08-01: worked through the bom, impedance, and placement prep

**Total time spent: 4 hours 42 minutes**

continued the BOM and routing preparation. i brought the part-number information into the generator's catalog and worked through the remaining procurement entries, so regenerating the schematics would keep the selected parts instead of losing that information.

i also calculated starting widths and gaps for the high-speed traces and added the corresponding net classes and board rules. those values needed to go with the intended layer stack, so i wrote down the impedance calculations and the pair-length budgets alongside the routing plan.

the other major part was placement cleanup. i added a tool to identify overlapping footprints and pads, then a second tool to make small, controlled moves of the crowded passive parts. i used the resulting reports to separate simple spacing problems from the larger components that needed a deliberate placement decision. that gave me a clearer list of what to move before spending time routing around it.

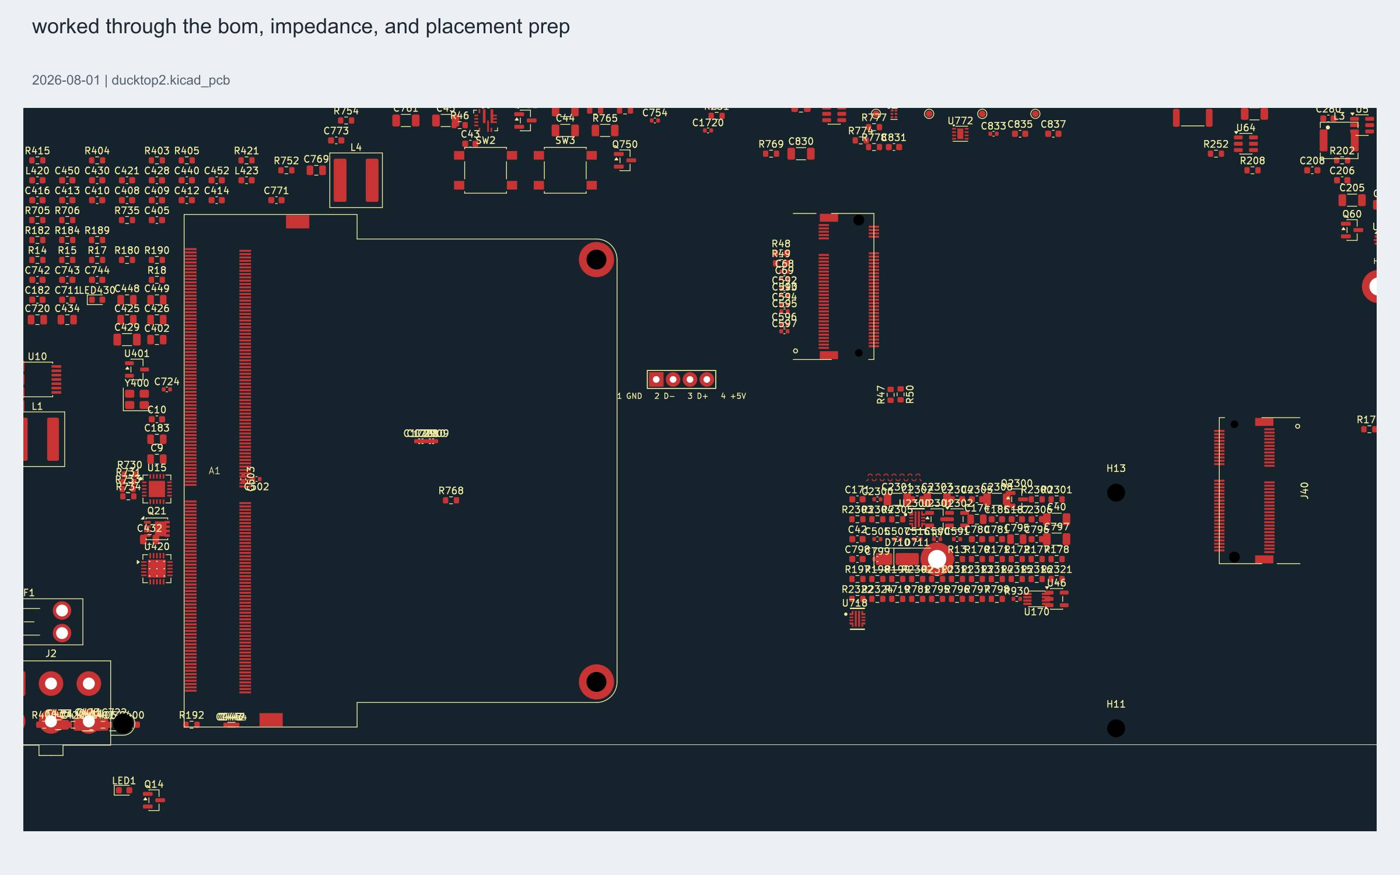
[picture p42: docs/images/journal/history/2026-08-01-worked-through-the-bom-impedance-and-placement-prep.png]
worked through the bom, impedance, and placement prep


# 2026-08-01: built the ec driver and keyboard path

**Total time spent: 3 hours 34 minutes**

connected more of the controller's firmware to its actual devices. i added drivers for the BQ25798 charger and BQ34Z100 fuel gauge, including register reads, setting limits and reading the settings back. i used a mock I2C bus to exercise the transaction handling without needing a populated board.

i also built the keyboard path. that included scanning the matrix, debouncing the keys, applying the keymap and sending USB HID reports to the host. the scan code and USB descriptors needed to agree with the keyboard behavior i had already written, so i added tests around those pieces as well.

alongside that, i worked through the fan calculations and the code that connects device readings to the controller's decisions. i also checked the microphone placement and the trackpad overlap with the battery area. the firmware could now do more than calculate a policy; it had the driver and input code needed to communicate with the hardware.

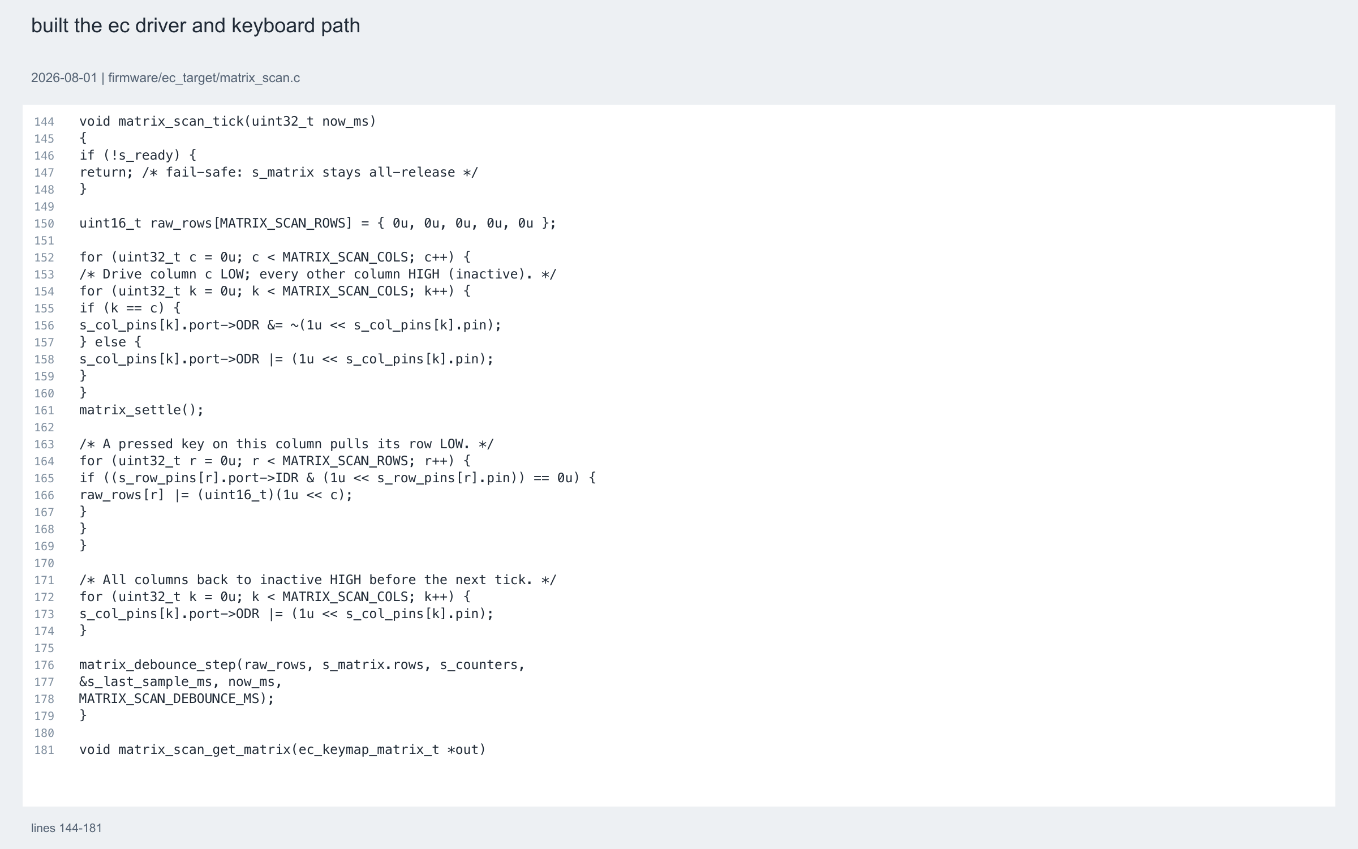
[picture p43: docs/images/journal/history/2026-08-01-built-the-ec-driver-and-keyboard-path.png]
built the ec driver and keyboard path


# 2026-08-01: added the headphone jack and cleaned up placement

**Total time spent: 1 hour 12 minutes**

brought the headphone-jack parts onto the PCB and continued sorting out placement collisions. eleven audio-section footprints needed to be added to match the new schematic.

i ran two more passes over the crowded passive parts, moving 190 parts in one pass and another 59 in the next. the reported pad shorts dropped from 199 to 54 across those passes. i kept a separate list of the larger components that needed manual placement decisions.

i also added the first ground planes, power islands and mechanical keepouts, and corrected the minimum through-hole drill setting to match the manufacturer's 0.2 mm capability.

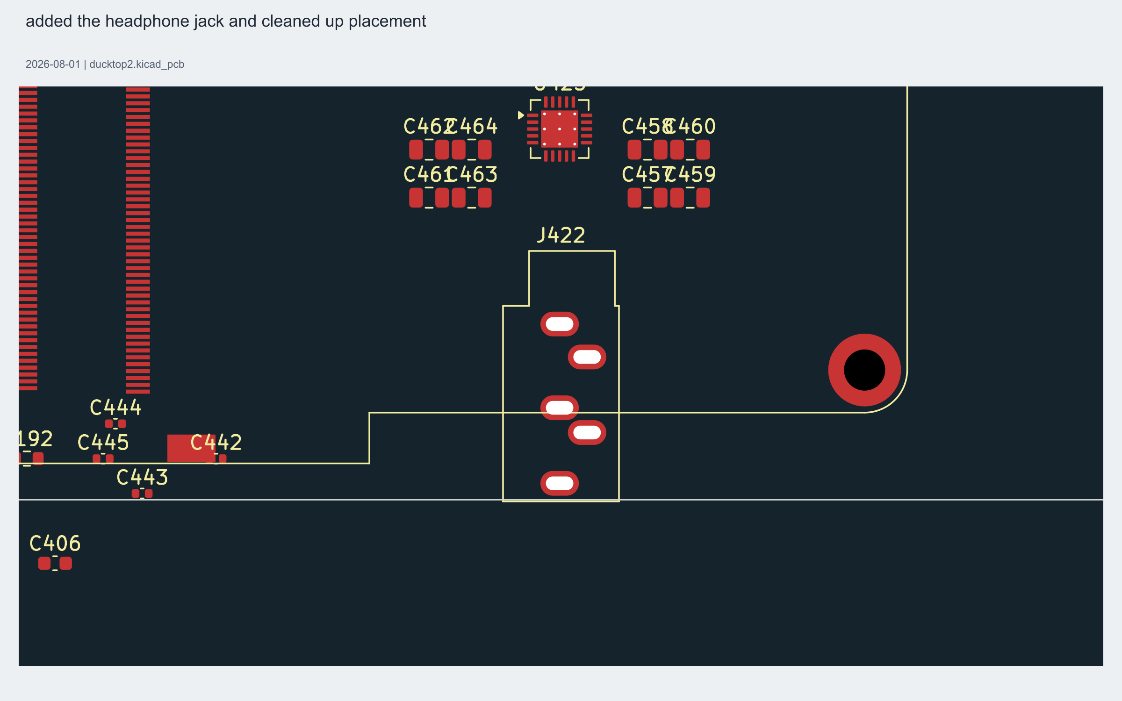
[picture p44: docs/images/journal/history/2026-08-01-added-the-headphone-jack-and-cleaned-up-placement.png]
added the headphone jack and cleaned up placement


# 2026-08-01: tightened the floorplan and placement checks

**Total time spent: 1 hour 27 minutes**

went back to the floorplan and made it more useful for placement. i added the larger parts and OLED modules to the planner, checked their sizes, and updated the script that transfers the chosen positions onto the PCB.

i also fixed the placement tool's handling of the board boundary. some capacitors had been pushed outside the outline during earlier moves, so i brought those back and made the boundary part of the placement checks. i updated the hinge keepouts to the Framework hinge dimensions and applied the chosen floorplan with the main-board origin at zero. this tied the drawing and the actual board coordinates together more clearly.

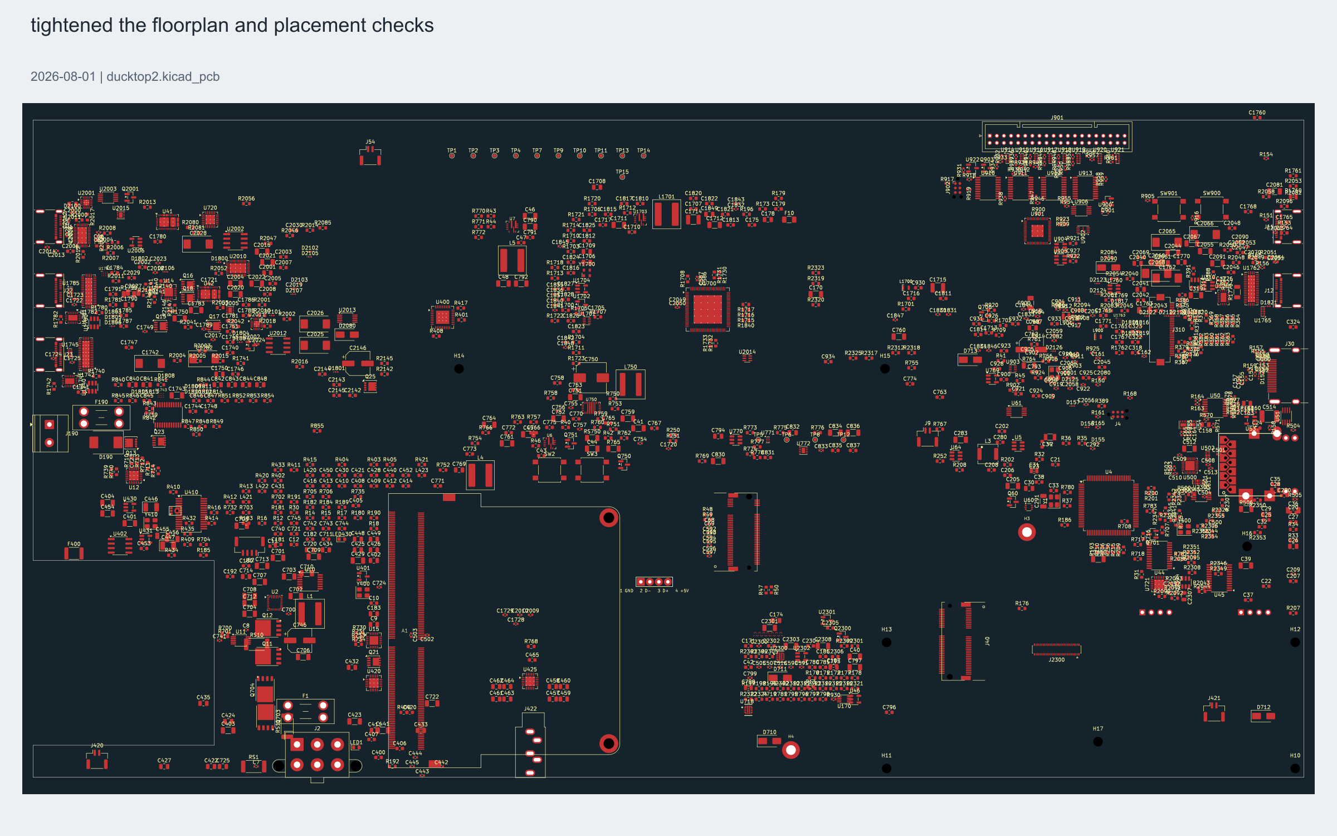
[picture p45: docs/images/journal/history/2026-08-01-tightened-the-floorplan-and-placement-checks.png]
tightened the floorplan and placement checks


# 2026-08-01: applied the floorplan and changed the radio connector

**Total time spent: 2 hours 51 minutes**

applied the revised floorplan to the main board, including moving the Mu toward the upper-middle area. i then worked through the outline, zones and keepouts around the new positions. i added a board-boundary check to the placement script so another layout change could not silently leave parts outside the PCB.

i also changed the radio connection from the DF40 mezzanine connector to a 30-pin FH12 FFC connector. that required updating the connector footprint and its place in the layout. after applying the next floorplan revision, i ran another collision cleanup pass and reduced the reported shorts from 90 to 76. there was still placement work to do, but the floorplan and radio connection were now much closer to the arrangement i wanted.

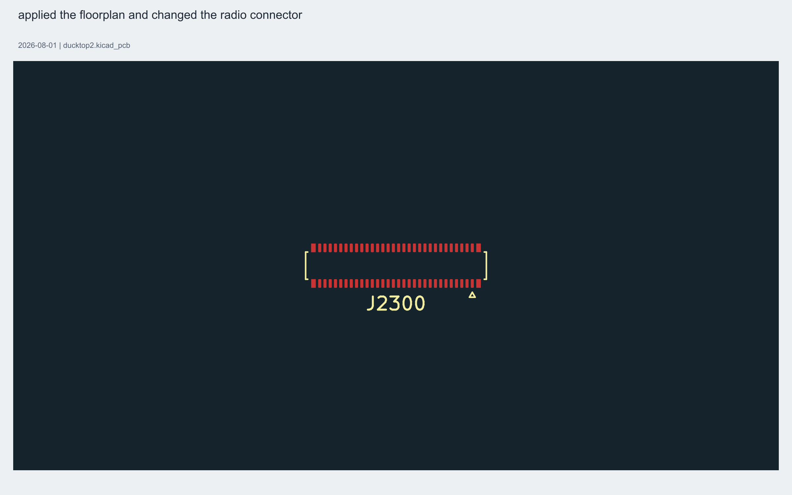
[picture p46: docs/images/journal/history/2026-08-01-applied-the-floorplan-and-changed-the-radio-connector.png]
applied the floorplan and changed the radio connector


# 2026-08-02: cleaned up and restored the board geometry

**Total time spent: 1 hour 16 minutes**

cleaned up the board outline and drawing guides, including removing stale guide shapes, clipping the zones and restoring the radio connector's position.

the cleanup went through a couple of revisions. i changed the outline to a plain rectangle and cleared the old guides, then decided to restore the earlier board geometry instead. i brought back that version's edges, guides and zones so the board was left in a known layout. this entry includes that back-and-forth, rather than treating the first cleanup as the final result.

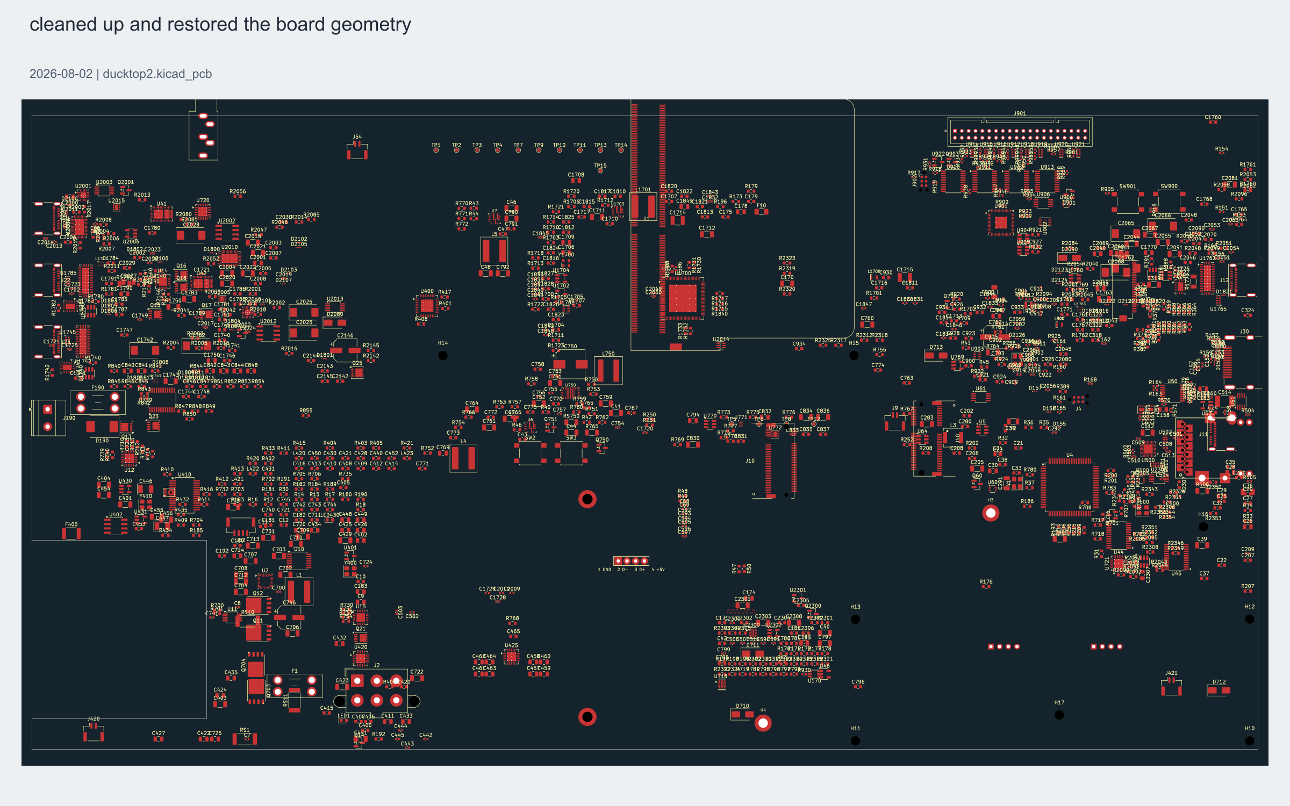
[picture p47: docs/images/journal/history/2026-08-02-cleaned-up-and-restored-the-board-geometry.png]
cleaned up and restored the board geometry


# 2026-08-09: repaired the board outline and guides

**Total time spent: 2 hours 44 minutes**

worked on the board outline and the placement guides again. the intended outline was a plain 358 by 185 mm rectangle, but old notch segments were still mixed into the edge drawing. i removed those pieces and replaced them with the correct straight edge.

i also fixed duplicated identifiers on the outline segments. that was separate from how the board looked on screen, but it mattered when loading and checking the file. after fixing the edges, i regenerated the drawing guides with unique identifiers and corrected the radio connector position. the saved file now had the intended outline instead of several different versions of it overlapping.

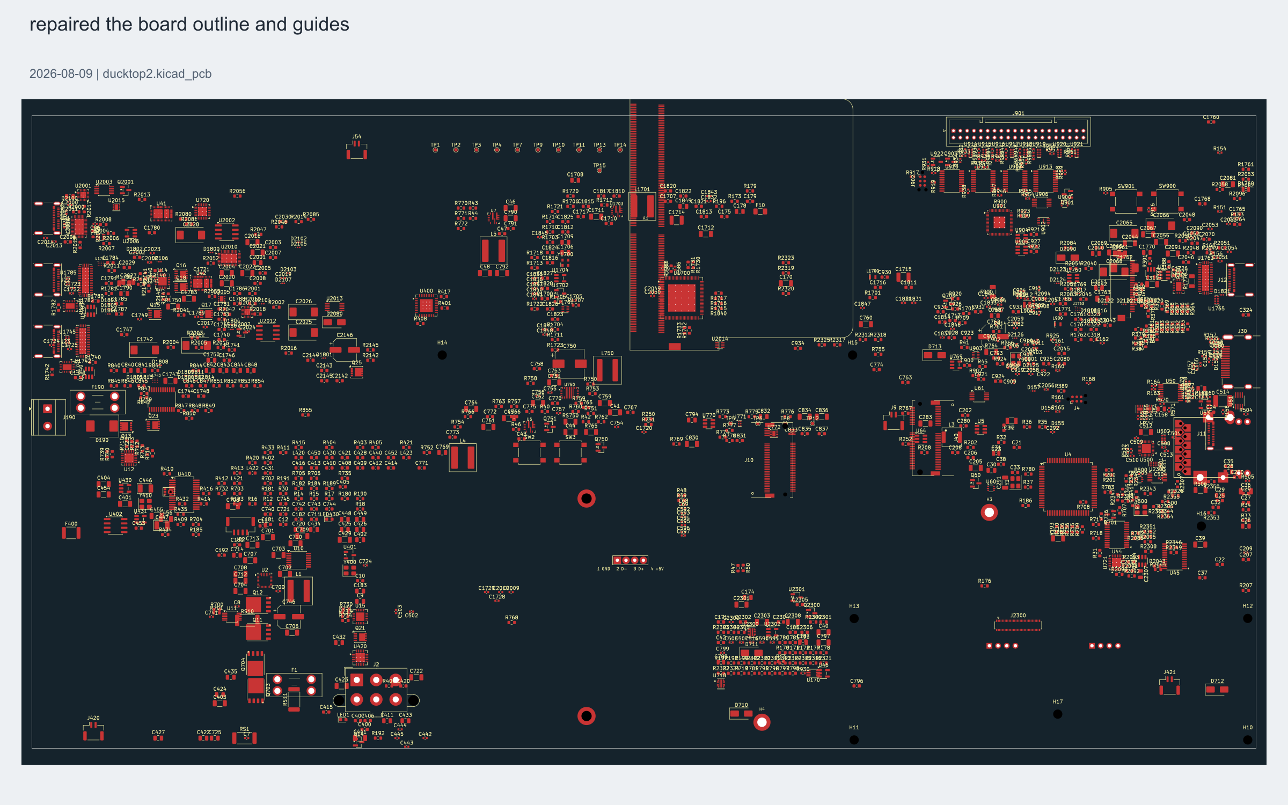
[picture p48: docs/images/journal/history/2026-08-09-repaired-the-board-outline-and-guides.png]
repaired the board outline and guides


# 2026-08-09: removed the stale notch and restored the radio connector

**Total time spent: 1 hour 11 minutes**

removed the remaining old notch from the left side of the board. it was a leftover from an earlier layout and no longer belonged in the 358 by 185 mm outline.

i also restored the radio connector to its on-board position at 288.4, 149.1 mm. the outline and connector had both been affected by the earlier cleanup, so i fixed them together and saved that arrangement before continuing with the rest of the placement.

removed the stale notch and restored the radio connector

# 2026-08-11: fixed placement collisions and port layout

**Total time spent: 6 hours 13 minutes**

spent this session cleaning up the main-board placement and getting the external ports into the right places. the floorplan changes had left overlapping pads and several connectors whose positions did not match the intended case openings.

i applied the updated floorplan and worked through the pad collisions. i then adjusted the ports individually, including the two left-side connector heights and the M.2 card arrangement. changing a socket position also changes the space its card needs, so i checked those as assemblies instead of treating the connector body as the whole part.

i rebuilt the drawing guides from the actual footprint bounds so they would follow the board rather than show old positions. that was useful for comparing the connector locations against the floorplan and seeing where the larger parts were still crowding one another.

the work was mostly repeated placement adjustments and checking the result. i saved the corrected board, floorplan and guides together so the next placement changes could start from the same arrangement.

fixed placement collisions and port layout

# 2026-08-12: fixed the outline, guides, and radio ffc

**Total time spent: 2 hours 22 minutes**

added the recess for the mid-mount ethernet jack and checked how the surrounding ports and M.2 slots lined up with the board. that connector needs room in the edge itself, so a rectangular outline was no longer enough in that area.

i also worked through the remaining reported shorts, bringing that group from 49 down to zero, and cleaned up the old drawing guides. i removed 67 stale guide blocks and rebuilt 21 aligned pairs from the current placement.

finally, i replaced the radio connector with the FH12-30S FFC footprint and removed 52 dangling route stubs left around the old connection. the outline, guides and connector changes are all saved in this version.

fixed the outline, guides, and radio ffc

# 2026-08-12: worked through the f1-f9 placement review

**Total time spent: 2 hours 20 minutes**

worked through the placement problems found in the board review. the biggest one was the Mu socket: part of its footprint and the matching standoff positions did not fit the board properly. i moved the module south and moved its two supports with it, so the mounting arrangement followed the module instead of staying behind at its old position.

i cleared nearby control parts from the Wi-Fi socket and moved the keyboard FFC series resistors away from its pad field. i also brought the radio connector fully onto the board, corrected its part information, and moved the ethernet crystal next to its controller.

the rest of the session covered the mounting pattern, external clearances and the real impedance net classes. i updated the mechanical notes to match the resulting board, including the ethernet recess, and wrote down the final changes so i could continue from the corrected positions.

worked through the f1-f9 placement review

# 2026-08-13: cleaned placement and started the independent review

**Total time spent: 4 hours 12 minutes**

continued cleaning up the placement, then took a closer look at the electrical connections behind it. i worked through the placement-related DRC findings and got the board down to 186 reported violations at that point.

the radio connector turned out to need more than a spacing fix. checking its pad numbers against the schematic showed mismatches across 26 pads, so i recorded the affected connections before changing it again. i also revisited some earlier reported problems and separated the actual connector issue from the ones that did not apply.

this changed what i needed to do next. a connector can look correctly placed while still assigning the wrong signal to a contact, so i checked the pin mapping as well as the physical fit. i kept the layout cleanup and the remaining connector work written down together.

cleaned placement and started the independent review

# 2026-08-13: fixed j2300 and closed the electronics review

**Total time spent: 4 hours 25 minutes**

fixed the radio connector's pin mapping and worked through more of the board issues. i replaced J2300 with the FH12-30S connection and synchronized all 30 contacts with the schematic, then checked the resulting board assignments.

i also completed the controller's USB programming connection and changed the radio-board power arrangement. other corrections covered the fan tachometer signal, the Mu sleep signal and the serial interface. these were separate connections that needed checking across the schematic, controller assignments and board.

on the mechanical side, i corrected the Mu mounting arrangement and the keyboard FFC placement. the module socket and its standoffs now moved together, and the keyboard connector had the clearance it needed. i updated the board, part lists and notes to match these changes, including the corrected radio and programming connectors.

fixed j2300 and closed the electronics review

# 2026-08-13: finished the mechanical review and moved to eight layers

**Total time spent: 3 hours 5 minutes**

worked through the case layout and the vertical space inside the laptop. my first arrangement put the batteries and trackpad in separate front-to-back bands, which made the base much deeper than it needed to be. i changed the plan so the trackpad sits above the battery row, with support and separation between them. that brought the planned footprint back to 358 by 248 mm.

i also moved the main board from six layers to eight. i kept the impedance requirements with the new stackup and planned where the signal, ground and power layers would go.

for the power layer, i started mapping the individual supply islands rather than treating it as one large plane. the mechanical drawing and the layer plan were both updated for this version of the laptop.

finished the mechanical review and moved to eight layers

# 2026-08-14: did the pre-routing audits

**Total time spent: 2 hours**

checked several things before committing more time to routing. i looked at how the Mu socket's pads could escape onto the signal layers, checked the available power against the loads, and went through the footprints for the parts that were easy to get wrong.

i wrote the results into the routing and power notes, including the constraints around the Mu fanout. this was mostly checking the design and deciding how to approach those areas, rather than adding more tracks to the board.

did the pre-routing audits

# 2026-08-23: prepared the nvme, rtc, and nextpcb submission

**Total time spent: 3 hours 25 minutes**

worked on the nvme supply, the real-time clock power and the information for NextPCB. i added more power headroom for the SSD and changed the RTC supply to use the battery pack, removing the separate coin cell from the design.

i then put together the eight-layer manufacturing details: the proposed stackup, copper, board thickness, via sizes and the impedance requirements. i compared the board's design rules with the manufacturer's capabilities so differences were written down before sending the files for review.

i also set the solder mask to black, with matte preferred, and checked the planned mask spacing against the stated manufacturing limit. the resulting files describe the actual board and the fabrication choices i wanted NextPCB to check.

prepared the nvme, rtc, and nextpcb submission

# 2026-08-24: closed phase 1 and approved the stackup

**Total time spent: 3 hours 30 minutes**

finished another pass over the board rules and manufacturing setup. i went through the fabrication limits, the thermal and routing plans, and the silkscreen, then checked the saved design against the information in those documents.

that pass turned up twelve outdated checks and four board problems that needed correcting. i fixed those before applying the manufacturer's impedance values. the trace widths and pair gaps needed to come from the approved stackup rather than remain at the earlier estimates.

i saved NextPCB's supplied geometry in the project settings and updated the stackup record. this brought the board rules, routing notes and manufacturing information together around the same layer construction.

closed phase 1 and approved the stackup

# 2026-08-24: fixed the radio, usb-a, and placement updates

**Total time spent: 2 hours 40 minutes**

updated the radio-board footprint in the floorplan and worked on the spare USB-A ports. the radio section now used the intended 160 by 110 mm outline with four M2 mounting points in the mechanical drawing.

i added the USB-A connections on the hub's spare ports, then placed the new parts and matched the board to the schematic. i also saved the connector and capacitor positions i had adjusted in KiCad, including the programming port, AUX input and right-side USB connector.

after those changes, i regenerated the schematic sheets together so the files reflected the current USB-A and placement work. this session was mainly getting the added ports and the physical layout to agree.

fixed the radio, usb-a, and placement updates

# 2026-08-24: finished the usb-a routing prep and power zones

**Total time spent: 4 hours 33 minutes**

worked on the USB-A section and the power copper around the updated placement. i cleaned up the port cluster and wrote out how its signal pairs and supporting connections should reach the hub. the USB3 port uses the hub's SuperSpeed connection, while the other added port uses USB2.

i connected the USB3-A port's high-speed nets and grounded its shield, then updated the net classes for those signals. i also fixed the mounting pattern into eight intended points, keeping the holes clear of the larger components and their mechanical space.

a large part of the session went into rebuilding the power zones and mounting-hole keepouts at the current positions. i updated the full-board routing plan and the high- and medium-current trace classes alongside that work. those settings needed to follow the actual board layout, rather than the earlier positions the first zones had been based on.

finished the usb-a routing prep and power zones

# 2026-08-25: set the routing presets and board layout

**Total time spent: 2 hours 58 minutes**

put the routing widths and gaps into the project settings so the right values were available while drawing tracks. i also assigned colors by routing function across the board's nets, which made it easier to follow the different groups in KiCad.

i restored the right-side USB connector to the intended position opposite the left one and updated the power-zone layers to match the stackup plan. i refreshed the drawing guides from the saved board, then added the Framework hinge cutouts to the actual outline and removed the old guide shapes. the routing setup and the board edges now reflected the same layout.

set the routing presets and board layout

# 2026-08-25: fixed colors, hinge cutouts, and release checks

**Total time spent: 3 hours**

fixed the net colors after finding that i had saved them in the wrong format and location for KiCad. i changed them to the format the editor actually reads, reapplied the colors, and made the standby fault signal easy to pick out in red.

i also aligned the moved mounting holes with the edge rails and made the two hinge cutouts symmetric. those edits needed to be made on the board outline itself, not just shown in a drawing layer.

while checking the result, i fixed a broken variable reference in the board-checking script. that restored the check which had stopped working after an earlier edit, so i could use it on the updated layout again.

fixed colors, hinge cutouts, and release checks

# 2026-08-26: fixed mounting holes, power islands, and board formats

**Total time spent: 5 hours 13 minutes**

worked through the mounting holes, power islands and a few file problems that were getting in the way of routing. some mounting-hole references were duplicated, so i renumbered them and added their matching schematic symbols. that kept the mechanical parts identifiable when comparing the schematic and PCB.

the power layer also had islands with the wrong net names. i corrected those to use the names from the schematic hierarchy, separated the two raw USB input rails and applied the intended 85-ohm pair geometry. this was more than a visual cleanup, because an island assigned to the wrong net cannot supply the parts it was drawn for.

i fixed an outdated check around two hub ports that were now active USB-A connections, rather than treating them as unused straps. i also renamed the letter-suffixed transistor reference that was breaking annotation and normalized a library file's line endings.

these were a mixture of electrical and project-file problems. i saved the board and its supporting definitions together so the corrected power nets and references would survive the next regeneration.

fixed mounting holes, power islands, and board formats

# 2026-08-26: updated the pitch and ec startup work

**Total time spent: 2 hours 47 minutes**

put together the project funding description and the cost breakdown. the parts estimate came to roughly $3,560, so i added that information to the readme and explained what the money would cover, including the computer module, boards and the other laptop parts.

i also worked on the embedded controller's startup code. i fixed the memory initialization, clock setup, timer rates and ADC register mapping, then corrected the source-manager behavior so a communication problem would not leave it assuming that a power input was valid.

this combined the project writeup with several small but important firmware fixes. the startup code has to establish the right state before the rest of the controller starts making power decisions.

updated the pitch and ec startup work

# 2026-08-26: fixed the ec mappings and hardened the release checks

**Total time spent: 1 hour 12 minutes**

corrected the main-board net classes and divided up the power layer according to the intended supply rails. i also fixed the controller's USB register and request handling, and checked the power-limit calculations against the actual target settings.

i tightened the board checks so they examine a refilled copy of the PCB and compare its findings with the specific exceptions i had recorded. i also made the saved board-object identifiers unique and repeatable, so duplicate objects and unexplained file changes would be easier to catch. the work was spread between the PCB settings, firmware and the scripts used to check the saved design.

fixed the ec mappings and hardened the release checks

# 2026-08-26: finished the quote package, impedance approvals, and eight-layer docs

**Total time spent: 22 minutes**

regenerated the NextPCB quote files from the current board and part list. i updated the information for the endpoint regulator and USB-A cluster, then saved the BOM and placement data together with the package details.

i also recorded the supplied impedance values in the stackup file and updated the documentation that still described the older layer arrangement. the quote files and the eight-layer notes now referred to the same board revision.

finished the quote package, impedance approvals, and eight-layer docs

# 2026-08-27: documented the source-local l5 island architecture

**Total time spent: 45 minutes**

wrote up how the power islands should be arranged on the inner power layer. the idea is to keep each supply island around its source circuit, rather than spreading every rail across the whole board and letting the zones become tangled.

i documented that arrangement for the routing work, including how the separate rails should stay distinct. this was a planning and documentation session for the power layer; the pictures show the board i was using while working it out.


















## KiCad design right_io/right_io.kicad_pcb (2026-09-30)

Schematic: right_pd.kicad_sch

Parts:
C1760: 100n branch input; C_0603_1608Metric; MPN GRM188R71H104KA93D
C1761: 100n TPS25810 IN HF; C_0603_1608Metric; MPN GRM188R71H104KA93D
C1762: 150u 10V TPS25810 input reservoir; CP_EIA-7343-31_Kemet-D; MPN T520D157M010ATE025
C1763: 10u protected VBUS_SYS; C_1206_3216Metric; MPN GRM31CR71A106KA01L
C1764: 100n TPS25810 AUX; C_0603_1608Metric; MPN GRM188R71H104KA93D
C1770: 1u 50V connector-side VBUS; C_0805_2012Metric; MPN GRM21BR71H105KA12L
C1771: 1u TPD1S514 VBUS_POWER stability; C_0603_1608Metric; MPN GRM188R71A105KA61D
C2040: 100n 100V TPD4S201 VBIAS; C_0805_2012Metric; MPN GRM21BR72A104KA01L
C2041: 820n 10V TPD4S201 VPWR; C_0805_2012Metric; MPN GRM21BR71A824KA01L
C2042: 100n EEPROM local; C_0603_1608Metric; MPN GRM188R71H104KA93D
C2043: 100n mux-control buffer local; C_0603_1608Metric; MPN GRM188R71H104KA93D
C2055: 4.7u 25V raw VBUS; pre-attach total below 10uF; C_1206_3216Metric; MPN GRM31CR71E475KA88L
C2056, C2057, C2058, C2059: 10n 50V connector VBUS HF; C_0402_1005Metric; MPN GRM155R71H103KA88D
C2060: 6.8u 25V X7R TPS25751A LDO3V3; verify >=5u effect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; C_1206_3216Metric; MPN GRM31CR71E685KA88L
C2061: 10u 16V X7R TPS25751A LDO1V5; verify 4.5-12u effe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; C_1206_3216Metric; MPN GRM31CR71C106KA01L
C2062: 10u TPS25751A VIN3V3; C_1206_3216Metric; MPN GRM31CR71A106KA01L
C2063: 270p C0G CC1 total-capacitance component; C_0402_1005Metric; MPN GRM1555C1H271JA01D
C2064: 270p C0G CC2 total-capacitance component; C_0402_1005Metric; MPN GRM1555C1H271JA01D
C2065, C2066: 100u 10V PP5V source bulk; CP_EIA-7343-31_Kemet-D; MPN T520D107M010ATE070
C2067: 10u PP5V local ceramic; C_1206_3216Metric; MPN GRM31CR71A106KA01L
C2068: 68u 25V PPHV sink bulk; CP_EIA-7343-31_Kemet-D; MPN T521V686M025ATE050
C2069: 100n 50V PPHV local; C_0603_1608Metric; MPN GRM188R71H104KA93D
C2070: 100n USB2 switch local; C_0603_1608Metric; MPN GRM188R71H104KA93D
C2090: 100n 50V input local; C_0603_1608Metric; MPN GRM188R71H104KA93D
C2091: 10u 25V output; C_1206_3216Metric; MPN GRM31CR71E106KA12L
C2092: 10n 50V C0G slew control; C_0603_1608Metric; MPN GRM1885C1H103JA01D
C2404: 1u; C_0805_2012Metric; MPN GRM21BR71H105KA12L
C2409: 100n; C_0603_1608Metric; MPN GRM188R71H104KA93D
C2414: 4.7n C0G PP5V slew; C_0603_1608Metric; MPN GRM1885C1H472JA01D
C2631: 100n 50V inverter bypass; C_0603_1608Metric; MPN GRM188R71H104KA93D
C2681: 100n 50V qualifier bypass; C_0603_1608Metric; MPN GRM188R71H104KA93D
D2090: B340A eFuse output negative-transient clamp; D_SMA; MPN B340A-13-F
H13, H15, H17: M2.5 isolated mainboard mounting hole; MountingHole_2.7mm_M2.5
J11: USB-C dual-role data/PD port J11; USB_C_Receptacle_Molex_105450-0101; MPN 105450-0101
J12: USB-C source-only data port J12; USB_C_Receptacle_Molex_105450-0101; MPN 105450-0101
Q2002: 2N7002K DFP USB2 enable inverter; SOT-23; MPN 2N7002KT1G
Q2631: BSS138 switched discharge; SOT-23; MPN BSS138LT1G
R1760: 19.1k 1% TPS2553 VBUS plus VCONN ILIM; R_0603_1608Metric; MPN RC0603FR-0719K1L
R1761: 4.99k POL pull-up; R_0603_1608Metric; MPN RC0603FR-074K99L
R1762: 100k 1% TPS25810 REF; R_0603_1608Metric; MPN RC0603FR-07100KL
R1770: 249R 0.25W TPS25810 OUT discharge; R_1206_3216Metric; MPN RC1206FR-07249RL
R2040: 10k shared CC/USB2 protector FLT pull-up; R_0603_1608Metric; MPN RC0603FR-0710KL
R2041: 2.2k EEPROM SDA pull-up; R_0603_1608Metric; MPN RC0603FR-072K2L
R2042: 2.2k EEPROM SCL pull-up; R_0603_1608Metric; MPN RC0603FR-072K2L
R2043: 4.7k TCPC SDA pull-up; R_0603_1608Metric; MPN RC0603FR-074K7L
R2044: 4.7k TCPC SCL pull-up; R_0603_1608Metric; MPN RC0603FR-074K7L
R2045: 10k TCPC IRQ pull-up; R_0603_1608Metric; MPN RC0603FR-0710KL
R2046: 10k mux FLIP pull-up; R_0603_1608Metric; MPN RC0603FR-0710KL
R2047: 10k mux EN pull-up; R_0603_1608Metric; MPN RC0603FR-0710KL
R2055: 10k I2Cc IRQ inactive pull-up; R_0603_1608Metric; MPN RC0603FR-0710KL
R2056: 100k USB2 switch default-disable pull-up; R_0603_1608Metric; MPN RC0603FR-07100KL
R2057: 0R protector FLT wired-OR link; R_0603_1608Metric; MPN RC0603FR-070RL
R2090: 1k 1W switched input discharge; R_2512_6332Metric; MPN RC2512FR-071KL
R2091: 100k discharge gate default-low; R_0603_1608Metric; MPN RC0603FR-07100KL
R2092: 1k IMON load; R_0603_1608Metric; MPN RC0603FR-071KL
R2093: 267R 0.1% sink breaker; 5.58A nominal; R_0603_1608Metric; MPN RT0603BRD07267RL
R2094: 47k sink enable default-off; R_0603_1608Metric; MPN RC0603FR-0747KL
R2095: 10k sink enable series; R_0603_1608Metric; MPN RC0603FR-0710KL
R2096: 150k sink PG pull-up; valid with input off; R_0603_1608Metric; MPN RC0603FR-07150KL
R2404, R2409: 100k; R_0603_1608Metric; MPN RC0603FR-07100KL
R2414: 10k; R_0603_1608Metric; MPN RC0603FR-0710KL
U42: TPS25751AD USB-PD DRP controller; Texas_REF0038A_WQFN-38-2EP_6x4mm_P0.4; MPN TPS25751ADREFR
U721: TPS259827ONRGER PD2 sink breaker; Texas_RGE0024M_QFN24_4x4_2EP; MPN TPS259827ONRGER
U1760: TPS2553DDBVR 1.3A USB branch; SOT-23-6; MPN TPS2553DDBVR
U1761: TPS25810RVCR Type-C DFP controller; Texas_RVC0020A_WQFN-20-1EP_3x4mm_P0.5mm_EP1.6x2.6mm; MPN TPS25810RVCR
U1763: TPD1S514-1YZR 5.9V VBUS OVP; Texas_TPD1S514_YZ_WCSP-12_1.99x1.29mm_P0.5mm; MPN TPD1S514-1YZR
U1765: TPD4E05U06 USB2/CC ESD; USON-10_2.5x1.0mm_P0.5mm; MPN TPD4E05U06DQAR
U2011: TPD4S201 CC and USB2 short-to-VBUS protector; Texas_RUK0020B_WQFN-20-1EP_3x3mm_P0.4mm_EP1.7x1.7mm_Thermal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; MPN TPD4S201RUKR
U2012: CAT24C256 32KB private TPS25751A EEPROM; SOIC-8_3.9x4.9mm_P1.27mm; MPN CAT24C256WI-GT3
U2013: TS3USB30E DFP-qualified USB2 disconnect; TSSOP-10_3x3mm_P0.5mm; MPN TS3USB30EDGSR
U2014: SN74LVC2G07 partial-power-down mux controls; SOT-363_SC-70-6; MPN SN74LVC2G07DCKR
U2015: TVS2200 22V USB VBUS surge clamp; WSON-6-1EP_2x2mm_P0.65mm_EP1x1.6mm; MPN TVS2200DRVR
U2016: SN74LVC1G08 DFP and attached qualifier; SOT-23-5; MPN SN74LVC1G08DBVR
U2404: TPS22992SRXNR J11 PP5V gate; Texas_RXN0008A_WQFN-HR-8_1.25x1.25mm; MPN TPS22992SRXNR
U2409: SN74LVC1G08DBVR J12 source permission; SOT-23-5; MPN SN74LVC1G08DBVR
U2631: SN74LVC1G04DBVR discharge control; SOT-23-5; MPN SN74LVC1G04DBVR

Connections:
/HUB_DS1_DN: U2013.8 (D1-); also elsewhere on the board
/HUB_DS1_DP: U2013.2 (D1+); also elsewhere on the board
/HUB_DS4_DN: J12.A7 (D-), J12.B7 (D-), U1765.2 (D1-); also elsewhere on the board
/HUB_DS4_DP: J12.A6 (D+), J12.B6 (D+), U1765.1 (D1+); also elsewhere on the board
/HUB_PRT_CTL4: U1760.4 (~FAULT), U1761.1 (~FAULT), U2409.2; also elsewhere on the board
/MCU_3V3: C2062.1, C2409.1, C2631.1, R2040.1, R2043.1, R2044.1, R2045.1, R2096.1, U42.38 (VIN_3V3), U2409.5 (VCC), U2631.5 (VCC); also elsewhere on the board
/PD2 Dual-Role/J11_PP5V_CT: C2414.1, U2404.7 (CT)
/PD2 Dual-Role/J12_5V_PRE: C1761.1, C1762.1, U1760.6 (OUT), U1761.2 (IN1), U1761.3 (IN1), U1761.4 (IN2)
/PD2 Dual-Role/J12_CC1: J12.A5 (CC1), U1761.11 (CC1), U1765.4 (D2+)
/PD2 Dual-Role/J12_CC2: J12.B5 (CC2), U1761.13 (CC2), U1765.5 (D2-)
/PD2 Dual-Role/J12_ILIM: R1760.1, U1760.5 (ILIM)
/PD2 Dual-Role/J12_POL_N: R1761.2, U1761.18 (~POL)
/PD2 Dual-Role/J12_REF: R1762.1, U1761.10 (REF)
/PD2 Dual-Role/J12_REF_RTN: R1762.2, U1761.9 (REF_RTN)
/PD2 Dual-Role/J12_VBUS: C1770.1, J12.A4 (VBUS), J12.A9 (VBUS), J12.B4 (VBUS), J12.B9 (VBUS), U1763.B3 (VBUS_CON), U1763.C2 (VBUS_CON), U1763.C3 (VBUS_CON)
/PD2 Dual-Role/J12_VBUS_POWER: C1771.1, U1763.B1 (VBUS_POWER)
/PD2 Dual-Role/J12_VBUS_SYS: C1763.1, R1770.1, U1761.14 (OUT), U1761.15 (OUT), U1763.A2 (VBUS_SYS), U1763.A3 (VBUS_SYS), U1763.B2 (VBUS_SYS)
/PD2 Dual-Role/PD2_CC1_CONN: J11.A5 (CC1), U2011.4 (C_CC1), U2011.7 (RPD_G1)
/PD2 Dual-Role/PD2_CC1_SYS: C2063.1, U42.28 (CC1), U2011.12 (CC1)
/PD2 Dual-Role/PD2_CC2_CONN: J11.B5 (CC2), U2011.5 (C_CC2), U2011.6 (RPD_G2)
/PD2 Dual-Role/PD2_CC2_SYS: C2064.1, U42.29 (CC2), U2011.11 (CC2)
/PD2 Dual-Role/PD2_CC_ESD_VBIAS: C2040.1, U2011.3 (VBIAS)
/PD2 Dual-Role/PD2_CC_FAULT_LOCAL_N: R2057.1, U2011.9 (FLT)
/PD2 Dual-Role/PD2_CONN_DN: J11.A7 (D-), J11.B7 (D-), U2011.2 (C_SBU2)
/PD2 Dual-Role/PD2_CONN_DP: J11.A6 (D+), J11.B6 (D+), U2011.1 (C_SBU1)
/PD2 Dual-Role/PD2_DISCHARGE: Q2631.1 (G), R2091.1, U2631.4
/PD2 Dual-Role/PD2_DISCHARGE_DRAIN: Q2631.3 (D), R2090.2
/PD2 Dual-Role/PD2_DRAIN_THERMAL: U42.15 (DRAIN), U42.30 (DRAIN), U42.40 (DRAIN)
/PD2 Dual-Role/PD2_EEPROM_IRQ_N: R2055.2, U42.18 (I2Cc_IRQ)
/PD2 Dual-Role/PD2_EEPROM_SCL: R2042.2, U42.17 (I2Cc_SCL), U2012.6 (SCL)
/PD2 Dual-Role/PD2_EEPROM_SDA: R2041.2, U42.16 (I2Cc_SDA), U2012.5 (SDA)
/PD2 Dual-Role/PD2_EFUSE_DVDT: C2092.1, U721.15 (dVdt)
/PD2 Dual-Role/PD2_EFUSE_ILIM: R2093.1, U721.8 (ILIM)
/PD2 Dual-Role/PD2_EFUSE_IMON: R2092.1, U721.9 (IMON)
/PD2 Dual-Role/PD2_EFUSE_SHDN: R2094.1, R2095.2, U721.6 (EN/UVLO)
/PD2 Dual-Role/PD2_GPIO_ATTACH: U42.36 (GPIO7), U2016.2
/PD2 Dual-Role/PD2_GPIO_DFP: U42.26 (GPIO4/USB_P), U2016.1
/PD2 Dual-Role/PD2_GPIO_FLIP: U42.37 (GPIO6), U2014.1
/PD2 Dual-Role/PD2_HOST_ATTACHED: U2014.3, U2016.4
/PD2 Dual-Role/PD2_HOST_SWITCHED_DN: U2011.14 (SBU2), U2013.6 (D-)
/PD2 Dual-Role/PD2_HOST_SWITCHED_DP: U2011.15 (SBU1), U2013.4 (D+)
/PD2 Dual-Role/PD2_LDO1V5: C2061.1, U42.4 (LDO_1V5)
/PD2 Dual-Role/PD2_LDO3V3: C2041.1, C2042.1, C2060.1, R2041.1, R2042.1, R2055.1, U42.1 (LDO_3V3), U2011.10 (VPWR), U2012.8 (VCC)
/PD2 Dual-Role/PD2_MUX_EN: Q2002.1 (G), R2047.2, U2014.4
/PD2 Dual-Role/PD2_MUX_FLIP: R2046.2, U2014.6
/PD2 Dual-Role/PD2_PP5V_GATED: C2065.1, C2066.1, C2067.1, R2414.1, U42.34 (PP5V_(34-35)), U2404.5 (QOD), U2404.6 (VOUT)
/PD2 Dual-Role/PD2_PPHV: C2068.1, C2069.1, C2090.1, U42.20 (PPHV_(20-22)), U721.1 (IN), U721.2 (IN), U721.3 (IN), U721.16 (IN), U721.25 (IN)
/PD2 Dual-Role/PD2_USB2_OE_N: Q2002.3 (D), R2056.2, U2013.9 (~OE)
/PD2 Dual-Role/USB_J12_SWITCH_EN: U1760.3 (EN), U1761.6 (EN), U2409.4
/PD2_EFUSE_PG: R2096.2, U721.13 (PG); also elsewhere on the board
/PD2_I2C_SCL: R2044.2, U42.9 (I2Ct_SCL); also elsewhere on the board
/PD2_I2C_SDA: R2043.2, U42.8 (I2Ct_SDA); also elsewhere on the board
/PD2_PATH_EN: R2095.1, U2631.2; also elsewhere on the board
/PD2_SOURCE_PG: R2414.2, U2404.3 (PG); also elsewhere on the board
/PD2_TCPC_IRQ_N: R2045.2, U42.10 (I2Ct_IRQ); also elsewhere on the board
/PD2_VBUS_GATED: C2091.1, D2090.1 (K), R2090.1, U721.17 (OUT), U721.18 (OUT), U721.19 (OUT), U721.20 (OUT), U721.21 (OUT), U721.22 (OUT), U721.23 (OUT), U721.24 (OUT); also elsewhere on the board
/PD2_VBUS_RAW: C2055.1, C2056.1, C2057.1, C2058.1, C2059.1, J11.A4 (VBUS), J11.A9 (VBUS), J11.B4 (VBUS), J11.B9 (VBUS), U42.23 (VBUS_IN_(23-25)), U42.32 (VBUS_(32-33)), U2015.4 (IN), U2015.5 (IN), U2015.6 (IN); also elsewhere on the board
/PD_PROTECT_FAULT_N: R2040.2, R2057.2; also elsewhere on the board
/SYS_3V3: C1764.1, C2043.1, C2070.1, C2681.1, R1761.1, R2046.1, R2047.1, R2056.1, U1761.5 (AUX), U2013.10 (VCC), U2014.5 (VCC), U2016.5 (VCC); also elsewhere on the board
/USB_J11_PERMIT: R2404.1, U2404.8 (ON); also elsewhere on the board
/USB_J12_PERMIT: R2409.1, U2409.1; also elsewhere on the board
/USB_PORT_5V: C1760.1, C2404.1, U1760.1 (IN), U2404.1 (VBIAS), U2404.2 (VIN); also elsewhere on the board
GND: C1760.2, C1761.2, C1762.2, C1763.2, C1764.2, C1770.2, C1771.2, C2040.2, C2041.2, C2042.2, C2043.2, C2055.2, C2056.2, C2057.2, C2058.2, C2059.2, C2060.2, C2061.2, C2062.2, C2063.2, C2064.2, C2065.2, C2066.2, C2067.2, C2068.2, C2069.2, C2070.2, C2090.2, C2091.2, C2092.2, C2404.2, C2409.2, C2414.2, C2631.2, C2681.2, D2090.2 (A), J11.A1 (GND), J11.A12 (GND), J11.B1 (GND), J11.B12 (GND), J11.SH (SHIELD), J12.A1 (GND), J12.A12 (GND), J12.B1 (GND), J12.B12 (GND), J12.SH (SHIELD), Q2002.2 (S), Q2631.2 (S), R1760.2, R1770.2, R2091.2, R2092.2, R2093.2, R2094.2, R2404.2, R2409.2, U42.2 (ADCIN1), U42.3 (ADCIN2), U42.5 (GPIO0/LD1), U42.6 (GPIO1), U42.7 (GPIO2/LD2), U42.11 (GND), U42.12 (GND), U42.13 (GPIO11), U42.14 (GND), U42.19 (GPIO3), U42.27 (GPIO5/USB_N), U42.31 (GND), U42.39 (GND), U721.4 (GND), U721.5 (GND), U721.10 (RETRY_DLY), U721.11 (NRETRY), U721.12 (LDSTRT), U721.14 (GND), U721.26 (GND), U1760.2 (GND), U1761.7 (CHG), U1761.8 (CHG_HI), U1761.12 (GND), U1761.21 (GND), U1763.A1 (EN_N), U1763.A4 (GND), U1763.B4 (GND), U1763.C1 (GND), U1763.C4 (GND), U1765.3 (GND), U1765.8 (GND), U2011.8 (GND), U2011.13 (GND), U2011.18 (GND), U2011.21 (GND), U2012.1 (A0), U2012.2 (A1), U2012.3 (A2), U2012.4 (GND), U2012.7 (WP), U2013.1 (S), U2013.5 (GND), U2014.2 (GND), U2015.1 (GND), U2015.2 (GND), U2015.3 (GND), U2015.7 (GND), U2016.3 (GND), U2404.4 (GND), U2409.3 (GND), U2631.3 (GND); also elsewhere on the board

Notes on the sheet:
== Right I/O: PD2 dual-role (J11) + source (J12), USB2-only ==
== J11: USB 2.0 data plus USB-PD charging, side port 2 ==
J11: hardware accepts 15V/20V PD; use a verified 3A contract and 2.50A IINDPM bootstrap command. Actual current/headroom and EEPROM/profile qualification remain required.
GPIO4 AND GPIO7 qualifies both host USB2 and SuperSpeed. They remain disconnected through reset, detach, and sink-only operation.
== J12: source-only USB-C data port, USB7206C downstream 4, USB2 ==

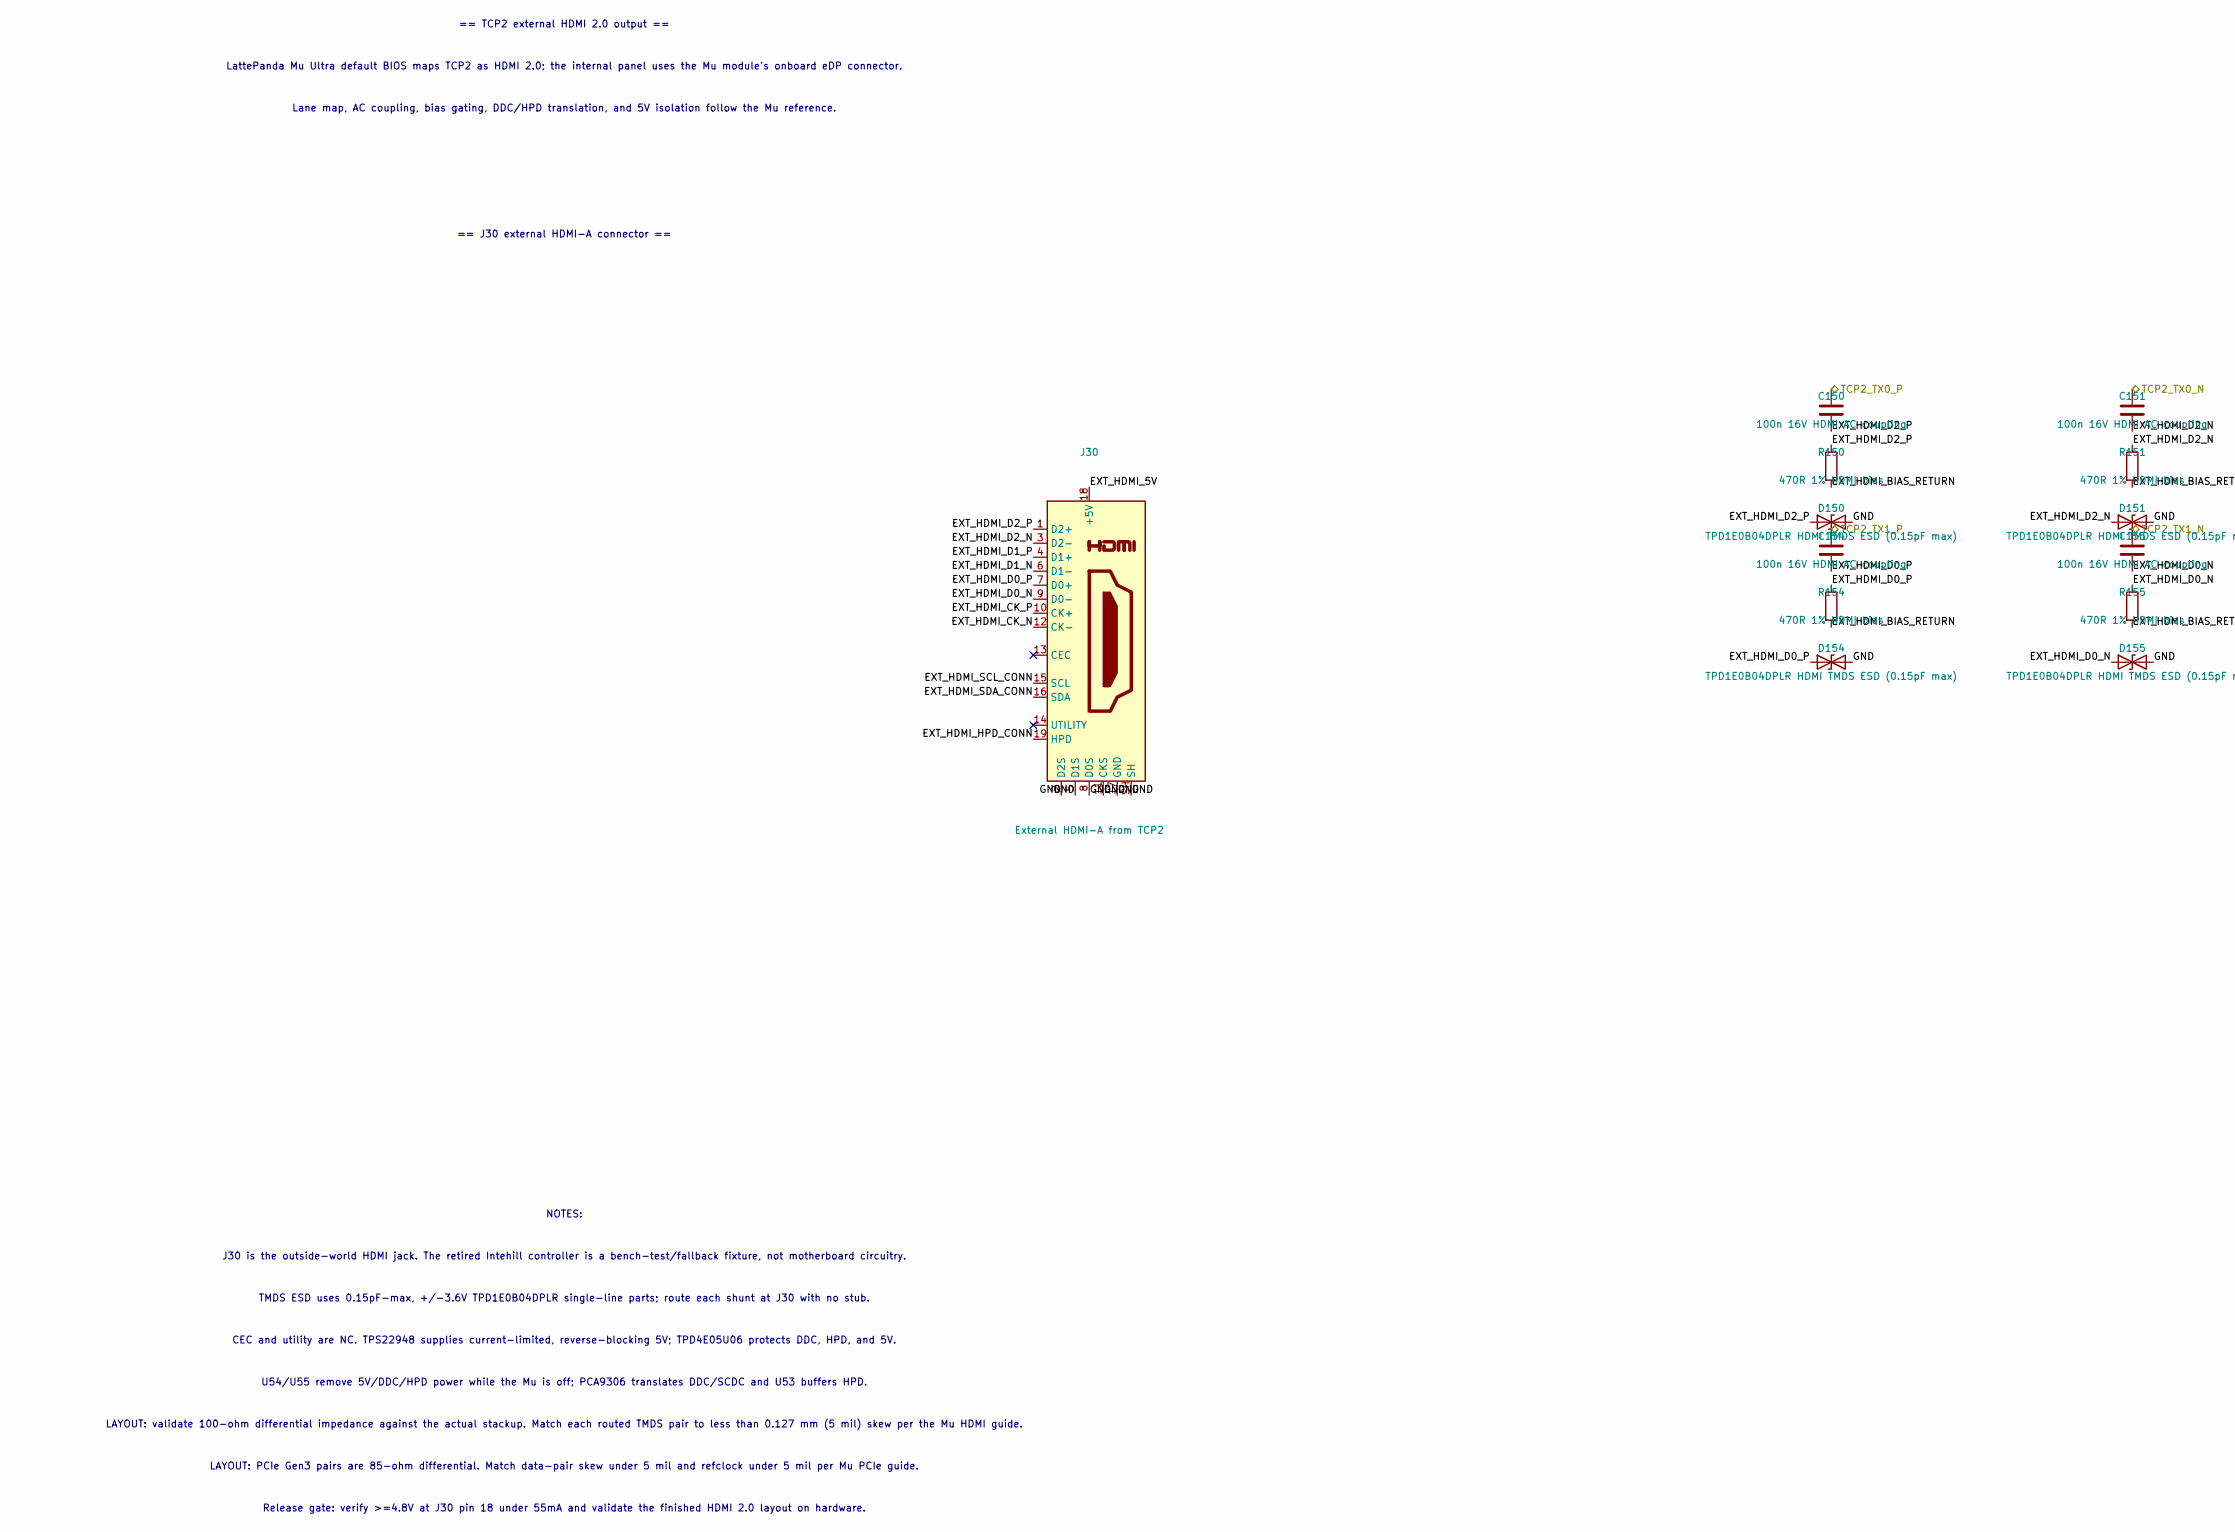
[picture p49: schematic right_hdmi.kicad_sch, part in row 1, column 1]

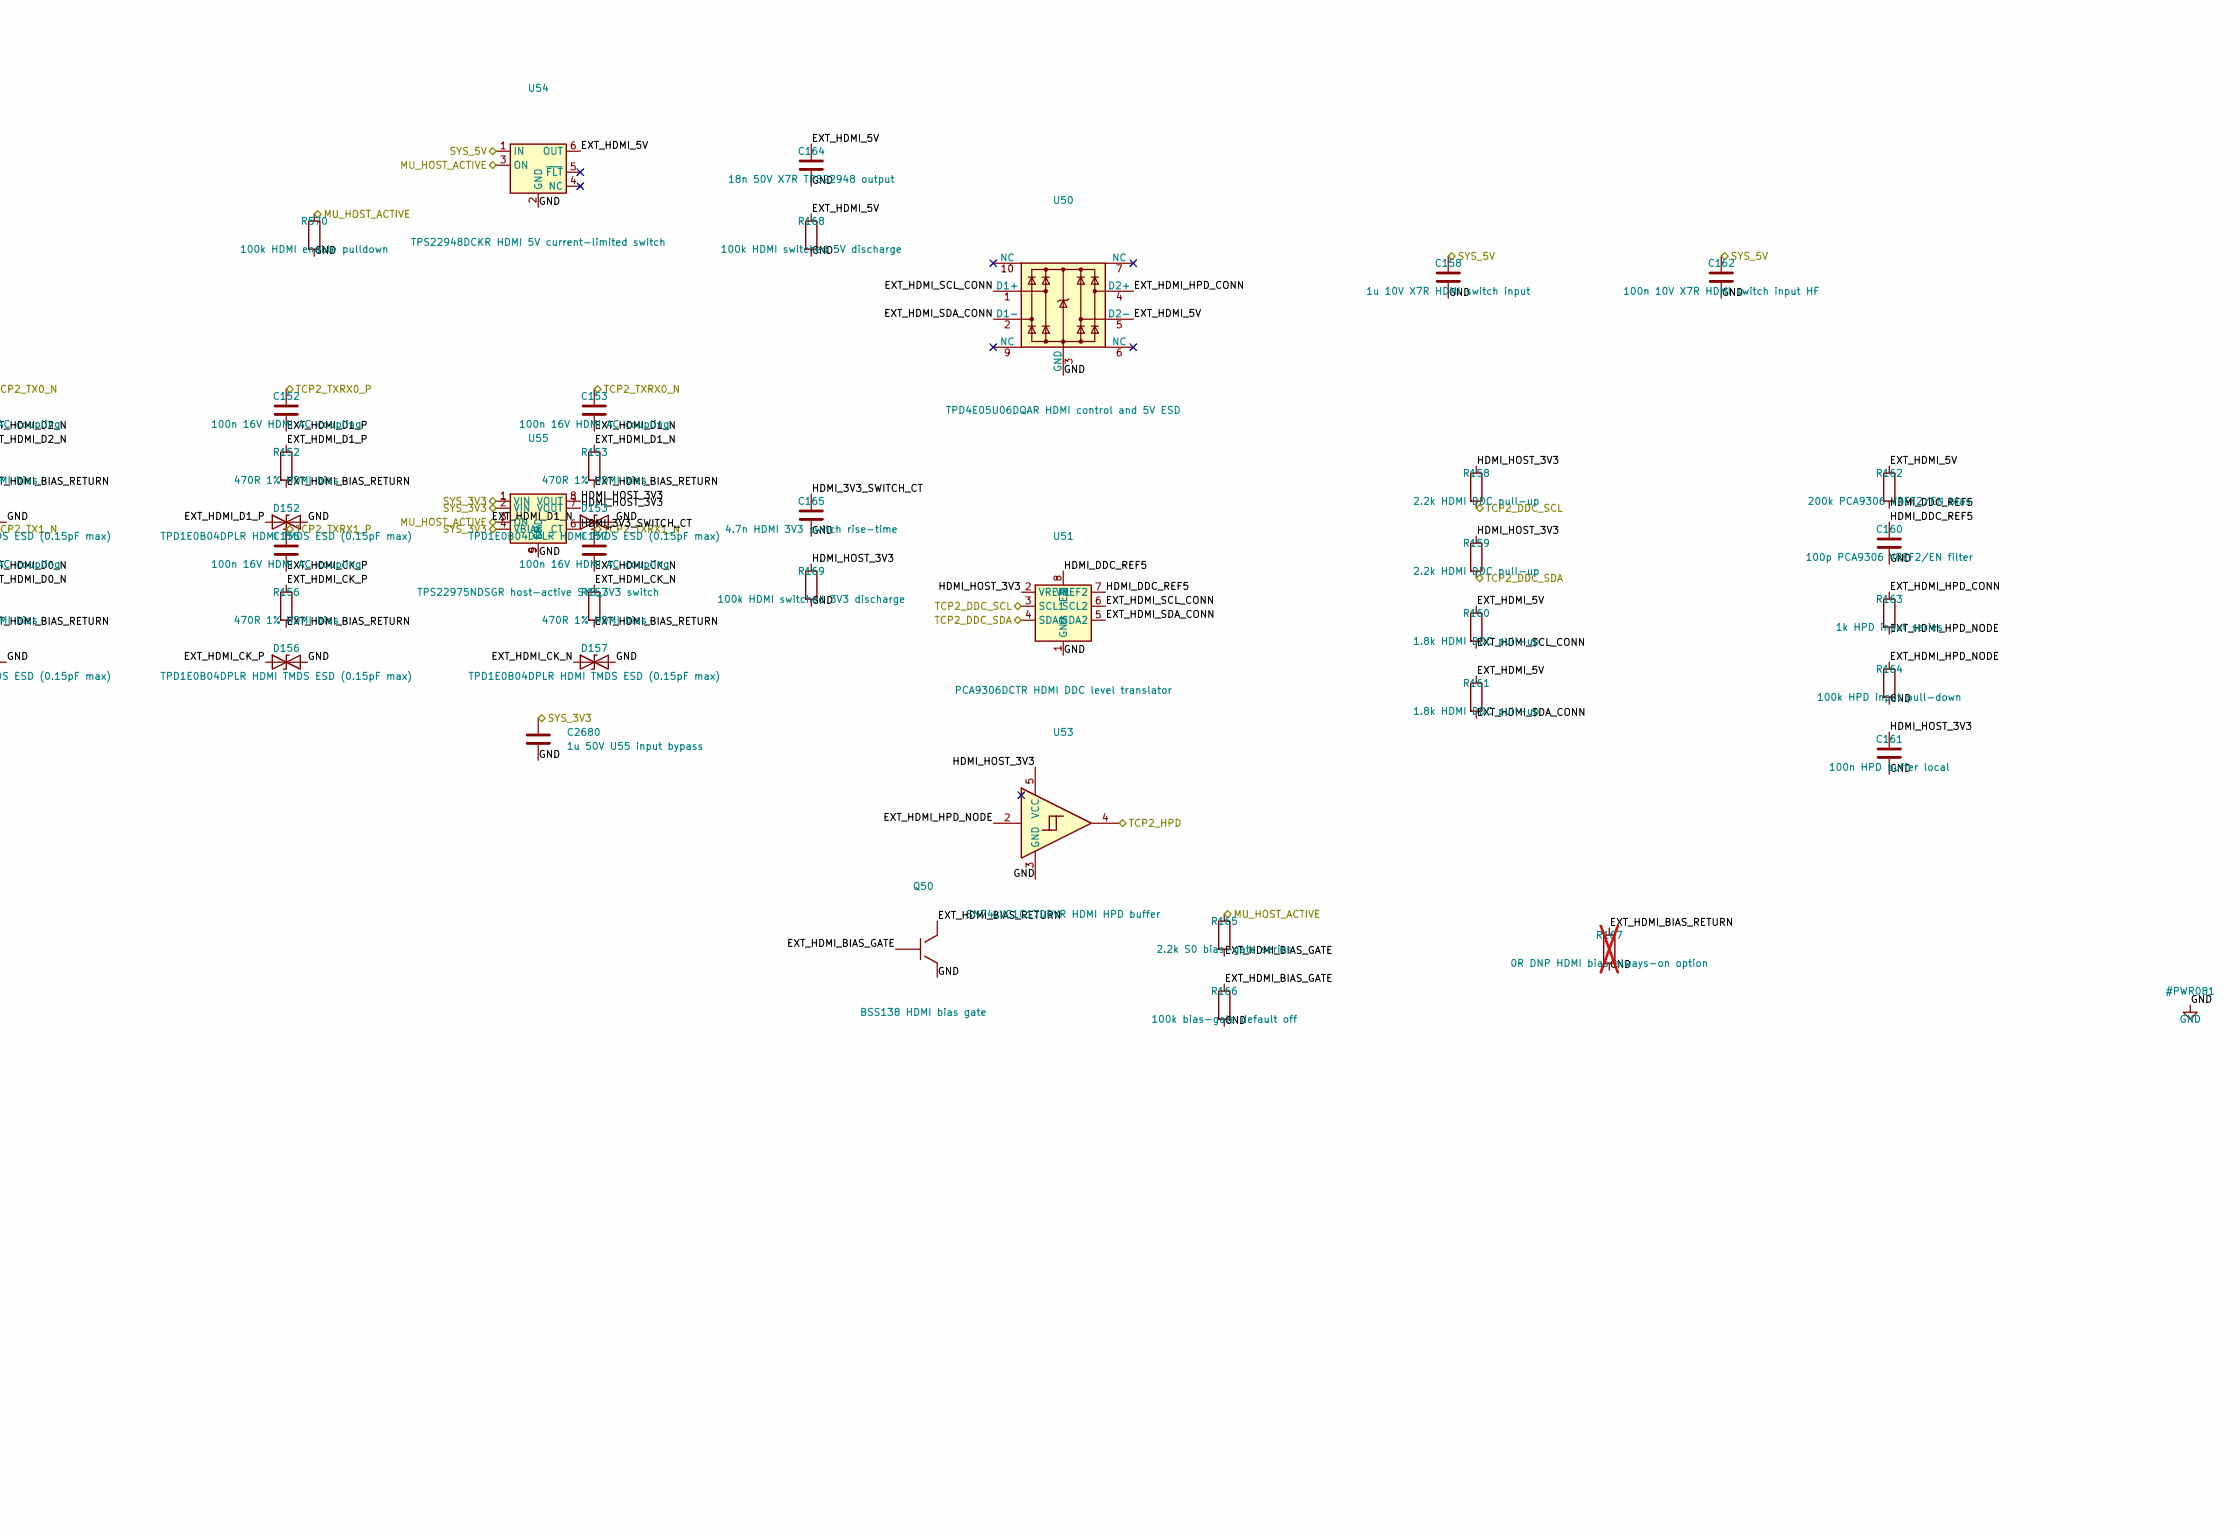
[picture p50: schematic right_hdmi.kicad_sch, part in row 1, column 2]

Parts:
C150, C151, C152, C153, C154, C155, C156, C157: 100n 16V HDMI AC coupling; C_0402_1005Metric; MPN GRM155R71C104KA88D
C158: 1u 10V X7R HDMI switch input; C_0603_1608Metric; MPN GRM188R71A105KA61D
C160: 100p PCA9306 VREF2/EN filter; C_0402_1005Metric; MPN GRM1555C1H101JA01D
C161: 100n HPD buffer local; C_0402_1005Metric; MPN GRM155R71A104KA01D
C162: 100n 10V X7R HDMI switch input HF; C_0402_1005Metric; MPN GRM155R71A104KA01D
C164: 18n 50V X7R TPS22948 output; C_0402_1005Metric; MPN CC0402KRX7R9BB183
C165: 4.7n HDMI 3V3 switch rise-time; C_0402_1005Metric; MPN GRM155R71C472KA01D
C2680: 1u 50V U55 input bypass; C_0603_1608Metric; MPN GRT188R61H105ME13D
D150, D151, D152, D153, D154, D155, D156, D157: TPD1E0B04DPLR HDMI TMDS ESD (0.15pF max); D_0201_0603Metric; MPN TPD1E0B04DPLR
J30: External HDMI-A from TCP2; HDMI_A_Molex_208658-1001_Horizontal; MPN 208658-1001
Q50: BSS138 HDMI bias gate; SOT-23; MPN BSS138LT1G
R150, R151, R152, R153, R154, R155, R156, R157: 470R 1% HDMI bias; R_0402_1005Metric; MPN RC0402FR-07470RL
R158, R159: 2.2k HDMI DDC pull-up; R_0402_1005Metric; MPN RC0402FR-072K2L
R160, R161: 1.8k HDMI DDC pull-up; R_0402_1005Metric; MPN RC0402FR-071K8L
R162: 200k PCA9306 VREF2/EN bias; R_0402_1005Metric; MPN RC0402FR-07200KL
R163: 1k HPD input series; R_0402_1005Metric; MPN RC0402FR-071KL
R164: 100k HPD input pull-down; R_0402_1005Metric; MPN RC0402FR-07100KL
R165: 2.2k S0 bias-gate series; R_0402_1005Metric; MPN RC0402FR-072K2L
R166: 100k bias-gate default off; R_0402_1005Metric; MPN RC0402FR-07100KL
R167: 0R DNP HDMI bias always-on option; R_0402_1005Metric; not fitted
R168: 100k HDMI switched 5V discharge; R_0402_1005Metric; MPN RC0402FR-07100KL
R169: 100k HDMI switched 3V3 discharge; R_0402_1005Metric; MPN RC0402FR-07100KL
R570: 100k HDMI enable pulldown; R_0402_1005Metric; MPN RC0402FR-07100KL
U50: TPD4E05U06DQAR HDMI control and 5V ESD; USON-10_2.5x1.0mm_P0.5mm; MPN TPD4E05U06DQAR
U51: PCA9306DCTR HDMI DDC level translator; SSOP-8_2.95x2.8mm_P0.65mm; MPN PCA9306DCTR
U53: SN74LVC1G17DBVR HDMI HPD buffer; SOT-23-5; MPN SN74LVC1G17DBVR
U54: TPS22948DCKR HDMI 5V current-limited switch; SOT-363_SC-70-6; MPN TPS22948DCKR
U55: TPS22975NDSGR host-active SYS_3V3 switch; Texas_DSG0008A_WSON-8-1EP_2x2mm_P0.5mm_EP0.9x1.6mm; MPN TPS22975NDSGR

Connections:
/HDMI/EXT_HDMI_5V: C164.1, J30.18 (+5V), R160.1, R161.1, R162.1, R168.1, U50.5 (D2-), U54.6 (OUT)
/HDMI/EXT_HDMI_BIAS_GATE: Q50.1 (G), R165.2, R166.1
/HDMI/EXT_HDMI_BIAS_RETURN: Q50.3 (D), R150.2, R151.2, R152.2, R153.2, R154.2, R155.2, R156.2, R157.2, R167.1
/HDMI/EXT_HDMI_CK_N: C157.2, D157.1 (A1), J30.12 (CK-), R157.1
/HDMI/EXT_HDMI_CK_P: C156.2, D156.1 (A1), J30.10 (CK+), R156.1
/HDMI/EXT_HDMI_D0_N: C155.2, D155.1 (A1), J30.9 (D0-), R155.1
/HDMI/EXT_HDMI_D0_P: C154.2, D154.1 (A1), J30.7 (D0+), R154.1
/HDMI/EXT_HDMI_D1_N: C153.2, D153.1 (A1), J30.6 (D1-), R153.1
/HDMI/EXT_HDMI_D1_P: C152.2, D152.1 (A1), J30.4 (D1+), R152.1
/HDMI/EXT_HDMI_D2_N: C151.2, D151.1 (A1), J30.3 (D2-), R151.1
/HDMI/EXT_HDMI_D2_P: C150.2, D150.1 (A1), J30.1 (D2+), R150.1
/HDMI/EXT_HDMI_HPD_CONN: J30.19 (HPD), R163.1, U50.4 (D2+)
/HDMI/EXT_HDMI_HPD_NODE: R163.2, R164.1, U53.2
/HDMI/EXT_HDMI_SCL_CONN: J30.15 (SCL), R160.2, U50.1 (D1+), U51.6 (SCL2)
/HDMI/EXT_HDMI_SDA_CONN: J30.16 (SDA), R161.2, U50.2 (D1-), U51.5 (SDA2)
/HDMI/HDMI_3V3_SWITCH_CT: C165.1, U55.6 (CT)
/HDMI/HDMI_DDC_REF5: C160.1, R162.2, U51.7 (VREF2), U51.8 (EN)
/HDMI/HDMI_HOST_3V3: C161.1, R158.1, R159.1, R169.1, U51.2 (VREF1), U53.5 (VCC), U55.7 (VOUT), U55.8 (VOUT)
/MU_HOST_ACTIVE: R165.1, R570.1, U54.3 (ON), U55.3 (ON); also elsewhere on the board
/SYS_3V3: C2680.1, U55.1 (VIN), U55.2 (VIN), U55.4 (VBIAS); also elsewhere on the board
/SYS_5V: C158.1, C162.1, U54.1 (IN); also elsewhere on the board
/TCP2_DDC_SCL: R158.2, U51.3 (SCL1); also elsewhere on the board
/TCP2_DDC_SDA: R159.2, U51.4 (SDA1); also elsewhere on the board
/TCP2_HPD: U53.4; also elsewhere on the board
/TCP2_TX0_N: C151.1; also elsewhere on the board
/TCP2_TX0_P: C150.1; also elsewhere on the board
/TCP2_TX1_N: C155.1; also elsewhere on the board
/TCP2_TX1_P: C154.1; also elsewhere on the board
/TCP2_TXRX0_N: C153.1; also elsewhere on the board
/TCP2_TXRX0_P: C152.1; also elsewhere on the board
/TCP2_TXRX1_N: C157.1; also elsewhere on the board
/TCP2_TXRX1_P: C156.1; also elsewhere on the board
GND: C158.2, C160.2, C161.2, C162.2, C164.2, C165.2, C2680.2, D150.2 (A2), D151.2 (A2), D152.2 (A2), D153.2 (A2), D154.2 (A2), D155.2 (A2), D156.2 (A2), D157.2 (A2), J30.2 (D2S), J30.5 (D1S), J30.8 (D0S), J30.11 (CKS), J30.17 (GND), J30.SH, Q50.2 (S), R164.2, R166.2, R167.2, R168.2, R169.2, R570.2, U50.3 (GND), U50.8 (GND), U51.1 (GND), U53.3 (GND), U54.2 (GND), U55.5 (GND), U55.9 (EP); also elsewhere on the board

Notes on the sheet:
== TCP2 external HDMI 2.0 output ==
LattePanda Mu Ultra default BIOS maps TCP2 as HDMI 2.0; the internal panel uses the Mu module's onboard eDP connector.
Lane map, AC coupling, bias gating, DDC/HPD translation, and 5V isolation follow the Mu reference.
== J30 external HDMI-A connector ==
NOTES:
J30 is the outside-world HDMI jack. The retired Intehill controller is a bench-test/fallback fixture, not motherboard circuitry.
TMDS ESD uses 0.15pF-max, +/-3.6V TPD1E0B04DPLR single-line parts; route each shunt at J30 with no stub.
CEC and utility are NC. TPS22948 supplies current-limited, reverse-blocking 5V; TPD4E05U06 protects DDC, HPD, and 5V.
U54/U55 remove 5V/DDC/HPD power while the Mu is off; PCA9306 translates DDC/SCDC and U53 buffers HPD.
LAYOUT: validate 100-ohm differential impedance against the actual stackup. Match each routed TMDS pair to less than 0.127 mm (5 mil) skew per the Mu HDMI guide.
LAYOUT: PCIe Gen3 pairs are 85-ohm differential. Match data-pair skew under 5 mil and refclock under 5 mil per Mu PCIe guide.
Release gate: verify >=4.8V at J30 pin 18 under 55mA and validate the finished HDMI 2.0 layout on hardware.

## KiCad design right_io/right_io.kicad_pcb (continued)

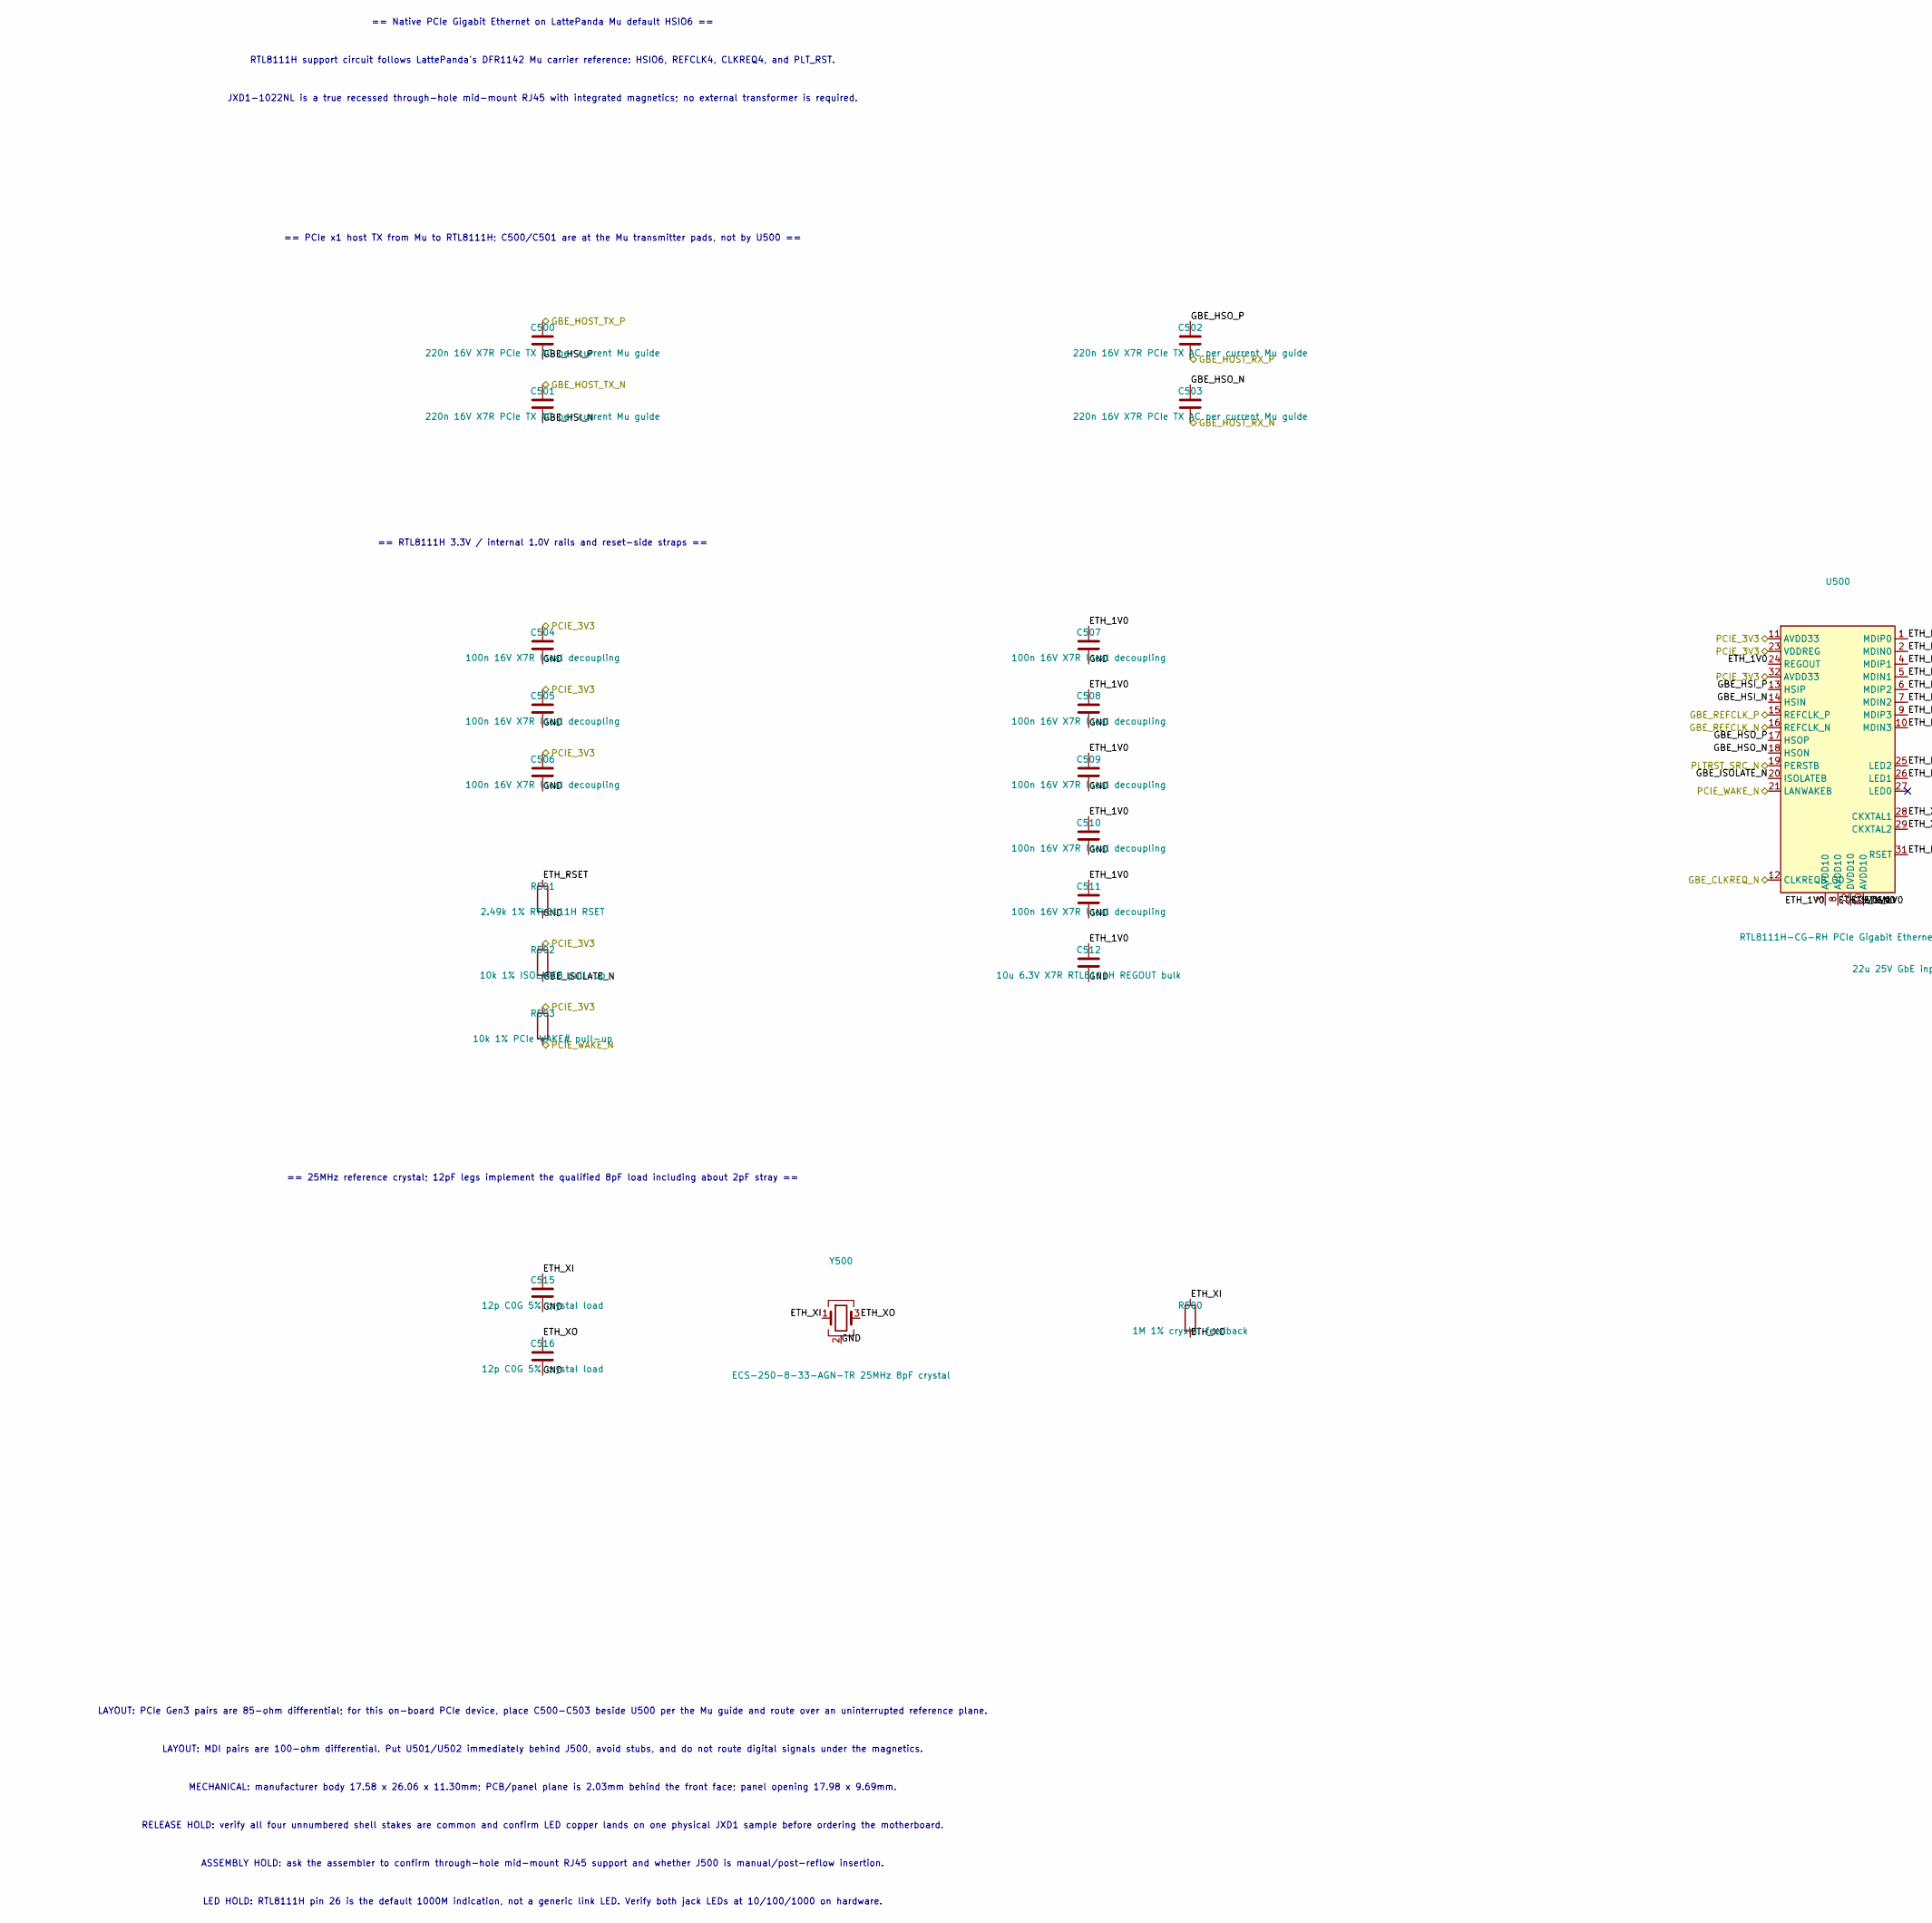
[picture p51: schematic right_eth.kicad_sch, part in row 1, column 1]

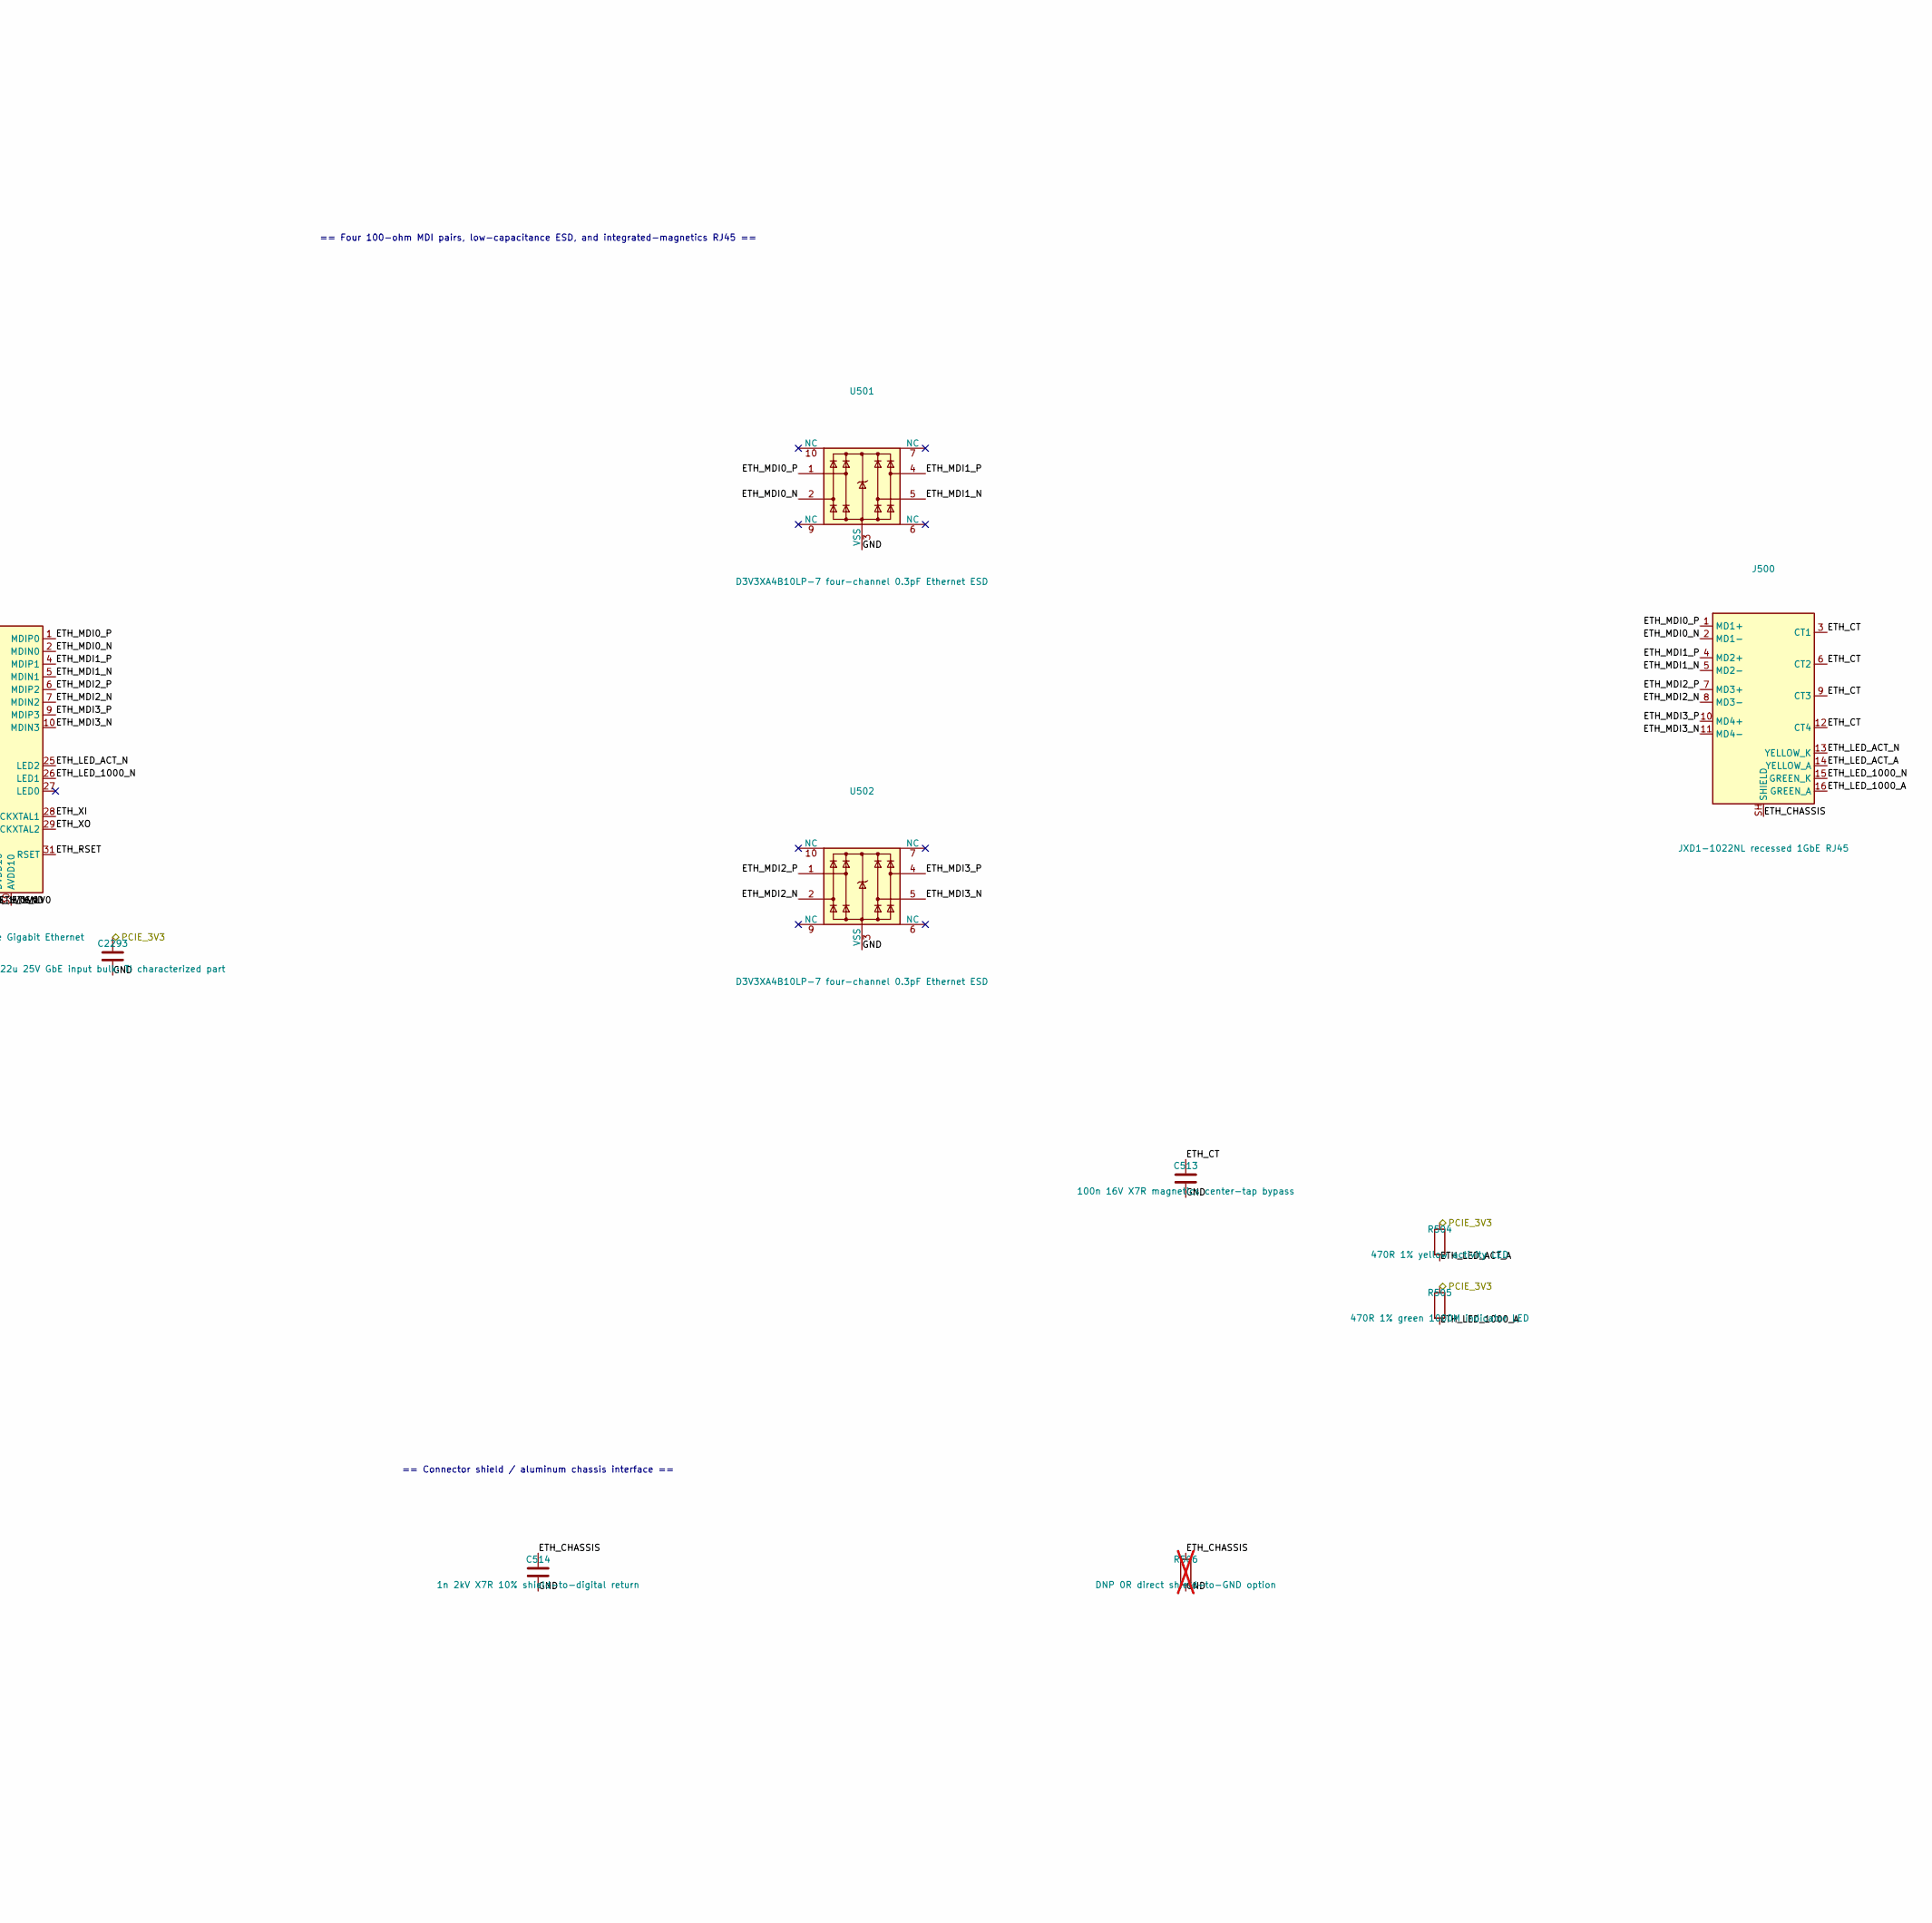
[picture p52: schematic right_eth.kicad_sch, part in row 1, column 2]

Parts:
C500, C501, C502, C503: 220n 16V X7R PCIe TX AC per current Mu guide; C_0402_1005Metric; MPN GRM155R71C224KA12D
C504, C505, C506, C507, C508, C509, C510, C511: 100n 16V X7R local decoupling; C_0402_1005Metric; MPN GRM155R71C104KA88D
C512: 10u 6.3V X7R RTL8111H REGOUT bulk; C_1206_3216Metric; MPN GRM31CR71E106KA12L
C513: 100n 16V X7R magnetics center-tap bypass; C_0402_1005Metric; MPN GRM155R71C104KA88D
C514: 1n 2kV X7R 10% shield-to-digital return; C_1812_4532Metric; MPN C1812C102KGRACTU
C515, C516: 12p C0G 5% crystal load; C_0402_1005Metric; MPN GRM1555C1H120JA01
C2293: 22u 25V GbE input bulk; TI characterized part; C_1210_3225Metric; MPN GRM32ER71E226KE15L
J500: JXD1-1022NL recessed 1GbE RJ45; JXD1-1022NL_MidMount; MPN JXD1-1022NL
R500: 1M 1% crystal feedback; R_0402_1005Metric; MPN RC0402FR-071ML
R501: 2.49k 1% RTL8111H RSET; R_0402_1005Metric; MPN RC0402FR-072K49L
R502: 10k 1% ISOLATEB pull-up; R_0402_1005Metric; MPN RC0402FR-0710KL
R503: 10k 1% PCIe WAKE# pull-up; R_0402_1005Metric; MPN RC0402FR-0710KL
R504: 470R 1% yellow activity LED; R_0402_1005Metric; MPN RC0402FR-07470RL
R505: 470R 1% green 1000M indicator LED; R_0402_1005Metric; MPN RC0402FR-07470RL
R506: DNP 0R direct shield-to-GND option; R_1206_3216Metric; not fitted
U500: RTL8111H-CG-RH PCIe Gigabit Ethernet; QFN-32-1EP_4x4mm_P0.4mm_EP2.65x2.65mm; MPN RTL8111H-CG-RH
U501, U502: D3V3XA4B10LP-7 four-channel 0.3pF Ethernet ESD; Diodes_UDFN-10_1x2.5mm_P0.5mm; MPN D3V3XA4B10LP-7
Y500: ECS-250-8-33-AGN-TR 25MHz 8pF crystal; Crystal_SMD_3225-4Pin_3.2x2.5mm; MPN ECS-250-8-33-AGN-TR

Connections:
/GBE_CLKREQ_N: U500.12 (CLKREQB_OD); also elsewhere on the board
/GBE_HOST_RX_N: C503.2; also elsewhere on the board
/GBE_HOST_RX_P: C502.2; also elsewhere on the board
/GBE_HOST_TX_N: C501.1; also elsewhere on the board
/GBE_HOST_TX_P: C500.1; also elsewhere on the board
/GBE_REFCLK_N: U500.16 (REFCLK_N); also elsewhere on the board
/GBE_REFCLK_P: U500.15 (REFCLK_P); also elsewhere on the board
/GbE/ETH_1V0: C507.1, C508.1, C509.1, C510.1, C511.1, C512.1, U500.3 (AVDD10), U500.8 (AVDD10), U500.22 (DVDD10), U500.24 (REGOUT), U500.30 (AVDD10)
/GbE/ETH_CHASSIS: C514.1, J500.SH (SHIELD), R506.1
/GbE/ETH_CT: C513.1, J500.3 (CT1), J500.6 (CT2), J500.9 (CT3), J500.12 (CT4)
/GbE/ETH_LED_1000_A: J500.16 (GREEN_A), R505.2
/GbE/ETH_LED_1000_N: J500.15 (GREEN_K), U500.26 (LED1)
/GbE/ETH_LED_ACT_A: J500.14 (YELLOW_A), R504.2
/GbE/ETH_LED_ACT_N: J500.13 (YELLOW_K), U500.25 (LED2)
/GbE/ETH_MDI0_N: J500.2 (MD1-), U500.2 (MDIN0), U501.2
/GbE/ETH_MDI0_P: J500.1 (MD1+), U500.1 (MDIP0), U501.1
/GbE/ETH_MDI1_N: J500.5 (MD2-), U500.5 (MDIN1), U501.5
/GbE/ETH_MDI1_P: J500.4 (MD2+), U500.4 (MDIP1), U501.4
/GbE/ETH_MDI2_N: J500.8 (MD3-), U500.7 (MDIN2), U502.2
/GbE/ETH_MDI2_P: J500.7 (MD3+), U500.6 (MDIP2), U502.1
/GbE/ETH_MDI3_N: J500.11 (MD4-), U500.10 (MDIN3), U502.5
/GbE/ETH_MDI3_P: J500.10 (MD4+), U500.9 (MDIP3), U502.4
/GbE/ETH_RSET: R501.1, U500.31 (RSET)
/GbE/ETH_XI: C515.1, R500.1, U500.28 (CKXTAL1), Y500.1
/GbE/ETH_XO: C516.1, R500.2, U500.29 (CKXTAL2), Y500.3
/GbE/GBE_HSI_N: C501.2, U500.14 (HSIN)
/GbE/GBE_HSI_P: C500.2, U500.13 (HSIP)
/GbE/GBE_HSO_N: C503.1, U500.18 (HSON)
/GbE/GBE_HSO_P: C502.1, U500.17 (HSOP)
/GbE/GBE_ISOLATE_N: R502.2, U500.20 (ISOLATEB)
/PCIE_3V3: C504.1, C505.1, C506.1, C2293.1, R502.1, R503.1, R504.1, R505.1, U500.11 (AVDD33), U500.23 (VDDREG), U500.32 (AVDD33); also elsewhere on the board
/PCIE_WAKE_N: R503.2, U500.21 (LANWAKEB); also elsewhere on the board
/PLTRST_SRC_N: U500.19 (PERSTB); also elsewhere on the board
GND: C504.2, C505.2, C506.2, C507.2, C508.2, C509.2, C510.2, C511.2, C512.2, C513.2, C514.2, C515.2, C516.2, C2293.2, R501.2, R506.2, U500.33 (GND), U501.3 (VSS), U501.8 (VSS), U502.3 (VSS), U502.8 (VSS), Y500.2 (G), Y500.4 (G); also elsewhere on the board

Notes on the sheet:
== Native PCIe Gigabit Ethernet on LattePanda Mu default HSIO6 ==
RTL8111H support circuit follows LattePanda's DFR1142 Mu carrier reference: HSIO6, REFCLK4, CLKREQ4, and PLT_RST.
JXD1-1022NL is a true recessed through-hole mid-mount RJ45 with integrated magnetics; no external transformer is required.
== PCIe x1 host TX from Mu to RTL8111H; C500/C501 are at the Mu transmitter pads, not by U500 ==
== RTL8111H 3.3V / internal 1.0V rails and reset-side straps ==
== 25MHz reference crystal; 12pF legs implement the qualified 8pF load including about 2pF stray ==
== Four 100-ohm MDI pairs, low-capacitance ESD, and integrated-magnetics RJ45 ==
== Connector shield / aluminum chassis interface ==
LAYOUT: PCIe Gen3 pairs are 85-ohm differential; for this on-board PCIe device, place C500-C503 beside U500 per the Mu guide and route over an uninterrupted reference plane.
LAYOUT: MDI pairs are 100-ohm differential. Put U501/U502 immediately behind J500, avoid stubs, and do not route digital signals under the magnetics.
MECHANICAL: manufacturer body 17.58 x 26.06 x 11.30mm; PCB/panel plane is 2.03mm behind the front face; panel opening 17.98 x 9.69mm.
RELEASE HOLD: verify all four unnumbered shell stakes are common and confirm LED copper lands on one physical JXD1 sample before ordering the motherboard.
ASSEMBLY HOLD: ask the assembler to confirm through-hole mid-mount RJ45 support and whether J500 is manual/post-reflow insertion.
LED HOLD: RTL8111H pin 26 is the default 1000M indication, not a generic link LED. Verify both jack LEDs at 10/100/1000 on hardware.

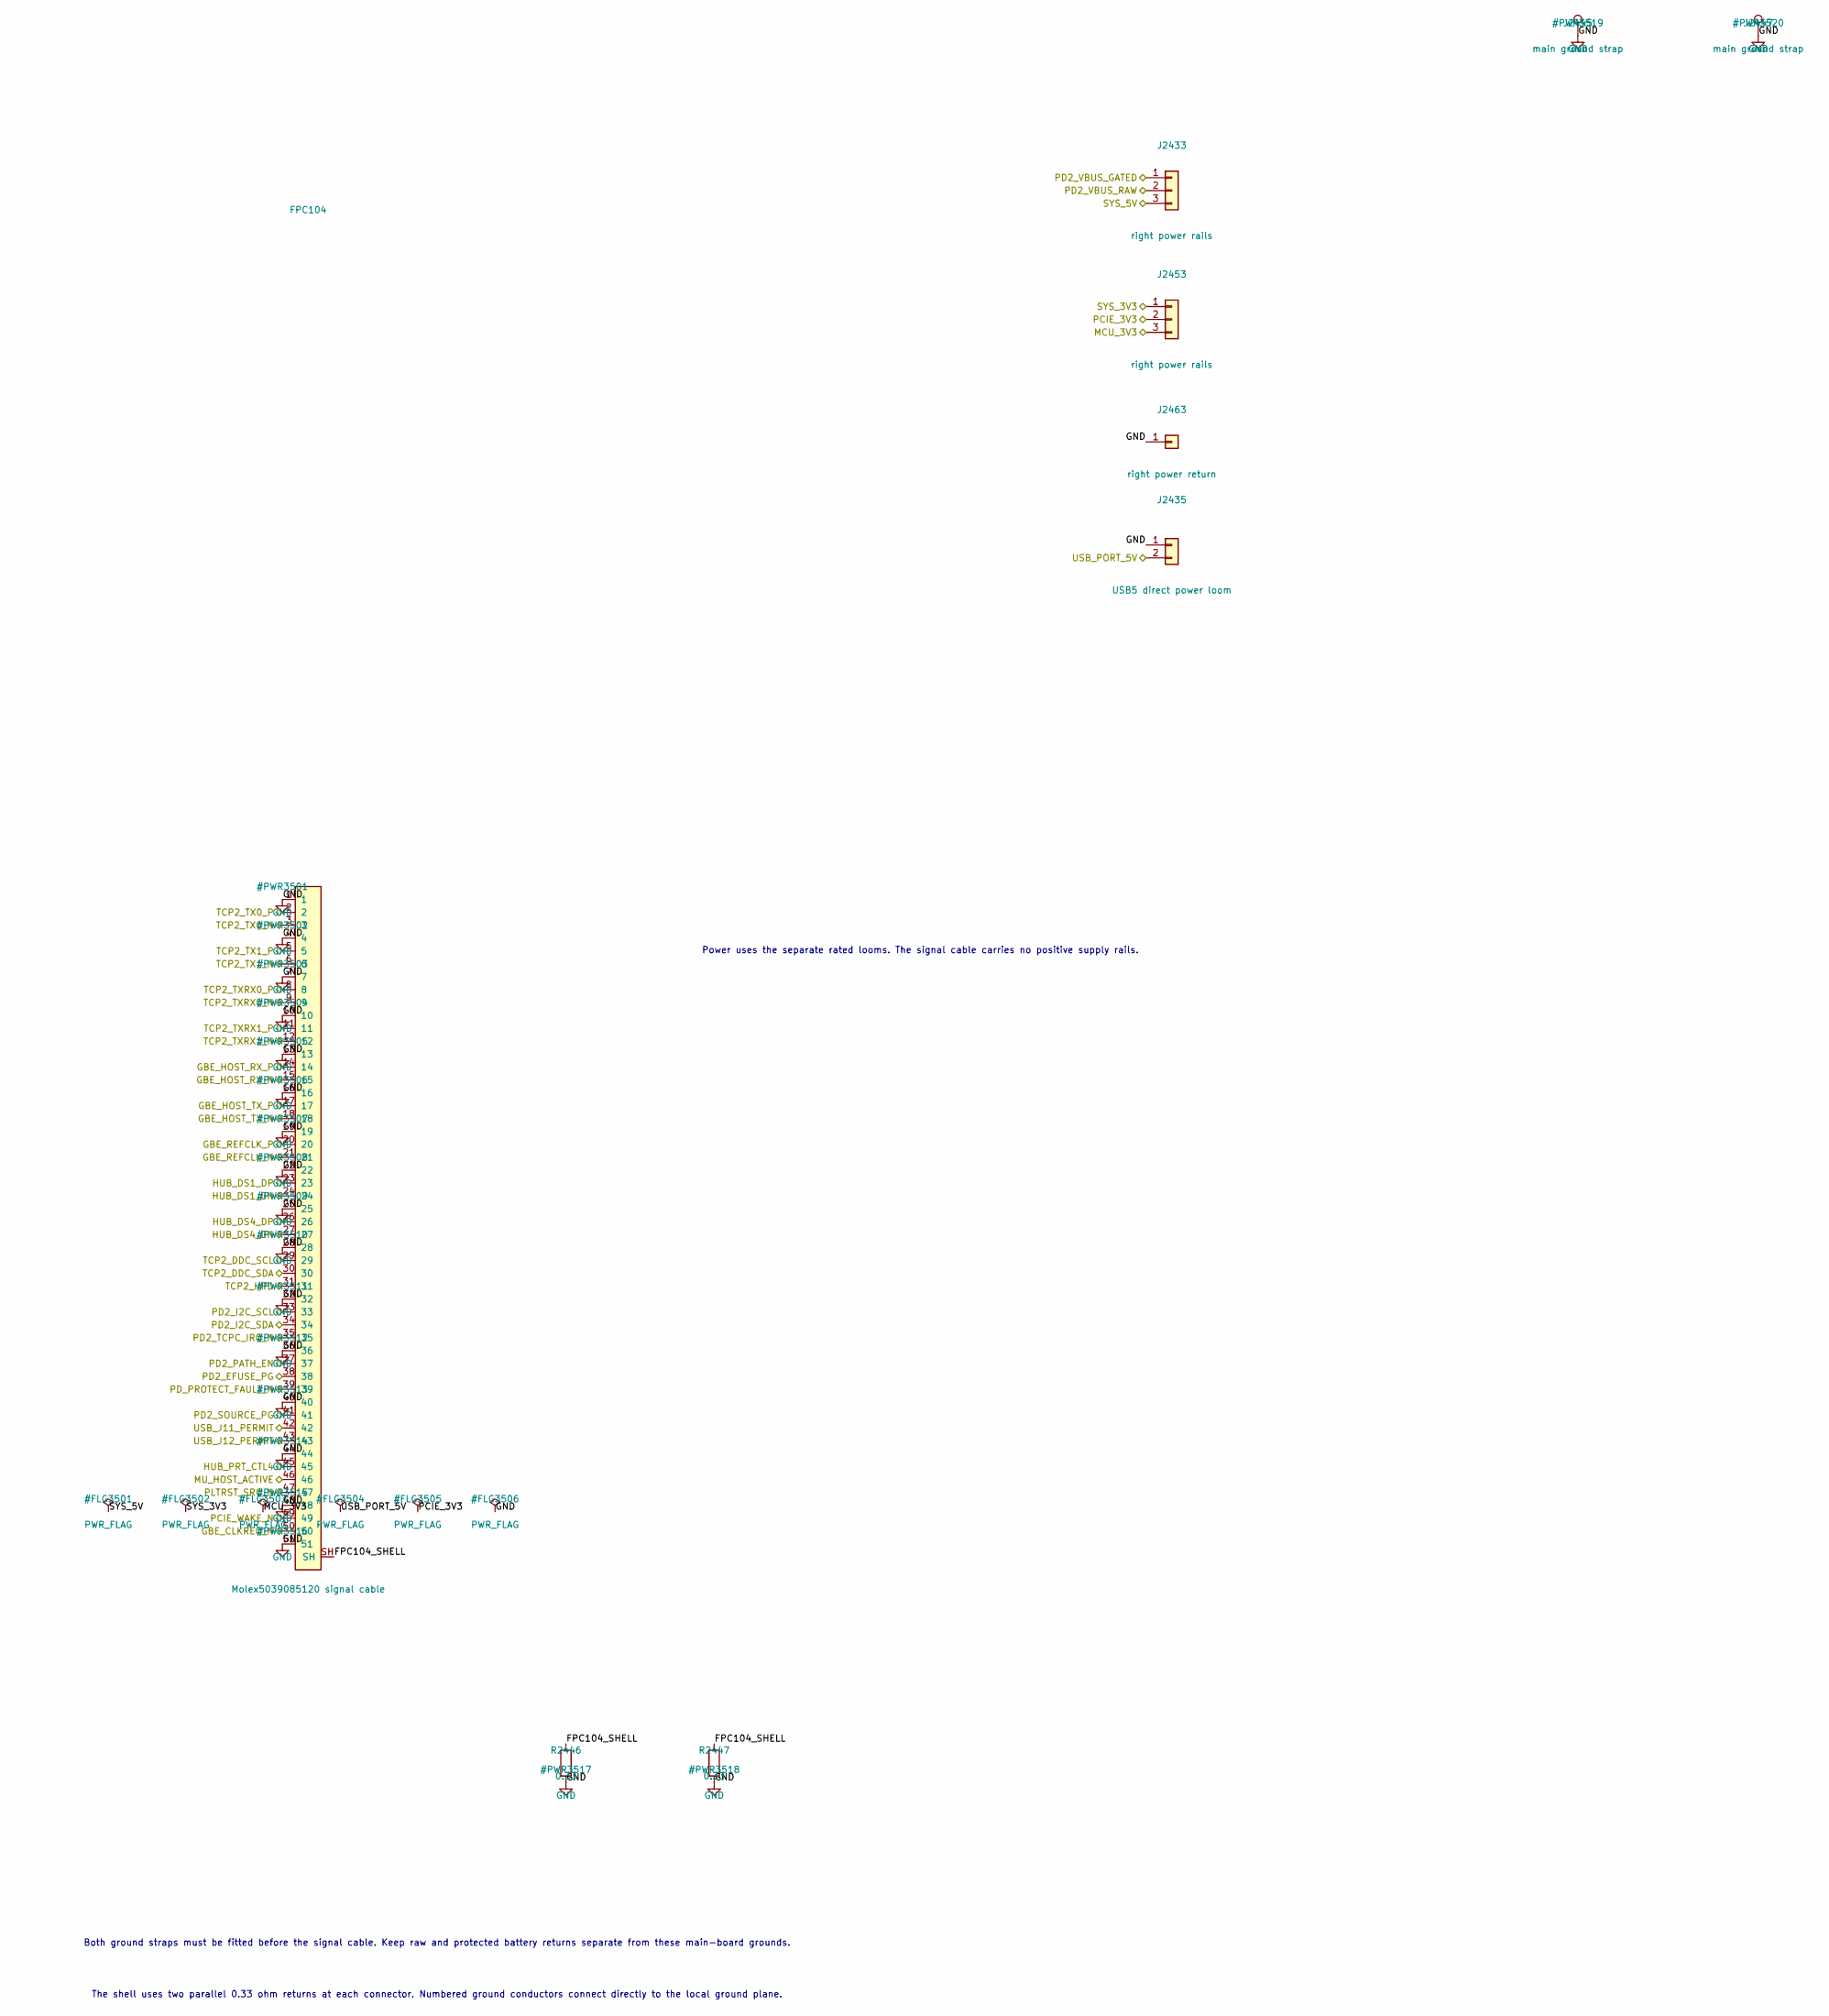
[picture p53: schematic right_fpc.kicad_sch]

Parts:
FPC104: Molex5039085120 signal cable; Molex_5039085120_1x51_P0.50mm_Horizontal; MPN 5039085120
J2433, J2453: right power rails; WAGO_2060_453_SMD; MPN 2060-453/998-404
J2435: USB5 direct power loom; AMASS_XT30PW-F30_G_Y; MPN XT30PW-F30.G.Y
J2445, J2447: main ground strap; SolderWirePad_1x01_SMD_5x10mm
J2463: right power return; WAGO_2060_451_SMD; MPN 2060-451/998-404
R2446, R2447: 0.33; R_0603_1608Metric; MPN ERJ3RQFR33V

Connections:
/FPC-2 (to Center)/FPC104_SHELL: FPC104.SH, R2446.1, R2447.1
/GBE_CLKREQ_N: FPC104.50; also elsewhere on the board
/GBE_HOST_RX_N: FPC104.15; also elsewhere on the board
/GBE_HOST_RX_P: FPC104.14; also elsewhere on the board
/GBE_HOST_TX_N: FPC104.18; also elsewhere on the board
/GBE_HOST_TX_P: FPC104.17; also elsewhere on the board
/GBE_REFCLK_N: FPC104.21; also elsewhere on the board
/GBE_REFCLK_P: FPC104.20; also elsewhere on the board
/HUB_DS1_DN: FPC104.24; also elsewhere on the board
/HUB_DS1_DP: FPC104.23; also elsewhere on the board
/HUB_DS4_DN: FPC104.27; also elsewhere on the board
/HUB_DS4_DP: FPC104.26; also elsewhere on the board
/HUB_PRT_CTL4: FPC104.45; also elsewhere on the board
/MCU_3V3: J2453.3; also elsewhere on the board
/MU_HOST_ACTIVE: FPC104.46; also elsewhere on the board
/PCIE_3V3: J2453.2; also elsewhere on the board
/PCIE_WAKE_N: FPC104.49; also elsewhere on the board
/PD2_EFUSE_PG: FPC104.38; also elsewhere on the board
/PD2_I2C_SCL: FPC104.33; also elsewhere on the board
/PD2_I2C_SDA: FPC104.34; also elsewhere on the board
/PD2_PATH_EN: FPC104.37; also elsewhere on the board
/PD2_SOURCE_PG: FPC104.41; also elsewhere on the board
/PD2_TCPC_IRQ_N: FPC104.35; also elsewhere on the board
/PD2_VBUS_GATED: J2433.1; also elsewhere on the board
/PD2_VBUS_RAW: J2433.2; also elsewhere on the board
/PD_PROTECT_FAULT_N: FPC104.39; also elsewhere on the board
/PLTRST_SRC_N: FPC104.47; also elsewhere on the board
/SYS_3V3: J2453.1; also elsewhere on the board
/SYS_5V: J2433.3; also elsewhere on the board
/TCP2_DDC_SCL: FPC104.29; also elsewhere on the board
/TCP2_DDC_SDA: FPC104.30; also elsewhere on the board
/TCP2_HPD: FPC104.31; also elsewhere on the board
/TCP2_TX0_N: FPC104.3; also elsewhere on the board
/TCP2_TX0_P: FPC104.2; also elsewhere on the board
/TCP2_TX1_N: FPC104.6; also elsewhere on the board
/TCP2_TX1_P: FPC104.5; also elsewhere on the board
/TCP2_TXRX0_N: FPC104.9; also elsewhere on the board
/TCP2_TXRX0_P: FPC104.8; also elsewhere on the board
/TCP2_TXRX1_N: FPC104.12; also elsewhere on the board
/TCP2_TXRX1_P: FPC104.11; also elsewhere on the board
/USB_J11_PERMIT: FPC104.42; also elsewhere on the board
/USB_J12_PERMIT: FPC104.43; also elsewhere on the board
/USB_PORT_5V: J2435.2; also elsewhere on the board
GND: FPC104.1, FPC104.4, FPC104.7, FPC104.10, FPC104.13, FPC104.16, FPC104.19, FPC104.22, FPC104.25, FPC104.28, FPC104.32, FPC104.36, FPC104.40, FPC104.44, FPC104.48, FPC104.51, J2435.1, J2445.1, J2447.1, J2463.1, R2446.2, R2447.2; also elsewhere on the board

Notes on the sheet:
Power uses the separate rated looms. The signal cable carries no positive supply rails.
Both ground straps must be fitted before the signal cable. Keep raw and protected battery returns separate from these main-board grounds.
The shell uses two parallel 0.33 ohm returns at each connector. Numbered ground conductors connect directly to the local ground plane.

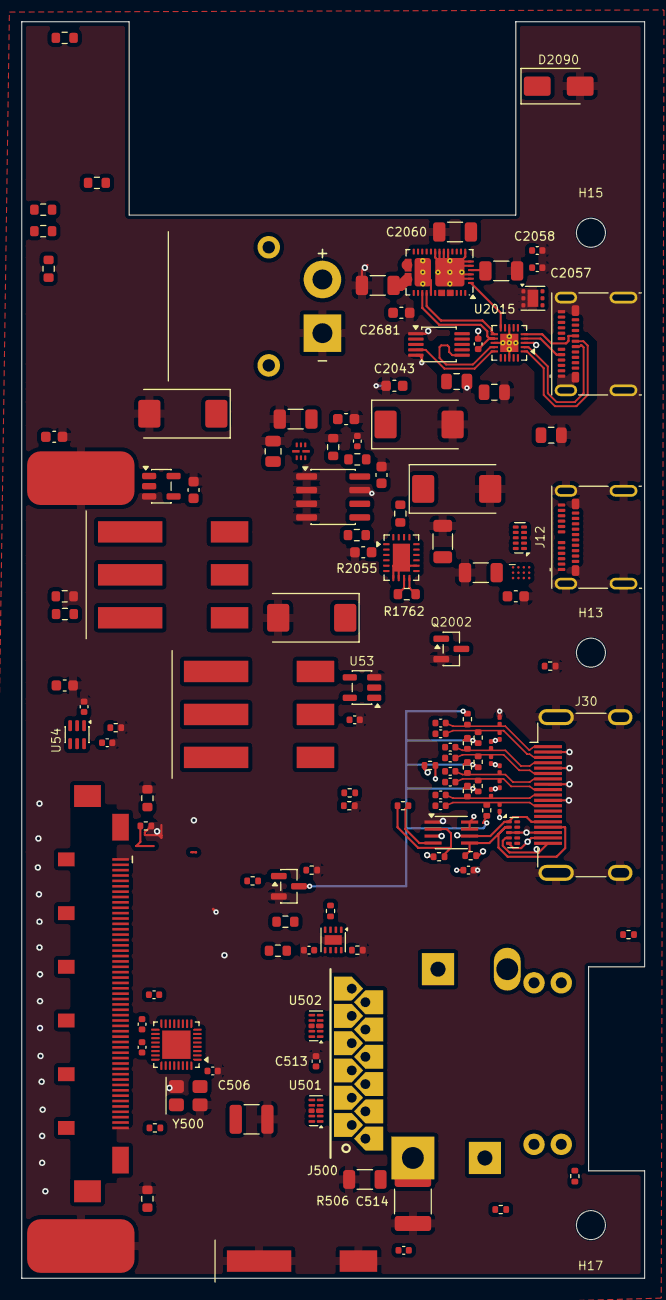
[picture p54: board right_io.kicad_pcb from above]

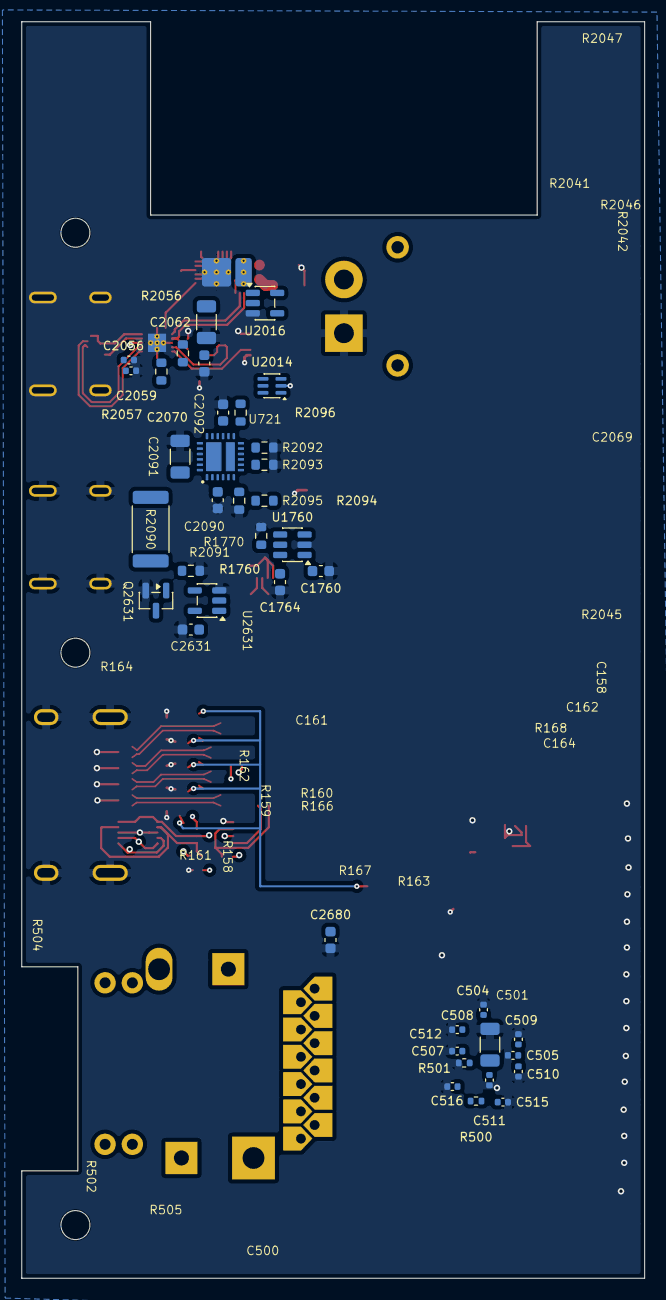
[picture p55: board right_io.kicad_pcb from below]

Board: 8 copper layers, 58.0 x 117.0 mm, 173 parts (39 on the bottom side), 128 nets.

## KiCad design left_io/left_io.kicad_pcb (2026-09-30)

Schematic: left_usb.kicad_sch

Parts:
C1705: 120p core feed-forward; C_0402_1005Metric; MPN GRM1555C1H121JA01D
C1706: 4.7u core input; C_0805_2012Metric; MPN GRM21BR71A475KA73L
C1707: 100n core input HF; C_0603_1608Metric; MPN GRM188R71H104KA93D
C1708, C1709: 10u core output; C_0805_2012Metric; MPN GRM21BR71A106KE51L
C1710: 47n 25V USB5 bootstrap; C_0402_1005Metric; MPN GRM155R71E473KA88D
C1711, C1712: 10u 50V USB5 input; C_1206_3216Metric; MPN CGA5L1X7R1H106K160AC
C1713, C1867: 100n 50V USB5 input HF; C_0603_1608Metric; MPN GRM188R71H104KA93D
C1714, C1715, C1868, C1869: 22u 25V USB5 output; TI characterized part; C_1210_3225Metric; MPN GRM32ER71E226KE15L
C1716: 100n oscillator bypass; C_0603_1608Metric; MPN GRM188R71H104KA93D
C1717: 100n hub reset-gate bypass; C_0603_1608Metric; MPN GRM188R71H104KA93D
C1722, C1723, C1724, C1725, C1728, C1729: 100n USB 3.2 TX AC coupling; C_0402_1005Metric; MPN GRM155R71C104KA88D
C1740, C1780: 100n branch input; C_0603_1608Metric; MPN GRM188R71H104KA93D
C1741, C1781: 100n TPS25810 IN HF; C_0603_1608Metric; MPN GRM188R71H104KA93D
C1742, C1782: 150u 10V TPS25810 input reservoir; CP_EIA-7343-31_Kemet-D; MPN T520D157M010ATE025
C1743, C1783: 10u protected VBUS_SYS; C_1206_3216Metric; MPN GRM31CR71A106KA01L
C1744, C1784: 100n TPS25810 AUX; C_0603_1608Metric; MPN GRM188R71H104KA93D
C1745, C1746, C1747, C1785, C1786, C1787: 100n mux VDD; C_0603_1608Metric; MPN GRM188R71H104KA93D
C1748, C1788: 1u mux local bulk; C_0603_1608Metric; MPN GRM188R71A105KA61D
C1749, C1789: 10n mux HF; C_0402_1005Metric; MPN GRM155R71H103KA88D
C1750, C1790: 1u 50V connector-side VBUS; C_0805_2012Metric; MPN GRM21BR71H105KA12L
C1751, C1791: 1u TPD1S514 VBUS_POWER stability; C_0603_1608Metric; MPN GRM188R71A105KA61D
C1810, C1811, C1812, C1813, C1814, C1815, C1816, C1817: 100n USB7206C VDD33 local; C_0603_1608Metric; MPN GRM188R71H104KA93D
C1820, C1821, C1822, C1823, C1824, C1825, C1826, C1827, C1828: 100n USB7206C VCORE local; C_0603_1608Metric; MPN GRM188R71H104KA93D
C1830, C1831, C1832, C1833, C1834, C1835, C1836, C1837: 1n USB7206C VDD33 HF; C_0402_1005Metric; MPN GRM155R71H102KA01D
C1840, C1841, C1842, C1843, C1844, C1845, C1846, C1847, C1848: 1n USB7206C VCORE HF; C_0402_1005Metric; MPN GRM155R71H102KA01D
C1849: 10u USB7206C VDD33 bulk; C_0805_2012Metric; MPN GRM21BR71A106KE51L
C1850: 10u 10V USB3-A VBUS bulk; C_0805_2012Metric; MPN GRM21BR71A106KA73L
C1851: 100n USB3-A VBUS HF; C_0603_1608Metric; MPN GRM188R71H104KA93D
C1852: 100n 16V X7R USB3-A SSTX+ series AC; C_0402_1005Metric; MPN GRM155R71C104KA88D
C1853: 100n 16V X7R USB3-A SSTX- series AC; C_0402_1005Metric; MPN GRM155R71C104KA88D
C1854: 10u 10V USB2-A VBUS bulk; C_0805_2012Metric; MPN GRM21BR71A106KA73L
C1855: 100n USB2-A VBUS HF; C_0603_1608Metric; MPN GRM188R71H104KA93D
C1860: 22u 25V USB5 VCC; effective minimum 4.7u; C_1210_3225Metric; MPN GRM32ER71E226KE15L
C1861: 100n 50V USB5 VDDA; C_0603_1608Metric; MPN GRM188R71H104KA93D
C1862: 220n 50V X7R USB5 COMP; C_0603_1608Metric; MPN C0603C224K5RACTU
C1863: 2.2n 50V C0G USB5 COMP HF; C_0603_1608Metric; MPN C0603C222J5GACTU
C1864, C1865: 330u 10V USB5 local reservoir; 4.3mm max height; CP_EIA-7343-43_Kemet-X; MPN T520X337M010ATE010
C1866: DNP 68u 25V input damping option; CP_EIA-7343-20_Kemet-V; MPN T521V686M025ATE050; not fitted
C2400, C2401, C2402, C2405, C2406, C2407, C2408, C2410, C2411, C2415: 100n; C_0603_1608Metric; MPN GRM188R71H104KA93D
C2683: 1u 50V U1800 input bypass; C_0603_1608Metric; MPN GRT188R61H105ME13D
C2684: 1u 50V U1803 input bypass; C_0603_1608Metric; MPN GRT188R61H105ME13D
D1800, D1801, D1802, D1803, D1804, D1805, D1806, D1807, D1808, D1809, D1810, D1811, D1812, D1813, D1814, D1815: TPD1E0B04DPLR 0.13pF USB3 ESD; D_0201_0603Metric; MPN TPD1E0B04DPLR
J22: USB-C source-only data port J22; USB_C_Receptacle_Molex_105450-0101; MPN 105450-0101
J23: USB-C source-only data port J23; USB_C_Receptacle_Molex_105450-0101; MPN 105450-0101
J24: USB 3.0 Type-A internal header (hub DIS5); USB_A_Receptacle_XKB_U231-091N-4BLRA00-S; MPN U231-091N-4BLRA00-S
J25: USB 2.0 Type-A internal header (hub DIS6); USB_A_Receptacle_GCT_USB1046; MPN USB1046-GF-L
L1700: 470nH >=3.9A USB hub core; TDK_TFM201610; MPN TFM201610ALMA-R47MTAA
L1701: 6.8uH 18.4A Isat30 / 10.9A Irms20; Coilcraft_XGL1060; MPN XGL1060-682MEC
R1700: 10k CFG_STRAP1; R_0603_1608Metric; MPN RC0603FR-0710KL
R1701: 200k CFG_STRAP2; R_0603_1608Metric; MPN RC0603FR-07200KL
R1702: 200k CFG_STRAP3; R_0603_1608Metric; MPN RC0603FR-07200KL
R1703: 200k all ports removable; R_0603_1608Metric; MPN RC0603FR-07200KL
R1704: 200k BC1.2 disabled; R_0603_1608Metric; MPN RC0603FR-07200KL
R1705: 91.0k 0.02% 5ppm core FB top; R_0603_1608Metric; MPN TNPU060391K0HZEN00
R1706: 100k 0.02% 5ppm core FB bottom; R_0603_1608Metric; MPN TNPU0603100KHZEN00
R1707: 100k core PG pull-up; R_0603_1608Metric; MPN RC0603FR-07100KL
R1708: 12.0k 1% USB7206C RBIAS; R_0603_1608Metric; MPN RC0603FR-0712KL
R1710: 100k USB5 hardware-qualified EN top; R_0603_1608Metric; MPN RC0603FR-07100KL
R1711: 100k USB5 EN bottom; R_0603_1608Metric; MPN RC0603FR-07100KL
R1712: 55.6k 0.02% 5ppm USB5 FB top; R_0603_1608Metric; MPN TNPU060355K6HZEN00
R1713: 10.2k 0.02% 5ppm USB5 FB bottom; R_0603_1608Metric; MPN TNPU060310K2HZEN00
R1714: 100k USB5 PG pull-up; R_0603_1608Metric; MPN RC0603FR-07100KL
R1715, R1716, R1717: 10k TEST pull-up; R_0603_1608Metric; MPN RC0603FR-0710KL
R1718: 10k hub 3V3 supervisor pull-up; R_0603_1608Metric; MPN RC0603FR-0710KL
R1720, R1721, R1722, R1723: 100k unused SPI pull-down; R_0603_1608Metric; MPN RC0603FR-07100KL
R1740, R1780: 19.1k 1% TPS2553 VBUS plus VCONN ILIM; R_0603_1608Metric; MPN RC0603FR-0719K1L
R1741, R1781: 4.99k POL pull-up; R_0603_1608Metric; MPN RC0603FR-074K99L
R1742, R1782: 100k 1% TPS25810 REF; R_0603_1608Metric; MPN RC0603FR-07100KL
R1750, R1790: 249R 0.25W TPS25810 OUT discharge; R_1206_3216Metric; MPN RC1206FR-07249RL
R1840: 10k DS1 PRT_CTL idle pull-up; VBUS is managed by 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; R_0603_1608Metric; MPN RC0603FR-0710KL
R1841: 10k DS4 PRT_CTL idle pull-up (J12 branch enable, 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; R_0603_1608Metric; MPN RC0603FR-0710KL
R1850, R1851: 20.0k 1% TPS2553 1.3A ILIM; R_0603_1608Metric; MPN RC0603FR-0720KL
R1860: 22.1k 0.02% 5ppm USB5 RT; R_0603_1608Metric; MPN TNPU060322K1HZEN00
R1861: 29.4k 1% standalone DRSS off; R_0603_1608Metric; MPN RC0603FR-0729K4L
R1862: 2.49k 0.02% 5ppm USB5 COMP; R_0603_1608Metric; MPN TNPU06032K49HZEN00
R1863: 1R USB5 bootstrap damping; R_0603_1608Metric; MPN RC0603FR-071RL
R2400, R2401, R2402, R2412, R2429: 10k; R_0603_1608Metric; MPN RC0603FR-0710KL
R2405, R2406, R2407, R2408, R2410, R2420, R2421, R2422, R2423, R2426, R2427: 100k; R_0603_1608Metric; MPN RC0603FR-07100KL
R2424, R2425: 12.7k 1%; R_0603_1608Metric; MPN RC0603FR-0712K7L
RS1860, RS1861: 10mOhm 1% 1W USB5 sense; parallel pair gives 5mOhm; Panasonic_ERJ8CW_10to16m; MPN ERJ8CWFR010V
U1700: USB7206C-I/KDX six-port USB 3.2 Gen 2 hub; VQFN-100-1EP_12x12mm_P0.4mm_EP8x8mm_ThermalVias; MPN USB7206C-I/KDX
U1701: TPS62823DLC 3A USB7206C 1.146V core buck; Texas_VSON-HR-8_1.5x2mm_P0.5mm; MPN TPS62823DLC
U1702: TLV803EA29 USB hub reset supervisor; SOT-23-3; MPN TLV803EA29RDBZR
U1703: LM706A0RRXR USB5 5.161V; 6.5A design envelope; Texas_RRX0029B_VQFN-29_6x6mm; MPN LM706A0RRXR
U1704: SN74LVC1G08 hub 3V3/core-PG reset gate; SOT-23-5; MPN SN74LVC1G08DBVR
U1740, U1780: TPS2553DDBVR 1.3A USB branch; SOT-23-6; MPN TPS2553DDBVR
U1741, U1781: TPS25810RVCR Type-C DFP controller; Texas_RVC0020A_WQFN-20-1EP_3x4mm_P0.5mm_EP1.6x2.6mm; MPN TPS25810RVCR
U1742, U1782: HD3SS6126RUAR USB3 orientation mux; WQFN-42-1EP_3.5x9mm_P0.5mm_EP2.05x7.55mm_ThermalVias; MPN HD3SS6126RUAR
U1743, U1783: TPD1S514-1YZR 5.9V VBUS OVP; Texas_TPD1S514_YZ_WCSP-12_1.99x1.29mm_P0.5mm; MPN TPD1S514-1YZR
U1745, U1785: TPD4E05U06 USB2/CC ESD; USON-10_2.5x1.0mm_P0.5mm; MPN TPD4E05U06DQAR
U1800: TPS2553DDBVR USB3-A VBUS branch 1.3A; SOT-23-6; MPN TPS2553DDBVR
U1801: USBLC6-2P6 USB3-A D+/D- ESD; SOT-666; MPN USBLC6-2P6
U1802: TPD4E05U06 USB3-A SuperSpeed ESD; USON-10_2.5x1.0mm_P0.5mm; MPN TPD4E05U06DQAR
U1803: TPS2553DDBVR USB2-A VBUS branch 1.3A; SOT-23-6; MPN TPS2553DDBVR
U1804: USBLC6-2P6 USB2-A D+/D- ESD; SOT-666; MPN USBLC6-2P6
U2400: TCA9539PWR USB permissions @0x76; TSSOP-24_4.4x7.8mm_P0.65mm; MPN TCA9539PWR
U2401: INA226AIDGSR USB5 monitor @0x40; TSSOP-10_3x3mm_P0.5mm; MPN INA226AIDGSR
U2402: SN74LVC1G74DCUR USB fault latch; TI_DCU0008A_VSSOP8; MPN SN74LVC1G74DCUR
U2405: SN74LVC1G08DBVR J22 source permission; SOT-23-5; MPN SN74LVC1G08DBVR
U2406: SN74LVC1G08DBVR J23 source permission; SOT-23-5; MPN SN74LVC1G08DBVR
U2407: SN74LVC1G08DBVR J24 source permission; SOT-23-5; MPN SN74LVC1G08DBVR
U2408: SN74LVC1G08DBVR J25 source permission; SOT-23-5; MPN SN74LVC1G08DBVR
U2410: SN74LVC1G11DCKR USB5 permit AND; SOT-363_SC-70-6; MPN SN74LVC1G11DCKR
U2411: SN74LVC1G08DBVR raw fault veto; SOT-23-5; MPN SN74LVC1G08DBVR
U2413: SN74LVC1G08DBVR raw OC and SYS5 veto; SOT-23-5; MPN SN74LVC1G08DBVR
Y1700: 25.000MHz 3.3V USB hub oscillator; Oscillator_SMD_Abracon_ASDMB-4Pin_2.5x2.0mm; MPN ASDMB-25.000MHZ-LC-T

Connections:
/HUB_DS1_DN: U1700.6 (DM1); also elsewhere on the board
/HUB_DS1_DP: U1700.5 (DP1); also elsewhere on the board
/HUB_DS4_DN: U1700.35 (DM4); also elsewhere on the board
/HUB_DS4_DP: U1700.34 (DP4); also elsewhere on the board
/HUB_PRT_CTL4: R1841.2, U1700.57 (PF14); also elsewhere on the board
/INTERNAL_USB_VBUS_VALID: R2426.1, U1700.2 (PF30/VBUS_DET), U2400.19 (IO1_6), U2407.2, U2408.2, U2413.2; also elsewhere on the board
/MCU_3V3: C2400.1, C2401.1, C2402.1, C2405.1, C2406.1, C2407.1, C2408.1, C2410.1, C2411.1, C2415.1, R2401.1, R2402.1, U2400.2 (A1), U2400.24 (V_{DD}), U2401.6 (VS), U2402.8 (VCC), U2405.5 (VCC), U2406.5 (VCC), U2407.5 (VCC), U2408.5 (VCC), U2410.5 (VCC), U2411.5 (VCC), U2413.5 (VCC); also elsewhere on the board
/PD1_I2C_SCL: U2400.22 (SCL), U2401.5 (SCL); also elsewhere on the board
/PD1_I2C_SDA: U2400.23 (SDA), U2401.4 (SDA); also elsewhere on the board
/PD1_SOURCE_PG: R2424.1, U2400.17 (IO1_4); also elsewhere on the board
/PD2_SOURCE_PG: R2425.1, U2400.18 (IO1_5); also elsewhere on the board
/SERVICE_MUX_RESET_N: R2420.1, U2400.3 (~RESET); also elsewhere on the board
/SYS_3V3: C1706.1, C1707.1, C1716.1, C1717.1, C1744.1, C1745.1, C1746.1, C1747.1, C1748.1, C1749.1, C1784.1, C1785.1, C1786.1, C1787.1, C1788.1, C1789.1, C1810.1, C1811.1, C1812.1, C1813.1, C1814.1, C1815.1, C1816.1, C1817.1, C1830.1, C1831.1, C1832.1, C1833.1, C1834.1, C1835.1, C1836.1, C1837.1, C1849.1, R1707.1, R1714.1, R1715.1, R1716.1, R1717.1, R1718.1, R1741.1, R1781.1, R1840.1, R1841.1, R2412.1, U1700.26 (VDD33), U1700.43 (VDD33), U1700.53 (VDD33), U1700.62 (VDD33), U1700.67 (VDD33), U1700.79 (VDD33), U1700.88 (VDD33), U1700.99 (VDD33), U1701.1 (EN), U1701.7 (VIN), U1702.3 (VDD), U1704.5 (VCC), U1741.5 (AUX), U1742.13 (VDD), U1742.20 (VDD), U1742.30 (VDD), U1781.5 (AUX), U1782.13 (VDD), U1782.20 (VDD), U1782.30 (VDD), U2410.6, Y1700.1 (Standby), Y1700.4 (VDD); also elsewhere on the board
/USB Hub + Ports/HUB_3V3_OK: R1718.2, U1702.1 (RESETz), U1704.1
/USB Hub + Ports/HUB_BC_EN: R1704.1, U1700.70 (SPI_D0/CFG_BC_EN/PF22)
/USB Hub + Ports/HUB_CFG1: R1700.1, U1700.21 (CFG_STRAP1)
/USB Hub + Ports/HUB_CFG2: R1701.1, U1700.22 (CFG_STRAP2)
/USB Hub + Ports/HUB_CFG3: R1702.1, U1700.23 (CFG_STRAP3)
/USB Hub + Ports/HUB_CLK: U1700.98 (XTALI/CLK_IN), Y1700.3 (Out)
/USB Hub + Ports/HUB_CORE_FB: C1705.2, R1705.2, R1706.1, U1701.2 (FB)
/USB Hub + Ports/HUB_CORE_PG: R1707.2, U1701.8 (PG), U1704.2
/USB Hub + Ports/HUB_CORE_SW: L1700.1, U1701.6 (SW)
/USB Hub + Ports/HUB_DIS5_DN: J24.2 (D-), U1700.82 (DM5), U1801.3 (I/O2), U1801.4 (I/O2)
/USB Hub + Ports/HUB_DIS5_DP: J24.3 (D+), U1700.81 (DP5), U1801.1 (I/O1), U1801.6 (I/O1)
/USB Hub + Ports/HUB_DIS5_RX_N: J24.5 (StdA_SSRX-), U1700.87 (RXDM5), U1802.5 (D2-)
/USB Hub + Ports/HUB_DIS5_RX_P: J24.6 (StdA_SSRX+), U1700.86 (RXDP5), U1802.4 (D2+)
/USB Hub + Ports/HUB_DIS5_TX_N: C1853.1, U1700.84 (TXDM5), U1802.2 (D1-)
/USB Hub + Ports/HUB_DIS5_TX_P: C1852.1, U1700.83 (TXDP5), U1802.1 (D1+)
/USB Hub + Ports/HUB_DIS6_DN: J25.2 (D-), U1700.41 (DM6), U1804.3 (I/O2), U1804.4 (I/O2)
/USB Hub + Ports/HUB_DIS6_DP: J25.3 (D+), U1700.42 (DP6), U1804.1 (I/O1), U1804.6 (I/O1)
/USB Hub + Ports/HUB_DS1_PRT_CTL: R1840.2, U1700.60 (PF17)
/USB Hub + Ports/HUB_DS2_DN: J22.A7 (D-), J22.B7 (D-), U1700.15 (DM2), U1785.2 (D1-)
/USB Hub + Ports/HUB_DS2_DP: J22.A6 (D+), J22.B6 (D+), U1700.14 (DP2), U1785.1 (D1+)
/USB Hub + Ports/HUB_DS2_SSRX_N: U1700.20 (RXDM2), U1782.16 (SSA1(n))
/USB Hub + Ports/HUB_DS2_SSRX_P: U1700.19 (RXDP2), U1782.15 (SSA1(p))
/USB Hub + Ports/HUB_DS2_SSTX_N: C1723.2, U1782.12 (SSA0(n))
/USB Hub + Ports/HUB_DS2_SSTX_P: C1722.2, U1782.11 (SSA0(p))
/USB Hub + Ports/HUB_DS2_TX_RAW_N: C1723.1, U1700.17 (TXDM2)
/USB Hub + Ports/HUB_DS2_TX_RAW_P: C1722.1, U1700.16 (TXDP2)
/USB Hub + Ports/HUB_DS3_DN: J23.A7 (D-), J23.B7 (D-), U1700.28 (DM3), U1745.2 (D1-)
/USB Hub + Ports/HUB_DS3_DP: J23.A6 (D+), J23.B6 (D+), U1700.27 (DP3), U1745.1 (D1+)
/USB Hub + Ports/HUB_DS3_SSRX_N: U1700.33 (RXDM3), U1742.16 (SSA1(n))
/USB Hub + Ports/HUB_DS3_SSRX_P: U1700.32 (RXDP3), U1742.15 (SSA1(p))
/USB Hub + Ports/HUB_DS3_SSTX_N: C1725.2, U1742.12 (SSA0(n))
/USB Hub + Ports/HUB_DS3_SSTX_P: C1724.2, U1742.11 (SSA0(p))
/USB Hub + Ports/HUB_DS3_TX_RAW_N: C1725.1, U1700.30 (TXDM3)
/USB Hub + Ports/HUB_DS3_TX_RAW_P: C1724.1, U1700.29 (TXDP3)
/USB Hub + Ports/HUB_NON_REM: R1703.1, U1700.69 (SPI_CE_N/CFG_NON_REM/PF20)
/USB Hub + Ports/HUB_PRT_CTL2: U1700.59 (PF16), U1780.4 (~FAULT), U1781.1 (~FAULT), U2405.2
/USB Hub + Ports/HUB_PRT_CTL3: U1700.58 (PF15), U1740.4 (~FAULT), U1741.1 (~FAULT), U2406.2
/USB Hub + Ports/HUB_RBIAS: R1708.1, U1700.100 (RBIAS)
/USB Hub + Ports/HUB_RESET_N: U1700.1 (RESET_N), U1704.4
/USB Hub + Ports/HUB_SPI_CLK: R1720.1, U1700.68 (SPI_CLK/PF21)
/USB Hub + Ports/HUB_SPI_D1: R1721.1, U1700.71 (SPI_D1/PF23)
/USB Hub + Ports/HUB_SPI_D2: R1722.1, U1700.72 (SPI_D2/PF24)
/USB Hub + Ports/HUB_SPI_D3: R1723.1, U1700.73 (SPI_D3/PF25)
/USB Hub + Ports/HUB_TEST1: R1715.2, U1700.63 (TEST1)
/USB Hub + Ports/HUB_TEST2: R1716.2, U1700.64 (TEST2)
/USB Hub + Ports/HUB_TEST3: R1717.2, U1700.65 (TEST3)
/USB Hub + Ports/HUB_UP_TX_RAW_N: C1729.1, U1700.92 (USB3UP_TXDM)
/USB Hub + Ports/HUB_UP_TX_RAW_P: C1728.1, U1700.91 (USB3UP_TXDP)
/USB Hub + Ports/HUB_VCORE: C1705.1, C1708.1, C1709.1, C1820.1, C1821.1, C1822.1, C1823.1, C1824.1, C1825.1, C1826.1, C1827.1, C1828.1, C1840.1, C1841.1, C1842.1, C1843.1, C1844.1, C1845.1, C1846.1, C1847.1, C1848.1, L1700.2, R1705.1, U1700.9 (VCORE), U1700.18 (VCORE), U1700.25 (VCORE), U1700.31 (VCORE), U1700.38 (VCORE), U1700.55 (VCORE), U1700.78 (VCORE), U1700.85 (VCORE), U1700.93 (VCORE)
/USB Hub + Ports/J22_5V_PRE: C1781.1, C1782.1, U1780.6 (OUT), U1781.2 (IN1), U1781.3 (IN1), U1781.4 (IN2)
/USB Hub + Ports/J22_CC1: J22.A5 (CC1), U1781.11 (CC1), U1785.4 (D2+)
/USB Hub + Ports/J22_CC2: J22.B5 (CC2), U1781.13 (CC2), U1785.5 (D2-)
/USB Hub + Ports/J22_ILIM: R1780.1, U1780.5 (ILIM)
/USB Hub + Ports/J22_POL_N: R1781.2, U1781.18 (~POL), U1782.9 (SEL)
/USB Hub + Ports/J22_REF: R1782.1, U1781.10 (REF)
/USB Hub + Ports/J22_REF_RTN: R1782.2, U1781.9 (REF_RTN)
/USB Hub + Ports/J22_RX1_N: D1805.1 (IO), J22.B10 (RX1-), U1782.22 (SSC1(n))
/USB Hub + Ports/J22_RX1_P: D1804.1 (IO), J22.B11 (RX1+), U1782.23 (SSC1(p))
/USB Hub + Ports/J22_RX2_N: D1807.1 (IO), J22.A10 (RX2-), U1782.26 (SSB1(n))
/USB Hub + Ports/J22_RX2_P: D1806.1 (IO), J22.A11 (RX2+), U1782.27 (SSB1(p))
/USB Hub + Ports/J22_TX1_N: D1801.1 (IO), J22.A3 (TX1-), U1782.24 (SSC0(n))
/USB Hub + Ports/J22_TX1_P: D1800.1 (IO), J22.A2 (TX1+), U1782.25 (SSC0(p))
/USB Hub + Ports/J22_TX2_N: D1803.1 (IO), J22.B3 (TX2-), U1782.28 (SSB0(n))
/USB Hub + Ports/J22_TX2_P: D1802.1 (IO), J22.B2 (TX2+), U1782.29 (SSB0(p))
/USB Hub + Ports/J22_VBUS: C1790.1, J22.A4 (VBUS), J22.A9 (VBUS), J22.B4 (VBUS), J22.B9 (VBUS), U1783.B3 (VBUS_CON), U1783.C2 (VBUS_CON), U1783.C3 (VBUS_CON)
/USB Hub + Ports/J22_VBUS_POWER: C1791.1, U1783.B1 (VBUS_POWER)
/USB Hub + Ports/J22_VBUS_SYS: C1783.1, R1790.1, U1781.14 (OUT), U1781.15 (OUT), U1783.A2 (VBUS_SYS), U1783.A3 (VBUS_SYS), U1783.B2 (VBUS_SYS)
/USB Hub + Ports/J23_5V_PRE: C1741.1, C1742.1, U1740.6 (OUT), U1741.2 (IN1), U1741.3 (IN1), U1741.4 (IN2)
/USB Hub + Ports/J23_CC1: J23.A5 (CC1), U1741.11 (CC1), U1745.4 (D2+)
/USB Hub + Ports/J23_CC2: J23.B5 (CC2), U1741.13 (CC2), U1745.5 (D2-)
/USB Hub + Ports/J23_ILIM: R1740.1, U1740.5 (ILIM)
/USB Hub + Ports/J23_POL_N: R1741.2, U1741.18 (~POL), U1742.9 (SEL)
/USB Hub + Ports/J23_REF: R1742.1, U1741.10 (REF)
/USB Hub + Ports/J23_REF_RTN: R1742.2, U1741.9 (REF_RTN)
/USB Hub + Ports/J23_RX1_N: D1813.1 (IO), J23.B10 (RX1-), U1742.22 (SSC1(n))
/USB Hub + Ports/J23_RX1_P: D1812.1 (IO), J23.B11 (RX1+), U1742.23 (SSC1(p))
/USB Hub + Ports/J23_RX2_N: D1815.1 (IO), J23.A10 (RX2-), U1742.26 (SSB1(n))
/USB Hub + Ports/J23_RX2_P: D1814.1 (IO), J23.A11 (RX2+), U1742.27 (SSB1(p))
/USB Hub + Ports/J23_TX1_N: D1809.1 (IO), J23.A3 (TX1-), U1742.24 (SSC0(n))
/USB Hub + Ports/J23_TX1_P: D1808.1 (IO), J23.A2 (TX1+), U1742.25 (SSC0(p))
/USB Hub + Ports/J23_TX2_N: D1811.1 (IO), J23.B3 (TX2-), U1742.28 (SSB0(n))
/USB Hub + Ports/J23_TX2_P: D1810.1 (IO), J23.B2 (TX2+), U1742.29 (SSB0(p))
/USB Hub + Ports/J23_VBUS: C1750.1, J23.A4 (VBUS), J23.A9 (VBUS), J23.B4 (VBUS), J23.B9 (VBUS), U1743.B3 (VBUS_CON), U1743.C2 (VBUS_CON), U1743.C3 (VBUS_CON)
/USB Hub + Ports/J23_VBUS_POWER: C1751.1, U1743.B1 (VBUS_POWER)
/USB Hub + Ports/J23_VBUS_SYS: C1743.1, R1750.1, U1741.14 (OUT), U1741.15 (OUT), U1743.A2 (VBUS_SYS), U1743.A3 (VBUS_SYS), U1743.B2 (VBUS_SYS)
/USB Hub + Ports/J24_5V_PRE: C1850.1, C1851.1, J24.1 (VBUS), U1800.6 (OUT), U1801.5 (VBUS)
/USB Hub + Ports/J24_ILIM: R1850.1, U1800.5 (ILIM)
/USB Hub + Ports/J24_SSTX_N: C1853.2, J24.8 (StdA_SSTX-)
/USB Hub + Ports/J24_SSTX_P: C1852.2, J24.9 (StdA_SSTX+)
/USB Hub + Ports/J25_5V_PRE: C1854.1, C1855.1, J25.1 (VBUS), U1803.6 (OUT), U1804.5 (VBUS)
/USB Hub + Ports/J25_ILIM: R1851.1, U1803.5 (ILIM)
/USB Hub + Ports/USB5_BOOT: R1863.1, U1703.4 (CBOOT)
/USB Hub + Ports/USB5_BOOT_C: C1710.1, R1863.2
/USB Hub + Ports/USB5_COMBINED_OK: R2429.1, U2402.7 (~PRE), U2411.2, U2413.4
/USB Hub + Ports/USB5_COMP: C1863.1, R1862.1, U1703.15 (EXTCOMP)
/USB Hub + Ports/USB5_COMP_RC: C1862.1, R1862.2
/USB Hub + Ports/USB5_CONFIG: R1861.1, U1703.13 (CONFIG)
/USB Hub + Ports/USB5_EN: R1710.2, R1711.1, U1703.9 (EN/UVLO)
/USB Hub + Ports/USB5_FAULT_CLEAR_N: R2402.2, U2400.13 (IO1_0), U2402.6 (~CLR)
/USB Hub + Ports/USB5_FAULT_N: R2421.1, U2400.14 (IO1_1), U2402.3 (~Q), U2410.3
/USB Hub + Ports/USB5_FB: R1712.2, R1713.1, U1703.16 (FB)
/USB Hub + Ports/USB5_HW_ENABLE: R1710.1, R2400.1, U2411.4
/USB Hub + Ports/USB5_LATCH_ENABLE: U2410.4, U2411.1
/USB Hub + Ports/USB5_OC_N: R2401.2, R2422.1, U2400.15 (IO1_2), U2401.3 (~Alert), U2413.1
/USB Hub + Ports/USB5_PERMIT: R2410.1, U2400.4 (IO0_0), U2410.1
/USB Hub + Ports/USB5_PG: R1714.2, R2412.2, R2423.1, U1703.7 (PG/SYNCOUT), U2400.16 (IO1_3)
/USB Hub + Ports/USB5_PRE_SENSE: L1701.2, RS1860.1, RS1861.1, U1703.11 (ISNS+), U2401.10 (Vin+)
/USB Hub + Ports/USB5_RT: R1860.1, U1703.14 (RT)
/USB Hub + Ports/USB5_SW: L1701.1, U1703.20 (SW1), U1703.21 (SW2), U1703.22 (SW3)
/USB Hub + Ports/USB5_SW_BOOT: C1710.2, U1703.5 (SW4)
/USB Hub + Ports/USB5_VCC: C1860.1, U1703.19 (VCC)
/USB Hub + Ports/USB5_VDDA: C1861.1, U1703.18 (VDDA)
/USB Hub + Ports/USB_IO_UNUSED7: R2427.1, U2400.20 (IO1_7)
/USB Hub + Ports/USB_J22_PERMIT: R2405.1, U2400.7 (IO0_3), U2405.1
/USB Hub + Ports/USB_J22_SWITCH_EN: U1780.3 (EN), U1781.6 (EN), U2405.4
/USB Hub + Ports/USB_J23_PERMIT: R2406.1, U2400.8 (IO0_4), U2406.1
/USB Hub + Ports/USB_J23_SWITCH_EN: U1740.3 (EN), U1741.6 (EN), U2406.4
/USB Hub + Ports/USB_J24_PERMIT: R2407.1, U2400.10 (IO0_6), U2407.1
/USB Hub + Ports/USB_J24_SWITCH_EN: U1800.3 (EN), U2407.4
/USB Hub + Ports/USB_J25_PERMIT: R2408.1, U2400.11 (IO0_7), U2408.1
/USB Hub + Ports/USB_J25_SWITCH_EN: U1803.3 (EN), U2408.4
/USBC2_DN: U1700.90 (USB2UP_DM); also elsewhere on the board
/USBC2_DP: U1700.89 (USB2UP_DP); also elsewhere on the board
/USBC2_SSRX_N: C1729.2; also elsewhere on the board
/USBC2_SSRX_P: C1728.2; also elsewhere on the board
/USBC2_SSTX_N: U1700.95 (USB3UP_RXDM); also elsewhere on the board
/USBC2_SSTX_P: U1700.94 (USB3UP_RXDP); also elsewhere on the board
/USB_J11_PERMIT: U2400.6 (IO0_2); also elsewhere on the board
/USB_J12_PERMIT: U2400.9 (IO0_5); also elsewhere on the board
/USB_J21_PERMIT: U2400.5 (IO0_1); also elsewhere on the board
/USB_PORT_5V: C1714.1, C1715.1, C1740.1, C1780.1, C1864.1, C1865.1, C1868.1, C1869.1, C2683.1, C2684.1, R1712.1, RS1860.2, RS1861.2, U1703.12 (VOUT), U1740.1 (IN), U1780.1 (IN), U1800.1 (IN), U1803.1 (IN), U2401.8 (Vbus), U2401.9 (Vin-); also elsewhere on the board
/VSYS: C1711.1, C1712.1, C1713.1, C1866.1, C1867.1, U1703.1 (VIN4), U1703.2 (VIN5), U1703.3 (VIN6), U1703.27 (VIN1), U1703.28 (VIN2), U1703.29 (VIN3); also elsewhere on the board
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

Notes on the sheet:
== Left I/O: USB7206C hub, source ports, USB-A spare ports ==
Board split Phase 2.1: hub + PD1 moved left; FPC-1 crosses to center.
== 6.5A USB5 converter envelope and 1.15V hub-core rail ==
USB5: external COMP 2.49k / 220n / 2.2n; include each PP5V reservoir gate state and remote cable R/L in the loop model.
6.5A includes VBUS and VCONN. Source admission, harness loss, capacitor corners, startup and thermal behavior require qualification.
== Internal USB-A spare ports: hub DIS5 (USB3) + DIS6 (USB2) ==
== J22: source-only USB-C data port, USB7206C downstream 2, USB3 ==
== J23: source-only USB-C data port, USB7206C downstream 3, USB3 ==
Raw OC and SYS5 veto remain active during clear; any SYS5 loss latches USB off until explicit clear.
USB permissions reset off; fault clear is active-low and defaults high.

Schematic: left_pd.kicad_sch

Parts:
C2000: 100n 100V TPD4S201 VBIAS; C_0805_2012Metric; MPN GRM21BR72A104KA01L
C2001: 820n 10V TPD4S201 VPWR; C_0805_2012Metric; MPN GRM21BR71A824KA01L
C2002: 100n EEPROM local; C_0603_1608Metric; MPN GRM188R71H104KA93D
C2003: 100n mux-control buffer local; C_0603_1608Metric; MPN GRM188R71H104KA93D
C2004: 10u TUSB1142 local; C_1206_3216Metric; MPN GRM31CR71A106KA01L
C2005, C2006, C2007, C2008: 100n TUSB1142 VCC local; C_0603_1608Metric; MPN GRM188R71H104KA93D
C2009, C2010, C2011, C2012, C2013, C2014: 220n USB3 TX AC coupling; C_0402_1005Metric; MPN GRM155R71C224KA12D
C2015: 4.7u 25V raw VBUS; pre-attach total below 10uF; C_1206_3216Metric; MPN GRM31CR71E475KA88L
C2016, C2017, C2018, C2019: 10n 50V connector VBUS HF; C_0402_1005Metric; MPN GRM155R71H103KA88D
C2020: 6.8u 25V X7R TPS25751A LDO3V3; verify >=5u effect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; C_1206_3216Metric; MPN GRM31CR71E685KA88L
C2021: 10u 16V X7R TPS25751A LDO1V5; verify 4.5-12u effe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; C_1206_3216Metric; MPN GRM31CR71C106KA01L
C2022: 10u TPS25751A VIN3V3; C_1206_3216Metric; MPN GRM31CR71A106KA01L
C2023: 270p C0G CC1 total-capacitance component; C_0402_1005Metric; MPN GRM1555C1H271JA01D
C2024: 270p C0G CC2 total-capacitance component; C_0402_1005Metric; MPN GRM1555C1H271JA01D
C2025, C2026: 100u 10V PP5V source bulk; CP_EIA-7343-31_Kemet-D; MPN T520D107M010ATE070
C2027: 10u PP5V local ceramic; C_1206_3216Metric; MPN GRM31CR71A106KA01L
C2028: 68u 25V PPHV sink bulk; CP_EIA-7343-31_Kemet-D; MPN T521V686M025ATE050
C2029: 100n 50V PPHV local; C_0603_1608Metric; MPN GRM188R71H104KA93D
C2030: 100n USB2 switch local; C_0603_1608Metric; MPN GRM188R71H104KA93D
C2080: 100n 50V input local; C_0603_1608Metric; MPN GRM188R71H104KA93D
C2081: 10u 25V output; C_1206_3216Metric; MPN GRM31CR71E106KA12L
C2082: 10n 50V C0G slew control; C_0603_1608Metric; MPN GRM1885C1H103JA01D
C2140: 100n selector INTVCC; C_0603_1608Metric; MPN GRM188R71H104KA93D
C2141: 1n 50V C0G selector validation; C_0402_1005Metric; MPN GRM1555C1H102JA01D
C2142, C2143: 100n 50V selector local; C_0603_1608Metric; MPN GRM188R71H104KA93D
C2146: 100u 35V selected-PD hold-up; CP_Elec_6.3x7.7; MPN EEHZK1V101XP
C2403: 1u; C_0805_2012Metric; MPN GRM21BR71H105KA12L
C2413: 4.7n C0G PP5V slew; C_0603_1608Metric; MPN GRM1885C1H472JA01D
C2630: 100n 50V inverter bypass; C_0603_1608Metric; MPN GRM188R71H104KA93D
C2682: 100n 50V qualifier bypass; C_0603_1608Metric; MPN GRM188R71H104KA93D
D2080: B340A eFuse output negative-transient clamp; D_SMA; MPN B340A-13-F
D2100, D2101, D2102, D2103, D2104, D2105, D2106, D2107: TPD1E0B04DPLR 0.13pF USB3 ESD; D_0201_0603Metric; MPN TPD1E0B04DPLR
F195: 3A MINI AUX source fuse: Littelfuse 0297003.WXNV; Fuseholder_Blade_Mini_Keystone_3568; MPN 0297003.WXNV + 3568
H10, H11, H12, H16: M2.5 isolated mainboard mounting hole; MountingHole_2.7mm_M2.5
J21: USB-C dual-role data/PD port J21; USB_C_Receptacle_Molex_105450-0101; MPN 105450-0101
J190: AUX/SOLAR protected screw terminal 6-22V nominal; TerminalBlock_Phoenix_MKDS-1,5-2-5.08_1x02_P5.08mm_Horizont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; MPN 1715022
Q15, Q16: SiSS4409DN 40V reverse-blocking PMOS; Vishay_PowerPAK_1212-8_Single; MPN SiSS4409DN-T1-GE3
Q2001: 2N7002K DFP USB2 enable inverter; SOT-23; MPN 2N7002KT1G
Q2630: BSS138 switched discharge; SOT-23; MPN BSS138LT1G
R2000: 10k shared CC/USB2 protector FLT pull-up; R_0603_1608Metric; MPN RC0603FR-0710KL
R2001: 2.2k EEPROM SDA pull-up; R_0603_1608Metric; MPN RC0603FR-072K2L
R2002: 2.2k EEPROM SCL pull-up; R_0603_1608Metric; MPN RC0603FR-072K2L
R2003: 4.7k TCPC SDA pull-up; R_0603_1608Metric; MPN RC0603FR-074K7L
R2004: 4.7k TCPC SCL pull-up; R_0603_1608Metric; MPN RC0603FR-074K7L
R2005: 10k TCPC IRQ pull-up; R_0603_1608Metric; MPN RC0603FR-0710KL
R2006: 10k mux FLIP pull-up; R_0603_1608Metric; MPN RC0603FR-0710KL
R2007: 10k mux EN pull-up; R_0603_1608Metric; MPN RC0603FR-0710KL
R2008: 1k TUSB1142 MODE=0 strap; R_0603_1608Metric; MPN RC0603FR-071KL
R2009: 1k TUSB1142 VIO=3V3 strap; R_0603_1608Metric; MPN RC0603FR-071KL
R2010: 1k TUSB1142 EQCFG=0 strap; R_0603_1608Metric; MPN RC0603FR-071KL
R2011: 1k TUSB1142 SSEQ1=0 strap; R_0603_1608Metric; MPN RC0603FR-071KL
R2012: 10k TUSB1142 SLP_S0# pull-up; R_0603_1608Metric; MPN RC0603FR-0710KL
R2013: 100k mux FLIP input default-low; R_0603_1608Metric; MPN RC0603FR-07100KL
R2014: 100k data-attach input default-low; R_0603_1608Metric; MPN RC0603FR-07100KL
R2015: 10k I2Cc IRQ inactive pull-up; R_0603_1608Metric; MPN RC0603FR-0710KL
R2016: 100k USB2 switch default-disable pull-up; R_0603_1608Metric; MPN RC0603FR-07100KL
R2017: 0R protector FLT wired-OR link; R_0603_1608Metric; MPN RC0603FR-070RL
R2018: 100k DFP-role input default-low; R_0603_1608Metric; MPN RC0603FR-07100KL
R2080: 1k 1W switched input discharge; R_2512_6332Metric; MPN RC2512FR-071KL
R2081: 100k discharge gate default-low; R_0603_1608Metric; MPN RC0603FR-07100KL
R2082: 1k IMON load; R_0603_1608Metric; MPN RC0603FR-071KL
R2083: 267R 0.1% sink breaker; 5.58A nominal; R_0603_1608Metric; MPN RT0603BRD07267RL
R2084: 47k sink enable default-off; R_0603_1608Metric; MPN RC0603FR-0747KL
R2085: 10k sink enable series; R_0603_1608Metric; MPN RC0603FR-0710KL
R2086: 150k sink PG pull-up; valid with input off; R_0603_1608Metric; MPN RC0603FR-07150KL
R2140: 76.8k 0.02% 5ppm 5..20V UV top; R_0603_1608Metric; MPN TNPU060376K8HZEN00
R2141: 21.5k 0.02% 5ppm 5..20V window middle; R_0603_1608Metric; MPN TNPU060321K5HZEN00
R2142: 4.53k 0.02% 5ppm 5..20V OV bottom; R_0603_1608Metric; MPN TNPU06034K53HZEN00
R2146: 10k PD1 VALID pull-up; R_0603_1608Metric; MPN RC0603FR-0710KL
R2403: 100k; R_0603_1608Metric; MPN RC0603FR-07100KL
R2413: 10k; R_0603_1608Metric; MPN RC0603FR-0710KL
U14: LTC4418IUF#PBF dual-input PD selector (V1 = J21); ADI_UF20_QFN20_4x4_P0.5_EP2.45; MPN LTC4418IUF#PBF
U41: TPS25751AD USB-PD DRP controller; Texas_REF0038A_WQFN-38-2EP_6x4mm_P0.4; MPN TPS25751ADREFR
U720: TPS259827ONRGER PD1 sink breaker; Texas_RGE0024M_QFN24_4x4_2EP; MPN TPS259827ONRGER
U2000: TUSB1142 USB 3.2 Gen 2 orientation redriver; Texas_RNQ0040A_WQFN-40-1EP_6x4mm_P0.4mm_EP4.7x2.7mm_Thermal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; MPN TUSB1142IRNQR
U2001: TPD4S201 CC and USB2 short-to-VBUS protector; Texas_RUK0020B_WQFN-20-1EP_3x3mm_P0.4mm_EP1.7x1.7mm_Thermal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; MPN TPD4S201RUKR
U2002: CAT24C256 32KB private TPS25751A EEPROM; SOIC-8_3.9x4.9mm_P1.27mm; MPN CAT24C256WI-GT3
U2003: TS3USB30E DFP-qualified USB2 disconnect; TSSOP-10_3x3mm_P0.5mm; MPN TS3USB30EDGSR
U2004: SN74LVC2G07 partial-power-down mux controls; SOT-363_SC-70-6; MPN SN74LVC2G07DCKR
U2005: TVS2200 22V USB VBUS surge clamp; WSON-6-1EP_2x2mm_P0.65mm_EP1x1.6mm; MPN TVS2200DRVR
U2006: SN74LVC1G08 DFP and attached qualifier; SOT-23-5; MPN SN74LVC1G08DBVR
U2403: TPS22992SRXNR J21 PP5V gate; Texas_RXN0008A_WQFN-HR-8_1.25x1.25mm; MPN TPS22992SRXNR
U2630: SN74LVC1G04DBVR discharge control; SOT-23-5; MPN SN74LVC1G04DBVR
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

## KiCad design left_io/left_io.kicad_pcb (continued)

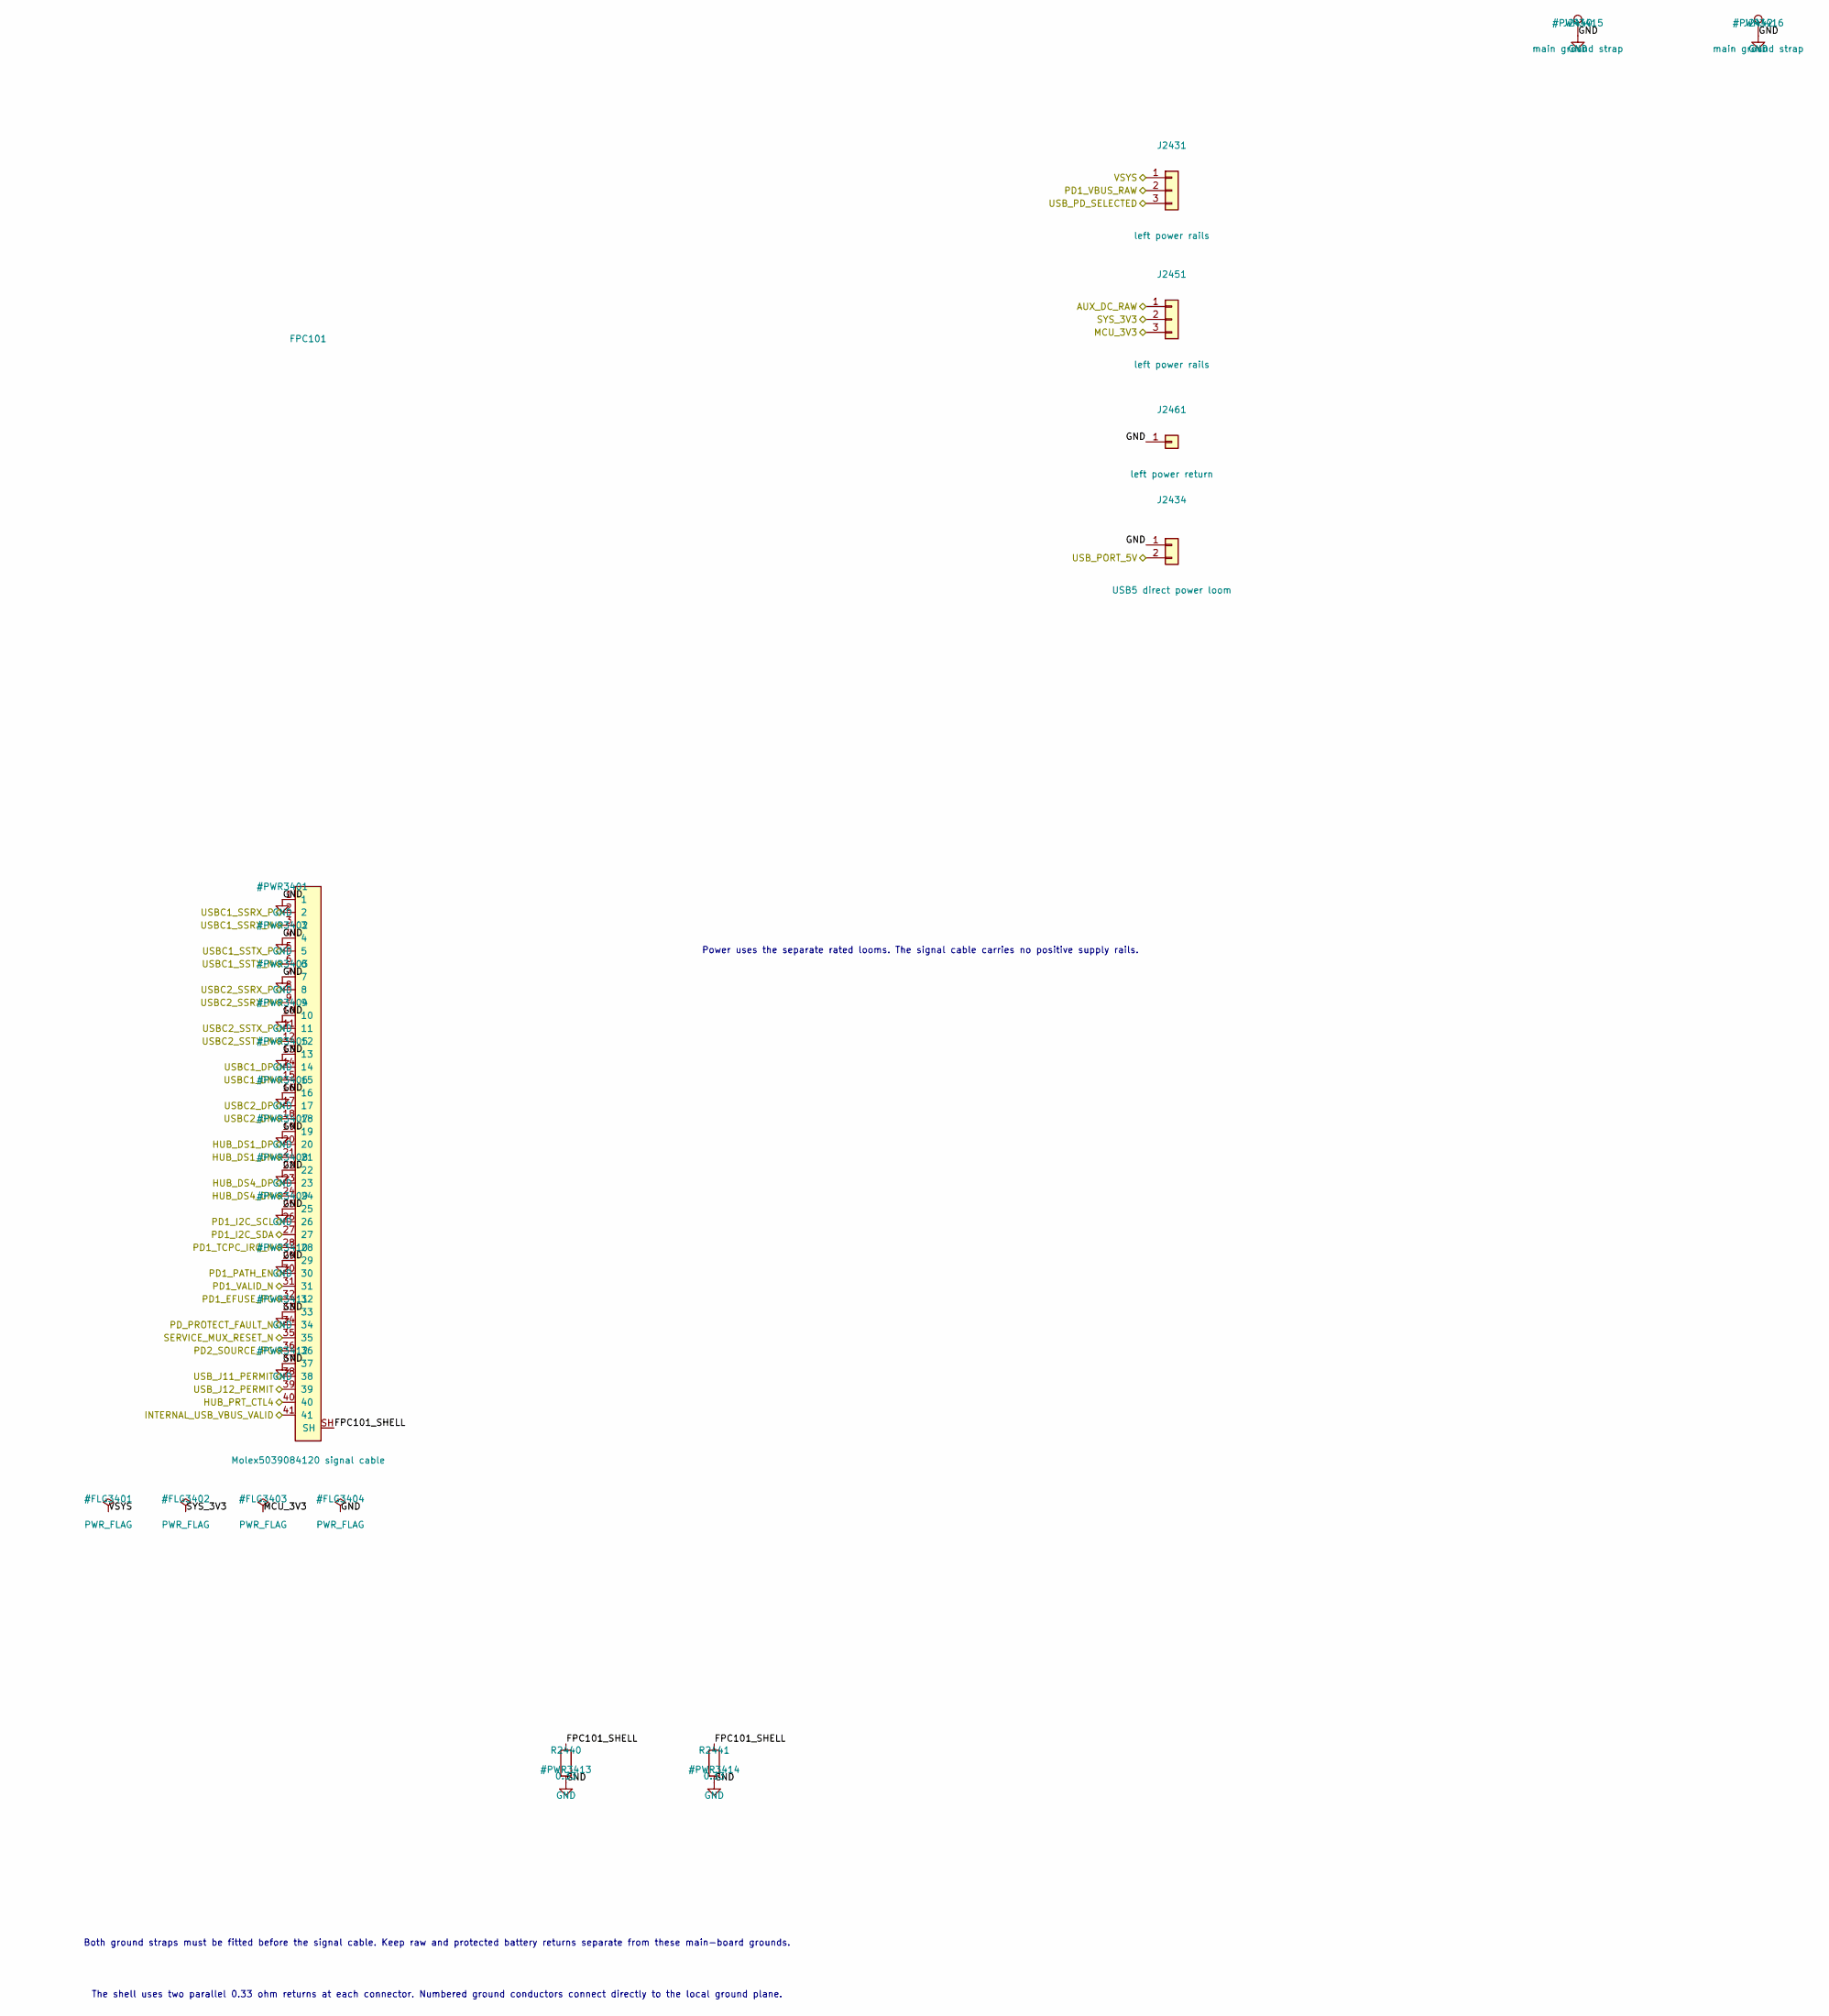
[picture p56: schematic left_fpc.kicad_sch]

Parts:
FPC101: Molex5039084120 signal cable; Molex_5039084120_1x41_P0.50mm_Horizontal; MPN 5039084120
J2431, J2451: left power rails; WAGO_2060_453_SMD; MPN 2060-453/998-404
J2434: USB5 direct power loom; AMASS_XT30PW-F30_G_Y; MPN XT30PW-F30.G.Y
J2440, J2442: main ground strap; SolderWirePad_1x01_SMD_5x10mm
J2461: left power return; WAGO_2060_451_SMD; MPN 2060-451/998-404
R2440, R2441: 0.33; R_0603_1608Metric; MPN ERJ3RQFR33V

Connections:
/AUX_DC_RAW: J2451.1; also elsewhere on the board
/FPC-1 (to Center)/FPC101_SHELL: FPC101.SH, R2440.1, R2441.1
/HUB_DS1_DN: FPC101.21; also elsewhere on the board
/HUB_DS1_DP: FPC101.20; also elsewhere on the board
/HUB_DS4_DN: FPC101.24; also elsewhere on the board
/HUB_DS4_DP: FPC101.23; also elsewhere on the board
/HUB_PRT_CTL4: FPC101.40; also elsewhere on the board
/INTERNAL_USB_VBUS_VALID: FPC101.41; also elsewhere on the board
/MCU_3V3: J2451.3; also elsewhere on the board
/PD1_EFUSE_PG: FPC101.32; also elsewhere on the board
/PD1_I2C_SCL: FPC101.26; also elsewhere on the board
/PD1_I2C_SDA: FPC101.27; also elsewhere on the board
/PD1_PATH_EN: FPC101.30; also elsewhere on the board
/PD1_TCPC_IRQ_N: FPC101.28; also elsewhere on the board
/PD1_VALID_N: FPC101.31; also elsewhere on the board
/PD1_VBUS_RAW: J2431.2; also elsewhere on the board
/PD2_SOURCE_PG: FPC101.36; also elsewhere on the board
/PD_PROTECT_FAULT_N: FPC101.34; also elsewhere on the board
/SERVICE_MUX_RESET_N: FPC101.35; also elsewhere on the board
/SYS_3V3: J2451.2; also elsewhere on the board
/USBC1_DN: FPC101.15; also elsewhere on the board
/USBC1_DP: FPC101.14; also elsewhere on the board
/USBC1_SSRX_N: FPC101.3; also elsewhere on the board
/USBC1_SSRX_P: FPC101.2; also elsewhere on the board
/USBC1_SSTX_N: FPC101.6; also elsewhere on the board
/USBC1_SSTX_P: FPC101.5; also elsewhere on the board
/USBC2_DN: FPC101.18; also elsewhere on the board
/USBC2_DP: FPC101.17; also elsewhere on the board
/USBC2_SSRX_N: FPC101.9; also elsewhere on the board
/USBC2_SSRX_P: FPC101.8; also elsewhere on the board
/USBC2_SSTX_N: FPC101.12; also elsewhere on the board
/USBC2_SSTX_P: FPC101.11; also elsewhere on the board
/USB_J11_PERMIT: FPC101.38; also elsewhere on the board
/USB_J12_PERMIT: FPC101.39; also elsewhere on the board
/USB_PD_SELECTED: J2431.3; also elsewhere on the board
/USB_PORT_5V: J2434.2; also elsewhere on the board
/VSYS: J2431.1; also elsewhere on the board
GND: FPC101.1, FPC101.4, FPC101.7, FPC101.10, FPC101.13, FPC101.16, FPC101.19, FPC101.22, FPC101.25, FPC101.29, FPC101.33, FPC101.37, J2434.1, J2440.1, J2442.1, J2461.1, R2440.2, R2441.2; also elsewhere on the board

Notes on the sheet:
Power uses the separate rated looms. The signal cable carries no positive supply rails.
Both ground straps must be fitted before the signal cable. Keep raw and protected battery returns separate from these main-board grounds.
The shell uses two parallel 0.33 ohm returns at each connector. Numbered ground conductors connect directly to the local ground plane.

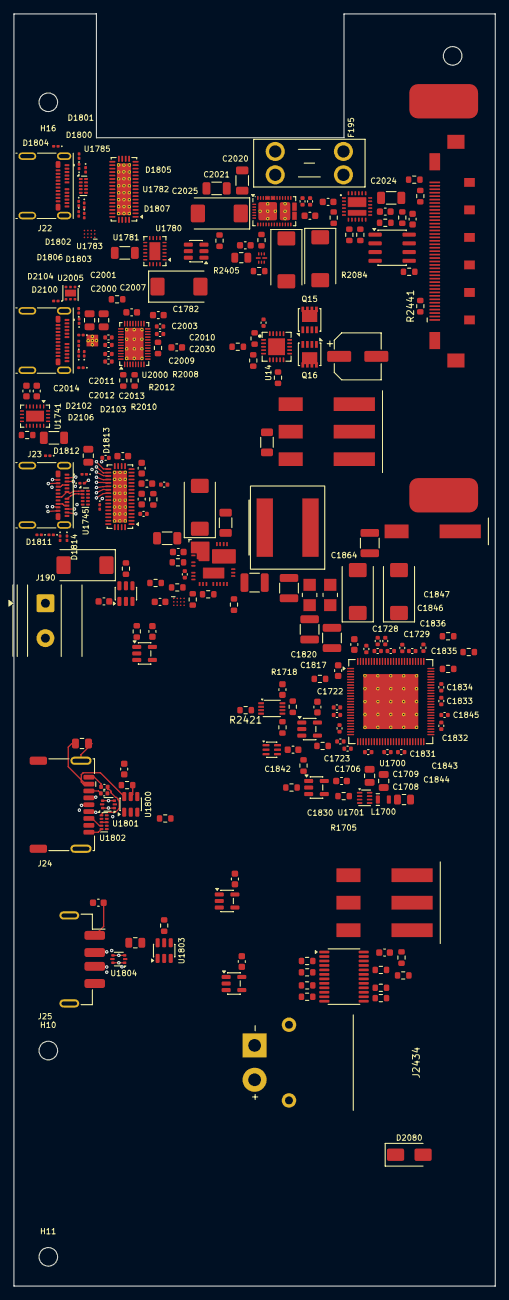
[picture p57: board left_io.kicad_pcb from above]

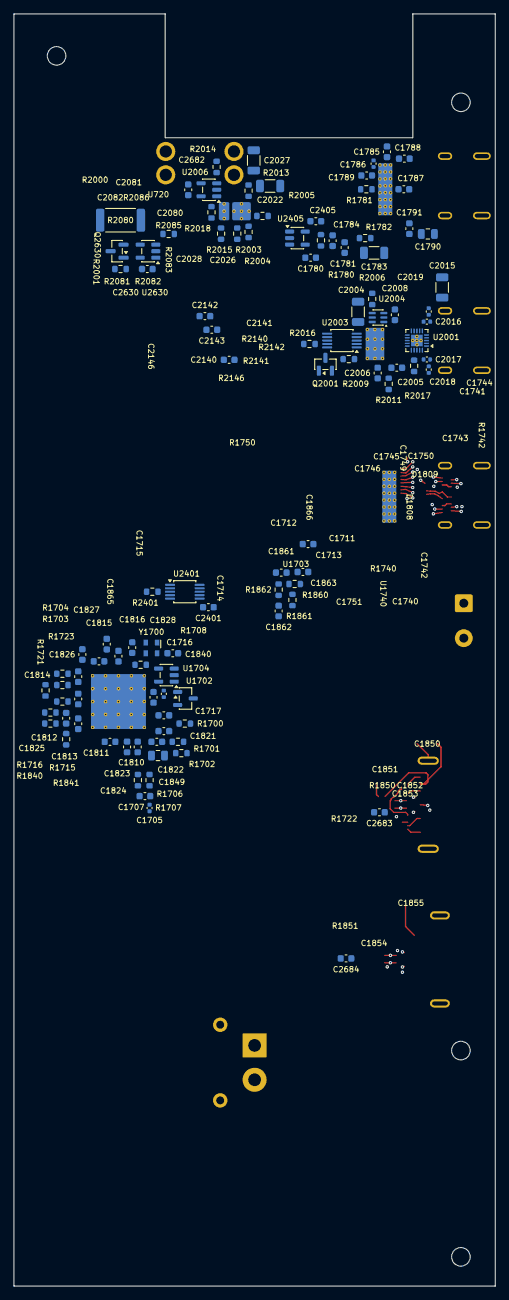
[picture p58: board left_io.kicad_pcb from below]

Board: 8 copper layers, 70.0 x 185.0 mm, 333 parts (103 on the bottom side), 220 nets.

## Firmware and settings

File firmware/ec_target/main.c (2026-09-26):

#include "ducktop2/ec/ec_policy.h"
#include "ducktop2/ec/ec_commit.h"
#include "ducktop2/ec/ec_telemetry.h"
#include "ducktop2/ec/ec_keymap.h"
#include "ec_app.h"
#include "gpio.h"
#include "i2c.h"
#include "matrix_scan.h"
#include "keyboard_rgb.h"
#include "stm32f4xx.h"
#include "usb_hid.h"
#include "watchdog.h"
#include "board_profile.h"
#include "power_profile.h"
#include "source_paths.h"
#include "tca9537.h"
#include "tps25751.h"
#include "host_link.h"
#include "usb_power.h"
#include "audio.h"
#include "ssd1306.h"
#include "ducktop2/ec/ec_fan_monitor.h"
#include "ducktop2/ec/ec_lid.h"

static volatile uint32_t g_tick_ms = 0;

void SysTick_Handler(void)
{
    g_tick_ms++;
    matrix_scan_tick(g_tick_ms);
}

static inline uint32_t read_primask(void)
{
    uint32_t result;
    __asm volatile("MRS %0, PRIMASK" : "=r" (result));
    return result;
}

static inline void disable_irq(void)
{
    __asm volatile("CPSID I");
}

static inline void enable_irq(void)
{
    __asm volatile("CPSIE I");
}

uint32_t GetTick(void)
{
    uint32_t tick;
    uint32_t primask = read_primask();
    disable_irq();
    tick = g_tick_ms;
    if (!primask) enable_irq();
    return tick;
}

void DelayMs(uint32_t ms)
{
    uint32_t start = GetTick();
    while ((GetTick() - start) < ms) {
        usb_hid_poll();
        __WFI();
    }
}

/* U44 wiring is defined in sheet 02. A failed read invalidates every input. */
#define U44_PACK_OK (1u << 6)
#define U44_AUX_OK (1u << 7)
#define U44_AON_OK (1u << 4)
static bool want_power = true;
static bool headphone_present;
static bool fan_healthy = true;
static usb_power_state_t usb_power;
static uint32_t other_auxiliary_mw;
static uint16_t source_voltage_mv[EC_SOURCE_COUNT];

static bool commit_write(void *context, ec_commit_command_t command, uint32_t value)
{
    (void)context;
    switch (command) {
    case EC_COMMIT_PD1_PATH_ENABLE:
        return source_paths_set(EC_SOURCE_PD1,value!=0,source_voltage_mv[EC_SOURCE_PD1],GetTick());
    case EC_COMMIT_PD2_PATH_ENABLE:
        return source_paths_set(EC_SOURCE_PD2,value!=0,source_voltage_mv[EC_SOURCE_PD2],GetTick());
    case EC_COMMIT_AUX_PATH_ENABLE:
        return source_paths_set(EC_SOURCE_AUX,value!=0,source_voltage_mv[EC_SOURCE_AUX],GetTick());
    case EC_COMMIT_CHARGER_IINDPM_MA: return ec_app_apply_charger_iindpm_ma((uint16_t)value);
    case EC_COMMIT_CHARGE_BUDGET_MW: return ec_app_apply_charge_budget_mw(value);
    case EC_COMMIT_MU_EDP_BUDGET_MW: return ec_host_request_budget(value);
    case EC_COMMIT_CHARGER_ENABLE: return ec_app_set_charging(value != 0);
    case EC_COMMIT_MU_12V_ENABLE: gpio_set_mu_12v_enable(value != 0); return true;
    case EC_COMMIT_KEYBOARD_RGB_ENABLE: return keyboard_rgb_request(value != 0,GetTick());
    case EC_COMMIT_RADIO_DB_ENABLE: gpio_set_radio_db_power_enable(value != 0); return true;
    case EC_COMMIT_AUDIO_AMP_ENABLE: gpio_set_audio_amp_enable(value != 0); return true;
    case EC_COMMIT_AUDIO_MIC_ENABLE: gpio_set_audio_mic_enable(value != 0); return true;
    default: return false;
    }
}

static void read_inputs(ec_inputs_t *in, ec_telemetry_inputs_t *telemetry, uint32_t now)
{
    ec_inputs_init(in);
    ec_telemetry_inputs_init(telemetry);
    source_paths_state_t paths;
    bool expander=source_paths_read(&paths,now);
    uint8_t p0=paths.port0,p1=paths.port1;
    for(unsigned i=0;i<EC_SOURCE_COUNT;i++) source_voltage_mv[i]=0;
    in->source_manager_reset_released = expander;
    in->service_mux_reset_released = true;
    in->service_bus_healthy = expander && i2c1_probe(I2C_TCA9548A_ADDR);
    in->all_source_paths_off=paths.all_off;
    in->radio_db_present_n = !expander || (p1 & (1u<<7)) != 0;
    in->radio_db_fault_n = expander && (p1 & (1u<<6)) != 0;
    in->radio_db_power_good = expander && (p1 & (1u<<5)) != 0;
    headphone_present = expander && (p0 & (1u<<2)) != 0;
    ec_app_read_power_inputs(in, telemetry, now);
    in->thermal_ok = in->thermal_ok && fan_healthy;
    in->mu_12v_pg = gpio_get_mu_12v_pg();
    if (in->service_bus_healthy) {
        for (uint8_t port=0; port<2; ++port) {
            tps25751_contract_t contract;
            bool valid=tca9548a_select_channel((uint8_t)(port+2)) &&
                       tps25751_read_contract((uint8_t)(0x20+port), &contract);
            if (!tca9548a_deselect_all()) {
                in->service_bus_healthy=false;
                break;
            }
            if (!valid) continue;
            ec_source_observation_t *obs=&in->source[EC_SOURCE_PD1+port];
            obs->present=contract.connected;
            obs->fault_n=gpio_get_pd_protect_fault_n() && (p1 & U44_AON_OK);
            obs->path_good=paths.pd_good[port];
            obs->negotiated_voltage_mv=contract.voltage_mv;
            if(contract.valid) source_voltage_mv[EC_SOURCE_PD1+port]=contract.voltage_mv;
            obs->qualified_input_current_valid=contract.valid;
            obs->qualified_input_current_ma=contract.current_ma;
        }
    }
    ec_source_observation_t *pack=&in->source[EC_SOURCE_PACK];
    pack->present=DUCKTOP2_PACK_QUALIFIED && ec_app_battery_present() &&
                  (telemetry->valid_flags & EC_TELEMETRY_VALID_PACK_VOLTAGE);
    pack->fault_n=expander && (p0 & U44_PACK_OK);
    pack->path_good=pack->present && pack->fault_n;
    pack->negotiated_voltage_mv=in->pack_voltage_mv;
    uint32_t pack_ma=DUCKTOP2_PACK_USABLE_CURRENT_MA;
    pack_ma=pack_ma>DUCKTOP2_PACK_AON_RESERVE_MA ? pack_ma-DUCKTOP2_PACK_AON_RESERVE_MA : 0u;
    pack->available_power_mw=(uint32_t)in->pack_voltage_mv*pack_ma/1000u;
    pack->available_power_valid=pack->path_good && in->pack_telemetry_valid && pack->available_power_mw>0;
    in->pack_bridge_qualified=DUCKTOP2_PACK_BRIDGE_QUALIFIED && DUCKTOP2_PACK_QUALIFIED;
    in->pack_discharge_limit_ma=DUCKTOP2_PACK_USABLE_CURRENT_MA;
    uint16_t aux_mv;
    ec_source_observation_t *aux=&in->source[EC_SOURCE_AUX];
    if (expander && ec_app_aux_counts_to_mv(gpio_read_adc_aux_dc(), &aux_mv)) {
        aux->present=aux_mv>=7000 && aux_mv<=22000;
        aux->path_good=paths.aux_good;
        /* PG is expected low while disabled or ramping. Once active,
         * its loss is independently caught by the policy. */
        aux->fault_n=(!paths.aux_good || (p0 & U44_AUX_OK)) && (p1 & U44_AON_OK);
        aux->negotiated_voltage_mv=aux_mv;
        aux->qualified_input_current_valid=aux->present && aux->fault_n;
        aux->qualified_input_current_ma=DUCKTOP2_AUX_QUALIFIED_CURRENT_MA;
        /* Use the same IINDPM margin as the command, not full source current. */
        ec_policy_config_t config=ec_target_power_config();
        aux->available_power_mw=ec_policy_external_input_power_mw(&config,EC_SOURCE_AUX,aux_mv,aux->qualified_input_current_ma);
        aux->available_power_valid=aux->qualified_input_current_valid && aux->available_power_mw>0u;
        if(aux->qualified_input_current_valid) source_voltage_mv[EC_SOURCE_AUX]=aux_mv;
    }
    ec_host_state_t host=ec_host_state(now);
    if (host.valid && (host.requests & EC_HOST_REQUEST_OFF)) want_power=false;
    if (gpio_get_power_button_pressed()) want_power=true;
    in->request_mu_12v=DUCKTOP2_MU_THROTTLE_QUALIFIED && want_power && (DUCKTOP2_EXTERNAL_BOOT_QUALIFIED ||
                      DUCKTOP2_PACK_BOOT_QUALIFIED || host.valid);
    in->external_boot_authorized=DUCKTOP2_EXTERNAL_BOOT_QUALIFIED && !host.valid;
    in->external_boot_budget_mw=DUCKTOP2_EXTERNAL_BOOT_BUDGET_MW;
    in->pack_boot_authorized=DUCKTOP2_PACK_BOOT_QUALIFIED && DUCKTOP2_PACK_QUALIFIED && !host.valid;
    in->pack_boot_budget_mw=DUCKTOP2_PACK_BOOT_BUDGET_MW;
    in->estimated_mu_edp_power_valid=host.valid;
    in->estimated_mu_edp_power_mw=host.estimated_mu_mw;
    in->estimated_aux_power_valid=DUCKTOP2_AUX_LOADS_QUALIFIED;
    in->estimated_aux_power_mw=DUCKTOP2_AUX_WORST_CASE_MW;
    if (host.valid && host.estimated_aux_mw>in->estimated_aux_power_mw)
        in->estimated_aux_power_mw=host.estimated_aux_mw;
    other_auxiliary_mw=in->estimated_aux_power_mw;
    in->estimated_aux_power_mw+=usb_power_reservation_mw(&usb_power);
    in->power_limits_applied=host.valid;
    in->applied_mu_edp_budget_mw=host.budget_mw;
    in->request_charger=DUCKTOP2_CHARGING_QUALIFIED && DUCKTOP2_PACK_QUALIFIED &&
                        pack->fault_n && in->pack_telemetry_valid && !ec_app_gauge_full() &&
                        expander && (paths.control & TCA9537_PACK_CHARGE_PERMIT) &&
                        ec_host_allows_charging(now);
    in->requested_charge_power_mw=in->request_charger ? 10000u : 0u;
    in->request_audio_amp=host.valid && (host.requests & EC_HOST_REQUEST_SPEAKER) && !headphone_present;
    in->request_audio_mic=host.valid && (host.requests & EC_HOST_REQUEST_MIC);
    in->request_keyboard_rgb=host.valid && (host.requests & EC_HOST_REQUEST_RGB);
    in->request_radio_db=host.valid && (host.requests & EC_HOST_REQUEST_RADIO);
}

static uint32_t age_forward(uint32_t age,uint32_t elapsed)
{
    return UINT32_MAX-age<elapsed ? UINT32_MAX : age+elapsed;
}

static void refresh_transfer_interlocks(ec_inputs_t *in,uint32_t sampled_at,uint32_t *now)
{
    source_paths_state_t paths;
    bool fresh=source_paths_read(&paths,GetTick());
    in->service_bus_healthy &= fresh;
    in->source_manager_reset_released &= fresh;
    if(fresh) {
        in->source[EC_SOURCE_PACK].fault_n=(paths.port0 & U44_PACK_OK)!=0;
        in->source[EC_SOURCE_PACK].path_good &= in->source[EC_SOURCE_PACK].fault_n;
        for(unsigned p=0;p<2;p++) {
            in->source[EC_SOURCE_PD1+p].fault_n=(paths.port1 & U44_AON_OK) && gpio_get_pd_protect_fault_n();
            in->source[EC_SOURCE_PD1+p].path_good=paths.pd_good[p];
        }
        in->source[EC_SOURCE_AUX].path_good=paths.aux_good;
        in->source[EC_SOURCE_AUX].fault_n=(paths.port1 & U44_AON_OK) &&
            (!paths.aux_good || (paths.port0 & U44_AUX_OK));
        in->request_charger &= (paths.control & TCA9537_PACK_CHARGE_PERMIT)!=0;
    }
    in->mu_12v_pg=gpio_get_mu_12v_pg();
    in->all_source_paths_off=fresh && paths.all_off;
    *now=GetTick();
    in->pack_sample_age_ms=age_forward(in->pack_sample_age_ms,*now-sampled_at);
    in->vsys_sample_age_ms=age_forward(in->vsys_sample_age_ms,*now-sampled_at);
    if(!ec_host_state(*now).valid) {
        in->power_limits_applied=false;
        in->estimated_mu_edp_power_valid=false;
        /* The missing host lease invalidates its load reading. The policy
         * can resume charging once the Mu rail is off, or reserve a separately
         * qualified boot budget. It must not treat an unknown live load as zero. */
    }
}

int main(void)
{
    gpio_init_all(); matrix_scan_init(); i2c1_init(); ec_app_init(); ec_host_init(); keyboard_rgb_init();
    usb_hid_init();
    if (!source_paths_init()) NVIC_SystemReset();
    ec_policy_config_t config=ec_target_power_config();
    uint32_t boot_budget=DUCKTOP2_EXTERNAL_BOOT_BUDGET_MW;
    uint32_t pack_boot_budget=DUCKTOP2_PACK_BOOT_BUDGET_MW;
    if (pack_boot_budget>boot_budget) boot_budget=pack_boot_budget;
    if (boot_budget>config.normal_mu_edp_budget_mw) config.normal_mu_edp_budget_mw=boot_budget;
    ec_controller_t controller; ec_controller_init(&controller,&config,GetTick());
    ec_commit_state_t commits; ec_commit_state_init(&commits);
    ec_commit_driver_t driver={.context=NULL,.write=commit_write};
    if (ec_commit_force_safe(&commits,&driver) != EC_COMMIT_OK) NVIC_SystemReset();
    gpio_set_service_mux_reset(true); DelayMs(2); tca9548a_deselect_all();
    usb_power_config_t uc={
        .budget={.qualified=DUCKTOP2_USB_POWER_QUALIFIED,
                 .admission_current_ma=DUCKTOP2_USB_ADMISSION_MA,
                 .right_harness_current_ma=DUCKTOP2_USB_RIGHT_HARNESS_MA,
                 .rail_max_mv=5239u,.minimum_efficiency_percent=DUCKTOP2_USB_EFFICIENCY_PERCENT},
        .startup_ceiling_ma=5600u,.pd_inrush_ma=DUCKTOP2_USB_PD_INRUSH_MA,
        .branch_inrush_ma=DUCKTOP2_USB_BRANCH_INRUSH_MA,
        .rail_min_mv=5000u,.rail_max_mv=5250u,
        .vsys_max_overestimate_mv=DUCKTOP2_VSYS_MAX_OVERESTIMATE_MV,
        .vsys_max_fall_mv=DUCKTOP2_VSYS_MAX_FALL_MV,
        .startup_timeout_ms=500u,.gate_timeout_ms=200u,.sample_max_age_ms=100u
    };
    if (!usb_power_init(&usb_power,&uc,GetTick())) NVIC_SystemReset();
    ec_fan_config_t fc=ec_fan_default_config(); ec_fan_state_t fs; ec_fan_state_init(&fs);
    ec_fan_monitor_t fan_monitor; ec_fan_monitor_init(&fan_monitor);
    ec_lid_config_t lc=ec_lid_default_config(); ec_lid_state_t ls; ec_lid_state_init(&ls);
    ec_battery_config_t bc=ec_battery_default_config(); ec_battery_controller_t bs; ec_battery_state_init(&bs);
    bool retry_active=false, retry_consumed=false; uint32_t retry_started=0;
    for (;;) {
        uint32_t now=GetTick();
        if (!usb_power_poll(&usb_power,now)) NVIC_SystemReset();
        now=GetTick();
        uint16_t rpm=0; uint8_t duty=ec_app_fan_step(&fc,&fs,now,&rpm);
        fan_healthy=ec_fan_monitor_step(&fan_monitor,gpio_get_mu_12v_pg(),duty,rpm,now);
        if (!fan_healthy) gpio_set_fan_pwm_duty(100);
        ec_inputs_t in; ec_telemetry_inputs_t ti; read_inputs(&in,&ti,now);
        refresh_transfer_interlocks(&in,now,&now);
        ec_controller_arbitrate(&controller,&in,now); ec_controller_step(&controller,&in,now);
        const ec_outputs_t *out=ec_controller_outputs(&controller);
        if ((!out->mu_12v_enable || controller.transfer_active || !in.thermal_ok ||
             !in.power_limits_applied || !in.service_bus_healthy ||
             (usb_power.have_source && usb_power.last_source!=(uint8_t)controller.active_source)) &&
            !usb_power_disable(&usb_power)) NVIC_SystemReset();
        if (ec_commit_apply(&commits,&driver,out) != EC_COMMIT_OK) NVIC_SystemReset();
        ec_app_update_throttle(out->mu_12v_enable && in.service_bus_healthy &&
            in.thermal_ok && (out->power_policy_confirmed || out->mu_boot_authorized),
            controller.active_source==EC_SOURCE_PACK || controller.transfer_active);
        /* Both source-control expanders follow NRST after a failed safe write. */
        now=GetTick();
        ec_host_state_t host=ec_host_state(now);
        uint64_t used=(uint64_t)config.system_reserve_mw+host.budget_mw+other_auxiliary_mw;
        usb_power_request_t ur={
            .host_lease_valid=host.valid,
            .vsys_measurement_valid=DUCKTOP2_VSYS_SENSE_QUALIFIED && in.vsys_valid,
            .vsys_measured_mv=in.vsys_mv,.vsys_age_ms=in.vsys_sample_age_ms,
            .system_safe=out->mu_12v_enable && gpio_get_mu_12v_pg() && in.thermal_ok &&
                         in.service_bus_healthy && out->power_policy_confirmed &&
                         in.estimated_aux_power_valid,
            .transfer_active=controller.transfer_active,
            .clear_fault=ec_host_take_usb_clear(now),
            .requested_mask=host.usb_requested_mask,.active_source=(uint8_t)controller.active_source,
            .available_input_power_mw=out->source_usable_power_mw>used ?
                                      (uint32_t)(out->source_usable_power_mw-used) : 0u,
            .committed_reservation_mw=in.estimated_aux_power_mw-other_auxiliary_mw
        };
        if (!usb_power_step(&usb_power,&ur,now)) NVIC_SystemReset();
        ec_host_usb_status_t us=usb_power_status(&usb_power,now);
        ec_host_publish_usb(&us);
        bool retry_request=host.valid && (host.requests & EC_HOST_REQUEST_BMS_RETRY);
        bool external=controller.active_source!=EC_SOURCE_NONE && controller.active_source!=EC_SOURCE_PACK;
        if (!retry_request) retry_consumed=false;
        if (!retry_active && !retry_consumed && retry_request && external &&
            !out->mu_12v_enable && !out->charger_enable && DUCKTOP2_PACK_QUALIFIED) {
            if (!tca9539_set_bms_retry(true)) NVIC_SystemReset();
            retry_active=true; retry_consumed=true; retry_started=now;
        }
        if (retry_active && (!external || now-retry_started>=100u)) {
            if (!tca9539_set_bms_retry(false)) NVIC_SystemReset();
            retry_active=false;
        }
        ec_keymap_matrix_t matrix; ec_hid_keyboard_report_t kb; ec_hid_consumer_report_t consumer;
        matrix_scan_get_matrix(&matrix); ec_keymap_process(&matrix,&kb,&consumer);
        usb_hid_send_keyboard(&kb); usb_hid_send_consumer(&consumer);
        ec_lid_inputs_t li={.lid_open_raw=gpio_get_lid_open()}; ec_lid_output_t lid;
        ec_lid_step(&lc,&li,&ls,now,&lid);
        ti.active_source=controller.transfer_active ? EC_SOURCE_PACK : controller.active_source;
        if (ti.active_source!=EC_SOURCE_NONE) ti.valid_flags|=EC_TELEMETRY_VALID_ACTIVE_INPUT;
        for (uint8_t p=0;p<2;p++) {
            const ec_source_observation_t *obs=&in.source[EC_SOURCE_PD1+p];
            ti.pd[p].valid=obs->qualified_input_current_valid;
            ti.pd[p].voltage_mv=obs->negotiated_voltage_mv;
            ti.pd[p].current_ma=obs->qualified_input_current_ma;
        }
        ec_telemetry_snapshot_t snapshot; ec_telemetry_build_snapshot(&snapshot,&ti);
        ec_battery_inputs_t bi={.telemetry=snapshot,.pack_present=ec_app_battery_present(),.charger_enable=out->charger_enable};
        ec_battery_report_t battery; ec_battery_step(&bc,&bi,&bs,now,&battery);
        uint16_t flags=(battery.present?1u:0u) | (lid.lid_closed?2u:0u) | (!fan_healthy?4u:0u) |
                       (headphone_present?8u:0u) | (external?16u:0u) | (out->mu_boot_authorized?32u:0u) |
                       (ec_app_charging_active()?64u:0u) | (host.valid?128u:0u);
        ec_host_publish(&snapshot,&battery,flags,(uint16_t)controller.fault,rpm,now);
        static uint32_t audio_due;
        if ((int32_t)(now-audio_due)>=0) {
            audio_due=now+500u;
            bool headphones=headphone_present && host.valid && out->mu_12v_enable &&
                             (host.requests & EC_HOST_REQUEST_SPEAKER);
            if (!audio_headphones(headphones)) gpio_set_audio_amp_enable(false);
        }
        ssd1306_status_step(&snapshot,flags,(uint16_t)controller.fault,rpm,duty,
            ec_app_ntc_counts_to_temp_dc(gpio_read_adc_thermal_skin()),
            ec_app_ntc_counts_to_temp_dc(gpio_read_adc_thermal_mu()),now);
        keyboard_rgb_service(GetTick());
        usb_hid_poll(); ec_watchdog_pet(); DelayMs(20);
    }
}

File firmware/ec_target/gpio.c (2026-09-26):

#include "gpio.h"
#include "fan_math.h"
#include "stm32f4xx.h"

void gpio_init_all(void)
{
    RCC->AHB1ENR |= RCC_AHB1ENR_GPIOAEN | RCC_AHB1ENR_GPIOBEN
                  | RCC_AHB1ENR_GPIOCEN | RCC_AHB1ENR_GPIODEN
                  | RCC_AHB1ENR_GPIOEEN;

    /* Set inactive output latches before output modes to avoid button pulses. */
    GPIOA->ODR = (1u << 0) | (1u << 5) | (1u << 8) | (1u << 15);
    GPIOB->ODR = 1u << 15;
    GPIOC->ODR = (1u << 8) | (1u << 9) | (1u << 10);
    GPIOD->ODR = 0u;
    GPIOE->ODR = 0u;
    /* Preserve SWD on PA13/PA14 through normal startup. */
    GPIOA->MODER = (2u << 26) | (2u << 28);
    GPIOA->PUPDR = (1u << 26) | (2u << 28);
    GPIOA->AFR[1] &= ~((0xFu << 20) | (0xFu << 24));
    GPIOB->MODER = 0;
    GPIOC->MODER = 0;
    GPIOD->MODER = 0;
    GPIOE->MODER = 0;

    /* ---- Port A ---- */

    /* PA0: MU_PWRBTN_N - Output, open-drain, high (inactive) */
    GPIOA->MODER   |= GPIO_MODER_OUTPUT << (0 * 2);
    GPIOA->OTYPER  |= GPIO_OTYPER_OD << 0;
    GPIOA->PUPDR   |= GPIO_PUPDR_PU << (0 * 2);
    GPIOA->ODR     |= 1u << 0;

    /* PA1: BQ_ALERT - Input, pull-up */
    GPIOA->PUPDR   |= GPIO_PUPDR_PU << (1 * 2);

    /* PA2: CHG_INT_N - Input, pull-up */
    GPIOA->PUPDR   |= GPIO_PUPDR_PU << (2 * 2);

    /* PA3: MU_PROCHOT_RELEASE - low keeps the module throttled. */
    GPIOA->MODER   |= GPIO_MODER_OUTPUT << (3 * 2);

    /* PA4: CHG_ENABLE - Output, push-pull, low (charger off) */
    GPIOA->MODER   |= GPIO_MODER_OUTPUT << (4 * 2);

    /* PA5: MU_RSTBTN_N - Output, open-drain, high (inactive) */
    GPIOA->MODER   |= GPIO_MODER_OUTPUT << (5 * 2);
    GPIOA->OTYPER  |= GPIO_OTYPER_OD << 5;
    GPIOA->ODR     |= 1u << 5;

    /* PA6: AUX_DC_ADC - Analog */
    GPIOA->MODER   |= GPIO_MODER_ANALOG << (6 * 2);

    /* PA7: THERM_SKIN_ADC - Analog */
    GPIOA->MODER   |= GPIO_MODER_ANALOG << (7 * 2);

    /* PA8: WIFI_W_DISABLE1_N_EC - Output, push-pull, high (disabled) */
    GPIOA->MODER   |= GPIO_MODER_OUTPUT << (8 * 2);
    GPIOA->ODR     |= 1u << 8;

    /* PA9: GNSS_UART_TX - AF7 (USART1) */
    GPIOA->MODER   |= GPIO_MODER_AF << (9 * 2);
    GPIOA->AFR[1]     = (GPIOA->AFR[1] & ~(0xFu << 4)) | (GPIO_AF7 << 4);

    /* PA10: GNSS_UART_RX - AF7 (USART1) */
    GPIOA->MODER   |= GPIO_MODER_AF << (10 * 2);
    GPIOA->AFR[1]     = (GPIOA->AFR[1] & ~(0xFu << 8)) | (GPIO_AF7 << 8);

    /* PA11: MCU_USB_DN - AF10 (OTG_FS) */
    GPIOA->MODER   |= GPIO_MODER_AF << (11 * 2);
    GPIOA->AFR[1]     = (GPIOA->AFR[1] & ~(0xFu << 12)) | (GPIO_AF10 << 12);

    /* PA12: MCU_USB_DP - AF10 (OTG_FS) */
    GPIOA->MODER   |= GPIO_MODER_AF << (12 * 2);
    GPIOA->AFR[1]     = (GPIOA->AFR[1] & ~(0xFu << 16)) | (GPIO_AF10 << 16);

    /* PA13: SWDIO - leave as default (AF0, pull-up) */

    /* PA14: SWCLK - leave as default (AF0, pull-down) */

    /* PA15: WIFI_W_DISABLE2_N_EC - Output, push-pull, high (disabled) */
    GPIOA->MODER   |= GPIO_MODER_OUTPUT << (15 * 2);
    GPIOA->ODR     |= 1u << 15;

    /* ---- Port B ---- */

    /* PB0: THERM_MU_ADC - Analog */
    GPIOB->MODER   |= GPIO_MODER_ANALOG << (0 * 2);

    /* PB1: TRACKPAD_FAULT_N - Input, pull-up */
    GPIOB->PUPDR   |= GPIO_PUPDR_PU << (1 * 2);

    /* PB2: PD2_VALID_N - Input, pull-up */
    GPIOB->PUPDR   |= GPIO_PUPDR_PU << (2 * 2);

    /* PB3: (JTDO/SWO) - leave as default */

    /* PB4: PD2_TCPC_IRQ_N - Input, pull-up */
    GPIOB->PUPDR   |= GPIO_PUPDR_PU << (4 * 2);

    /* PB5: RADIO_DB_PWR_EN - Output, push-pull, low (off) */
    GPIOB->MODER   |= GPIO_MODER_OUTPUT << (5 * 2);

    /* PB6: I2C1_SCL - AF4 */
    GPIOB->MODER   |= GPIO_MODER_AF << (6 * 2);
    GPIOB->OTYPER  |= GPIO_OTYPER_OD << 6;
    GPIOB->PUPDR   |= GPIO_PUPDR_PU << (6 * 2);
    GPIOB->OSPEEDR |= GPIO_OSPEEDR_HIGH << (6 * 2);
    GPIOB->AFR[0]     = (GPIOB->AFR[0] & ~(0xFu << 24)) | (GPIO_AF4 << 24);

    /* PB7: I2C1_SDA - AF4 */
    GPIOB->MODER   |= GPIO_MODER_AF << (7 * 2);
    GPIOB->OTYPER  |= GPIO_OTYPER_OD << 7;
    GPIOB->PUPDR   |= GPIO_PUPDR_PU << (7 * 2);
    GPIOB->OSPEEDR |= GPIO_OSPEEDR_HIGH << (7 * 2);
    GPIOB->AFR[0]     = (GPIOB->AFR[0] & ~(0xFu << 28)) | (GPIO_AF4 << 28);

    /* PB8: GNSS_EXTINT - Input, pull-down */
    GPIOB->PUPDR   |= GPIO_PUPDR_PD << (8 * 2);

    /* PB9: PD_PROTECT_FAULT_N - Input, pull-up */
    GPIOB->PUPDR   |= GPIO_PUPDR_PU << (9 * 2);

    /* PB10: RADIO_VHF_UART_TX - AF7 (USART3) */
    GPIOB->MODER   |= GPIO_MODER_AF << (10 * 2);
    GPIOB->AFR[1]     = (GPIOB->AFR[1] & ~(0xFu << 8)) | (GPIO_AF7 << 8);

    /* PB11: RADIO_VHF_UART_RX - AF7 (USART3) */
    GPIOB->MODER   |= GPIO_MODER_AF << (11 * 2);
    GPIOB->AFR[1]     = (GPIOB->AFR[1] & ~(0xFu << 12)) | (GPIO_AF7 << 12);

    /* PB12: SERVICE_MUX_RESET_REQ_N - Output, push-pull, low (reset held) */
    GPIOB->MODER   |= GPIO_MODER_OUTPUT << (12 * 2);

    /* PB13: GNSS_RESET_N - Output, push-pull, low (reset asserted) */
    GPIOB->MODER   |= GPIO_MODER_OUTPUT << (13 * 2);
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

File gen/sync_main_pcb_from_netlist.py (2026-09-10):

#!/usr/bin/env python3
"""Narrow, auditable main-PCB sync from the exported KiCad XML netlist.

KiCad 10's CLI can export/check, but it does not expose the GUI
"Update PCB from Schematic" operation.  The pcbnew Python bindings are also
fragile in headless use on macOS, so this helper makes deterministic
S-expression edits instead.

It performs only the safe subset needed here:

* update footprint path/value/sheet metadata by reference
* update pad nets from the schematic netlist
* replace only explicitly allowed changed footprints
* add only explicitly allowed new footprints
"""

from __future__ import annotations

import argparse
import math
import re
import subprocess
import uuid
import xml.etree.ElementTree as ET
from dataclasses import dataclass
from pathlib import Path


ROOT = Path(__file__).resolve().parents[1]
PCB = ROOT / "ducktop2.kicad_pcb"
SCH = ROOT / "ducktop2.kicad_sch"
NETLIST = ROOT / "verification" / "generated" / "ducktop2_netlist.xml"

# Board split projects: left I/O, right I/O, and BMS daughterboards.  Each
# project has its own schematic root; the netlist path follows the project name.
PROJECTS = {
    "ducktop2": (ROOT / "ducktop2.kicad_sch", ROOT / "verification" / "generated" / "ducktop2_netlist.xml"),
    "left_io": (ROOT / "left_io" / "left_io.kicad_sch", ROOT / "verification" / "generated" / "left_io_netlist.xml"),
    "right_io": (ROOT / "right_io" / "right_io.kicad_sch", ROOT / "verification" / "generated" / "right_io_netlist.xml"),
    "bms": (ROOT / "bms" / "bms.kicad_sch", ROOT / "verification" / "generated" / "bms_netlist.xml"),
}
KICAD_CLI = Path("/Applications/KiCad/KiCad.app/Contents/MacOS/kicad-cli")

FOOTPRINT_DIRS = [
    ROOT / "ducktop2.pretty",
    ROOT / "Module_LattePanda.pretty",
    Path("/Applications/KiCad/KiCad.app/Contents/SharedSupport/footprints"),
]

CURRENT_ECO_ADD_ONLY = set()  # Q62 restored 2026-08-24; USB-A pads netted by sync
CURRENT_ECO_REPLACE_ONLY = set()  # DF40 -> FH12-30S J2300 swap completed (b13a110)
# These parts were added by the current ECO, then corrected from 0603 to 0805
# after the BQ77915 internal-balancing filter requirement was rechecked.
POST_ADD_FOOTPRINT_REFRESH = set()

ALLOWED_ADD_OR_REPLACE = CURRENT_ECO_REPLACE_ONLY | POST_ADD_FOOTPRINT_REFRESH
ALLOWED_ADD_ONLY = CURRENT_ECO_ADD_ONLY
ALLOWED_REMOVE_ONLY = set()  # Q60B1 phantom, R1730-R1733 straps, J8/J50, Q62 all resolved
FORCE_REPLACE = set(CURRENT_ECO_REPLACE_ONLY)
REPOSITION_EXISTING: set[str] = set()

ANCHORS_MM = {
    # Reset-qualified service mux logic.  Keep the gate, request pull-up and
    # bypass together; the reset output then runs directly to nearby U45.
    "U46": (236.0, 31.0, 0.0),
    "C781": (241.5, 31.0, 0.0),
    "R172": (236.0, 35.0, 0.0),

    # C502/C503 are the only Ethernet coupling capacitors with approved anchors.
    # C500/C501 must be re-placed beside the on-board U500 PCIe device per the
    # Mu guide; the current placement is a release hold and has no approved anchor.
    "C502": (314.5, 105.0, 0.0),
    "C503": (314.5, 103.8, 0.0),
    "J2300": (62.5, 181.5, 0.0),  # radio DB FFC at bottom edge, FH12 pads fully on-board

    # 2026-08-24 USB-A spare-port row on the left edge, 22.5mm grid below J190.
    # J24 (USB3-A, hub DIS5) at slot y=115, J25 (USB2-A, hub DIS6) at y=137.5;
    # rot 270 puts the receptacle opening at the x=0 board edge.  Support parts
    # cluster inboard: U1800/U1801/U1802 = TPS2553/USBLC6/TPD4E05U06 for J24,
    # U1803/U1804 = TPS2553/USBLC6 for J25, AC caps C1852/C1853 on SSTX.
    "J24": (4.5, 115.0, 270.0),
    "J25": (4.5, 137.5, 270.0),
    "U1800": (17.0, 118.0, 0.0),
    "U1801": (17.0, 110.0, 0.0),
    "U1802": (23.0, 110.0, 0.0),
    "R1850": (17.0, 124.0, 0.0),
    "C1850": (14.0, 113.0, 0.0),
    "C1851": (14.0, 117.0, 0.0),
    "C1852": (14.0, 121.0, 0.0),
    "C1853": (14.0, 125.0, 0.0),
    "U1803": (17.0, 135.0, 0.0),
    "U1804": (17.0, 143.0, 0.0),
    "R1851": (17.0, 131.0, 0.0),
    "C1854": (14.0, 134.0, 0.0),
    "C1855": (14.0, 138.0, 0.0),
    "J8": (286.0, 172.0, 0.0),   # DNP Mu SIO UART debug header (per prepare_main_pcb_layout)
    "J50": (174.0, 144.0, 0.0),  # DNP EC USB probe (per prepare_main_pcb_layout)

    # 2026-08-01 proposed rear headphone section (rear edge, free x 110..240):
    # J422 SJ1-3535NG body spans local y[-5.2, 12.8]; rot 0 exits the plug
    # through the top edge (y=185).  U425 WQFN-20 below it; 0805 caps in two
    # 2x2 blocks either side; C465 0603 under U425.
    "J422": (140.0, 172.2, 0.0),
    "U425": (140.0, 158.0, 0.0),
    "C465": (140.6, 152.0, 0.0),
    "C461": (130.5, 163.0, 0.0),
    "C462": (130.5, 159.5, 0.0),
    "C463": (133.6, 163.0, 0.0),
    "C464": (133.6, 159.5, 0.0),
    "C457": (146.4, 163.0, 0.0),
    "C458": (146.4, 159.5, 0.0),
    "C459": (149.5, 163.0, 0.0),
    "C460": (149.5, 159.5, 0.0),

    "U45": (296.0, 33.0, 0.0),
    "C185": (296.0, 42.0, 0.0),
    # Integrated RP2350 maker controller. This cluster replaces the former
    # 21 x 51 mm Pico module envelope; J901/J902 and their routing stay put.
    "F900": (356.0, 8.0, 0.0),
    "C921": (360.5, 8.0, 0.0),
    "C900": (362.5, 11.0, 0.0),
    "U903": (367.0, 8.0, 0.0),
    "L900": (371.0, 8.0, 0.0),
    "C901": (375.0, 8.0, 0.0),
    "R902": (378.0, 8.0, 0.0),
    "R903": (378.0, 10.0, 0.0),

    "U902": (359.5, 20.0, 0.0),
    "C902": (362.5, 16.0, 0.0),
    "C903": (363.0, 18.0, 0.0),
    "R904": (363.0, 20.5, 0.0),
    "R905": (354.5, 28.4, 0.0),

    "U901": (369.0, 28.0, 0.0),
    "L901": (369.0, 19.0, 0.0),
    "C911": (365.0, 19.0, 0.0),
    "C912": (373.0, 19.0, 0.0),
    "R907": (376.0, 19.0, 0.0),
    "C913": (378.5, 19.0, 0.0),
    "C904": (363.5, 24.0, 0.0),
    "C905": (366.0, 22.0, 0.0),
    "C906": (369.0, 22.5, 0.0),
    "C907": (372.0, 22.0, 0.0),
    "C908": (374.5, 24.0, 0.0),
    "C909": (363.5, 32.0, 0.0),
    "C910": (366.0, 34.0, 0.0),
    "C914": (369.0, 33.5, 0.0),
    "C915": (372.0, 34.0, 0.0),
    "C916": (374.5, 32.0, 0.0),
    "R908": (377.0, 30.0, 0.0),
    "R909": (379.0, 30.0, 0.0),
    "C922": (374.5, 36.0, 0.0),
    "C917": (378.0, 33.0, 0.0),

    "Y900": (371.0, 38.0, 0.0),
    "R906": (375.0, 38.0, 0.0),
    "C918": (369.0, 40.5, 0.0),
    "C919": (373.0, 40.5, 0.0),
    "U900": (378.0, 24.5, 0.0),
    "R900": (377.0, 27.0, 0.0),
    "R901": (379.0, 27.0, 0.0),
    "R910": (377.0, 36.0, 0.0),
    "R911": (379.0, 36.0, 0.0),

    "R912": (358.0, 35.0, 0.0),
    "R913": (360.5, 35.0, 0.0),
    "C920": (358.0, 37.5, 0.0),
    "Q900": (361.0, 39.0, 0.0),
    "R914": (358.0, 41.0, 0.0),
    "R915": (358.0, 44.0, 0.0),
    "D900": (361.0, 44.0, 0.0),
    "R916": (354.5, 36.0, 0.0),
    "R918": (354.5, 43.5, 0.0),
    "R919": (354.5, 45.5, 0.0),
}
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

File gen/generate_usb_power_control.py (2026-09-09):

#!/usr/bin/env python3
"""Independent EC permissions and measured USB power protection.

This module builds symbols into caller-owned sheets. It never writes a PCB
or schematic. Power converter values remain in the converter generator.
"""
import build_ducktop2 as b
import genlib

PORTS = ('J21','J11','J22','J23','J12','J24','J25')
PERMIT_NETS = {port: 'USB_'+port+'_PERMIT' for port in PORTS}
GATE_REFS = {'J22':'U2405','J23':'U2406','J24':'U2407','J25':'U2408','J12':'U2409'}
PP5V_NETS = {'J21':'PD1_PP5V_GATED','J11':'PD2_PP5V_GATED'}
PP5V_PG = {'J21':'PD1_SOURCE_PG','J11':'PD2_SOURCE_PG'}
CTRL_OUT0 = ('USB5_PERMIT', *(PERMIT_NETS[p] for p in PORTS))
CTRL_OUT1 = {'0':'USB5_FAULT_CLEAR_N'}
CTRL_IN1 = {1:'USB5_FAULT_N',2:'USB5_OC_N',3:'USB5_PG',4:'PD1_SOURCE_PG',5:'PD2_SOURCE_PG',6:'INTERNAL_USB_VBUS_VALID'}

LOCAL_CONTROL_NETS = {'USB5_PERMIT', 'USB5_FAULT_N', 'USB5_OC_N',
                      'USB5_PG', 'USB5_FAULT_CLEAR_N',
                      *(PERMIT_NETS[p] for p in ('J22','J23','J24','J25'))}

def net_kind(net):
    return 'local' if net in LOCAL_CONTROL_NETS else 'hier'

def register_symbols():
    genlib.LIBMAP.update({'INA226':'Sensor_Energy','74LVC1G11':'74xGxx',
                         'SN74LVC1G74DCU':'SN74LVC1G74DCU','TPS22992S':'TPS22992S'})


def props(mpn, source):
    return {'Manufacturer':'Texas Instruments','MPN':mpn,'Datasheet':source}


def resistor(s, ref, value, x, y, first, second, first_kind='local', second_kind='local'):
    mpn={'10k':'RC0603FR-0710KL','100k':'RC0603FR-07100KL',
         '12.7k 1%':'RC0603FR-0712K7L'}[value]
    s.place(ref,'R',value,x,y,footprint=b.FOOTPRINTS['R'],
            pin_nets={'1':(first,first_kind),'2':(second,second_kind)},
            extra_props={'Manufacturer':'Yageo','MPN':mpn})
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

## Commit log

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2026-07-21 Relocate 23 high-speed AC coupling caps and complete pre-routing design review
    - Move 23 PCIe/USB3/HDMI coupling caps from 12-90mm to ~4-15mm from endpoints
    - Three DRC iterations (v1→v2→v3) to resolve copper shorting from initial placement
    - Final DRC: 424 violations (14 new, all silkscreen ref overlaps on right PD caps — no copper issues)
    - ECO parity: 0 mismatches (schematic↔PCB fully synced)
    - Independent design review: CONDITIONAL PASS, schematic clean
    - Corrected distance analysis written for NVMe/Mu USB3 TX caps
    - Add keyboard microstencil 3MF for JLCPCB
    [ducktop2_mx_ulp_fixation_microstencil_revA.3mf]
2026-07-23 Refresh repository with updated PCB renders and current design state
    - New 3D renders: top, bottom, perspective, and keyboard PCB
    (generated via kicad-cli 10.0.4, 2560x1440, high quality)
    - Update README status: placement complete, coupling caps relocated,
    independent design review CONDITIONAL PASS (2026-07-21)
    - Add keyboard rev-A fullboard stencil generation (3MF, STL, manifest, script)
    - Track TPS3897ADRYR library symbol
    - WIP schematic, PCB, and generator refinements post-coupling-cap fix
    [03_mu_carrier.kicad_sch, 04_usb_c_io.kicad_sch, 06_tcp0_external_hdmi.kicad_sch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]
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2026-07-28 Assign 327 BOM MPNs across 11 schematic sheets (370→43 gaps)
    Closes 370 BOM procurement gaps by assigning Yageo resistor and Murata
    capacitor MPNs to all passive components in the project's 11 schematic
    sheets. 43 intentional holds remain for design-review items (crystal
    loads, audio AC-coupling, VCAP, C0G timing, maker MCU 4.7u 0402s).
    Key changes:
    - 205 resistors assigned (Yageo RC0603/RT0603 series)
    - 124 capacitors assigned (Murata GRM series, matching footprint body size)
    - Fixed C183: 4.7u MPN→1u (GRM21BR71A105KA01L)
    - Fixed C795/C840: upgraded to 50V rating (GRM21BR71H105KA12L)
    - Generated fresh inventory: 1173 components, 43 remaining gaps
    [01_power_battery.kicad_sch, 02_ec_mcu.kicad_sch, 03_mu_carrier.kicad_sch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]
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2026-07-28 Add 3D STEP models for remaining ducktop2 components
    New models added:
    - JXD1-1022NL_MidMount (RJ45) - Pulse official ZIP
    - Amphenol_MDT420E01001_H4.2 (M.2 Key E) - ComponentSearchEngine
    - TDK_TFM201610 (inductor) - GrabCAD
    - Infineon_IM68A130V01 (MEMS mic) - UltraLibrarian
    - MiniCircuits_QA2224_PL484 (RF filter) - PCB-3D
    - Texas_RPA0010A_VQFN-HR-10_3x3mm (TI reg)
    - Texas_RPW0010A_VQFN-HR-10_2x2mm (TI reg)
    - Texas_RYQ0021A_VQFN-HR-21_3x5mm (TI reg)
    - Texas_TPD1S514_YZ_WCSP-12 (TI OVP IC)
    Still missing: Amphenol_MDT420M01001_H4.2 (M.2 Key M) - use DigiKey 5810337
    [ducktop2.kicad_pcb, radio_daughterboard.kicad_pcb]
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2026-07-28 Fix radio DB J1 layer (F.Cu->B.Cu) for mezzanine stack; add radio DB outline on mainboard Dwgs.User
    [ducktop2.kicad_pcb, radio_daughterboard.kicad_pcb]
2026-07-28 Fix 3D model paths: use KIPRJMOD not KICAD10_3DMODEL_DIR for project models; Move J1 to B.Cu and relocate 77 fanout traces + 42 stitch vias for mezzanine stack
    [12_keyboard_daughterboard.kicad_pcb, ducktop2.kicad_pcb, radio_daughterboard.kicad_pcb]
2026-07-30 P1.4: Define 6-layer fabrication stackup for NextPCB
    - Change In1.Cu and In4.Cu from 'power' to 'signal' type (solid GND pours)
    - Add stackup block to ducktop2.kicad_pcb: 6-layer 1.6mm, 2116/2313 prepreg,
    0.8mm FR4 cores, 1oz all layers, ENIG finish
    - Update mainboard_stackup_release.json with committed stackup parameters
    - COMPREHENSIVE_REVIEW_2026-07-30.md: all 9 P1 items updated with closure status
    - All verification docs updated: stackup references marked COMPLETED/RESOLVED
    - README.md and docs/design-status.md: roadmap items marked done
    - Single-sided assembly decision: all components on top, bottom routing-only
    [ducktop2.kicad_pcb]
2026-07-30 Fix 3D model paths and update PCB format to KiCad 10.0
    - Update 3D model paths in radio and keyboard daughterboards to use KIPRJMOD
    - Replace Cherry MX ULP STEP model with corrected version
    - Add Hirose DF40C and ublox MAX-7Q 3D STEP models
    - Fix 3D model offset scripts for mezzanine connector stack
    - Auto-format integer-to-float notation from KiCad 10.0 save
    [12_keyboard_daughterboard.kicad_pcb, radio_daughterboard.kicad_pcb]
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2026-07-31 Fix ERC + annotation issues in EC DFU programming section (08)
    - Move 7 stranded GND labels onto their correct pin connection points
    - Reposition #PWR2ac409aa onto U71 GND pin (was double-moved off-point)
    - Rename power symbols to digit-terminated refs (#PWR2302-2308); letter-
    terminated refs (e.g. #PWRf564ab8b) made SCH_REFERENCE::Split flag them
    as unannotated, triggering the netlist 'annotation errors' warning
    - Align property Reference with instances reference for all 7 power symbols
    - Add power:PWR_FLAG (#FLG071) on EC_PROG_VBUS to drive U71 VIN
    ERC for /Internal Services/ section now reports zero violations (64 total
    remaining are all pre-existing project-wide baseline). Netlist e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
    [08_internal_services.kicad_sch]
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2026-07-31 Regenerate child schematics to sync with current generators
    The committed .kicad_sch carried stale embedded Manufacturer/MPN properties from the old per-component BOM approach (MPNs now live in verification/BOM_MPN_ASSIGNMENTS.md). Regenerating from the current generators strips those stale properties and clears the pre-existing Generated-source identity release-check failure. No connectivity change; ERC still 0 errors / 27 intentional warnings; schematic closure 1569/0.
    [01_power_battery.kicad_sch, 02_ec_mcu.kicad_sch, 03_mu_carrier.kicad_sch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]
2026-07-31 Add rear 3.5mm headphone jack with plug-detect speaker mute (sheet 15)
    Add the missing headphone output the user-verified behavior requires (row 11): rear CUI SJ1-3535NG stereo jack driven by a TPA6130A2RTJR DirectPath headphone amp, with automatic plug-detect speaker muting like a normal laptop.
    - U425 TPA6130A2 (I2C @0x60, fixed): single-ended inputs from PCM2900C DAC_VOUT_L/R via 0.47u coupling (INM signal, INP AC-grounded per datasheet 9.2.2.1); capless ground-referenced HPLEFT/HPRIGHT outputs to jack T/R. Charge-pump flying + CPVSS + VDD bypass per 9.2.2.2/3.
    - J422 SJ1-3535NG: RN ring normalling switch is plug detect (unplugged shorts RN to R = amp 0V -> low; plugged floats -> high).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
    [02_ec_mcu.kicad_sch, 15_system_audio.kicad_sch, ducktop2.kicad_sch]
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2026-08-01 Apply placement fixer pass 2: 190 passive moves (shorts 199->97, mask 199->107)
    [ducktop2.kicad_pcb]
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2026-08-09 Update Edge.Cuts to plain 358x185 rect, regenerate Dwgs.User sheet guides, fix J2300 position
    [ducktop2.kicad_pcb]
2026-08-09 Fix Edge.Cuts: properly replace 5 notch lines with 1 rect edge (358x185 outline)
    [ducktop2.kicad_pcb]
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2026-08-11 Placement: resolve all pad collisions, apply user floorplan export
    Floorplan → PCB: J22 moves to (4.5, 5.9); J58 moves to (190, 120).
    47 small parts auto-nudged (fixer + targeted passes with wider search).
    6 big parts nudged: U44, U2303, U410, U2016, U501, U1700 (USB hub
    relocated from Mu module area at 190.1,53.3 to 261.2,38.4).
    J58 Dwgs.User guide updated to match new trackpad position.
    .lck files cleaned up.
    DRC: 1548→1373 violations, 120→68 shorts, 174→98 solder mask bridges.
    0 placement-level pad collisions remaining.
    68 remaining shorts are in tight signal clusters (J500 ethernet, J310 FFC).
    [ducktop2.kicad_pcb]
2026-08-11 Fix port positions: J22 to y=25, J21 to y=36.4, guides to footprint bboxes
    J22 (usb-c-left-1) was at y=5.9 in the hinge keepout (previous AI error).
    Restored to y=25 within the left-ports corridor (y=20-180).
    J21 nudged to y=36.4 to clear J22.
    All Dwgs.User guides regenerated from actual footprint pad bounding
    boxes — they now visually align with component bodies in KiCad.
    Left edge: J22@y=25, J21@y=36, J23@y=48
    Right edge: J11@y=93
    Top edge: J422@y=2
    Ethernet: J500@(332,104)
    0 pad collisions, 1383 DRC violations.
    [ducktop2.kicad_pcb]
2026-08-11 Fix port positions, M.2 card layout, and guides (verified with DRC)
    Left edge: spread USB-C ports to 22.5mm pitch (J22@25, J21@47.5, J23@70)
    Right edge: J11 USB-C moved below the ethernet jack (y=135), clearing
    the 1.6mm squeeze against J500
    J58: reverted to documented datum (171.2, 130) - planner position
    collided with the NVMe socket
    M.2 layout (verified against kicad-cli DRC pad geometry):
    - J10 (NVMe) restored to retention position (196.4, 125.25): card at
    x=204-284, y=104-128, H3 standoff supports it again; the floorplan
    move to (215, 110) had broken the H3 relationship and overlapped
    the WiFi card
    - J40 (WiFi) moved to bottom area (235.4, 158): card at x=236-266,
    y=155.5-179,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
    [ducktop2.kicad_pcb]
2026-08-12 Add ethernet jack mid-mount cutout, verify M.2 slots and port alignment
    Ethernet J500: added the mid-mount board cutout (right-edge notch at
    x=352.78-358, y=88-107) so the JXD1-1022NL body recesses into the
    board instead of sitting on top - matching the footprint's
    'PCB EDGE / PANEL PLANE' datum. Moved C290/R504/R505 clear of the
    notch edges.
    Verified both M.2 sockets on board: J10 NVMe at (196.4, 125.2) and
    J40 WiFi at (235.4, 158), cards clear of each other with H3/H4
    standoff support.
    Right edge ports: J12 (353.5, 48), J30 HDMI (352.3, 72), J500 (332,
    104), J11 (347.4, 135).
    DRC: 49 shorts and 38 edge-clearance - all pre-existing documented
    issues (J500 ethernet cluster, J310 FFC, A1 m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
    [ducktop2.kicad_pcb]
2026-08-12 Fix all remaining DRC shorts: 49 -> 0
    Resolved every pad-to-pad short with verified moves:
    A1 Mu module (9 shorts): C1707/C1820 moved to (194.5, 22-25), L1701
    to (168, 40) - clear of the module's edge connector pads.
    J310 keyboard FFC (7 shorts): C1762 to (321.1, 31.5), D2120 to
    (323, 60) - clear of the FFC pad row.
    J500 ethernet cluster (33 shorts): U501/U502 (MDI filter ICs) moved
    left of the jack's magnetics pins to (327, 104.3)/(327, 92), staying
    adjacent to U500 (PHY) for signal integrity; U2303, C501, C508,
    C513, C512, C24, C28, R2307, R2350 nudged clear of the custom pad
    shapes and each other.
    DRC: 1316 -> 1128 violations, shorts 49 -> 0, solder mask bridges
    78 -> 4. Remaining vio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
    [ducktop2.kicad_pcb]
2026-08-12 Clean up Dwgs.User guides: remove 67 stale blocks, regenerate 21 aligned pairs
    The previous regeneration left ~17 old guide texts and ~10 old rects in
    place (stale positions, duplicates with the new set). Removed all
    Dwgs.User blocks and regenerated one consistent set of 21 guide pairs
    positioned from each part's actual pad bounding box:
    A1, J500, J11, J12, J22, J21, J23, J30, J422, J2, J52, J310, J420,
    J58, MK430, J10, J40, J41, J45, J2300, U425
    DRC: 1128 -> 1092 violations (stale overlapping guides were also
    causing violations), shorts remain 0.
    [ducktop2.kicad_pcb]
2026-08-12 Swap J2300 to FH12-30S FFC, remove 52 dangling route stubs
    J2300: replaced the obsolete DF40C-60DP footprint with the schematic's
    Hirose_FH12-30S-0.5SH (30-pin FFC) via sync_main_pcb_from_netlist.py
    (scoped --refs J2300). Position preserved at (62.5, 183) at the radio
    daughterboard edge; 32 pad nets remapped from the netlist. Fixed the
    script's stale J2300 anchor (was 288.4, 149.1).
    Removed 52 orphaned arcs on /WIFI_CLKREQ_N left over from the old WiFi
    socket position (these were the track_dangling DRC items).
    DRC: 953 -> 871 violations, track_dangling 52 -> 0, copper edge
    clearance 38 -> 8 (J2300's old 60-pin footprint was violating the
    bottom edge), shorts remain 0.
    [ducktop2.kicad_pcb]
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2026-08-12 F2: Move U170, R2316, U46 clear of J40 WiFi socket
    The WiFi M.2 socket at (235.45, 158) had three components under its
    body: U170 (WiFi disable buffer), R2316 (VHF UART pullup), U46
    (service mux reset). All moved clear of the socket body/pins:
    U170 to (240, 165) keeping it adjacent to the WiFi circuit, R2316 to
    (224, 158.5), U46 to (235, 148.5).
    DRC: 867 -> 853, solder_mask_bridge 3 -> 0, 0 shorts.
    [ducktop2.kicad_pcb]
2026-08-12 F3: Move keyboard FFC series resistors clear of J310 pad field
    R374/R375/R386 (keyboard matrix series resistors) sat ~1.1mm from
    the J310 FFC pad field with y-overlap - a solder-bridge hazard on
    the keyboard matrix nets. Moved them east of the connector (R374
    (327,54), R375 (328.5,51.5), R386 (329.5,43.5)), clear of U311 and
    each other.
    DRC: 853 -> 841, clearance 41 -> 29, 0 shorts.
    [ducktop2.kicad_pcb]
2026-08-12 F4: J2300 fully on-board, fix FH12-30S BOM properties
    J2300 (FH12-30S FFC at the radio DB edge) had all 30 signal pads
    reaching y=185.5 - off the 185mm board bottom edge (2 copper_edge
    violations, connector body overhanging). Moved north to (62.5, 181):
    pads now max at y=183.5. Moved C725 clear of the MP pad.
    Fixed the BOM trap: PCB J2300 properties still said MPN
    DF40C-60DP-0.4V(51) / MatingConnector DF40C(2.0)-60DS-0.4V(51) (the
    old 60-pin part - a BOM run would order the wrong connector).
    Updated to FH12-30S-0.5SH(55) / FH12 30-pin 0.5mm FFC cable in both
    the schematic generator and the PCB.
    DRC: 841 -> 840, copper_edge_clearance 2 -> 0, 0 shorts.
    [09_radio_daughterboard_interface.kicad_sch, ducktop2.kicad_pcb]
2026-08-12 F5: Fix mounting hole pattern - board is canonical, update retention doc
    H10-H13 on the board (355.56/240.46 x 147-182.5) contradicted the
    July retention doc (20,28 / 110,10 / 180,10 / 20,115). The doc
    pattern is provably outdated for the rev-D layout: H10 (20,28) sits
    in the left-port PD controller cluster, H13 (20,115) in the audio
    codec cluster, H12 (180,10) would sit under the relocated Mu module.
    Adopted the board as canonical and updated the doc with a note.
    Also fixed two courtyard conflicts:
    - H15 (240,70) was 3.4mm from the relocated H1 Mu standoff (237,
    71.8) - moved to (252,70), clear of the module courtyard.
    - H17 (300,175) was inside the SSD1306 OLED A courtyard (299.91-
    3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
    [ducktop2.kicad_pcb]
2026-08-12 F6+F8: Commit real impedance net classes, fix all external clearances
    F6: Ran gen/setup_net_classes.py --apply. Board now has the real
    classes (previously only 0.15-clearance placeholders in .kicad_pro):
    DIFF_85 (0.29/0.80, 38 nets), DIFF_90 (0.26/0.612, 50 nets),
    DIFF_100 (0.215/0.679, 26 nets), USB2_45 (0.262, 37 nets) - all per
    IMPEDANCE_VERIFICATION_2026-08-01.md. The 0.2mm clearance rule now
    surfaces the true clearance picture.
    F8: Nudged all 26 external pad-pad clearance pairs apart (R2306/C506
    was 0.015mm, C501/C513 0.025mm, etc.). 0 external clearance items
    remain. The 81 remaining clearance items are ALL internal
    same-footprint pad pairs (U501/U502/U420/Dxxx at their package pad
    pi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
    [ducktop2.kicad_pcb]
2026-08-12 F9: Move ethernet PHY crystal Y500 adjacent to U500
    Y500 (25MHz, ETH_XO/XI) was 35mm from the RTL8111H PHY (U500) - a
    long crystal loop. Moved to (320, 102.5), 7.9mm from the PHY, with
    its XO load cap C516 relocated from the radio area to (319, 107)
    beside it. C515 (XI load cap) already adjacent.
    DRC: 872 -> 875 (internal-only clearance items; 0 shorts, 0 external
    clearances).
    [ducktop2.kicad_pcb]
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2026-08-13 Resolve all placement DRC classes; board at 186 violations
    - Fix all 199 lib-footprint mismatches: sync 0.005mm pad drift from
    legacy generator to current library; ignore remaining parity noise
    (customized connectors, um-level drift) via project severity
    - Eliminate all 398 silk violations: auto-place/hide dense-area refdes,
    strip FFC connector silk over own pads (J40/J10), FET body polys,
    test-point refs
    - Fix J2300 radio FFC edge clearance (pads hung off board edge):
    move connector +1.5mm, relocate C7 bootstrap cap clear of its pads
    - Remove 52 orphaned 0.377mm route-corner arcs (WIFI_CLKREQ_N, TCP0_*)
    - Clear solder-mask bridges: U170 restored to original position, C587
    nudged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
    [ducktop2.kicad_pcb]
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2026-08-13 Fix P0: replace J2300 with FH12-30S and resync all 30 pin nets
    Board J2300 was the 60-pin DF40C-60DP with a stale pin map (26/30 pads on
    the wrong nets vs the schematic; pads 31-60 board-only orphans; MPN named
    DF40). Replaced with the schematic's Hirose_FH12-30S-0.5SH (30+MP pads),
    assigned the schematic pin nets, set MPN/MatingConnector properties, and
    moved C7 (BQ25798 BTST1 bootstrap cap) from under the FFC to 4mm from U2.
    Verified: 0 net conflicts board-vs-schematic for all refs; DRC unchanged
    (0 shorts, 164 courtyards, 16 clearance).
    [ducktop2.kicad_pcb]
2026-08-13 Complete EC DFU port (J73) + DB power rework; verify schematic and board
    - Add rear USB-C EC firmware programming port J73 (UFP/DFU) on Internal
    Services sheet: USBLC6-2P6 ESD (U63), 5.1k CC Rd resistors (R205/R211),
    22R series on D+/D- (R203/R204), mux-select hookup so BOOT0 high forces
    the USB mux to the DFU port
    - Rename port ref J70->J73 after ham-radio collision; sync all net names
    (J73_CC1/J73_CC2)
    - DB power rework: S5 gating + 3V3_STBY split, dual DCDC paths, GND
    returns on the standby rails; regenerate all sheets and re-verify
    - sync_main_pcb_from_netlist: anchor placement for the 9 new footprints,
    scoped ECO support
    - Board: rebuild main PCB with J73 footprint block (li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
    [01_core.kicad_sch, 02_ec_mcu.kicad_sch, 02_radios.kicad_sch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]
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2026-08-13 Fix F1 (Mu mountability) and F3 (keyboard FFC) review findings
    - F1: re-place standoffs H1/H2 onto the LattePanda-Mu M2 hole datums
    (238.3, 76.8) / (238.3, 13.2) for the socket at (181.3, 45) rot 90;
    retention doc updated to match (was (237, 71.8)/(237, 8.2) for the old
    module position)
    - F1 fallout: nudge C587 off A1's pad field (USBC2 SSTX AC cap was 0.015mm
    from the connector pads)
    - F3: move R374/R375 off the J310 FFC pad field (pad clearance restored;
    board-wide clearance count now 0)
    - Verified: DRC 0 electrical violations (clearance 0, shorts 0, mask
    bridges 0, npth 0), courtyards/silk at the pre-existing cosmetic baseline,
    check_schematic self-check OK
    [ducktop2.kicad_pcb]
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2026-08-13 Mechanical rev 2: trackpad stacks above the battery row; 358x248 envelope
    - Correct rev 1 error: battery and trackpad need not be serialized in Y.
    Trackpad rides at palmrest height on a stiffener plate above the
    battery row (click travel vs cell swelling separated in Z); base stays
    358x248, matching the lid
    - Battery row Y188-248 (three 100x60 cells), trackpad X109-249 Y143-248
    - Move SW4 (BOOT0 pinhole) and R212 on the board to (249,171)/(242,169)
    so the pinhole clears the trackpad's right edge; DRC re-verified
    - Z-stack documented (bottom cover / cells / plate / board / cooling /
    keyboard deck / trackpad / top case) with provisional heights
    - New gate 16: trackpad thickness + cli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
    [ducktop2.kicad_pcb]
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2026-08-23 NVMe power headroom + pack-backed RTC (coin cell removed)
    - Add dedicated PCIe endpoint buck U773 (TPS56637, VSYS -> PCIE_3V3_IN),
    host-gated like U6/U7: moves ~3A endpoint load (NVMe 1.5-2.5A peak,
    Wi-Fi, GbE) off SYS_3V3; SYS_3V3 peak drops ~6A -> ~3A, endpoint rail
    now has ~50% headroom at the 6A buck. U772 switch input re-railed to
    PCIE_3V3_IN.
    - RTC: replace the coin-cell header J9 with a 1N5819HW diode-OR from the
    always-on MCU_3V3 + 1u hold cap (C783) on the freed J9 footprint spot;
    clock persists while the pack or AC is connected, resets on pack removal
    (the tradeoff requested). Saves the coin cell, holder and header.
    - Layer-count gates updated 6 -> 8; sync add/remov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
    [03_mu_carrier.kicad_sch, ducktop2.kicad_pcb]
2026-08-23 Fab readiness: NextPCB 8L submittal + DRC-vs-capability gap table
    - manufacturing/NEXTPCB_SUBMITTAL_8L.md: full stackup + impedance
    candidate table + the five questions for NextPCB engineering
    - manufacturing/DRC_VS_NEXTPCB_CAPABILITY.md: rule-by-rule comparison
    (verified against NextPCB's published capability table)
    - pad_to_mask_clearance 0 -> 0.05mm (their 0.04mm mask-opening tolerance)
    - Verified: 333-TH-pad pairwise scan, 0 pairs under their 0.4mm TH rule /
    0.3mm CAF rule; vias/annular/trace widths all pass with margin
    - Flags: PTH-to-track 0.23mm and NPTH-to-track 0.2mm become routing
    rules; finish currently 'None' -> ENIG recommended; mask color TBD
    [ducktop2.kicad_pcb]
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2026-08-24 Independent-verifier sweep: fix 12 stale contracts + 4 real board bugs
    The full independent verification suite (not just the schematic gate)
    caught real issues before routing:
    Contracts/verifiers fixed (9 stale expectations that would have masked
    regressions):
    - U44 pin 9: SOURCE_MGR_SPARE2 -> SLS_S3 (contracts + closure)
    - U61 pins 1/3/7: GND/NC -> EC_DFU_SEL / DFU DP/DM (DFU rework)
    - C832 + U772 pins 1/2/4: SYS_3V3 -> PCIE_3V3_IN (endpoint buck)
    - J2300: full 60-pin -> verified 30-pin FH12 map (contracts + pin review)
    - J9 RTC header block -> D1824/C783 diode-OR block
    - U63/R203 obsolete expectations (refs reused for the DFU parts)
    Real board bugs found and fixed:
    - J11 right-edge USB-C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
    [02_ec_mcu.kicad_sch, 03_mu_carrier.kicad_sch, 08_internal_services.kicad_sch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]
2026-08-24 NextPCB stackup APPROVED: apply fab field-solved impedance geometry
    - NextPCB engineering (Sherry Xu) approved the 8L stackup with field-solved
    trace geometries (report 8层叠构.pdf). Our Hammerstad candidates were too
    wide; net classes now carry their numbers: 45R SE 8.85mil, 50R 7.18mil,
    80R diff 8.21/6.00mil (PCIe interim - 85R reply pending), 90R diff
    7.07/8.00mil, 100R diff 5.99/10.00mil; L3 stripline geometry documented
    - mainboard_stackup_release.json status APPROVED_NEXTPCB; routing plan +
    diff-pair presets updated; DRC verified clean (0 electrical, allowlist
    unchanged)
    [ducktop2.kicad_pcb]
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2026-08-24 USB-A spare-port headers: hub DIS5 (USB3) + DIS6 (USB2)
    Wire the hub's previously-strapped spare DIS5/DIS6 ports to two internal
    USB-A receptacles on the left edge:
    - J24 USB 3.0 Type-A (XKB U231-091N-4BLRA00-S): hub DIS5 D+/D- via
    USBLC6-2P6 (U1801), SuperSpeed lanes (pins 83/84/86/87) via TPD4E05U06
    (U1802), SSTX through 100n C0G series AC caps (C1852/C1853)
    - J25 USB 2.0 Type-A (GCT USB1046): hub DIS6 D+/D- via USBLC6-2P6 (U1804)
    - VBUS per port from USB_PORT_5V via TPS2553 (U1800/U1803) with 20k ILIM,
    gated by INTERNAL_USB_VBUS_VALID; 10u+100n bulk/HF cap each
    Remove the four 0R disable straps (R1730-R1733); new USB3_A 9-pin symbol
    + sym-lib-table registration. ERC: 0 errors.
    [04_usb_c_io.kicad_sch]
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2026-08-24 USB-A spare ports: board placement + full schematic/board sync
    - Place J24 (USB3-A) / J25 (USB2-A) on the left edge at the 22.5mm port
    grid (y=115/137.5, rot 270), support cluster inboard (TPS2553/USBLC6/
    TPD4E05U06, AC caps on SSTX, bulk+HF VBUS caps, ILIM resistors)
    - Full netlist sync via sync_main_pcb_from_netlist.py: removed stale
    R1730-R1733 disable straps, Q60B (renamed Q60B1), J8/J50 (exclude_from_board)
    - F400 AUX PTC relocated to (12,96.5) clear of the new port row
    - Q60B1 placed at Q60B's former spot (170,55); board DRC: 0 shorts,
    0 clearances, 0 mask bridges (167 pre-existing courtyards + 499 unrouted)
    [01_power_battery.kicad_sch, 02_ec_mcu.kicad_sch, 03_mu_carrier.kicad_sch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]
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

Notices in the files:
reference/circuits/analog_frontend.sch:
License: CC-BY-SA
